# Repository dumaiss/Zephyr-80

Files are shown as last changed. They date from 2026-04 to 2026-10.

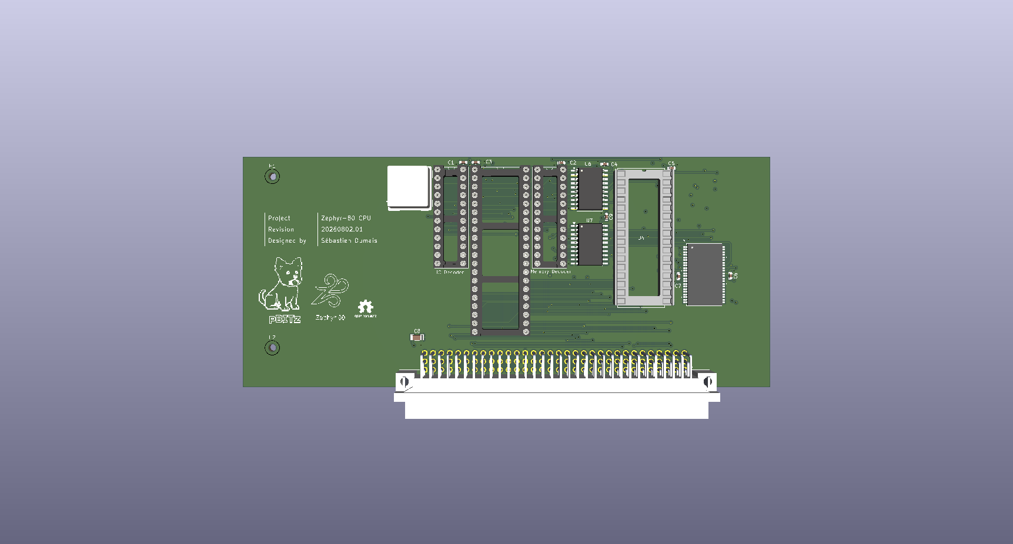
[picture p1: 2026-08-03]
Schem/Zephyr-80-CPU/Zephyr-80-CPU.png

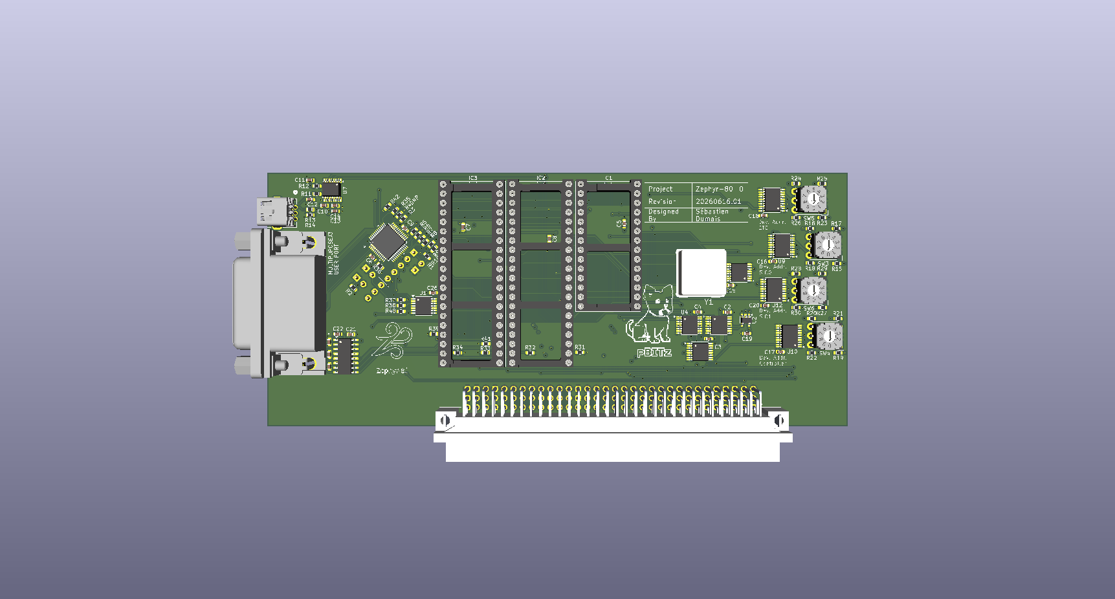
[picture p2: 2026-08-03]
Schem/Zephyr-80-IO/Zephyr-80-IO.png

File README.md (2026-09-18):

# Zephyr-80

**Retro Soul, Modern Flow**

Zephyr-80 is a modular homebrew Z80 computer built from real retro-style
components and modern support hardware. It runs CP/M 2.2, provides 512 KiB each
of banked SRAM and ROM, and uses expansion cards for video, sound, and peripheral
control.

It is the Z80 member of the broader pBITz / coffee-machine family of homebrew
computers.

The project combines a conventional Z80 bus with a protected common-memory
region, a driver-oriented BIOS, programmable serial and timer hardware, and an
MCU-based I/O Controller for storage and human-interface devices. The same
firmware is also used by the project's MAME implementation.

Zephyr-80 is an active hobby project and a hardware/software development
platform, not a finished consumer product. The machine runs CP/M on real
hardware with video, sound, storage and USB input working; what remains under
development is mostly tooling and the emulation targets.

## Current status

| Subsystem | Status |
| --- | --- |
| Z80 CPU board and memory banking | Working on physical hardware |
| ROM-to-RAM boot transition | Working |
| CP/M 2.2 and Zephyr CBIOS | Working |
| SIO serial console at 115200 baud | Working |
| Virtual Drip V9958 console | Working development backend |
| Virtual Drip 8 MiB CP/M disk | Working development backend |
| MAME machine and V9958 video | Boots the Zephyr firmware; development on hold |
| ColecoVision compatibility mode | Working on physical hardware |
| IOCALL fixed-frame transport | Working on physical hardware |
| Percolator Lunch Crema V9958 card | Working on physical hardware |
| SD-card storage through the I/O Controller | Working on physical hardware |
| USB HID keyboard and gamepad through the I/O Controller | Working on physical hardware |
| CP/M images as files on a FAT card | Working on physical hardware |
| Percolator Afternoon Blend four-chip SN76489 card | Working on physical hardware |

## Hardware architecture

### Processor and memory

- Z80-family CPU, with a current hardware target of 10 MHz
- 512 KiB SRAM arranged as eight 64 KiB physical banks
- 512 KiB ROM arranged as eight 64 KiB pages
- ATF22V10-based memory and I/O decoding
- Memory-control latch at I/O port `00h`
- 56 KiB banked program region plus an 8 KiB common region, with the operating
  system in its own SRAM bank

At reset, ROM is visible and writes are directed to SRAM underneath it. The
firmware copies every ROM page into the matching SRAM bank, disables ROM, and
continues from RAM. From then on ROM is storage only: the operating system —
ZSDOS, the BIOS and its drivers — runs from SRAM bank 7, which is mapped in only
while it executes. A program sees `0000h-DFFFh` of its own bank and the common
region at `E000h-FFFFh`, which stays SRAM bank 0.

See [Memory Management.md](Memory%20Management.md) for the decoder equations,
memory modes, banking-latch format, and I/O map.

### Serial and timer hardware

The system uses two Z80 SIO devices and a Z80 CTC. The BIOS currently owns:

- SIO0/B for the 115200-baud console and Virtual Drip transport
- SIO1/B for the synchronous I/O Controller command channel
- the Z80 IM2 vector page; programs get CTC timer interrupts by registering a
  callback with the BIOS

The I/O Controller supplies the external clock and synchronization signals for
its synchronous SIO link. The initial IOCALL implementation is deliberately
simple and uses a polled, fixed-size transaction.

### Expansion bus

The latest Zephyr-80 respin uses DIN connectors for the pBITz expansion bus.
The shared backplane, bus, and mezzanine-card designs are maintained separately
in the [pBITzPlatform repository](https://github.com/dumaiss/pBITzPlatform).

## Memory model

Physical memory is eight 64 KiB SRAM banks and a ROM divided into 64 KiB pages.
The banking latch carries three SRAM-bank bits, three ROM-page bits and two
memory-mode bits, and the two mode bits select one of four mappings:

| Mode | Mapping |
| --- | --- |
| `00` ROM access / RAM destination | Reads: selected ROM page at `0000h-FFFFh`. Writes: selected SRAM bank at `0000h-FFFFh` |
| `01` Flat SRAM | Selected SRAM bank at `0000h-FFFFh`, reads and writes |
| `10` Application | Selected SRAM bank at `0000h-DFFFh`; common SRAM bank 0 at `E000h-FFFFh` |
| `11` Operating system | Selected SRAM bank at `0000h-1FFFh`; SRAM bank 7 at `2000h-DFFFh`; common SRAM bank 0 at `E000h-FFFFh` |

Writes always reach SRAM. In mode 00 that makes a single `LDIR` copy ROM to SRAM,
which is how cold boot seeds a bank and how drive A: is read. Flat mode 01 gives a
true 64 KiB bank, including the `E000h-FFFFh` that modes 10 and 11 overlay with
bank 0; that memory is present in every bank, hidden rather than absent.

At cold boot only the ROM pages that are boot images seed SRAM: page 0 into bank 0
and page 7 into bank 7. The pages backing CP/M drive A: stay in ROM as persistent
immutable storage and are never copied.

In the current CP/M build, a program's transient area is `0100h-EC05h`, 59 KiB.
The common region holds a 1 KiB program reservation for interrupt callbacks, the
CCP, the BDOS entry, the BIOS jump tables, the interrupt path and the system
stacks. ZSDOS, the BIOS drivers and their private state live in bank 7. Exact
addresses are declared in
[`cbios_defs.inc`](Code/HOST/CPM2.2/src/cbios_defs.inc).

## CP/M firmware

The current system boots CP/M 2.2, with ZSDOS as the BDOS and ZCPR2 as the
command processor, on a Zephyr-specific CBIOS. The operating system runs from
SRAM bank 7 behind a BDOS entry in common memory, which copies a program's
buffers across when the operating system cannot see them.

Programs reach the Zephyr services through `CALL 5`, as BDOS functions:

- 200 and 201 to register and unregister a CTC interrupt callback
- 203 for system information, such as the I/O Controller transport level
- 210 and 211, `MOVE` and `XMOVE`, for bank-aware memory transfers
- 212, `SELMEM`, for selecting the execution bank
- 213, `SETBNK`, for selecting the disk DMA bank
- 214, `IOCALL`, for I/O Controller command/reply transactions
- 216 and 217, `IOCBULK` and `IOCBULKW`, for I/O Controller bulk transfers
- 215, `VIDEO_SEND`, for submitting video command streams

[`zbdos.inc`](Code/HOST/Utilities/src/zbdos.inc) wraps them for assembly
programs.

The current IOCALL transport sends one caller-owned 32-byte frame and receives
one 32-byte reply frame over SIO1/B. The BIOS owns the transport but does not
interpret individual I/O Controller commands.

For firmware architecture, build artifacts, and the current driver layout, see
[Code/HOST/CPM2.2/README.md](Code/HOST/CPM2.2/README.md).

## Console and storage

### Virtual Drip development backend

Virtual Drip is the current development proxy for console, video, keyboard
input, and CP/M storage. It lets the physical Z80 machine exercise the BIOS and
V9958-oriented software before all replacement hardware paths are complete.

The active console is an 80-column V9958 GRAPHIC 6 terminal. Terminal state is
kept in V9958 VRAM, with a CP850 font atlas, color-aware logical cells, and a
sprite-based cursor. See the
[Virtual Drip V9958 console notes](Code/HOST/CPM2.2/docs/vdrip9958-console.md).

CP/M Drive A is currently backed by an 8 MiB flat image on the proxy side. The
BIOS exposes normal 128-byte CP/M disk records and maps them to proxy storage
transactions. See the
[Virtual Drip disk format](Code/HOST/CPM2.2/docs/zephyr80_vdrip_disk.md).

Virtual Drip is a bring-up tool rather than the intended final storage and HID
architecture. Those functions are moving to the onboard I/O Controller.

### I/O Controller

The I/O Controller offloads modern peripheral protocols from the Z80. Its
eventual responsibilities include:

- SD-card storage
- USB keyboard and controller input
- system reset and power-management coordination
- asynchronous input/event delivery to the host

The current firmware implements the synchronous SIO command transport and
fixed 32-byte IOCALL frames. Basic PING and RESET commands exist for link
bring-up. Storage, HID, and unsolicited event delivery remain under development.

## Video

Video is provided by expansion hardware rather than being fixed on the CPU
board. The physical multimedia cards belong to the Percolator Series and are
maintained in the
[PercolatorLabs repository](https://github.com/dumaiss/PercolatorLabs):

- **Morning Joe**: TMS9918-family video for native 9918-era hardware experiments
- **Lunch Crema**: V9958 video with 128 KiB VRAM and RGB output; expected to
  provide the ColecoVision-compatible VDP path

Zephyr-specific development paths also include:

- Virtual Drip, a serial development proxy that models VDP operations on a
  modern host
- a V9958 implementation in the Zephyr MAME machine

The current CP/M graphical console targets V9958 GRAPHIC 6 semantics. Original
9918-family tests remain in the repository, but that hardware is no longer the
only or primary description of Zephyr-80 video.

## ColecoVision compatibility

Zephyr-80 is intended to run ColecoVision software as a dedicated
**machine-takeover mode**, not as an application that continues to call CP/M.
Compatibility is expected to use the **Lunch Crema V9958**; the Morning Joe
TMS9918 card is not required. The V9958's TMS9918-compatible display modes are
expected to provide the video behavior needed by ColecoVision software.

Zephyr-80 is not wired as a literal ColecoVision clone, so a Zephyr-specific
bootstrap must construct the environment that the game expects before handing
over the CPU. That initialization is expected to:

1. quiesce CP/M, its BIOS drivers, and their interrupt sources
2. load the ColecoVision BIOS and game image into the appropriate RAM locations
   and physical bank
3. establish the compatibility memory map while the bootstrap remains in a
   safe execution area during the final bank switch
4. initialize the V9958 in its TMS9918-compatible mode, clear or prepare VRAM,
   and select the Coleco-compatible VDP interrupt route
5. initialize an SN76489-compatible PSG path on the **Afternoon Blend** card
6. configure the controller-input path to expose the behavior expected by the
   game
7. establish the required vectors, stack, and entry state, then transfer
   control to the ColecoVision program

After the final transfer, the game owns the CPU, VDP, sound, and controller
interfaces. CP/M services are no longer assumed to be available.

### Launch paths

Two launch paths are planned. They share the same final hardware-initialization
and handoff logic:

- **CP/M launcher:** select a game from CP/M, load its BIOS and cartridge image
  into RAM, prepare the compatibility mapping and peripherals, and let the game
  take over the machine.
- **Bootable Zephyr cartridge:** start cartridge-resident loader firmware
  immediately after reset, copy or unpack the bundled game into RAM, configure
  memory banking and video, and transfer control without booting CP/M.

This is native execution on the Zephyr Z80 and compatible peripheral paths, not
CPU emulation. It is still a compatibility target rather than a blanket claim
that every title works. Games that depend closely on the original console's CPU
timing may require calibrated delays or title-specific adaptation because
Zephyr-80 runs its Z80 at 10 MHz.

## Sound

The Zephyr-80 sound card is the Percolator Series **Afternoon Blend**, which
uses four SN76489 programmable sound generators with analog mixing and
amplification. The card design is maintained in the
[PercolatorLabs repository](https://github.com/dumaiss/PercolatorLabs), while
Zephyr-side drivers and applications belong here. Software support and
higher-level music tooling are continuing areas of development.

## MAME emulation

The repository includes Zephyr-80 MAME development under
`Code/MODERN/Emulator/`. The goal is to run the same firmware used by the
physical machine rather than maintain a separate emulator-only BIOS.

Current emulator work includes the banked ROM/RAM architecture, Z80 peripheral
topology, and V9958 video. I/O Controller, storage, and host-HID integration are
being added incrementally.

The MAME source tree and CP/M source are included as Git submodules. Clone with
submodules enabled when working on those areas:

~~~sh
git clone --recurse-submodules https://github.com/dumaiss/Zephyr-80.git
~~~

## Repository layout

| Path | Contents |
| --- | --- |
| `Schem/` | KiCad schematics and board-specific validation notes |
| `Code/HDL/` | PLD and programmable-logic source |
| `Code/HOST/CPM2.2/` | CP/M 2.2, Zephyr CBIOS, drivers, image tools, and generated memory documentation |
| `Code/HOST/Monitor/` | Interactive Zephyr monitor application |
| `Code/HOST/HelloWorld/` | Hardware bring-up and subsystem test programs |
| `Code/MCU/` | Power-management and I/O Controller firmware |
| `Code/MODERN/Emulator/` | MAME machine development and emulator ROM tests |

## Related repositories

| Repository | Scope |
| --- | --- |
| [pBITzPlatform](https://github.com/dumaiss/pBITzPlatform) | DIN-connected pBITz backplane, bus, and mezzanine-card hardware |
| [PercolatorLabs](https://github.com/dumaiss/PercolatorLabs) | Percolator Series video and sound cards, including Morning Joe, Lunch Crema, and Afternoon Blend |

## Building the CP/M firmware

Initialize the submodules, then build from the CP/M directory:

~~~sh
git submodule update --init --recursive
cd Code/HOST/CPM2.2
make
~~~

The build requires Python 3, GNU Make, and the SDCC Z80 tools `sdasz80`,
`sdldz80`, and `makebin`.

Primary outputs include:

| Artifact | Purpose |
| --- | --- |
| `build/zephyr80.bin` | 512 KiB burnable ROM image |
| `build/zephyr80-zcpr2-zsdos.bin` | the same image, named for its CCP and BDOS |
| `build/firmware.bin` | ROM page 0: the reset vector and common memory |
| `build/bank7.bin` | the operating-system image, loaded into SRAM bank 7 |

The ROM requires memory decoder revision 11, built from
[`Code/HDL/WinCUPL`](Code/HDL/WinCUPL/README.md). The build also regenerates
`docs/memory-map.md` and `docs/symbol-map.md`, and fails if the layout breaks a
validated rule.

Additional build and backend-selection details are documented in the
[CP/M firmware README](Code/HOST/CPM2.2/README.md).

## Development notes

- Treat the PLD equations and `Code/HOST/CPM2.2/src/cbios_defs.inc` as
  authoritative when older narrative documents disagree.
- The firmware ABI is `CALL 5`, including the Zephyr functions, and the CP/M
  BIOS boot and console entries. Nothing else is published at a fixed address.
- Several older architecture notes remain in the repository for design history
  and may describe superseded clock, I/O, or memory arrangements.
- Hardware revisions and experimental subsystems may require matching firmware
  branches or configuration. Check the board-specific notes before programming
  devices or applying power.

## License

Zephyr-80 is licensed under the
[Solderpad Hardware License v2.1](Licence.md), with the option described there
to treat the work as Apache License 2.0.

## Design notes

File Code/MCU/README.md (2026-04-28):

# MCU Firmware

This directory contains firmware projects for microcontrollers used by the
Zephyr-80 hardware.

Each MCU target should live in its own subdirectory so device-specific source,
build settings, fuse settings, programmer configuration, and documentation stay
isolated.

## Projects

- `PMU/` - Power management unit firmware project.
- `IOController/` - PIC18F57Q84 IO Controller firmware project.

## Suggested Layout

```text
MCU/
  <mcu-target>/
    README.md
    Makefile
    include/
    src/
    docs/
    build/
```

Keep shared protocol notes or board-level interface documentation in this
directory only when they apply to more than one MCU target.

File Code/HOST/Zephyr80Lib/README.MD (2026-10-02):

# Zephyr80Lib

`Zephyr80Lib` is the reusable FTL Modula-2 library for Zephyr-80 programs.
It provides the public `Sound`, `Timer`, and `Player` modules. The current
implementation targets the four
SN76489-compatible PSGs on Afternoon Blend and the Zephyr BIOS-managed CTC0
interrupt service.

All CP/M-visible source and output filenames are 8.3-compatible.

## Public modules

- `Sound` controls 16 logical channels across the four PSGs.
- `Timer` exposes logical ticks from 1 through 180 Hz. CTC0 and the assembly
  callback bridge remain private implementation details.
- `Player` loads a ZTR file and advances complete singleton music playback one
  application-supplied tick at a time.

`CTCLow`, `ZTR`, and `PlyCore` are archive implementation modules, not public
application APIs. See `DOC/API.MD` for the complete public contract and an
embedding example.

## PC build

The library is built with FTL Modula-2 under RunCPM. The repository carries the
RunCPM executable and the ZCPR3 CCP image; the FTL distribution is read from
`../Software/disk1/5`. On the x86-64 Linux development host, only Python 3 and
`make` are required:

```text
make clean
make
```

Objects are written to `BUILD/FTL`, and `BUILD.LOG` holds the full compiler,
assembler and linker output. Tool paths can be overridden through Make
variables; run `make help`.

## Why not Turbo Modula-2

This library was originally built with Turbo Modula-2, and that toolchain has
been removed. TM2's runtime is too large for the machine: once it is linked in,
a hosted application has no room left to run. Since the point of this library is
hosted development on the Zephyr-80 itself, that is disqualifying.

Consequences worth knowing:

- FTL's compilers are line-oriented. LF-only source reads as one enormous line
  and `MD` reports `ERROR 81 end of file reached before program complete`.
  `SRC` and `TEST` are stored CRLF and pinned by `.gitattributes`.
- FTL has no port I/O in the language and no `SYSTEM.OUT`. `SRC/PORTIO.*`
  supplies `In` and `Out`; see `TOOLS/README.MD` for why it is built from
  source rather than imported.
- FTL's `Files` is block-oriented, with no `Open`, `ReadBytes`, `NoTrailer` or
  `EOF`. Use `Lookup`, `SeqReadBlock`, the `eof` field of `FILE`, and `Close`.
  Block transfers move whole 128-byte units even when fewer bytes are asked
  for, so read buffers must be sized in whole blocks.

## Native FTL CTCLow bridge

`SRC/CTCLOW.Z80` targets the FTL `ASM.COM` supplied in `../Software/disk1/5`.
On CP/M, build it with these commands after copying `CTCLOW.DEF` and
`CTCLOW.Z80` to the FTL work disk:

```text
MD CTCLOW.DEF
ASM CTCLOW.Z80 CTCLOW.REL
ML yourprog
```

Keep `OPSASM.DAT` on the logged drive. Both ASM filenames require extensions.
Compile the definition first; ASM replaces the definition's stub `.REL`.
Its bare `LABEL` directives export procedures in `CTCLOW.DEF` order.
The syntax follows the supplied FTL assembly examples and the
[FTL manual, chapter 7](https://www.cpcwiki.eu/imgs/9/92/Hisoft_FTL_Modula-2_Z80_User_Guide_%28Hisoft%29_Manual.pdf).

`FTLTEST.COM` is a hosted regression, not a hardware timer test; running it
needs a C++ compiler and `libqkz80` via `tests/ftl_bridge.cpp`.

Callback placement remains `E3C0h-E3F6h`, with state at `E3F8h-E3FEh`.
FTL consumers must reserve that region against code, data, heap and stack;
the bridge does not change the FTL runtime's memory allocator. It still
requires the Zephyr BIOS registration API.

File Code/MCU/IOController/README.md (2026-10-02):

# IO Controller Firmware

Firmware project for the Zephyr-80 IO Controller MCU.

The default target is `PIC18F57Q84`.

## Build Firmware

```sh
make
```

The build emits firmware output into `build/`. Override paths when needed:

```sh
make DEVICE=PIC18F47Q84
make XC8=/path/to/xc8-cc DFP=/path/to/device/support
```

Bulk data CRC calculation and verification are bypassed by default with
`IOC_BULK_CRC_BYPASS=1` in `include/config.h`, matching the current Z80 bypass.
This applies to both directions of the SIO1/A bulk lane: IOC sends a two-byte
zero CRC trailer and ignores the received CRC. Packet framing and metadata
checks remain active; command-lane CRC and SD-card SPI CRC are unchanged.
The Z80 must keep its bulk receive CRC bypass enabled with this setting.

To restore IOC bulk CRC generation and verification:

```sh
make DEFS=-DIOC_BULK_CRC_BYPASS=0
```

Use `make` (or `make DEFS=-DIOC_BULK_CRC_BYPASS=1`) to return to bypass mode.
Restoring end-to-end verification also requires disabling the Z80's separate
`IOC_BULK_CRC_BYPASS` setting.

## Current Behavior

At boot the firmware asserts the host reset pair for 100 ms:

- `RF2` / `RESET` is driven low, then released high.
- `RF3` / `RESET_HIGH` is driven high, then released low.

After boot, the main loop polls `/SIO1B_INT` on `RF0`. A falling edge starts
one External Sync command transaction:

```text
select:  PIC RA4 /SIOB_CS puts SIO1/B on the SIO bus
request: Z80 SIO1/B TXDB -> PIC RB2 SIO_MISO, clocked by PIC RB3 SIO_SCK
reply:   PIC RB1 SIO_MOSI -> Z80 SIO1/B RXDB, clocked by PIC RB3 SIO_SCK
sync:    PIC RA7 drives SIO1/B /SYNCB
```

The bulk of the transfer runs on SPI2. A disposable byte is clocked by hand only
while establishing that lane's persistent `/SYNC` boundary; the complete
`A5 5A` packet marker then follows through SPI. See
[docs/external_sync_protocol.md](docs/external_sync_protocol.md) for what stays
bit-banged and why.

Throughput is set by `EXTSYNC_TARGET_BYTE_US` in `include/external_sync.h`,
currently 16 us (500 kbit/s). That is paced against the Z80 BIOS receive loop,
not against the SPI clock — see the header for the T-state budget.

See [docs/pinout.md](docs/pinout.md) for the full pin map.

Both lanes use `A5 5A LEN TYPE SEQ STATUS DATA CRC` packets. The 32-byte
`IocFrame` is only the command-side compatibility mailbox. Active commands are:

- `CMD_PING`: return `RSP_PING` with the sequence, status, length, and payload
  echoed.
- `CMD_RESET`: assert `RESET` / `RESET_HIGH`, then reset the PIC.

The transport maps command mailboxes to variable-length CRC-protected packets.

## Two-Lane Transport

The two SIO1 channels are one transport with two lanes: SIO1/B carries commands
and SIO1/A carries large DATA. Both use the same packet framing and persistent
External Sync discipline.
Commands that move more than a mailbox-worth of data use an explicit
READY -> BULK -> DONE lifecycle:

```text
CMD_SD_READ_BULK(LBA) -> READY(id, dir, 512) -> one 512-DATA packet on SIO1/A
                      -> CMD_XFER_STATUS -> DONE(id, status)
```

The card is read into MCU SRAM before READY is sent, so SD latency sits outside
the bulk transaction. See
[docs/external_sync_protocol.md](docs/external_sync_protocol.md) for the wire
formats, the state machine and the bulk-lane timing.

## SD Card

`CMD_SD_READ` (03h) reads block 0 over SPI1 on the port C bus, select
`/IO_SD_CS` on RA2, and returns its first 16 bytes in the reply payload. The
card initialises lazily on the first read. Failures come back as status codes
10h-14h rather than a transport error, so the host can tell which stage gave up.
Block reads verify the card's CRC-16 and retry on failure. Several timing and
retry settings are deliberately conservative while the SD path is still
marginal; see the **BELT AND SUSPENDERS** block at the top of
[include/sd_card.h](include/sd_card.h) for what each one costs and the order in
which to relax them.

`ioc_sd_read.asm` in the HelloWorld project exercises it; `ioc_sdblk.asm`
exercises the full-sector bulk path and `ioc_bulk.asm` tests the bulk lane on
its own with a ramp.

## USB HID Bring-Up

TinyUSB 0.20.0 supplies the MAX3421E host, hub and HID class code.  The IOC's
adapter is isolated in `src/ioc_hid.c`; it shares SPI1 only through the central
one-hot selector, so selecting the MAX3421E always releases the SD card and
controller latch first.

The MAX3421E and FE1.1 hub now support up to two HID interfaces in the
foreground TinyUSB task.  One boot keyboard may be used alongside a Logitech
F310 in DirectInput mode (USB `046d:c216`), or two F310s may feed the two
Coleco controller bytes.  F310 interrupt-IN requests are paced at 10 ms in the
application because TinyUSB's MAX3421E scheduler does not yet enforce endpoint
`bInterval`.  Passive `CMD_HID_STATUS` page 6 reads TinyUSB's live non-hub
device table and exposes USB/F310 enumeration, report-arm, report-count and
decoded-latch state to `PADSTAT.COM` in a normal build.  Boot-keyboard press transitions are translated
inside the HID module to ASCII/control bytes and VT100 key sequences, then held
in a 128-byte queue.  The nonblocking `CMD_HID_INPUT` dequeues up to 24 bytes;
`HIDKEY.COM` exercises that path directly without changing BIOS `CONST` or
`CONIN`.  See the bring-up log for the command layout and current limitations.

**Nothing can be read from the MAX3421E until `PINCTL.FDUPSPI` is set.**  The
part powers up in half-duplex SPI, where it tri-states MISO and drives read data
back out of its own MOSI pin — which this board cannot receive, because MOSI
reaches it through a one-way CD74HC4050.  The first access must therefore be a
blind PINCTL *write*; writes work in both modes.  `RES` is strapped high, so
that setting survives every PIC reset and only a 3V3 power cycle undoes it.
See [docs/max3421-bring-up-debug.md](docs/max3421-bring-up-debug.md) for the
full root-cause trail, what has been ruled out, and the bisection guide.

## Controller Latch Bring-Up

The cascaded 74AHC595 pair on the port C bus (SPI1) is driven by
`controller_latch.c`. Both controller bytes start at the standard Coleco idle
value `7Fh`.  Each changed F310 report is decoded to the active-low Coleco data
bus and committed at SPI1's 32 MHz maximum.  Mount order assigns controller 1
and then controller 2; unplugging a pad restores that byte to `7Fh`.

**D7 is low.**  It was high until Montezuma's Revenge exposed it.  The BIOS
complements every controller read, so a game sees `~latch`; Monte merges the
two mode bytes and tests the result with `AND 0C0h` / `CP 0C0h` at `90FFh`.
With D7 high that compare can never match and the jump button is dead.  The
BIOS itself only reads D3:D0 and D6, and no other title in the test set looks
at D7 of a controller byte, so `CONTROLLER_LATCH_IDLE` is the single point to
revert should one turn up.

The F310 mapping is d-pad (or left stick while the Mode LED is on) to Coleco
directions, A/B to fire, X/Y to the existing keypad 1/2 selections, and
Back/Start to the Coleco `*`/`#` codes used by game-over/restart paths. The board
does not capture the Coleco keypad/joystick mode-select writes, so these keypad
substitutes temporarily override the direction nibble while held. The raw latch
codes are `0Dh` for key 1, `07h` for key 2, `09h` for `*`, and `06h` for `#`;
with the idle upper nibble these appear at the controller port as `7Dh`, `77h`,
`79h`, and `76h` respectively.

### USB keyboard keypad

The four gamepad substitutes cover only `1`, `2`, `*` and `#`. Titles that need
the rest of the keypad -- the music cartridge, and games whose title screen
waits on a digit the pad cannot produce -- are served from an attached USB
keyboard instead, which is otherwise idle once ColecoGo has taken the machine
over.

The number row and the numeric keypad both give `0`-`9`. `Shift+8` and
`Shift+3` give `*` and `#`, which is just typing the character; keypad `*` is an
alias for `*`. The mapping drives controller port 0 and does **not** consume the
keystroke, so digits still reach the CP/M console while CP/M is running.

A keypad code held from the keyboard overrides the direction nibble of every
gamepad report until it is released, matching the existing substitute
behaviour: a real controller cannot report a keypad key and a direction at the
same time. Releasing parks the nibble idle, and an attached pad restores real
directions on its next report.

The nibbles come from the BIOS decode table at `10F5h`, which is indexed by the
complement of the port read, so the latch value is `~index`:

| Key | Latch | Key | Latch | Key | Latch |
| --- | --- | --- | --- | --- | --- |
| 0 | `0Ah` | 4 | `02h` | 8 | `01h` |
| 1 | `0Dh` | 5 | `03h` | 9 | `0Bh` |
| 2 | `07h` | 6 | `0Eh` | `*` | `09h` |
| 3 | `0Ch` | 7 | `05h` | `#` | `06h` |

`make test` runs `tools/test_coleco_keypad.py`, which extracts the mapping
function from `src/ioc_hid.c`, compiles it for the host, and checks all twelve
keys plus the negative cases against that BIOS table rather than against a
transcribed copy of it.  It also replays the whole latch byte through the
BIOS complement, so a regression in D7 or the fire line fails the test rather
than reaching hardware.

`CONTROLLER_LATCH_COUNTER_TEST` still defaults to **0**, which compiles
`controller_latch_tick()` down to an empty call.

Build with `CONTROLLER_LATCH_COUNTER_TEST=1` to get the bring-up behaviour --
an incrementing pair `(n, n+1)` written to the two latches every 500 ms. This
section previously described that pattern as if it always ran, which it has not
since the flag was added. See [docs/pinout.md](docs/pinout.md) for the timer and
SPI1 settings.

See [docs/external_sync_protocol.md](docs/external_sync_protocol.md) for the
wire-level walkthrough, timing notes, and Z80 SIO references.

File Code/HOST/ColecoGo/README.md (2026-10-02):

# ColecoGo

`ColecoGo` is a CP/M user-space launcher for running ColecoVision software directly on Zephyr-80 hardware.

The intended command-line interface is:

```text
A>COLECOGO GAME.ROM
```

The launcher is a one-way machine takeover. It uses CP/M only to locate and load the ColecoVision BIOS and cartridge image, prepares a dedicated RAM bank and the Zephyr compatibility hardware, then transfers control to the ColecoVision BIOS at `0000h`. Returning to CP/M is not supported or expected.

## Scope

The initial implementation targets conventional ColecoVision cartridge images up to 32 KiB.

The ColecoVision BIOS is not embedded in the executable. `COLECOGO.COM` is expected to load it from a separate file, initially named:

```text
COLECO.ROM
```

The initial loader should validate that the BIOS image is exactly 8 KiB and that the cartridge image is no larger than 32 KiB.

Larger bank-switched cartridge formats are outside the scope of the first version.

## Relevant Zephyr-80 memory model

In normal RAM-only operation, Zephyr-80 exposes:

```text
0000h-DFFFh   selected SRAM bank
E000h-FFFFh   SRAM bank 0, fixed/common
```

This means a ColecoVision cartridge mapped at `8000h-FFFFh` crosses the Zephyr physical bank boundary at `E000h`.

That boundary is invisible to the Z80, so the loader can construct the final Coleco address space from two physical RAM regions:

```text
Logical address   Physical Zephyr RAM
---------------   -------------------
0000h-1FFFh       selected Coleco bank
2000h-5FFFh       selected Coleco bank, temporary staging area
6000h-7FFFh       selected Coleco bank, Coleco RAM
8000h-DFFFh       selected Coleco bank, cartridge lower 24 KiB
E000h-FFFFh       bank 0, cartridge upper 8 KiB
```

Bank 7 belongs to the running operating system and is never a legal application
bank. ColecoGo sacrifices bank 6 as its fixed one-way takeover bank.

## Loading scheme

### 1. Run normally under CP/M

`COLECOGO.COM` starts as an ordinary CP/M transient program at `0100h`.

While CP/M is still fully operational, it:

1. parses the cartridge filename from the command line
2. opens `COLECO.ROM`
3. validates the BIOS size
4. opens the requested cartridge image
5. validates the cartridge size
6. loads both files through normal CP/M BDOS services
7. uses Zephyr BDOS functions 210 and 211 to construct the target bank

All errors should be reported before the takeover begins.

### 2. Construct the target bank

The target bank is prepared as follows:

```text
0000h-1FFFh   ColecoVision BIOS
2000h-5FFFh   temporary staging for GAME.ROM offsets 4000h-7FFFh
6000h-7FFFh   cleared for Coleco RAM
8000h-BFFFh   GAME.ROM offsets 0000h-3FFFh
```

For cartridge images smaller than 32 KiB, the cartridge destination should be initialized to a deterministic fill value before overlaying the file contents. `FFh` is the proposed initial fill value.

The upper 16 KiB of a 32 KiB cartridge crosses the current RAM-only mapping
boundary: `C000h-DFFFh` is in the selected bank while `E000h-FFFFh` is physical
bank 0. It is staged at `2000h-5FFFh`, then copied across that boundary after
the final bank switch.

### 3. Install the final handoff code

The final takeover requires code that survives the bank switch.

The current CP/M memory model reserves `E000h-E3FFh` as application-owned common memory. A small Stage A trampoline can be copied there before takeover.

Stage A is responsible for:

1. disabling interrupts
2. shutting down CP/M-owned interrupt sources that must not fire during takeover
3. switching to the selected Coleco RAM bank
4. jumping to Stage B in the newly selected bank

Stage B must live below `E000h` in the target bank. Its exact location is intentionally left open until implementation, but it must not depend on CP/M, BDOS, BIOS stack state, or any code/data that will be overwritten.

### 4. Complete the cartridge mapping

Once Stage B is executing in the target bank, the loader can populate both the
bank-6 and common-bank portions of the upper cartridge and overwrite the common
CP/M region.

Conceptually:

```asm
ld      hl,2000h
ld      de,0C000h
ld      bc,4000h
ldir
```

This copies the staged upper 16 KiB of the cartridge into the live logical range `C000h-FFFFh`.

At this point the common CP/M facade, BIOS and stacks are intentionally
destroyed. The protected bank-7 OS image is not overwritten, but there is no
supported return path to it.

The final Z80-visible image is then:

```text
0000h-1FFFh   ColecoVision BIOS
2000h-5FFFh   don't-care / available
6000h-7FFFh   Coleco RAM
8000h-FFFFh   cartridge image
```

## Hardware compatibility handoff

Zephyr-80 was designed so Coleco software can access compatible hardware directly after CP/M gets out of the way.

The final handoff therefore does not emulate Coleco I/O and does not proxy runtime accesses through CP/M.

### V9958 video

Before jumping to the ColecoVision BIOS, ColecoGo only needs to establish the Zephyr/V9958-specific state that original Coleco software cannot establish itself:

1. select the Coleco-compatible VDP interrupt route, with the V9958 interrupt presented to the Z80 as NMI
2. program the V9958 palette to reproduce the fixed Coleco/TMS9918 palette
3. reset V9958-only registers inherited from the CP/M graphics console to a
   TMS-compatible baseline

The ColecoVision BIOS is then allowed to initialize the ordinary TMS9918-compatible VDP registers itself.

There is one electrical address-decoding difference that the loader must also
bridge. A ColecoVision aliases the TMS9928A throughout `A0h-BFh` and uses only
address bit A0 to choose data or command/status. LunchCrema passes A1:A0 to the
V9958, where those two bits select four distinct ports. Stock BIOS accesses to
`BEh/BFh` therefore select the V9958 palette/indirect ports instead of its
data/command ports.

The current loader recognizes the standard Coleco BIOS layout (CRC32
`3AA93EF3`) by checking every affected operand and patches its in-memory copy
from `BEh/BFh` to LunchCrema's `A0h/A1h`. The disk file is not modified. A BIOS
with a different layout is rejected before bank 6 is changed. Cartridge code
that performs its own direct VDP I/O is adapted by the cartridge scan
described below.

### Controller input

No runtime HID translation layer is required in ColecoGo.

The Zephyr I/O Controller maintains controller state in hardware latches at the addresses expected by ColecoVision software. Once takeover is complete, Coleco software reads those latches directly with its normal I/O instructions.

### Sound

ColecoVision writes its single SN76489 at `FFh`. Although Zephyr routes writes
in the `E0h-FFh` range to Afternoon Blend, that card uses A2:A0 to select an
individual sound device: `FFh` selects an unused slot and `E0h` selects PSG0.
ColecoGo therefore patches the standard BIOS's guarded `FFh` output operands
to `E0h` in memory. The BIOS's normal sound initialization and runtime engine
then drive PSG0 directly; ColecoGo is not involved after takeover. Cartridge
code that writes directly to `FFh` is adapted by the cartridge scan described
below.

### Cartridge I/O adaptation

Titles that reach the hardware through the BIOS are handled entirely by the
BIOS patch above. Titles that drive the VDP or the PSG themselves are not, so
the loader adapts the cartridge image as well, in memory, before takeover.

The BIOS can be patched from a fixed table because it is a known image. A
cartridge is not, so its operands have to be found. The loader cannot simply
scan for `D3h`/`DBh` byte pairs: Donkey Kong contains nine such pairs in its
data tables and no direct I/O at all, so a blind scan would corrupt a title
that currently works.

Instead the loader runs a recursive-descent trace from the cartridge header's
documented entry points -- the start address at offset `0Ah` and the eight
`RST`/NMI vector slots at `0Ch`-`23h` -- following direct jumps, calls and
relative branches. Only a byte the trace proves is the operand of a reachable
I/O instruction is rewritten:

| Instruction | Operand | Rewritten to | Why |
| --- | --- | --- | --- |
| `OUT (n),A` / `IN A,(n)` | `A0h`-`BFh` | `A0h` or `A1h`, keeping A0 | LunchCrema decodes A1:A0 |
| `OUT (n),A` | `E0h`-`FFh` | `E0h` | Afternoon Blend decodes A2:A0; `E0h` is PSG0 |
| `IN A,(n)` | `E0h`-`FFh` | unchanged | these are the controller latches, already correct |

An image with no `AA55h`/`55AAh` header is not traced at all, because its
entry vectors would be arbitrary data.

This is deliberately conservative, and it has two known limits. Code reached
only through a computed jump or a jump table is never traced, so its operands
are never rewritten. A port held in a register -- `OUT (C),r`, `IN r,(C)` or
the block I/O forms -- is not an operand and cannot be rewritten at all;
Zaxxon drives its hardware this way. The loader counts both cases and reports
them before takeover:

```text
Cartridge scan: 4 VDP and 1 sound operand(s) adapted, 0 indirect OUT (C)/IN (C) site(s) left unpatched.
```

A non-zero indirect count means the title will probably still misbehave, and
that a patch manifest is needed.

### Per-title patch manifests

For the sites the trace cannot reach, a manifest named after the cartridge
with CP/M type `PAT` supplies them explicitly, under the same guarded
expect/replace discipline the BIOS table uses. `GAME.ROM` is accompanied by
`GAME.PAT` on the same drive; a missing manifest is not an error.

A manifest is bound to one image by its record-rounded length and a CRC-16,
and every site is verified before any byte is written, so a manifest that does
not match changes nothing and the loader returns to CP/M with bank 6 intact.

Build one by hand-correcting a copy of the ROM and diffing it:

```sh
python3 tools/scan_cartridge.py scan GAME.ROM          # what the trace will do
python3 tools/scan_cartridge.py pat GAME.ROM GAME.FIX GAME.PAT
```

`pat` records only the differences the automatic scan does not already make,
so a manifest never duplicates the trace.

## Final takeover sequence

The intended final sequence is:

```text
COLECOGO GAME.ROM
        |
        +-- load COLECO.ROM -> target bank 0000h-1FFFh
        |
        +-- load GAME.ROM lower half -> target bank 8000h-BFFFh
        |
        +-- stage GAME.ROM upper half -> target bank 2000h-5FFFh
        |
        +-- install Stage A in common application-owned RAM
        |
        +-- all validation and error reporting complete
        |
        +-- DI
        +-- quiesce CP/M interrupt sources
        +-- select V9958 interrupt -> NMI
        +-- program Coleco/TMS9918 palette
        +-- switch to target Coleco bank
        +-- jump to Stage B
        +-- copy staged upper cartridge -> C000h-FFFFh
        +-- establish a safe temporary stack if needed
        +-- JP 0000h
                |
                v
        ColecoVision BIOS
                |
                v
             cartridge
```

The transfer to `0000h` is a `JP`, not a `CALL`. There is no caller to return to.

## Implementation notes

While CP/M is active, the implementation uses the stable Zephyr BDOS facade:
function 211 selects the source and destination banks and function 210 performs
the cross-bank move. It does not call the movable private BIOS jump table.
SYSINFO version 1 introduced the required facade; ColecoGo accepts that version
and later append-only SYSINFO revisions.

Direct low-level bank manipulation belongs only in the final no-return trampoline where CP/M bookkeeping is no longer relevant.

The exact Stage B address and final scratch layout should be chosen when the assembly implementation begins. The loader must ensure that Stage B does not overwrite itself while copying the upper cartridge half and that the final Coleco RAM area is left in a suitable state before `JP 0000h`.

## Project layout

```text
Code/HOST/ColecoGo/
|-- README.md
|-- Makefile
|-- src/
|   |-- README.md
|   |-- colecogo.asm
|   |-- cartscan.inc      cartridge I/O trace, shared with the harness
|   |-- cartpatch.inc     PAT manifest reader, shared with the harness
|   `-- scantest.asm      standalone scanner harness, test-only
`-- tools/
    |-- README.md
    |-- check_build.py
    |-- ihx_to_com.py
    |-- scan_cartridge.py     reference model and PAT builder
    |-- make_io_test_rom.py   synthetic test cartridge
    |-- test_cartscan.py      compares the Z80 scanner with the model
    `-- patch_cartridge.py
```

## Current first-pass implementation

The repository now contains an SDCC/ASxxxx Z80 implementation in
`src/colecogo.asm`. It implements the conventional-ROM path described above:

- accepts the cartridge name from CP/M's first default FCB
- opens and validates `COLECO.ROM` and the requested cartridge
- reads both files completely before changing the takeover bank
- guards and adapts the standard BIOS's VDP ports for LunchCrema
- fills unused cartridge space with `FFh`
- constructs bank 6 through Zephyr BDOS functions 211/210 (`XMOVE`/`MOVE`)
- installs the common Stage A and target-bank Stage B handoff routines
- disables CP/M CTC/SIO interrupt sources
- establishes a clean TMS-compatible V9958 baseline, LunchCrema WAIT/DRAM
  state, Coleco palette, and NMI route
- completes the upper cartridge mapping, clears Coleco RAM, and jumps to `0000h`

Build it with:

```text
make
```

The result is `build/COLECOGO.COM`. The build also checks that the ordinary
program remains below its fixed file buffers, Stage A fits in `E000h-E3FFh`,
and Stage B fits in the backed-up 128-byte staging record.

CP/M 2.2 records file sizes in 128-byte units. Runtime validation can therefore
prove that the BIOS occupies exactly 64 records and the cartridge no more than
256 records, but it cannot recover a host file's byte length within its final
record. ROM images should be copied to CP/M without text-mode translation.

This first pass intentionally does not support bank-switched cartridges, a
return to CP/M, title-specific timing adaptation, or runtime
emulation/proxying of Coleco hardware. Version 0.5 adds the cartridge I/O
scan and `PAT` manifests described above; it does not rewrite indirect
`OUT (C)` hardware access, which no static operand patch can reach. Hardware
testing of version 0.2 reached both the BIOS title and Donkey Kong's option
screen, exposing inherited CP/M V9958 state: the BIOS VRAM clear ran with G6
mode and CPU VRAM page 7 still selected. Version 0.3 reset that state. Version
0.4 moves the handoff to the current memory architecture and requires a hardware
retest. Successful takeover overwrites SRAM bank 6 and the common CP/M region.
The bank-7 OS image remains intact, though there is deliberately no return path.

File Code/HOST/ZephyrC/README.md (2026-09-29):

# ZephyrC

The C library for Zephyr-80 programs, cross-compiled on a PC. It gives C
programs the machine's serial ports, V9958, sound card, CTC timers, banked
memory, input devices and operating system services, under the same ownership
rules the BIOS and the assembly and Turbo Modula-2 programs already follow.

`DOC/API.md` is the contract: what each call does, what the hardware demands,
and what is still missing. This file is how to build and run it.

It is the C counterpart of `../Zephyr80Lib` (Turbo Modula-2). Where both cover
the same hardware they describe it the same way.

## Building

```sh
make            # library, example and tests
make lib        # build/zephyr.lib
make examples   # build/MANDEL.COM and build/FARCALL.COM
make tests      # host tests and all test .COM files, including FSTEST.COM
```

Needs z88dk (`zcc`, `z88dk-z80asm`), the SDCC assembler and linker
(`sdasz80`, `sdldz80`) for the common-memory stubs, and Python 3.

z88dk is a snap on this host and cannot read `/tmp`, so build inside the home
tree.

## Using it in a program

```c
#include <zephyr/vdp.h>
#include <zephyr/input.h>

int main(void)
{
    if (zep_vdp_acquire() != ZEP_OK)
        return 1;
    zep_vdp_mode(ZEP_VDP_G6, ZEP_VDP_LINES_212 | ZEP_VDP_INTERLACE);
    /* ... draw ... */
    while (zep_kbd_getc() < 0)
        ;
    zep_vdp_release();
    return 0;
}
```

```sh
zcc +cpm -compiler=sdcc -O2 -I$(ZEPHYRC)/include prog.c \
    -L$(ZEPHYRC)/build -lzephyr -o PROG.COM
```

The classic C library gives you `<stdio.h>` with CP/M file I/O, `malloc` and
`<cpm.h>`; ZephyrC adds the machine. Modules that take hardware give it back
at exit on their own, whichever way the program ends.

A program ends in a warm boot, which clears the screen, so ZephyrC waits for a
key first and prints `[any key]`. Call `zep_exit_pause(0)` if a program must not
block on the way out.

## What is in the box

| Header | Covers |
|---|---|
| `zephyr/bdos.h` | `zep_sysinfo`, the BDOS 210-217 register block, IOCALL and bulk transfers, the ZSDOS clock and file stamps |
| `zephyr/fs.h` | Native FAT files, byte transfers, hierarchy, directory iteration and free-space queries through BDOS 218 |
| `zephyr/serial.h` | SIO0/A (RS-232) and SIO0/B (the USB console port, borrowed from the BIOS) |
| `zephyr/vdp.h` | V9958: registers, palette, modes, VRAM, the command engine, sprites |
| `zephyr/timer.h` | CTC ticks at 1-180 Hz, raw CTC, common memory and interrupt callbacks |
| `zephyr/sound.h` | Four PSGs as 16 channels, plus the PCM DAC |
| `zephyr/bank.h` | Banks 1-6 as data, and calls into code placed in a bank |
| `zephyr/input.h` | USB keyboard through BDOS, gamepads from the controller latches |

## Example and tests

- `tests/fs_host.c` — runs `zep_fs.c` against a host-side function-218
  model. It covers name canaries, 0/1/127/128/129/511/512/513 and multi-chunk
  transfers, EOF/short reads, exact native status propagation (including
  `UNKNOWN_WRITE` without replay), hierarchy, free space and directory
  open/read/end/close/reopen.
- `tests/fstest.c` — builds `FSTEST.COM`, the real-card public-API
  acceptance test. It owns `/ZCFSTEST` in the current USER namespace, tests
  read/write/readback, seek/tell, truncate, mutation, nesting, iteration and
  space, and cleans up results whose completion is known. It stops immediately
  on `ZEP_FS_UNKNOWN_WRITE`.

- `examples/mandel/mandel.c` — `MANDEL.COM`, the direct-V9958 Mandelbrot from
  `../HelloWorld/src/mandelbrot_v9958_real.asm`, ported to C. Same screen, same
  fixed-point arithmetic and palette, so the two images can be compared. It also
  uses the timer, sound, input and `zep_sysinfo`.
- `examples/farcall/` — `FARCALL.COM`, a minimal far call. It copies a small
  position-independent assembly routine into bank 1, calls it through
  `zep_bank_call`, and checks the value returned in `HL`. It needs the Zephyr
  BIOS bank services and therefore does not run under RunCPM.
- `tests/ticktest.c` — `TICKTEST.COM` drives the tick callback the way the BIOS
  dispatcher does and checks the phase accumulator, saturation and counters. It
  needs no CTC and runs under an emulator.
- `tests/sertest.c` — `SERTEST.COM` exchanges a line over the console port with
  a peer on the PC.
- `tests/timtest.c` — `TIMTEST.COM` runs the tick service on one CTC channel and
  touches no video or sound, so a failure is the timer path alone. It separates
  "the CPU is ignoring interrupts" from "the channel is not counting" from "the
  channel counts but never vectors", by printing the interrupt-enable state and
  the CTC's own down-counter. `TIMTEST [channel] [rate]`.
  Channels are physical CTC/BIOS interrupt sources: 0, 1, 2, 3 use ports
  40h, 42h, 41h, 43h. The test adapts setup, readback and shutdown for the
  swapped select lines; the shared timer library and BIOS remain unchanged.
- `tests/vdptest.c` — `VDPTEST.COM` draws colour bands through the VDP calls and
  waits for a key, using raw HID input so the console cannot draw over it.
- `tests/irqtest.c` and `tests/irq_probe.asm` — `IRQTEST.COM` checks AF, BC, DE,
  HL, IX, IY, the alternate register set, and SP across real BIOS interrupts.
  It tests application and OS memory mappings using the correct CTC ports.

### Interrupt register/SP diagnostic

Start with channel 3 and compare the two callback bodies:

```text
IRQTEST 3 MIN
IRQTEST 3 TICK
```

`MIN` registers an eight-byte counter callback. `TICK` registers the production
ZephyrC tick callback. Both use the running BIOS's IM2 vectors, dispatcher and
interrupt stack; neither installs a private interrupt environment. Each run
defaults to 1000 pairs of application/OS mapping windows, about 14 seconds at
10 MHz. An optional final argument selects 1–5000 pairs.

The foreground probe runs from E100h-E207h with its test stack at E300h and a
guard at E2D0h-E2FDh. It checks known register values after each window, stops
on the first mismatch, and stops the timer before printing. No console, IOC,
video or sound work runs during the windows. Counts reported around each mode's
windows establish interrupt activity, not exact per-mode timing; a few ticks
can arrive in the surrounding foreground bookkeeping. Zero coverage produces
`INCONCLUSIVE`, not `PASS`.

If a run unexpectedly warm boots, run **`IRQTEST R` before another test**, using
the same binary. The record at E000h survives the current BIOS warm boot:

- Stage 1 means the current window did not complete its snapshot; register
  values from that window are unavailable.
- Stage 2 means the assembly probe captured its state but the C checker did
  not finish validating it.
- Stage 3 means the last snapshot passed; stage 4 records a mismatch.

A bad return address can prevent the probe from reaching its capture code.
Passing therefore narrows the investigation; it does not prove interrupt
handling is safe under foreground I/O or full OS workloads. `MANDEL` remains
useful as that stress workload.

### Native filesystem hardware acceptance

1. Build with `make tests` and copy `build/FSTEST.COM` to a disk the Zephyr
   can execute.
2. Boot a current OS/IOC pair, select the FAT-backed B: drive and the USER area
   to test, then run `FSTEST`.
3. Expect `FSTEST: all passed`. Every failure prints the raw `ZEP_FS_*`
   byte. If status `4D` is printed, do not rerun or clean up until the card is
   inspected: that chunk's commit is unknown.
4. Confirm `ZCFSTEST` is absent afterward. A remaining directory means the
   test reported a known failure and deliberately left evidence, or completion
   became unknown.

`FSTEST.COM` returns through the normal C startup/ZCPR path; it does not force
a warm boot.

## Where it has run

`TICKTEST` and `SERTEST` pass, and `MANDEL` draws a correct set, under RunCPM
with a patched I/O layer standing in for the SIO and the V9958. **Nothing has
run on the real machine yet.** What the emulator cannot show: VDP and SIO
timing, RTS/CTS flow control, real CTC interrupts, banked memory (RunCPM has no
BDOS 210-217), and the gamepad latches.

`DOC/API.md` section 11 lists the BIOS, firmware and hardware work the
unfinished parts wait on. `DOC/KNOWN-ISSUES.md` records the problems seen on
hardware — chiefly that the machine restarts when CTC interrupts run — with
what has been ruled out and what to try next.

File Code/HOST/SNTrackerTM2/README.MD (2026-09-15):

# SNTracker TM2

This directory contains the native Turbo Modula-2 port of SNTracker.  It is an
ordinary CP/M transient program and does not require BIOS changes.  The
assembly implementation in `../SNTracker` remains the behavioral reference.

Every source filename is CP/M 8.3-compatible in the repository.  Copying or
editing sources on the Zephyr therefore requires no filename mapping.

## Modules

```text
SRC/SNTRACK.MOD   command line, UI, clock wiring and rate-limited key polling
```

All playback, ZTR loading, sound and timer implementation comes from the
sibling `../Zephyr80Lib` project. This directory intentionally keeps no copies
of those modules.

## Building on the PC

The complete build runs the original CP/M tools under RunCPM, avoiding the
physical Zephyr's smaller TPA.  From this directory run:

```text
make
```

The Makefile first rebuilds `../Zephyr80Lib/BUILD/ZEPHYR80.LIB`. It then creates
an isolated temporary CP/M drive, stages the library and uppercase CRLF copies
of the standalone tracker source, and:

1. selects `SYSLIB ZEPHYR80` as the TM2 archive search path;
2. compiles `SNTRACK.MOD` against the public library definitions;
3. extracts the required implementation members from `ZEPHYR80.LIB`;
4. builds `TLINK.COM` and links outside the IDE;
5. checks the usage and missing-file command paths; and
6. publishes only `BUILD/SNTRACK.COM`.

The default uses the toolchain embedded in `../Zephyr80Lib/TOOLS`. All inputs
can be overridden, for example on a different host:

```text
make RUNCPM=/opt/runcpm/RunCPM
```

See `TOOLS/README.MD` and `make help` for the complete list.

## Building on the Zephyr

Place `SNTRACK.MOD`, `ZEPHYR80.LIB`, Turbo Modula-2 system files and
the desired ZTR songs on a CP/M work drive. In the TM2 Options menu enable
Native and Extensions. Native is an IDE option and cannot be enabled from
source.

Choose `Path to search` and append `ZEPHYR80` to the default path:

```text
SYSLIB ZEPHYR80
```

Compile the application modules in this order:

```text
SNTRACK.MOD
```

The integrated linker may run out of memory on the complete program. Use the
TM2 Librarian to copy these members from `ZEPHYR80.LIB` to the work disk:

```text
PLAYER.MCD  ZTR.MCD  PLYCORE.MCD
SOUND.MCD   TIMER.MCD  CTCLOW.MCD
```

Build a standalone linker from the TM2 Link menu with `LINK` as the main
module and `TLINK.COM` as output. Run it with `SNTRACK` as the main module,
`SNTRACK.COM` as output, and include all needed modules.

The PC Makefile is the reproducible full build when either operation exceeds
the Zephyr's TPA. The resulting COM file can then be copied to the SD card for
hardware acceptance.

## RunCPM during the port

RunCPM is useful for native compilation, linking and hardware-independent
tests. Its directory-backed drives are case-sensitive on Linux, so stage CP/M
filenames in uppercase. The TM2 compiler also requires CP/M CRLF text when used
in that environment.

RunCPM validates archive resolution, compilation, linking, usage handling and
the missing-file path. The library's own build validates ZTR loading and
complete-song traversal. Neither can validate live CTC interrupts or Afternoon
Blend writes; those checks require the physical Zephyr.

## Runtime ownership

`SNTRACK.MOD` owns the standalone clock policy. After `Player.Load`, it starts
`Timer` at `Player.TickRate` and passes every consumed timer event to exactly
one `Player.Tick` call. `Player` itself never owns CTC0.

The library's private `CTCLow` bridge follows the current BIOS-owned IM2
contract. It registers CTC0 through Zephyr BDOS function 200, keeps its callback
at `E3C0h-E3F6h` and state at `E3F8h-E3FEh`, and resets and
unregisters through function 201.

TM2 retains its stock `LD SP,(0006h)` startup, giving the tracker a stack at
`EC06h`. The callback's high placement avoids the tracker's data/heap tail and
leaves about 2 KiB for the descending player stack before the callback area.

The callback only publishes pending ticks in the program-owned common
reservation and returns with `RET`; the BIOS dispatcher supplies the common
interrupt stack, register preservation, `EI`, and `RETI`. Callers must still
treat CTC0 as an exclusive application resource.

The pending counter saturates at 255.  `QueueOverflows` counts ticks rejected
at that boundary.  It cannot detect hardware expirations lost while interrupts
were disabled.

`Player` owns all four Afternoon Blend PSGs during playback and mutes them on
normal completion or user stop. The PSGs are write-only, so prior state cannot
be restored.

Console polling occurs once per logical second and only in foreground code.
The ISR performs no BDOS, parsing, rendering, or PSG work.

## Hardware acceptance

Before replacing the assembly executable in normal use, verify on Zephyr:

1. Night Market and Runaway Circuit play at the expected pitch and tempo.
2. The status line advances once per order and queue overflows remain zero.
3. Natural completion and Q/Escape both stop CTC0 and mute every PSG.
4. Repeated runs return to CP/M with BIOS console interrupts still working.

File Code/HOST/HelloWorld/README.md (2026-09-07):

# Zephyr-80 Test Programs

Small Z80 assembly programs for exercising the various parts of the Zephyr-80
machine during hardware bring-up. Each file in `src/` is built independently so
individual tests can be burned to ROM or loaded through the monitor.

## Programs

- `helloworld.asm`: initializes SIO channel B and repeatedly prints
  `Hello, World!`.
- `echo.asm`: initializes SIO channel B and echoes received serial characters.
- `ctctest.asm`: samples CTC channel 0 into a small RAM buffer.
- `vdrip_checkerboard.asm`: monitor-loadable Virtual Drip serial demo that
  repeatedly streams a TMS9928A Graphics I checkerboard over SIO channel B.
- `vdrip_smiley.asm`: monitor-loadable Virtual Drip serial demo with a smiley
  sprite moving left-to-right over a Graphics I background.
- `testiorq.asm`: repeatedly writes `55h` to I/O port `80h`.
- `testlatchport.asm`: repeatedly reads I/O port `00h` with short delay loops.
- `sndtest.asm`: CP/M program that exercises the Percolator Afternoon Blend
  sound card at `E0h`: the four SN76489AN PSGs and the AD7801 PCM DAC.

## Walkthroughs

All programs starting at address `0000h` cannot be run from CP/M, they need
to be burned separately into an EEPROM. Those that start at `0100h` are meant
to be run from CP/M and those starting at `8000h` can be loaded from within
the monitor.

### `helloworld.asm`

This ROM-style test (ie: cannot be run in CP/M) starts at `0000h`, disables 
interrupts, sets the stack to `FFFFh`, and initializes Z80 SIO channel B on 
data port `22h` and control port `23h`.

The SIO initialization resets the channel, selects x16 asynchronous serial mode
with one stop bit and no parity, enables 8-bit receive with auto-enables, and
enables 8-bit transmit while asserting RTS and DTR. Interrupts are left disabled,
so all serial I/O is polled.

After initialization, the main loop loads `HL` with `hello_message`, calls
`sio_puts`, and jumps back to print it again. `sio_puts` walks the
null-terminated string one byte at a time. `sio_putc` polls RR0 until the SIO
reports transmit-buffer-empty, then writes the character to the SIO data port.

### `echo.asm`

This serial echo test also starts at `0000h`, disables interrupts, sets the stack
to `FFFFh`, and initializes SIO channel B on ports `22h` and `23h`.

The SIO setup resets the channel, selects x16 asynchronous 8N1 operation, writes
WR3 with `0C1h` for 8-bit receive plus receive-enable, writes WR5 with `0EAh`
for 8-bit transmit plus transmit-enable, RTS, and DTR, then disables SIO
interrupts.

After setup, the program waits for one received character before printing the
banner. This keeps the banner from being lost while the terminal is being
opened. The main loop then waits for a byte with `sio_getc`, sends that same byte
back with `sio_putc`, and sends an extra line-feed after carriage-return so a
terminal moves to the next line cleanly.

### `ctctest.asm`

This is a small monitor-loadable CTC sampling test.

The file starts with `org 8000h`, so the code is intended to be loaded and run
from RAM at `8000h`, not burned as reset-vector ROM code. `CTC0` names I/O port
`40h`, which is the CTC channel being sampled. `SAMPLE_BUF` names RAM address
`8100h`, where the captured bytes will be stored.

At `start`, the program loads `HL` with `8100h`; `HL` is used as the write
pointer into the sample buffer. It then loads `B` with `32`, making `B` the loop
counter.

Each pass through `sample_loop` executes `in a,(CTC0)` to read the current byte
from CTC port `40h`. The value in `A` is stored at the current buffer address
with `ld (hl),a`, then `HL` is incremented so the next sample goes to the next
RAM byte. `djnz sample_loop` decrements `B` and repeats until 32 samples have
been written to `8100h` through `811Fh`.

After the last sample, `ret` returns to the caller. When run from the monitor,
the captured CTC values can be inspected by dumping memory starting at `8100h`.

### `vdrip_checkerboard.asm`

This is a standalone monitor-loadable Virtual Drip demo assembled with
`sdasz80`/`sdldz80` syntax. It is loaded at `8000h` and run from the monitor
with:

```text
G 8000
```

After launch, it takes over SIO channel B, reinitializes it for 115200 8N1, waits
a few seconds, then repeatedly sends Virtual Drip binary packets:

- RESET
- PING
- TMS9928A Graphics I register setup
- checkerboard pattern, color, and name table writes
- FRAME_MARK
- a replay delay

The demo does not return to the monitor. Reset or power cycle the machine to
recover the monitor.

Host-side handoff:

1. Start the monitor terminal.
2. Load `build/vdrip_checkerboard.hex` with the monitor `L` command.
3. Run `G 8000`.
4. Close the monitor terminal quickly while the demo is in its startup delay.
5. Start Virtual Drip on the same serial device:

```sh
virtual-vdp --serial /dev/serial/by-id/<device> 115200 --vnc-port 5900
```

6. Connect a VNC viewer to `localhost:5900`.

The demo resends the full checkerboard state forever, so the proxy can attach
late and still eventually display the image.

### `vdrip_smiley.asm`

This is a standalone monitor-loadable Virtual Drip animation demo assembled with
`sdasz80`/`sdldz80` syntax. It uses the same serial handoff model as
`vdrip_checkerboard.asm`: load `build/vdrip_smiley.hex` with the monitor `L`
command, then start it with:

```text
G 8000
```

After launch, it reinitializes SIO channel B for 115200 8N1, waits a few
seconds for the terminal-to-proxy handoff, then sends a full TMS9928A Graphics I
state:

- RESET and PING
- Graphics I register setup
- checkerboard background pattern, color, and name table data
- two overlaid 8x8 sprite patterns for the smiley face and facial details
- initial sprite attribute table

The main animation loop updates only the sprite attribute table bytes for the
two smiley sprites, sends `FRAME_MARK`, delays briefly, advances X, and wraps
back to the left edge. On wrap it resends full state so Virtual Drip can attach
late and recover without requiring framebuffer-style streaming.

Host-side handoff:

1. Start the monitor terminal.
2. Load `build/vdrip_smiley.hex` with the monitor `L` command.
3. Run `G 8000`.
4. Close the monitor terminal quickly while the demo is in its startup delay.
5. Start Virtual Drip on the same serial device:

```sh
virtual-vdp --serial /dev/serial/by-id/<device> 115200 --vnc-port 5900
```

6. Connect a VNC viewer to `localhost:5900`.

The demo does not return to the monitor. Reset or power cycle the machine to
recover the monitor.

### `testiorq.asm`

This ROM-style I/O request test starts at `0000h`, disables interrupts, and
loads `A` with the fixed pattern `55h`.

The loop continuously writes `A` to I/O port `80h` with `OUT ($80),A`, then jumps
back to repeat forever. It is useful for checking I/O decode, IORQ activity, and
external hardware connected to that port.

### `testlatchport.asm`

This ROM-style input-port test starts at `0000h`, disables interrupts, and sets
the stack pointer to `FFFFh`.

The loop repeatedly reads I/O port `00h` into `A`. It then runs two delay loops
by loading `B` with `0` and executing `DJNZ`; on Z80 this counts through 256
iterations before falling through. After both delays, it jumps back and reads the
port again. This gives a slow, repeated input cycle for observing latch or port
behavior on the bus.

### `sndtest.asm`

This is a CP/M program (`org 0100h`) that exercises the Percolator Series
**Afternoon Blend** sound card. `IO_DECODER.pld` routes the `E0h-FFh` block to
`SOUND` on writes and to `CONTROLLERS` on reads, so the program only ever
writes those ports. The card decodes `A2:A0` locally:

| Port | Device | Stereo placement |
| --- | --- | --- |
| `E0h` | PSG0, U6 SN76489AN | centre |
| `E1h` | PSG1, U7 SN76489AN | centre |
| `E2h` | PSG2, U11 SN76489AN | left-biased (22k/47k) |
| `E3h` | PSG3, U12 SN76489AN | right-biased (47k/22k) |
| `E4h` | PCM, U3 AD7801 | centre |

Only `A2:A0` reach the card, so `E8h`, `F0h` and `F8h` alias back onto `E0h`.
The program stays within `E0h-E4h`.

Three hardware facts shape the code. All four PSGs share one 3.579545 MHz
oscillator, so a tone divisor is `N = 111861 / f(Hz)`. The card generates its
own wait states, holding pBITz `/WAIT` until the selected chip's open-collector
READY rises, so back-to-back `OUT`s are safe and no software delay separates
them. The host data bus is reversed in the card wiring (`DB7` to PSG `D0`), so
software writes conventional SN76489 byte values and must not pre-swap them.

The PSGs have no reset input on this card, so their power-on state is
undefined. The program mutes all four chips on entry, between tests, on exit
and on abort.

Run it from CP/M:

```text
SNDTEST      run tests 1-6
SNDTEST 1    chip identification, one voice per PSG in turn
SNDTEST 2    the four voices of PSG0, alone and together
SNDTEST 3    attenuation staircase
SNDTEST 4    noise generator modes
SNDTEST 5    tone divisor sweep
SNDTEST 6    /WAIT handshake stress plus a four-chip chord
SNDTEST P    AD7801 PCM DAC sawtooth (not part of the default run)
```

Any keypress aborts, mutes every chip and returns to CP/M.

What each test is looking for:

1. **Chips.** The same note on each PSG in turn. Confirms all four chip selects
   reach a device, and that the mixer places PSG2 and PSG3 off centre.
2. **Voices.** PSG0 channels 0, 1 and 2 alone, then together as a C major
   triad, then channel 3 as noise. A missing voice here points at the latch
   byte's channel field rather than at the chip select.
3. **Volume.** Attenuation 0 to 15 and back. The attenuator is 2 dB per step,
   so the ramp should sound even rather than collapsing at one end.
4. **Noise.** Periodic and white noise at each of the three fixed shift rates,
   then the tone-3 clocked mode with channel 2's divisor swept.
5. **Sweep.** Walks the 10-bit divisor range, so every write exercises both the
   latch byte's low nibble and the second byte's upper six bits. A sweep that
   jumps in octaves or sticks at one pitch means the second byte is not
   landing.
6. **Wait stress.** 16384 wait-stretched writes issued back to back across
   `E0h-E3h` with no software spacing, roughly 150 ms of stretched bus time.
   Reaching the line after the loop is the result: the card's FF1/FF2 state
   machine armed, cleared and rearmed every time without leaving `/WAIT`
   asserted. The chord underneath it must stay steady throughout.

The `P` test drives the AD7801 at `E4h`, which is deliberately outside the PSG
wait-state generator, so those writes run at full bus speed and the waveform
timing is entirely software. `LDAC` is grounded, so the output updates on the
rising edge of `/WR`. The test leaves `80h` loaded on exit so the DAC sits at
mid-rail instead of holding a DC offset into the mixer.

### VGM player

The streamed SN76489 player and its host-side VGM compiler now live in the
standalone sibling project [`../VGMPlayer`](../VGMPlayer/README.md).

## Build

```sh
make
```

The default build emits these outputs:

- `build/<name>.bin`: binary for EPROM burning, with the data-bit swap fix
  applied by `tools/swapbits.py`. The ASxxxx-only `vdrip_checkerboard.asm`
  demo is monitor-loadable only and does not produce this ROM-style output.
- `build/<name>.hex`: Intel HEX for loading without the bit swap fix. These HEX
  files are assembled to run at address `8000h`.

Build only one output family if needed:

```sh
make bins
make hex
```

Build the maintained IOC, storage, HID and sound diagnostics, copy them to the
CP/M staging directory, and replace their copies in the bootable disk image:

```sh
make install-diags
```

`PADSTAT.COM` is the passive production-safe F310 status utility.  It reads
normal IOC firmware's HID status page 6 and reports the live non-hub device
count and highest live VID/PID independently of the optional generic mount
callback, plus HID mount, controller-slot assignment, first report arm, report
count and latch value.

The installer updates `../CPM2.2/images/A/0` and
`../CPM2.2/images/zephyr80-vdrip2.cpm`, then extracts every installed file and
verifies it byte-for-byte. The image is replaced only after all checks pass.
The image, disk format, staging directory and CP/M user can be overridden with
the `CPM_IMAGE`, `CPM_FORMAT`, `CPM_STAGE_DIR` and `CPM_USER` make variables.

Override tools from the command line when needed:

```sh
make Z80ASM=/path/to/z80asm
make SDASZ80=/path/to/sdasz80 SDLDZ80=/path/to/sdldz80
make PYTHON=/path/to/python3
```

Remove generated outputs:

```sh
make clean
```

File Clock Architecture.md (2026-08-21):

# Zephyr-80 Clock Architecture

This document describes the clock domains in the currently committed Zephyr-80
CPU and I/O schematics. It is intentionally limited to the clocks that cross
subsystem boundaries or affect software-visible timing.

Zephyr-80 does **not** use one master oscillator for the entire machine. The CPU
system clock, asynchronous serial reference clocks, I/O Controller MCU clock,
and synchronous I/O Controller link clock are separate domains.

## Clock-domain summary

| Domain or net | Source | Frequency | Primary use |
| --- | --- | ---: | --- |
| `CLK_10M` | CPU-board Y1, ECS-2100AX-100 oscillator | 10.000 MHz | Z80 CPU and Z80 peripheral system clocks; exported on the pBITz bus |
| I/O baud reference | I/O-board Y1, 14.7456 MHz oscillator | 14.7456 MHz | Input to U8, the 74HC4040 divider |
| `CLK_7M3728` | U8 Q0, 14.7456 MHz / 2 | 7.3728 MHz | CTC trigger/reference inputs 2 and 3 |
| `CLK_3M6864` | U8 Q1, 14.7456 MHz / 4 | 3.6864 MHz | CTC trigger/reference input 1 |
| `CLK_1M8432` | U8 Q2, 14.7456 MHz / 8 | 1.8432 MHz | SIO0/B console RxC/TxC and CTC trigger/reference input 0 |
| User-serial bit clock | CTC channel 0 `TO0` | Programmable | SIO0/A user-port RxC/TxC |
| I/O Controller serial clock | I/O Controller MCU through the SIO clock buffers | Transaction-dependent | SIO1/A and SIO1/B synchronous serial shifting |
| I/O Controller MCU core | PIC18F57Q84 HFINTOSC | 64 MHz | Current committed MCU firmware |

The 14.7456 MHz oscillator and its divided outputs are local timing references
on the I/O board. They do not clock the Z80 CPU.

## Z80 system clock

The CPU board contains a fixed 10 MHz oscillator, Y1 (`ECS-2100AX-100`). Its
output is named `CLK_10M`.

`CLK_10M` clocks the Z80 and is exported through the pBITz interface. On the I/O
board it drives the system-clock inputs of the Z80 peripherals, including the
CTC and both SIO devices.

The system-clock input of a Z80 SIO is distinct from its serial `RxC` and `TxC`
inputs. Supplying a 10 MHz SIO system clock does not imply a 10 Mbit/s serial
rate. Each SIO channel shifts serial data according to its separate serial-clock
inputs and its WR4 clock-multiplier configuration.

### 10 MHz versus 20 MHz

The currently committed hardware is the fixed 10 MHz configuration. A note in
the CPU schematic mentions 10 or 20 MHz, but the fitted oscillator value and
distributed net are 10 MHz; there is no runtime clock switching.

Running the CPU at 20 MHz while retaining 10 MHz-class CTC and SIO devices is a
separate design option. It would require an explicit peripheral-clock and
wait-state strategy and is not part of the clock architecture documented here.

## I/O-board reference clocks

The I/O board uses a separate 14.7456 MHz oscillator and an SN74HC4040 binary
divider. The first three divider outputs provide exact binary divisions:

```text
14.7456 MHz / 2 = 7.3728 MHz
14.7456 MHz / 4 = 3.6864 MHz
14.7456 MHz / 8 = 1.8432 MHz
```

These frequencies feed the CTC trigger inputs as convenient timing references:

| CTC channel | Trigger/reference clock |
| ---: | ---: |
| 0 | 1.8432 MHz |
| 1 | 3.6864 MHz |
| 2 | 7.3728 MHz |
| 3 | 7.3728 MHz |

The CTC itself remains a 10 MHz Z80-bus peripheral through its `CLK` input.
Its trigger inputs are independent timing sources for the four counter/timer
channels.

## Asynchronous serial clocks

### SIO0/B console

SIO0/B receives `CLK_1M8432` directly on its receive and transmit clock inputs.
The BIOS configures the channel for asynchronous x16 operation:

```text
1,843,200 Hz / 16 = 115,200 baud
```

This is the BIOS console and current Virtual Drip transport.

### SIO0/A user serial port

SIO0/A receives the output of CTC channel 0 (`TO0`) on its receive and transmit
clock inputs. Software selects the CTC time constant and SIO clock multiplier,
allowing the user port to support programmable baud rates.

The user-port baud rate is therefore not fixed by the 14.7456 MHz oscillator
alone; it depends on both the programmed CTC channel and the SIO WR4 setting.

## Synchronous I/O Controller clock

SIO1 uses `CLK_10M` as its Z80 peripheral system clock, but its serial channels
do not use the fixed baud-divider outputs.

For the SIO1/A bulk channel and SIO1/B command channel, the I/O Controller MCU
is the serial-clock master. The MCU supplies `SIO_SCK`; 74AHCT125 buffers gate
that clock to the selected SIO channel. The clock exists only while the MCU is
participating in a transaction.

Consequences for host firmware:

- there is no fixed SIO1 baud rate;
- SIO1 is configured for synchronous x1 operation;
- the Z80 must request a transaction before expecting serial clocks;
- a polled transfer times out if the MCU never begins clocking;
- a block transfer using WAIT would stall indefinitely if the MCU stopped the
  clock before the block completed.

The current Phase 1 IOCALL path uses the SIO1/B command channel with fixed
32-byte frames. Protocol-specific edge sequencing and synchronization are
documented in
[Code/MCU/IOController/docs/external_sync_protocol.md](Code/MCU/IOController/docs/external_sync_protocol.md).

## I/O Controller MCU clock

The currently committed PIC18F57Q84 firmware uses the MCU's internal 64 MHz
high-frequency oscillator (`HFINTOSC`). It is not clocked from either the CPU
board's 10 MHz oscillator or the I/O board's 14.7456 MHz baud oscillator.

This independence allows the MCU to continue managing reset and peripheral
state regardless of the Z80 clock, while also generating the synchronous SIO1
clock under firmware control.

## Expansion-card clocks

Video and sound clocks are local to their Percolator Series expansion cards and
are outside the scope of this document. In particular, no SN76489 or VDP clock
is derived from the I/O board's 74HC4040 in the current architecture.

The Morning Joe, Lunch Crema, and Afternoon Blend clock networks belong in the
[PercolatorLabs repository](https://github.com/dumaiss/PercolatorLabs). The DIN
backplane and shared pBITz signal definitions belong in the
[pBITzPlatform repository](https://github.com/dumaiss/pBITzPlatform).

## Sources of truth

When this document disagrees with an older design note, use the current
schematics and firmware as the authority:

- CPU oscillator and `CLK_10M` distribution:
  `Schem/Zephyr-80-CPU/CPU_AddressDecoding.kicad_sch`
- I/O baud oscillator and divider:
  `Schem/Zephyr-80-IO/BaudClock.kicad_sch`
- CTC and SIO clock routing:
  `Schem/Zephyr-80-IO/IO Controller.kicad_sch`
- SIO1 transaction clocking:
  `Code/MCU/IOController/docs/external_sync_protocol.md`
- MCU oscillator configuration:
  `Code/MCU/IOController/include/config.h`

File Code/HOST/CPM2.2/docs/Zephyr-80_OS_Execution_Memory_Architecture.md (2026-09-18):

# Zephyr-80 Banked OS Execution Architecture

**Status:** Implementation plan for this port — active  
**Branch:** `banked-os`, based on `3e0854a`, the last commit before any ROM-service work. Earlier work is preserved on `rom-services` (`abff820`).  
**Scope:** The work required in this port: decoder, BIOS, ZSDOS and ZCPR2 integration, build, and this tree's own utilities. Application-facing documentation is a separate pass once Phase 2 is complete.  
**Compatibility:** None required. Every Zephyr program in the tree is retrofitted. Third-party tools on the A: ROM disk that cannot work through BDOS are dropped, and anything useful among them is rewritten (section 11).  
**Hardware constraint:** No PCB changes. Decoder equations, firmware, linker layout and software may change.  
**Supersedes:** The runtime ROM-service / ROM-overlay execution architecture.  
**Lifetime:** This becomes a historical record once Phase 2 is complete and validated on hardware.

---

## 1. Summary

Zephyr-80 moves its operating system into a dedicated SRAM bank and runs it from RAM. The OS no longer lives in high common memory, and BIOS and driver code no longer execute from ROM.

The final address space has three classes:

```text
0000-1FFF   caller window        always the running program's bank
2000-DFFF   switchable body      the program's bank, or the OS in bank 7
E000-FFFF   common window        always physical bank 0
```

The two RAM execution modes:

```text
MODE 10 — APPLICATION EXECUTION          latch = 10h | N

0000-DFFF   application bank N (0-6)
E000-FFFF   physical bank 0

MODE 11 — OS EXECUTION                   latch = 18h | N

0000-1FFF   application bank N           unchanged
2000-DFFF   physical bank 7
E000-FFFF   physical bank 0
```

Bank 7 belongs to the OS. The low 8 KiB stays on the running program's bank while the OS runs, so ZSDOS sees that program's real page zero, default FCBs, default DMA and command tail. The top 8 KiB is common in both modes.

ROM is storage: boot, recovery, canonical system images and immutable resources. It is not a runtime execution environment.

**The 8 KiB common window is the required end state.** Phase 1 reaches it in two steps to keep each step testable, but Phase 2 is not optional: recovering `C000h-DFFFh` as banked memory is one of the reasons for doing this at all.

The model is CP/M 2.2 and ZSDOS semantics on a CP/M 3-style banked kernel, using decoder support specific to this machine.

---

## 2. Corrections to the Converged Design

These are defects in the design as it was first written: each one fails if implemented as stated. They are expanded in the sections noted, and all of them are part of the Phase 1 work.

| # | Correction | Failure if omitted | Section |
|---|---|---|---|
| F1 | ZSDOS's two `RST 0` (`zsdos/src/zsdos.z80:487`, `:1026`) jump to a common helper that restores mode 10 before jumping to `0000h` | A program that has replaced the `JP` at `0000h` has its handler executed in mode 11, with `2000h-DFFFh` mapped to bank 7 | 12, 19 |
| F2 | ZSDOS gets a real stack of 128-256 bytes, grown in place so `IXSAVE` stays the two bytes directly below `ZSDOSS`; every ISR switches to a common ISR stack; every interrupt-enabled stack keeps two bytes of headroom | The stock stack is about 56 bytes (`zsdos.z80:316-326`) and an interrupt overruns it into `SPSAVE`. Moving it by changing `LD SP,ZSDOSS` (`:342`) alone corrupts IX on every BDOS return, because `DOSEXT0` restores IX from `IXSAVE` by address (`:1065`) | 12, 15, 18 |
| F3 | Every BIOS latch write becomes a common crossing helper that restores the mode bits it found | Nine existing routines restore a hardcoded mode 10; called from bank-7 code, they unmap the code calling them | 16 |
| F4 | IOC bulk transfers never change the mapping mid-transfer | The bulk lane is timing-fragile (first-byte loss, the Tx underrun latch, persistent sync); a chunk boundary inside a transfer can underrun the transmitter | 14 |
| F5 | ISR registrations are cleared by `WBOOT` and when a transient returns to ZCPR2, with their CTC channels reset; `WBOOT` also reloads `I` and reprograms the device vectors | A program that exits with a callback registered — including by `RET` to ZCPR2, which does not warm boot (`zcpr2/src/ZCPR2.ASM:2143-2146`) — leaves a vector into the reservation the next program overwrites | 18, 19 |
| F6 | The common BIOS table keeps the CP/M 2.2 shape with only boot and console entries live, and ZCPR2's `BIOS EQU` is generated to point at it | ZCPR2 calls `BIOS+6` (CONST) and `BIOS+9` (CONIN) directly (`zcpr2/src/ZCPR2.ASM:691`, `:920-924`); `Z2HDR.LIB:96` hardcodes `0DA00H` | 11 |
| F7 | BDOS functions 27 and 31 return common copies of the ALV and DPB; the disk structures themselves live in bank 7 | A pointer into bank 7 is invalid the moment the call returns to mode 10 | 22 |
| F8 | The BDOS facade is non-reentrant: bank-7 code calls ZSDOS and the BIOS directly, never through `CALL 5`, and ISRs never call BDOS | A nested entry overwrites the saved caller state and returns with the wrong mapping | 9 |
| F9 | The BIOS owns IM2: `I` is always the BIOS vector page, programmed even vectors and the floating `FFh` case reach common BIOS code, and program interrupt handlers are callbacks registered through the Zephyr BDOS range, with the entry validated inside `E000h-E3FFh` | `I` locates the vector table, not the handlers: a program-installed table in common can vector to a handler at `9000h`, which is bank 7 in mode 11. The facade cannot see that, so a policy based on `I` must either disable interrupts across every OS call or risk a crash | 9, 18 |
| F10 | The facade's DMA tracking follows function 13 as well as `SETDMA` | Function 13 resets the DMA to `0080h` inside ZSDOS (`zsdos.z80:1080`); staging would otherwise target a stale address | 13 |

Decisions recorded:

- Third-party tools that need the direct disk BIOS are dropped, starting with `DU2`; the rest stay only if they pass validation, and anything useful that fails is rewritten (section 11).
- The bank primitives `MOVE`, `XMOVE`, `SELMEM` and `SETBNK` join the device services in the Zephyr BDOS range (section 10).
- IM2 belongs to the BIOS. Programs register interrupt callbacks; they never load `I` or install vector tables (section 18).

Accuracy corrections carried into the text:

- Phase 1's OS body is 40 KiB (`2000h-BFFFh`), not 48 KiB. 48 KiB is Phase 2.
- The ZSDOS page-zero accesses verified in source are `0004h` (`zsdos.z80:619`), `0080h` (`:485`, `:1080`) and the two `RST 0`.
- Modes 00 and 01 need no change in either phase if the canonical bank-7 image is kept within `2000h-BFFFh` (section 7).
- ZSDOS locates the BIOS as `ZSDOS+0E00H` (`zsdos.z80:99`). That stays correct if the bank-7 BIOS jump table is placed immediately after ZSDOS, so ZSDOS needs no patch for it (section 12).

---

## 3. Why This Architecture

The 16 KiB common window exists because the BIOS, BDOS, drivers and their state had to stay visible while application banks were switched. Once the OS has a private bank, that requirement goes away:

1. The OS leaves the application's address space.
2. Common memory shrinks from 16 KiB to 8 KiB.
3. Every application bank regains `C000h-DFFFh` as distinct storage.
4. Most BIOS and driver state becomes private to bank 7.

```text
today      0000-BFFF   banked   48 KiB      C000-FFFF   common   16 KiB
final      0000-DFFF   banked   56 KiB      E000-FFFF   common    8 KiB
```

---

## 4. Physical SRAM Ownership

```text
Bank 0      base bank: CP/M's normal application bank, and the backing for common memory
Banks 1-6   application banks
Bank 7      OS bank
```

Bank 7 is never application memory. The bank primitives enforce it:

```text
SELMEM 0-6     accepted
SELMEM 7       rejected
SETBNK 7       rejected
XMOVE 7        system use only
```

All of bank 7 is reserved, although only `2000h-DFFFh` of it is visible in mode 11. Its low 8 KiB and top 8 KiB are unreachable in normal operation and remain reserved system storage.

---

## 5. Final Memory Map

### 5.1 Mode `10` — application execution

```text
0000-DFFF   application bank N      N = 0..6
E000-FFFF   physical bank 0
```

### 5.2 Mode `11` — OS execution

```text
0000-1FFF   application bank N      same N
2000-DFFF   physical bank 7
E000-FFFF   physical bank 0
```

The latch's bank bits keep the application's bank number while the OS runs. Entering and leaving the OS is a single change to `D3`:

```text
application bank 3        latch = 13h
enter OS                  latch = 1Bh
return                    latch = 13h, bank 3 reappears
```

The GAL substitutes bank 7 only for the switchable body, so the latch itself records which application bank is suspended. Nothing else has to remember it.

---

## 6. The Three Address Classes

### 6.1 Caller window — `0000h-1FFFh`

Mapped from the running program's bank in both modes. It carries CP/M's low-memory conventions:

```text
0000   warm-boot vector
0003   I/O byte
0004   drive/user byte
0005   BDOS vector
005C   default FCB 1
006C   default FCB 2
0080   default DMA and command tail
```

Keeping it on the program's bank means ZSDOS reads the real page zero while it runs, with no copies to keep synchronised. It also gives the default FCB and DMA — the common case — a path that needs no marshalling.

### 6.2 Switchable body — `2000h-DFFFh`

The application's bank in mode 10; bank 7 in mode 11. This is the OS's private body:

```text
Phase 1    2000-BFFF   40 KiB
Phase 2    2000-DFFF   48 KiB
```

Bank 7 holds ZSDOS, the BIOS implementation, drivers, OS and BIOS private stacks, private driver state, disk and search state, deferred-work queues, private buffers and system tables.

### 6.3 Common window — `E000h-FFFFh`

Physical bank 0 in both modes, for what must survive a mapping change. It is not all permanent system memory:

```text
E000-E3FF   program-owned reservation            1 KiB
E400-....   common TPA, and the CCP
....-FFFF   permanent system common
```

With the resident boundary near `F100h`:

```text
E000-E3FF   program-owned reservation
E400-F0FF   common TPA and CCP
F100-FFFF   permanent system common
```

**The `E000h-E3FFh` reservation** is for this tree's own programs that need code or data mapped in both modes: registered interrupt callbacks and their state, and bank-switch trampolines. A registered callback's entry must lie here (section 18). Programs do not install vector tables. The OS never uses the reservation.

It belongs to the running program and does not persist across a program exit: a transient's TPA includes it. Something that must outlive a program exit cannot live there without lowering `0006h` below `E000h`, which gives up the common TPA. Persistent residents are out of scope for this port.

---

## 7. Memory Modes

```text
D4 D3  MEM_MODE1:MEM_MODE0
 0  0    00   ROM access / RAM destination
 0  1    01   flat selected SRAM
 1  0    10   application execution
 1  1    11   OS execution
```

The mode field is two plain selector bits, `MEM_MODE1:MEM_MODE0`. Neither bit means "disable ROM" or "enable copying" on its own; each combination is a complete mapping. See [Memory Management](../../../Memory%20Management.md) for the authoritative description.

Mode 00 reads the selected ROM page and writes the selected SRAM bank across the whole address space, with no split and no forced region. That makes cold boot a mapping operation — page 0 into bank 0, page 7 into bank 7, a full 64 KiB each — and it is also the mode a drive-A record read runs in.

Because a full page is installed, there is no longer a rule that the bank-7 image must end below `C000h`. `C000h-DFFFh` still holds the private stacks and scratch that need clearing rather than loading, but initialized content may sit above them; the pristine warm-boot CCP does.

Mode 01 is a flat 64 KiB view of the selected bank, with no ROM and no common region. It is general-purpose — personality loaders, diagnostics, whole-bank initialization — and is the only mode that reaches `E000h-FFFFh` in banks 1-7.

---

## 8. Decoder Changes

The memory GAL receives `A13`, `A14`, `A15`, `MEM_MODE0` (`D3`), `MEM_MODE1` (`D4`) and `BANK_Q0..2`, and it drives `RAM_A16..18` directly. The regions are within its decode granularity:

```text
COMMON_8K   =  A15 &  A14 &  A13                            ; E000-FFFF
OS_BODY     = (A13 & !A14) # (A14 & !A15) # (A15 & !A13)    ; 2000-DFFF
```

Only `MEM_MODE1` can force a bank, which is what gives modes 10 and 11 a common region and leaves modes 00 and 01 with none. Chip selects reduce to one term each: `ROM_CS` on a read in mode 00, `SRAM_CS` on any write or on a read outside mode 00.

Bank selection in mode 11, conceptually:

```text
address in 0000-1FFF   ->  BANK_Q0..2
address in common      ->  bank 0
otherwise              ->  bank 7
```

and in mode 10:

```text
address in common      ->  bank 0
otherwise              ->  BANK_Q0..2
```

"Common" is `COMMON_8K` and applies only to modes 10 and 11; modes 00 and 01 force nothing at all, so `FORCE_BANK0` reduces to `MEM_MODE1 & COMMON_8K`.

These are conceptual equations. `src/MEM_DECODER.pld` revision 12 is the implementation; it compiles and fits the ATF22V10 with the worst output at 7 of 10 available product terms.

---

## 9. The BDOS Facade

`CALL 5` enters a resident facade in common memory. It:

- saves the caller's SP and switches to the common transition stack
- dispatches Zephyr extension numbers itself, before ZSDOS sees them (section 10)
- stages caller objects that are not visible in mode 11 (section 13)
- enters mode 11 and calls ZSDOS, or a Zephyr service, in bank 7
- returns to mode 10, copies staged results back, restores SP, and returns

```text
APPLICATION                   mode 10, bank N
    | CALL 5
    v
COMMON FACADE                 E000-FFFF
    | save SP, common transition stack
    | stage arguments as required
    | enter mode 11
    v
BANK 7
    +---> ZSDOS
    +---> Zephyr service dispatcher
    v
BIOS / DRIVERS                bank 7
    v
COMMON EXIT
    | mode 10
    | unstage results
    | restore SP
    v
APPLICATION
```

**Not reentrant (F8).** The facade keeps the caller's state in single slots. Bank-7 code calls ZSDOS and the BIOS directly and never through `CALL 5`. Interrupt handlers never call BDOS.

**Interrupts (F9).** The facade has no interrupt policy. The BIOS owns IM2 (section 18): `I` is always the BIOS vector page, programmed even vectors and the floating `FFh` case reach common code, so supported interrupts are safe in mode 11 whatever the program is doing, and the facade leaves the caller's interrupt state alone. A debug build asserts on entry that `I` is still the BIOS page. A program that changes `I` is outside the supported interface.

Code that must disable interrupts for its own reasons — the IOC transport, bulk transfers — captures and restores the caller's state with the erratum-safe `LD A,I` retry, as the IOC transport now does in `cbios_iocall.asm` on `rom-services`, rather than forcing `EI` on exit.

---

## 10. Zephyr Services Become BDOS Extensions

Everything this tree's programs call at fixed extended-BIOS addresses moves behind `CALL 5`, together with the bank primitives and interrupt registration:

```text
devices            IOCALL   IOCBULK   IOCBULKW   VIDEO_SEND
bank primitives    MOVE     XMOVE     SELMEM     SETBNK
interrupts         REGISTER_ISR   UNREGISTER_ISR   program exit (section 18)
```

The bank primitives were CP/M 3 BIOS functions, but nothing here needs that ABI. Putting them in the same range leaves `CALL 5` as the single entry for everything except section 11's boot and console entries, and keeps the bank-7 checks of section 4 in one place.

**Function range.** ZSDOS handles functions 0-47 and 98-103 and returns immediately for anything else (`zsdos.z80:354-365`). The facade claims a Zephyr range — for example 200-239 — and dispatches it directly to bank 7, so ZSDOS is not modified. The range stays clear of ZSDOS's numbers and of CP/M 3's.

**Register convention.** BDOS convention passes the function in `C` and a parameter in `DE`. `IOCALL` needs two pointers, `IOCBULK` a pointer and a length, and `XMOVE` two banks, so the Zephyr range defines its own registers. Define them before retrofitting callers.

**Retrofit list.** These call the extended entries at fixed addresses today:

```text
../Utilities/src    hidkey  hidstat  ioc_bulk  ioc_diagchk  ioc_ping  ioc_reset
                    ioc_sdbench  ioc_sdblk  ioc_sdfmt  ioc_sd_read  ioc_sdrec
                    ioc_sdsoak  ioc_sdwrite  padstat
                    sdfs.inc  (used by sddir, sdget, sdput, sddel)
../HelloWorld/src   mandelbrot  mandelbrot_v9958  video_smiley  video_smiley_v9958
```

Any program using the bank primitives, such as banked song data in the tracker, joins the list when it lands.

Programs that install their own IM2 table move to registration when they are retrofitted: `../HelloWorld/src/ctctest_interrupts.asm:126`, `../VGMPlayer/src/vgmplay.asm:572`, `../SNTracker/src/tracker.asm:293` and `../SNTrackerTM2/SRC/CTCLOW.Z80:103`. The private-table procedure in `docs/ctc-and-real-time-programming.md` ("IM2 integration under CP/M") is replaced, and is rewritten in the application documentation pass.

`tools/check_ext_entries.py` on `rom-services` guards the fixed-address literals. Carry it forward only until the calls move to BDOS, then retire it.

---

## 11. Direct BIOS Entry

**Decision: the direct BIOS entry provides boot and console only.** Third-party tools that need the direct disk BIOS are dropped, and anything useful among them is rewritten against BDOS or the Zephyr extensions.

The common BIOS table keeps the standard CP/M 2.2 jump-table shape, so offsets such as `BIOS+6` stay valid, but only some entries are live:

```text
live     BOOT   WBOOT   CONST   CONIN   CONOUT
inert    LIST   PUNCH   READER  HOME    SELDSK   SETTRK   SETSEC   SETDMA
         READ   WRITE   LISTST  SECTRAN
```

Inert entries fail cleanly: `SELDSK` returns `HL = 0`, `READ` and `WRITE` return an error, `LISTST` reports not ready and `READER` returns `^Z`. A tool that tries them reports an error rather than crashing. BDOS list and punch output still work, because ZSDOS reaches the bank-7 BIOS directly.

**Why it is needed at all (F6).** ZCPR2 calls `BIOS+6` (CONST) and `BIOS+9` (CONIN) directly (`zcpr2/src/ZCPR2.ASM:691`, `:920-924`). Its `BIOS EQU` in `Z2HDR.LIB:96` is a literal `0DA00H` and must be generated to point at this table.

**Third-party tools on A:** (`tools/build_rom_disk.py`):

```text
DU2     sector editor; needs the direct disk BIOS           dropped
STAT    reads DPB and ALV through BDOS 27 and 31            kept, via section 22's copies
PIP  DUMP  CRC  MCOPY  NSWP    expected BDOS only           kept if they pass validation
ZSID    debugger; hooks page-zero vectors,
        may use BIOS console entries                        kept if it passes validation
```

Whatever fails validation is dropped or rewritten.

```text
APPLICATION
    +--- CALL 5 ----------------> BDOS facade -------> mode 11 --> ZSDOS / services --> BIOS
    |
    +--- BIOS boot, console ----> common BIOS entry --> mode 11 --> bank-7 BIOS console
```

ZSDOS, already in mode 11, calls the bank-7 BIOS directly; the common table serves only code running in mode 10.

---

## 12. ZSDOS Integration

### 12.1 Low memory

Verified accesses in `zsdos/src/zsdos.z80`:

```text
619    LD A,(RAMLOW+0004H)     drive/user byte
485    RAMLOW+80H              default DMA
1080   LD HL,RAMLOW+0080H      function 13 resets the DMA
487    RST 0                   warm boot
1026   RST 0                   warm boot
```

The caller window makes the first three refer to the running program's real memory, with no page-zero shadowing or synchronisation.

### 12.2 Warm boot is not safe through page zero (F1)

The two `RST 0` are the exception. In mode 11 they reach the program's `0000h` vector, which is correct only while that vector is still the system's `JP WBOOT`. If a program has replaced it, its handler runs **in mode 11**. That handler lives in `2000h-DFFFh`, which is bank 7 at that moment.

Replace both with a jump to a common helper that switches to the common stack, restores mode 10 and then jumps to `0000h`. A replaced vector then runs in application mode, as it would have on unmodified CP/M, and an untouched one reaches `WBOOT`.

The BIOS contains no `RST` instructions. With these two replaced, no code in bank 7 uses `RST`, and that stays an invariant.

### 12.3 BIOS linkage

ZSDOS computes its BIOS as `BIOS EQU ZSDOS+0E00H` (`zsdos.z80:99`). Place the bank-7 BIOS jump table immediately after ZSDOS and this is correct as written. The common BIOS entry of section 11 is a separate table.

### 12.4 Internal stack (F2)

ZSDOS switches to its own stack on entry (`zsdos.z80:341-343`):

```text
LD    (SPSAVE),SP
LD    SP,ZSDOSS
PUSH  IX
```

The stack is the region between `SPSAVE` (`:316`) and `ZSDOSS` (`:326`): about 56 bytes, most of it the copyright string. `IXSAVE` (`:325`) is its last two bytes, which is exactly where that first `PUSH IX` lands.

That placement is load-bearing. `DOSEXT0` restores the caller's IX by address rather than by popping it (`:1064-1065`):

```text
LD    SP,(SPSAVE)
LD    IX,(IXSAVE)       ; "Restore IX (stack is don't care)"
```

So the stack cannot be moved by changing `LD SP,ZSDOSS` alone. The first push would land somewhere else, and every BDOS call would return with IX holding the ASCII bytes `'er'`.

Grow the region in place instead: insert 128-256 bytes of storage between `SPSAVE` and the copyright text, keeping `IXSAVE` as the two bytes directly below `ZSDOSS`. That also stops the copyright string being overwritten.

Two knock-ons, both benign here:

- `BGRAMTOP EQU ZSDOSS` (`:328`) moves up, growing BackGrounder ii's high-RAM save size `BGHIL` (`:3245`). This matters only if BGii is used.
- `RAMINI` (`:467`) clears from `BGLORAM` up to `SPSAVE`, below the stack, and is unaffected.

With a 40-48 KiB private body there is no reason to keep the stock size. Measure the enlarged stack with the `STKCHK` fill, and shrink it later only if it matters.

### 12.5 `CCPBUF`

`CCPBUF`'s command-processor range test must be derived from `CBASE`. `rom-services` has this as `CCPLO`/`CCPHI` generated by `tools/gen_zsdos_bios.py`; carry it forward.

---

## 13. Pointer Visibility and Marshalling

In mode 11, a caller range is:

```text
directly visible    wholly inside 0000-1FFF, or wholly inside the common window
hidden              touching the switchable body
```

Decide on the whole range, not the starting address. Hidden objects go through the common workspace, an explicit crossing helper, or chunked transfer.

The facade uses a per-function table:

```text
FCB_IN   FCB_OUT   DMA_IN   DMA_OUT   SPECIAL   RETURNS_POINTER
```

```text
OPEN            FCB_IN + FCB_OUT
CLOSE           FCB_IN + FCB_OUT
READ SEQ        FCB_IN + FCB_OUT + DMA_OUT
WRITE SEQ       FCB_IN + FCB_OUT + DMA_IN
SETDMA          SPECIAL
PRINT STRING    SPECIAL
READ CONSOLE    SPECIAL          buffer up to 257 bytes
```

**DMA tracking (F10).** The facade holds the program's real DMA address. `SETDMA` sets it, and so does function 13, which resets it to `0080h` inside ZSDOS (`zsdos.z80:1080`).

**Forced staging.** The conditional path — staging only when a range is hidden — rarely runs, because most programs use the page-zero FCB and DMA. Build an option that stages every eligible call, and run the stress programs with it before enabling conditional staging.

---

## 14. Bulk Transfers (F4)

IOC bulk transfers **do not** cross the mapping mid-transfer. The bulk lane loses its first byte, is bound to the SIO Tx underrun latch, and runs in persistent sync, and a mapping change between chunks can underrun the transmitter.

`IOC_BULK_MAX_LEN` is 512 (`src/cbios_defs.inc:318`). Either:

- size the common transfer workspace to 512 bytes, so a bulk payload is one crossing; or
- keep the `OUTI`/`INI` byte loops in common and run them in mode 10, where the caller's buffer is simply its own memory.

Chunked crossings remain the general mechanism for future services without timing constraints, implemented once rather than per driver.

---

## 15. Stacks

**Never change the mode while SP points into memory that will disappear.**

Entry: save the caller's SP, switch to the common transition stack, enter mode 11, and then switch to a private bank-7 stack if wanted. Exit: return to common code, switch back to the common stack, restore mode 10, restore the caller's SP, return. `WBOOT`, fatal errors and every crossing helper follow the same rule.

**The interrupt return address lands first.** A maskable interrupt or NMI pushes the interrupted PC onto the current stack before the handler's first instruction runs. No handler can avoid those two bytes; it can only move everything that follows. So:

- every ISR switches to the common ISR stack as its first action, so its own pushes and calls never land on the interrupted stack (F2)
- every stack that runs with interrupts enabled keeps two bytes of headroom beyond its measured depth: the transition stack, ZSDOS's stack, the BIOS private stacks, and whatever stack a program runs on in mode 10
- ZSDOS gets a real stack (section 12.4), because its stock 56 bytes leaves no meaningful headroom

The ISR-stack switch uses a single saved-SP slot. The SIO handler and the CTC dispatcher run with interrupts disabled until their closing `EI` / `RETI`, and registered callbacks never enable them, so the slot is never reentered. An NMI source, if the board uses one, needs its own arrangement.

Measure every one of these stacks with the `STKCHK` fill from `rom-services`.

---

## 16. Mode Changes and the Existing Latch Writers

**The instruction that changes the mapping, and everything that must run immediately after it, executes from common memory.** After `OUT (00h)`, the next fetch comes from whatever the new mapping presents at that address.

**F3.** These existing routines restore the latch with a hardcoded mode 10:

```text
src/cbios_bank_select.asm:22       bank helpers
src/cbios_storage_rom.asm:176      drive A read
src/cbios_storage_sd.asm:217       SD record staging
src/cbios_bank.asm:45,139,150,171  SELMEM, SETBNK, MOVE, XMOVE
src/cbios_storage_ramdisk.asm:284  not linked
src/cbios_storage_vdrip.asm:364    not linked
```

Moved into bank 7 unchanged, each switches the lower address space away from the code executing it. They become crossing helpers in common that restore the mode bits they found, and `CURRENT_BANK` keeps the meaning in section 24.

The drive A read also does `DI` ... `EI` unconditionally, enabling interrupts for a caller that had them disabled. Fix it in the same pass.

---

## 17. BIOS and Driver Placement

The BIOS implementation, drivers and their private state live in bank 7, and OS-internal execution is ordinary calls in one address space:

```text
ZSDOS -> BIOS -> driver
```

Only state that must be visible across the mapping or from interrupt context stays common.

---

## 18. Interrupts: The BIOS Owns IM2

IM2 belongs to the BIOS. Programs request interrupt service; they do not install vector tables. CP/M 2.2 had no answer for interrupt-driven programs and CP/M 3 left interrupts inside the BIOS, but this machine's programs need timer interrupts that keep running during OS calls.

### 18.1 The BIOS interrupt path

All of it is common, because interrupts arrive in both modes:

- the IM2 vector page
- the SIO handler, the CTC dispatcher, and every stub the vector page points at
- the ISR registration slots
- RX sinks called from interrupt context, and every routine a sink calls
- ring and queue indexes and metadata
- handler-local state
- the common ISR stack (F2)

Payload buffers need not be common if the handler records minimal state and defers the work.

### 18.2 The vector page (F9)

`I` is loaded at cold boot, reloaded by `WBOOT`, and never otherwise changes. It always selects the BIOS vector page.

IM2 forms the table address as `I × 100h + vector`, so the page starts at a page boundary in permanent common memory. Programmed device vectors are even and lead somewhere safe:

```text
00h-06h      CTC channels 0-3     CTC dispatch stubs
10h-1Eh      SIO0                 BIOS SIO handler (10h is live; the rest
                                  cover status-affects-vector)
all others                        unexpected-interrupt stub: EI, RETI
```

The full page costs 256 bytes of common memory. A floating or unclaimed interrupt may supply `FFh`; the Z80 then reads the pointer across the page boundary, using `FDFFh` as its low byte and `FE00h` as its high byte. `FE00h` is therefore an immutable guard byte, and the pair selects the dedicated safe stub at `F7F7h`. The generated layout validates both the programmed even vectors and this cross-page `FFh` case.

The BIOS programs the CTC vector base and SIO0 `WR2` at cold boot and in `WBOOT`. Programs never write the CTC vector word.

### 18.3 Registration

A program that wants an interrupt registers a callback through the Zephyr BDOS range (section 10):

```text
REGISTER_ISR      source, callback address
UNREGISTER_ISR    source
```

Registration rejects the call unless:

- the source is registerable. In Phase 1 that is CTC channels 0-3. SIO0/B and SIO1 belong to the BIOS. SIO0/A delivers the same vector as SIO0/B while status-affects-vector is off, so it becomes registerable only if the SIO handler learns to dispatch by channel.
- the source is not already registered
- the callback entry lies within `E000h-E3FFh`

It writes the slot with interrupts disabled. The program then sets the channel's mode and time constant with its interrupt enabled, through the CTC ports as it does today, and stops the channel before unregistering.

### 18.4 Dispatch

```text
interrupt, in mode 10 or 11
    -> BIOS vector page -> CTC channel n stub
    -> common dispatcher
         switch to the common ISR stack, save AF BC DE HL
         slot n empty:    reset channel n
         otherwise:       CALL the callback
         restore registers and SP
         EI
         RETI
```

A channel enabled without a registration is shut off on its first interrupt instead of crashing, which also makes a program's unregister order forgiving.

**`EI` before `RETI` is required.** Accepting a maskable interrupt clears both IFF1 and IFF2, so a handler that ends in a plain `RETI` returns with interrupts disabled. `EI`'s one-instruction delay keeps the `RETI` from nesting. The current `sio_core_isr` in `src/sio_core.asm` ends in a plain `RETI`, and interrupts come back only when foreground code runs `EI`; fix it when the handler moves.

### 18.5 Callback contract

```text
location      entry, code, callees and state all within E000h-E3FFh
mapping       runs in mode 10 or mode 11; touches no memory below E000h
stack         the common ISR stack, with a fixed budget (for example 32 bytes)
registers     AF BC DE HL are free; IX, IY and the alternate set are preserved
interrupts    disabled throughout; never EI
return        RET, not RETI
never         BDOS, the BIOS, latch writes, waiting on a port
```

The caller window is also visible in both modes, but `SELMEM` changes what it holds, so callbacks are limited to the reservation. Registration validates only the entry address. The rest is the program's responsibility, and is checked in validation (section 27).

Keep callbacks to the count-and-return pattern. The CTC sits above SIO0 in the daisy chain (`IEI -> CTC -> SIO0 -> SIO1`), so a long callback delays console receive.

### 18.6 Lifetime (F5)

Registrations belong to the running program, and are cleared:

- by `WBOOT`
- when a transient returns to ZCPR2 without warm booting. `CALL TPA` falls through to `DEFDMA`, `DLOGIN` and `CONT` (`zcpr2/src/ZCPR2.ASM:2143-2146`), so ZCPR2 calls the program-exit extension there. `GO` and `JUMP` reach the same `CALL`.

Clearing disables interrupts, resets every registered CTC channel, empties the slots, and restores the interrupt state. Without it, a callback left registered vectors into a reservation the next program overwrites.

### 18.7 What the facade no longer needs

Every vector entry reaches common code, so interrupts stay as the caller had them across OS calls (section 9). There is no BDOS-safe declaration and no disable-by-default. A program that loads `I` or changes interrupt mode is outside the supported interface. A debug build asserts `I` on facade entry.

---

## 19. Warm Boot and Recovery

Warm boot arrives either from a program jumping to `0000h` in mode 10, or from ZSDOS through the common helper of section 12.2 (F1), which has already restored mode 10.

`WBOOT` trusts nothing about the dying context — not the mode, SP, bank, DMA, or partly completed driver work. It:

1. runs from common code on a known common stack
2. forces mode 10
3. selects bank 0
4. **reloads `I` with the BIOS vector page, resets the CTC, and reprograms the CTC and SIO vectors (F5)**
5. **reinitialises facade and crossing state and clears ISR registrations (F5)**
6. repairs page zero
7. reloads the CCP
8. reinstalls bank 7 only if policy requires it
9. enters the command processor

A transient that returns to ZCPR2 does not pass through `WBOOT`; section 18.6's program-exit call covers that path.

Bank 7 can always be rebuilt from ROM. Whether every warm boot reinstalls it is a policy decision, because doing so discards ZSDOS state that may be meant to persist.

---

## 20. ROM Policy

ROM holds reset and bootstrap code, the canonical bank-0 and bank-7 images, recovery firmware, diagnostics, and immutable fonts, tables and resources. Runtime execution happens from SRAM. The ROM-service gate and page-4 execution are retired.

What carries forward from the ROM work is the discipline, not the mechanism: separating code from state, generated addresses, `RES_`-style classification, interrupt-path audits, reentrancy rules, and restoring the latch mode that was found.

---

## 21. State Placement

Classify every BIOS, driver and ZSDOS support object as one of:

```text
COMMON REQUIRED
SYSTEM BANK 7
APPLICATION / TPA
CAN BE STAGED
ROM / IMMUTABLE
```

Must it be visible:

```text
1  in application mode?
2  in OS mode?
3  when an interrupt arrives?
4  while a program holds a pointer to it?
5  while a crossing helper runs?
```

Only 2: bank 7. Immutable: ROM. Crosses an interface only transiently: stage it. Common memory is only for objects that genuinely need cross-mode or asynchronous visibility.

---

## 22. Returned Pointers (F7)

A pointer returned to a program must stay valid in mode 10, so it cannot point into bank 7.

With the direct disk BIOS inert (section 11), no program can obtain a DPH, and the DPH, DPBs, allocation vectors, checksum vectors and directory buffer all live privately in bank 7.

That leaves BDOS functions 27 and 31, which return the address of the current drive's ALV and DPB. The facade copies them into common memory on the call and returns the copy's address:

```text
function 31    DPB copy     15 bytes
function 27    ALV copy     up to 256 bytes on the current SD geometry
```

Keep the two copies in separate areas, so a program that calls 27 and then 31 does not find its ALV overwritten. Each copy is a snapshot taken at the call, which is what `STAT` needs to report free space.

---

## 23. Common Memory: Contents and Budget

Permanent common contents:

```text
BDOS facade and exit                     direct BIOS entry: boot, console
mode and bank crossing helpers           WBOOT and recovery entry
transition stack and ISR stack           transfer workspace
cross-context state                      BIOS interrupt path
DPB and ALV copies for functions 27 and 31
```

Rough budget, **to be replaced by measurement of the built image**:

```text
DPB and ALV copies                                        ~275
BIOS interrupt path, queues, CTC dispatcher, ISR slots    ~400
IM2 vector page                                            256
BDOS facade, BIOS entry, crossing helpers, WBOOT          ~400
transition stack and ISR stack                            ~200
transfer workspace, bulk-sized                             512
cross-context state                                       ~100
                                                        ------
                                                        ~2,150
```

Against `F100h-FFFFh` (3,840 bytes) that leaves roughly 1,700 bytes. Dropping the direct disk BIOS is what moved the disk structures, about 1,000-1,250 bytes, into bank 7. Earlier estimates in this project were wrong in both directions, so the final `FBASE` comes from the linked binary, and the margin may allow a higher one.

The hardware common window is 8,192 bytes, and the program reservation takes 1,024 of it.

---

## 24. `CURRENT_BANK`

`CURRENT_BANK` means the running or suspended **application** bank. It does not mean the physical bank executing below `E000h`:

```text
mode 11:   CURRENT_BANK = N        physical body = bank 7
```

Entering the OS does not change which application bank is current.

---

## 25. Migration Plan

Don't combine moving the OS with shrinking common memory.
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

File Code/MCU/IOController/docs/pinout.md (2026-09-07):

# IO Controller Pinout

Target MCU: `PIC18F57Q84` (U15, `-I/PT`, 48-pin TQFP)

Net names are the schematic net names.  Polarity follows the schematic
overbars: barred nets are active-low, everything else is active-high.  Only
`RESET_HIGH`, `PWR_OFF` and `SHUTDOWN_RQ` are active-high; the six
`*_CS` selects and `/USB_INT` are active-low like the rest.

Macro names keep a `HOST_` prefix on the reset and NMI outputs because `<xc.h>`
already claims `RESET()` and `NMI`.

`ANSELA`, `ANSELB`, `ANSELD`, `ANSELE` and `ANSELF` are all cleared to `0x00` in
`platform_init()`, so every pin below is digital.

## Port A — peripheral selects and External Sync

| Pin | Port | Signal | Direction | Active | Macro | Notes |
|---|---|---|---|---|---|---|
| 21 | RA0 | `/USB_INT` | Input | Low | `USB_INT_PORT` | MAX3421E interrupt. Configured as an input; dispatch is intentionally deferred until the enumeration phase. |
| 22 | RA1 | `/CTRL_LAT_CS` | Output | Low | `CTRL_LAT_CS_LAT` | Enables the buffer feeding the cascaded controller 74AHC595s' tied SRCLK/RCLK inputs on the **port C** bus. |
| 23 | RA2 | `/IO_SD_CS` | Output | Low | `IO_SD_CS_LAT` | SD card select. Held idle by the current firmware. |
| 24 | RA3 | `/IO_USB_CS` | Output | Low | `IO_USB_CS_LAT` | MAX3421E select. Used during bounded controller bring-up; otherwise released until enumeration is enabled. |
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

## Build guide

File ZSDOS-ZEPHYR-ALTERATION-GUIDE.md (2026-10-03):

# Zephyr / ZSDOS Alteration Guide

> **Audience:** Developers who want to modify the Zephyr-80 operating system,
> add storage personalities, extend BDOS/native services, alter BIOS behavior,
> or change the IOC protocol without accidentally breaking CP/M/ZSDOS
> compatibility.
>
> **Source of truth:** The current repository, generated memory map, and
> hardware behavior are authoritative for implementation details. This guide
> records the architectural contracts and procedures that should survive code
> movement and refactoring.
>
> For the history behind these rules, including the bugs and experiments that
> exposed them, see
> [FAT-BRINGUP-LESSONS-LEARNED.md](FAT-BRINGUP-LESSONS-LEARNED.md).

---

# Part 0 — The Exploded View

This part names the parts. It describes how the system is built; it does not say
what you may do to it. Every rule in this document lives in Part I, and every
procedure in Part II. If a sentence here sounds like an instruction, it is
describing a mechanism, not imposing a constraint.

Read it once before the rest. The procedures in Part II assume you know what the
facade is, what bank 7 is for, and why there are two ways to reach the same
file; without that they read as arbitrary ceremony.

---

## 0.1 The machine

A Z80 with a 64 KiB address space, more memory than fits in it, and a
microcontroller that owns the hardware the Z80 cannot reach.

Eight 64 KiB SRAM banks sit behind a banking latch. Bank 0 is the ordinary
application bank and backs common memory; banks 1-6 are application banks; bank
7 is the operating system and is never application memory — the bank primitives
reject any attempt to select it.

The latch carries a bank number and a two-bit memory mode:

| Mode | Name | `0000h-1FFFh` | `2000h-DFFFh` | `E000h-FFFFh` |
|---|---|---|---|---|
| `00` | ROM | ROM page | ROM page | ROM page |
| `01` | flat | bank N | bank N | bank N |
| `10` | application | bank N | bank N | bank 0 |
| `11` | OS | bank N | **bank 7** | bank 0 |

Modes 10 and 11 differ by one bit, and only in the middle. That single
difference is the whole banked design, and it produces **three address classes**
that the rest of this document refers to constantly:

**The caller window, `0000h-1FFFh`.** The running program's bank in *both*
modes. It holds CP/M's page zero — the warm-boot vector at `0000h`, the BDOS
vector at `0005h`, the default FCBs, the default DMA at `0080h`. Because it does
not move, ZSDOS reads the program's real page zero while the OS is running, with
no copies to keep synchronised, and the common case of a default FCB and DMA
needs no marshalling at all.

**The switchable body, `2000h-DFFFh`.** The application's bank in mode 10; bank 7
in mode 11. This is the OS's private implementation space. A program's memory
here *disappears* while the OS runs, which is why anything the OS must read from
or write to the caller has to be staged.

**Common memory, `E000h-FFFFh`.** Bank 0 in both modes, the same bytes always
visible. This is where crossing code, interrupt handlers, staging buffers and
the published entry points live — and it is only 8 KiB, every byte of which is
subtracted from every program's address space.

The latch keeps the application's bank number while the OS runs, so entering and
leaving the OS is a single bit change and nothing has to remember which bank was
suspended.

Alongside the Z80 sits the **IO Controller**, a PIC microcontroller reached over
a synchronous serial link with a command lane and a bulk lane. It owns the SD
card, the USB keyboard, and — importantly — the FAT filesystem. No FAT
implementation runs on the Z80.

### The exploded diagram

Where the software actually sits. Addresses are from the current default build;
`docs/memory-map.md` is regenerated every build and is the authority.

```text
          MODE 10 — what a program sees          MODE 11 — what the OS sees

 FFFFh  +=====================================================================+
        |  COMMON MEMORY — bank 0, identical in both modes, 8 KiB total       |
        |                                                                     |
        |  Four zones, each ONE contiguous run, growing up from EC00h:        |
        |    EC00h  Z1 ABI      facade (CALL 5, FBASE, 200-219), BIOS tables |
        |    F1B0h  Z2 crossing SIO return, 218 gate, banking, gates         |
        |    F4F0h  Z3 interrupt CTC, SIO core, dispatch, policy, registration|
        |    F850h  Z4 driver   the console driver's ISR half, either-or      |
        |    FA00h  staging buffers ·  FD00h IM2 vector page                  |
        |    FE01h  BIOS state      ·  FE80h ISR / gate / facade stacks       |
        +=====================================================================+
 EC00h  |  E400h-EBFFh  CCP slot — the default shell's loader (ZephyrShell    |
        |               shim, or ZCPR2), inside the TPA: a transient may      |
        |               overwrite it; the supervisor reinstalls it from       |
        |               the bank-7 asset at every shell launch                |
 E400h  +---------------------------------------------------------------------+
        |  E000h-E3FFh  the running program's interrupt callbacks             |
 E000h  +-------------------------------+-------------------------------------+
        |                               |  BANK 7 — the OS body               |
        |                               |                                     |
        |                               |    C000h  BIOS stacks, SD scratch,  |
        |                               |           pristine CCP, FAT state,  |
        |   TRANSIENT PROGRAM AREA      |           supervisor state          |
        |   0100h-EC05h, 58.8 KiB       |    BE00h  transient supervisor      |
        |   continues up through E000h  |    B800h  SIO, console tee,         |
        |   in the program's own bank   |           VDrip transport (bank 7)  |
        |   (N = 0..6)                  |    A000h  FAT BDOS personality,     |
        |                               |           FS2 client, read cache    |
        |                               |    9000h  console driver slot       |
        |                               |    8000h  font, boot banner         |
        |                               |    6000h  DPH/DPB, dir buffer,      |
        |                               |           reclaimable cache pool    |
        |                               |    5A00h  /SYSTEM/A provider        |
        |                               |    3000h  BIOS facades, drivers,    |
        |                               |           IOC command + bulk lanes  |
        |                               |    2000h  ZSDOS                     |
 2000h  +===============================+=====================================+
        |  CALLER WINDOW — the program's bank in BOTH modes                   |
        |    0100h-1FFFh  the bottom of the TPA                               |
        |    0000h JP WBOOT · 0005h JP FBASE · 005Ch FCBs · 0080h default DMA |
 0000h  +=====================================================================+

                                  |  synchronous serial: command + bulk lanes
                                  v
        +---------------------------------------------------------------------+
        |  IO CONTROLLER (PIC18F57Q84)                                        |
        |    FatFs filesystem manager · FS2 service · SD card · USB keyboard  |
        +---------------------------------------------------------------------+
```

Three things in that picture explain most of the design:

- The OS body and the program's memory occupy **the same addresses**. They cannot
  both be visible.
- Common memory is **small and shared**, so what goes there is rationed.
- The filesystem is **on the other side of a serial link**, so file operations
  are transactions with latency, not memory accesses.

And one thing the picture can mislead about: common memory is 8 KiB, but the OS
does not own all of it. `E000h-EBFFh` — the interrupt-callback reservation and
the CCP slot — belongs to the running program. Page zero's `0006h` holds
`EC06h`, so the transient program area really does run to `EC05h`, and whatever
sits in the CCP slot is a user program inside it, not a layer above it. The OS's
share of common memory starts at the BDOS facade.

---

## 0.2 The software pieces

| Piece | Where it runs | What it is |
|---|---|---|
| **ZephyrShell** (`ZSH.COM`) | TPA, `0100h` | the default shell (`CCP=zshell`, the default build). An ordinary C transient with a native, path-oriented command line; it reaches files through BDOS 218 and launches programs through BDOS 219. Not an OS component and not resident |
| **CCP slot** | `E400h-EBFFh`, inside the TPA | holds the default shell's loader: the ZephyrShell shim, which loads `A:ZSH.COM`, or ZCPR2 itself (`CCP=zcpr2`). A user program at a fixed high address, which a transient may overwrite; the supervisor reinstalls it from a pristine copy in bank 7 at every shell launch |
| **transient supervisor** | bank 7, `BE00h` | the resident owner of the single foreground program. Decides what runs after cold boot and after warm-boot teardown — today always the default shell. Not a scheduler |
| **BDOS 219 loader** | common, `EFB1h` | the shell-private destructive loader: reads an already-open native file to `0100h` over the shell, tells the supervisor a child now owns the TPA, and jumps |
| **ZSDOS** | bank 7, `2000h` | the BDOS. A ZSDOS build, not stock CP/M. Authoritative for current drive, USER, and write protection |
| **BDOS facade** | common, `EC00h` | the only application-to-OS crossing. Publishes `FBASE`, stages caller objects, enters mode 11, restores the caller's mapping on the way out |
| **bank-7 dispatcher** | bank 7 | decides, per call, whether Zephyr semantics apply or the call goes to ZSDOS unchanged |
| **BIOS** | split | CP/M jump table and crossing gates in common memory; console, storage and transport bodies in bank 7 |
| **drivers** | bank 7 slots | console and storage backends behind facades, selected at build time |
| **CP/M FAT personality** | bank 7, `9000h` | translates FCBs, 128-byte records, extents, USER areas and SEARCH into byte-oriented file operations |
| **native API** | bank 7 | `ZOPEN`/`ZREAD`/`ZWRITE`/`ZCHDIR`/`ZMKDIR`, reached through BDOS function 218. Paths and bytes, no FCBs. C programs use it through ZephyrC's `<zephyr/fs.h>` |
| **native namespace router** | bank 7 | `native_vfs_entry`: routes each function-218 call to the writable FS2 root or to the synthetic read-only `/SYSTEM/A` view of drive A: |
| **FS2 client** | bank 7 | the byte-oriented engine both personalities converge on: resolver, handles, 512-byte read cache |
| **IOC transport** | bank 7 + common | `IOCALL` (32-byte mailbox), `IOCBULK`/`IOCBULKW` (block transfer) over the command and bulk lanes |
| **FatFs** | IO Controller | the actual filesystem, on the MCU, over the SD card |
| **resource layer** | above the native API | caching, prefetch, streaming and symbolic asset lookup. Not a filesystem |

How they connect:

```mermaid
flowchart TB
    APPS["CP/M applications and transients<br/>(bank 0 TPA)"]
    ZSH["ZephyrShell — ZSH.COM<br/>default shell, ordinary transient"]

    FAC["BDOS facade — CALL 5<br/>stages FCB and DMA, crosses into bank 7"]

    APPS -- "FCB calls" --> FAC
    APPS -- "function 218" --> FAC
    ZSH -- "function 218" --> FAC
    ZSH -- "function 219: exec" --> LOAD["BDOS 219 loader<br/>common"]
    LOAD -- "child replaces shell" --> APPS

    subgraph BANK7["Bank 7 — OS implementation"]
        direction TB
        ZS["ZSDOS core<br/>current drive · USER · write protect"]
        NATIVE["Native byte API<br/>ZOPEN ZREAD ZWRITE ZCHDIR ZMKDIR"]
        VFS["Namespace router<br/>/ → FS2 · /SYSTEM/A → A: (read-only)"]
        SUP["Transient supervisor<br/>next foreground program"]
        ROMD["ROM rescue disk<br/>A:"]
        SYN["Synthetic BIOS DPH<br/>B:"]
        CONV["Conventional BIOS DPH<br/>C: · D:"]
        PERS["CP/M FAT personality<br/>128-byte records · extents · USER to @N"]
        FS2["FS2 byte-oriented engine<br/>resolver · handles · 512-byte read cache"]
        SDB["SD record backend<br/>512-byte deblock line"]
    end

    FAC --> ZS
    FAC --> NATIVE
    NATIVE --> VFS
    VFS --> ROMD
    LOAD -- "512-byte reads" --> VFS
    LOAD -. "records FG_CHILD" .-> SUP
    ZS --> ROMD
    ZS --> SYN
    ZS --> CONV
    SYN --> PERS
    PERS --> FS2
    VFS --> FS2
    CONV --> SDB

    subgraph MCU["IO Controller — PIC18F57Q84"]
        direction TB
        FATFS["FatFs filesystem manager"]
        SD["SD card — raw blocks"]
        FATFS --> SD
    end

    FS2 == "SIO1 command + bulk lanes" ==> FATFS
    SDB == "SIO1 command + bulk lanes" ==> SD
```

Reading it:

- **ZSDOS stays on the CP/M path and owns CP/M state.** The FAT drive reaches it
  as an ordinary BIOS drive through a synthetic DPH, which is what lets drive
  selection, USER and write protection keep working normally.
- **The two personalities converge at FS2, not above it.** The CP/M personality
  translates FCBs, records, USER areas and SEARCH semantics. The native API does
  not.
- **The facade is the only application/bank-7 crossing.** Caller pointers and
  buffers are staged there, which is why its aliasing and status-preservation
  behavior is part of the ABI.
- **The controller owns FAT.** No FAT implementation runs on the Z80.
- **Nothing owns the TPA permanently.** The shell, and any program it launches,
  are ordinary transients that replace one another at `0100h`. Every exit goes
  through warm boot, and the supervisor then picks the next program. §0.4 has the
  sequence, and §21 has the rules for changing it.

Authority for each piece of CP/M state — who is allowed to be the one true copy
of the current drive, USER, write protection and the rest — is a rule rather
than a description, and the table lives in Part I, §2.

---

## 0.3 The source tree

The tree is organized by **memory class**, not by subsystem. That is the first
thing to understand about it, because it is unusual and it is load-bearing: a
file's directory tells you which memory it ends up in, and therefore which rules
apply to it.

```
Code/HOST/CPM2.2/
├── src/
│   ├── layout/      the address authority — no code at all
│   │   ├── memory.inc      every base, every ceiling, the ASCII maps
│   │   ├── modes.inc       latch values and bank constants
│   │   └── platform.inc    ports and board wiring
│   ├── common/      code that lives in common memory (E000h–FFFFh)
│   ├── core/        bank 7 — defines contracts
│   ├── drivers/     bank 7 — implements contracts
│   │   ├── console/
│   │   ├── storage/
│   │   └── transport/
│   ├── assets/      bank 7 — data read at boot (the font)
│   └── zephyr.asm   the wrapper that includes the common and core units
├── tools/           build, layout validation, documentation generators
├── tests/           libqkz80 harnesses (C++)
├── docs/            generated maps plus design notes
└── config/          banks.ini (ROM payloads), diskdef (cpmtools)
```

**The directory is a promise, and the build checks it.** `DIRECTORY_CLASS` in
`tools/generate_memory_docs.py` maps each top-level directory to a memory class,
and every region declares which file it came from. If a module under `core/`
assembles to an address in common memory, or a module under `common/` lands in
bank 7, the build stops and names the file. That check exists because the
boundary used to be a matter of memory and convention, and modules drifted across
it.

### What is in each directory

**`common/`** — the small set of things that genuinely must be addressable under
more than one bank latch. The test for belonging here is in §3: an object belongs
in common only if its address must resolve to the same bytes under more than one
latch state. Three situations qualify — an interrupt (the latch is unknown), a
mode switch (the latch is changing), and an object written under one mapping and
read under another.

| File | What it is |
|---|---|
| `boot.asm` | cold boot, warm-boot teardown, page zero, the runnable-bank setup |
| `supervisor.asm` | the supervisor's common half: the policy-free final switch into the selected program, and the 219 loader's crossing into bank 7 |
| `exec_loader.asm` | BDOS 219, the destructive `.COM` loader |
| `rom_copy.asm` | the reset-vector bootstrap that copies ROM into SRAM |
| `bios_table.asm` | the CP/M BIOS jump table and the Zephyr extension table |
| `facade.asm` | `CALL 5` — the BDOS ABI surface, functions 200–219 |
| `gates.asm` | the crossing gates into bank 7, and the warm-boot trap |
| `crossing.asm` | mode-preserving bank select; the ROM-access primitive |
| `banking.asm`, `bank_select.asm` | `SELMEM`, `SETBNK`, `XMOVE`, `MOVE` |
| `irq.asm` | the IM2 dispatcher, policy, CTC mapping, callback registration |
| `sio.asm` | the SIO core: init, receive sinks, the RX interrupt body |
| `sercon.asm`, `vdrip.asm` | the ISR-reachable halves of two console drivers |
| `native_gate.asm`, `native_stage.asm` | function 218 and its staging |

Note the last row of drivers in `common/`: those files hold **only** the part of
a driver an interrupt can reach. The rest of each driver is in `drivers/`. That
split is deliberate and is the subject of §15.

**`core/`** — bank 7, and the layer that *defines* an interface for something
else to implement. `console.asm` is the console facade every backend plugs into;
`storage.asm` is the disk facade and drive dispatcher; `video_send.asm` is the
raw video request path; `iocall.asm` and `sio.asm` are the IO Controller and SIO
services reached from bank 7; `bios7_table.asm` is the table ZSDOS calls;
`banner.asm` prints the boot banner; `supervisor.asm` is the transient
supervisor's policy and its state.

**`drivers/`** — bank 7, and the layer that *implements* one of those contracts
for a particular device. A driver is a backend. `console/v9958.asm` and
`console/vdrip.asm` are alternative console backends selected by `CONSOLE=`;
`storage/rom.asm`, `storage/sd.asm`, `storage/fat.asm` and `storage/vdrip.asm`
are drive backends; `storage/native_vfs.inc` is the function-218 namespace router
and `storage/cpm_mount.asm` the read-only `/SYSTEM/A` provider behind it;
`transport/ioc_command.asm` and `transport/vdrip.asm` are link transports.

**`layout/`** — no code, only addresses. `memory.inc` is the single authority for
where everything lives: every region's base, every region's ceiling, the state
and stack addresses, and two ASCII maps kept in step with the generated
documentation. When an address in this guide and an address in `memory.inc`
disagree, `memory.inc` is right; when `memory.inc` and `docs/memory-map.md`
disagree, the generated map is right, because it is measured from the build.

**Sibling projects.** The default image also contains two things built outside
this tree, in `Code/HOST/`:

| Project | What it contributes |
|---|---|
| `ZephyrShell/` | `ZSH.COM`, placed on drive A:, and `build/ccp-zshell.bin`, the 2 KiB shim installed in the CCP slot. Its `ARCHITECTURE.md` is the shell's own design reference |
| `ZephyrC/` | the C runtime library and `<zephyr/fs.h>`, the typed wrapper over BDOS function 218 that ZephyrShell and other C programs use |

With `CCP=zcpr2` neither is linked, and ZCPR2 from `zcpr2/` fills the CCP slot.

### How a build assembles it

`zephyr.asm` is the wrapper: it includes the `layout/` headers, then the
`common/` and `core/` units, and assembles as one translation unit. Each driver
assembles **separately**, into its own `.rel`, and the Makefile chooses which
objects to link. So a configuration choice is a link input, not a rewritten
`.include` — which is why `CONSOLE=vdrip` and `CONSOLE=v9958` are the same source
tree with different objects.

Each driver's areas are namespaced per file. That is not cosmetic: same-named
`.area` blocks concatenate across translation units in `sdasz80`, which once
silently placed a driver 164 bytes past where its `.org` said. `tools/check_org_placement.py`
now compares every `.org <symbol>` against that symbol's resolved address on
every build.

---

## 0.4 How the machine boots

Boot is four stages, and the interesting part of each is what is *not* safe to do
yet.

### Stage 1 — reset, in ROM, no RAM and no stack

The Z80 resets to `0000h` with the latch in mode 00: ROM page 0 is mapped, there
is no usable RAM, and therefore no stack and no `CALL`. `rom_copy.asm` runs from
the reset vector and does exactly one job — get the system into RAM:

1. copy all 64 KiB of ROM page 0 into SRAM bank 0;
2. switch the latch to ROM page 7 and copy all 64 KiB into SRAM bank 7;
3. switch to mode 10 (application) and fall through into `boot`.

Step 2 contains the only real trick in the boot path. The code switches the ROM
page *while executing*, so the instruction after the `out` must exist, with
identical bytes, at the same address in both ROM pages. The source says so at the
point it matters:

```asm
	ld a,#(BOOT_OS_ROM_PAGE << ROM_PAGE_SHIFT) | MEM_MODE_ROM | OS_BANK
	out (BANK_PORT),a
	; The next instruction has identical bytes at this address in page 7.
	ld hl,#0x0000
```

The whole bootstrap has a byte budget in page zero, asserted at assembly time,
because it has to fit below the CP/M vectors it will later install.

### Stage 2 — cold boot: `boot`

Now RAM exists. The order here is a sequence of preconditions, and almost every
line has one:

| Step | Why it is where it is |
|---|---|
| latch to mode 11, **then** set `SP` | the BIOS stack is in bank 7, so bank 7 must be mapped before `SP` points into it |
| `irq_boot_prepare` | sets `I` = `FDh` and IM 2 before anything can interrupt |
| `sound_silence_psgs` | the PSGs power up making noise |
| `sio_core_init` | brings up the console link — needed by the next step to report failure |
| **`bank7_check`** | nothing in bank 7 may be called until it is known to hold *this build's* image. It reports over SIO0/B, which is common, and halts |
| `sio1_ioc_init` | SIO1/A is a **cold-only** device; see below |
| `ioc_link_bringup` | fixes the IOCALL character boundary now rather than lazily. Failure is deliberately unchecked — SIO1 shares nothing with the console or A: |
| `console_backend_cold_init` | the build-selected display and input backend |
| `sercon_init` | after the backend, because it copies the backend's driver table; before the banner, so an already-armed terminal sees the boot messages |
| `boot_print_banner` | the first thing a human sees |
| `prepare_runnable_bank` | installs page zero: `JP WBOOT` at `0000h`, `JP FBASE` at `0005h`, DMA at `0080h` |
| `facade_reset`, `boot_fat_context_reset`, zero `IOBYTE`/`TDRIVE`/`DMA_BANK` | OS state to a known point |
| `sio_core_enable_interrupts`, `irq_enable` | interrupts come on **last**, only once console state, banking state and page zero are coherent |
| `supervisor_cold_start` | initialization is finished, so the first *foreground decision* is now the supervisor's: it writes its state block and selects the default shell (Stage 4) |
| `supervisor_enter_foreground`: `SP` → `FAC_STACK_TOP`, latch to mode 10, `JP (HL)` | the BIOS stack is in bank 7; an interrupt between the latch switch and the program setting its own stack would otherwise push into bank 0's `C000h–DFFFh`. Arrives at `CCP_CLEARBUF_ENTRY` with `C` = 0, drive A: |

### Stage 3 — warm boot: `WBOOT`

Warm boot is the CP/M transient termination path. It is entered from the BIOS
jump table and from page zero's `JP` at `0000h`. A program reaches it by `RET` to
its return word, by BDOS 0, which ZSDOS routes through `wbtrap`, or by `JP 0000h`.
That means **it can be entered from any bank, with any latch state, with a stack
pointing anywhere.** That single fact shapes the first six instructions:

```asm
wboot_masked:
	ld a,#OS_EXEC_LATCH
	out (BANK_PORT),a          ; latch first
	xor a
	ld (CURRENT_BANK),a
	ld (DMA_BANK), a
	ld sp,#CBIOS_STACK_TOP     ; only now is a stack safe
```

No stack use and no helper `CALL` happens before the latch is set. `wboot` itself
is a two-instruction trampoline into `wboot_resident` precisely so that this
protected body can be validated as its own region.

After that it tears down whatever the program left behind and rebuilds the
CP/M environment:

- `irq_boot_prepare` and `sound_silence_psgs` return application-owned devices
  and callbacks to CP/M ownership;
- **`console_wait_key`** holds the screen so the operator can read whatever the
  program left before the console is cleared. Interrupts are on for this wait, so
  a serial console can answer it, and the wait gives up on its own — a program
  that broke console input cannot strand the machine;
- `sio_core_init` rebuilds **the console only**;
- page zero, facade and FAT context are rebuilt as in cold boot. The FAT
  context reset closes transient native handles and the directory iterator,
  preserves the writable current directory, and resets the `/SYSTEM/A` provider
  to its root;
- `console_init` reinitializes the display. The font is in bank 7 where no
  program can overwrite it, so no restore from ROM is needed;
- `sercon_install` rebinds the serial console tee — `console_init` just reset
  `CONSOLE_DRIVER` and `sio_core_init` cleared the RX sink, so without this the
  tee dies on the first warm boot. `install`, not `init`, because it must
  preserve the armed flags;
- interrupts on;
- **only now** `supervisor_after_teardown`, then `supervisor_enter_foreground`
  (Stage 4). `C` = `TDRIVE`, so the selected drive survives a warm boot.

Warm boot holds no next-program policy. It does not restore the CCP slot and
does not know that a shell comes next; both are the supervisor's.

### Stage 4 — the supervisor chooses; the shell runs

The supervisor (`core/supervisor.asm`, bank 7) is the one resident component
that owns the foreground program. It is a **single-foreground-transient
supervisor, not a scheduler**: one program owns the TPA at a time, with no
process IDs, no task switching and no resident parent.

```text
BOOT initializes.  WBOOT tears down.  SUPERVISOR decides.
LOADER launches.   APPLICATION runs.
```

Its state is four bytes in bank 7: a layout version, the **foreground role**
(`FG_NONE`, `FG_SHELL`, `FG_CHILD`), the **execution policy** (`EXEC_REPLACE`,
the only one), and flags. Launching the default shell means four steps. The
supervisor reinstalls the CCP slot from the pristine bank-7 copy and records
`FG_SHELL`. It returns the entry point, `CCP_CLEARBUF_ENTRY`, and `TDRIVE` to
common code, which switches to mode 10 and jumps.

In the default build the CCP slot holds the ZephyrShell shim. It loads
`A:ZSH.COM` to `0100h` with ordinary FCB I/O, selects `B:` as the compatibility
drive, and jumps to the shell. From there:

```text
ZSH.COM (FG_SHELL)
   |  external command: open the file through function 218,
   |  build page zero (FCBs, command tail), call BDOS 219
   v
BDOS 219 loader -- reads 512-byte chunks over the shell, records FG_CHILD,
   |               closes the handle, pushes WBOOT, JP 0100h
   v
child .COM (FG_CHILD)
   |  RET / BDOS 0 / JP 0000h
   v
WBOOT teardown -> supervisor -> default shell again
```

The shell exiting (Ctrl-C at its prompt calls BDOS 0) takes the same path and
is respawned. If the shim cannot load `ZSH.COM` — missing, a read error, or too
large — it prints a `supervisor:` diagnostic and **halts**. It never warm-boots,
because that would only ask the supervisor to load the same broken shell again.

With `CCP=zcpr2` the slot holds ZCPR2, which is its own shell and loads programs
itself. The supervisor treats it the same way, as the default shell's loader in
the CCP slot.

### Cold versus warm, at a glance

| | Cold | Warm |
|---|---|---|
| ROM → SRAM copy | yes, both banks | never |
| `bank7_check` | yes | no — already validated |
| SIO1/A (`sio1_ioc_init`) | yes | **no** |
| `ioc_link_bringup` | yes | no |
| Next program chosen by | `supervisor_cold_start` | `supervisor_after_teardown` |
| CCP slot | reinstalled from the pristine copy in bank 7 by the supervisor | same |
| Console | `console_backend_cold_init` | `console_init` |
| Serial tee | `sercon_init` | `sercon_install` (preserves armed flags) |
| Screen hold | no | `console_wait_key` |
| Selected drive | A: | `TDRIVE` preserved |

The SIO1/A row is the one to remember. **Warm boot must not repeat
`sio1_ioc_init`:** its channel reset would destroy the persistent External-Sync
character boundary on the Bulk lane while the host and MCU sync flags remain set,
and the link would then be silently misframed. The console link is rebuilt on
every warm boot; the IO Controller link is established exactly once per power-on.

---

## 0.5 The two personalities

This is the single most important concept in the document.

The same files on the same card are reachable two ways, and the two ways mean
different things:

```text
                         FatFs / media
                              |
                     +--------+--------+
                     |                 |
              CP/M compatibility   native Zephyr
                     |                 |
                 FCB / USER         paths / bytes
                 128-byte records   larger transfers
                 synthetic extents  directories
```

**The CP/M personality exists for unmodified software.** PIP, STAT, CRC, an
assembler written in 1981 — none of them know anything about FAT, and none of
them should have to. So the FAT drive is presented as an ordinary CP/M drive:
FCBs, 128-byte records, extents, USER numbers, SEARCH FIRST/NEXT. Everything
CP/M software expects is synthesized on top of a filesystem that has none of it
natively.

**The native personality exists so that new software need not inherit CP/M's
limits.** A 128-byte record and a 36-byte FCB are not a good interface to a file
in 2026. The native API takes paths, transfers arbitrary byte counts, and knows
about directories.

A native call still arrives through `CALL 5`. That does **not** make it a CP/M
filesystem operation — BDOS function 218 is a syscall gateway to native
semantics, not a CP/M function.

They converge at FS2, deliberately low. Everything CP/M-shaped — extent
arithmetic, `e5h` directory slots, the USER-to-`@N` projection, SEARCH
continuation state — lives in the CP/M personality above FS2 and nowhere else.
Collapsing the two views into one would mean either giving native software
CP/M's limits or giving CP/M software semantics it cannot survive.

The CP/M personality reaches ZSDOS as a **synthetic BIOS drive**. It supplies a
DPH, a DPB and an allocation vector that describe a plausible empty disk, so
ZSDOS can select and log the drive by its ordinary machinery. Real file access
happens above that layer. The synthetic disk is also a safety net: an operation
that accidentally falls through to ordinary ZSDOS disk processing sees an empty
disk rather than whatever conventional drive was selected before.

---

## 0.6 The boundaries

Knowing which crossings are contractual is what keeps you from breaking one by
accident.

| Boundary | Kind | Notes |
|---|---|---|
| `CALL 5` / `FBASE` | **ABI** | the published program interface, including the Zephyr function range |
| BDOS function 218 descriptor | **ABI** | versioned; the native syscall gateway |
| `<zephyr/fs.h>` (ZephyrC) | **API** | the C programs' view of function 218; source-compatible, not an address contract |
| BDOS function 219 | **private ABI** | shell-only destructive loader; takes a function-218 READ descriptor holding an open handle. ZephyrShell is its only caller, but the calling convention is shared across two separately built projects |
| CCP slot entry (`E400h`/`E403h`) | **ABI** | the CP/M CCP entries; whatever the default shell's loader is, it must keep both jumps |
| page zero conventions | **ABI** | `0000h`, `0005h`, default FCBs, `0080h` DMA |
| CP/M BIOS jump table | **ABI** | order and entry semantics are fixed; new calls append |
| BDOS functions 27 / 31 returns | **ABI** | caller-visible copies, which is why they are copies |
| IOC command and bulk protocol | **ABI across processors** | Z80 and MCU are flashed separately; both sides must agree, and capability level is part of the contract |
| facade → bank-7 dispatcher | internal | staging and crossing mechanism, may change together |
| dispatcher → ZSDOS | internal | but ZSDOS's own state authority is not internal |
| CP/M personality → FS2 | internal | the convergence point |
| native API → FS2 | internal | |
| FS2 → IOC transport | internal | |
| console facade → driver table | internal | seven-entry table; stable by convention, not published to programs |
| storage facade → backend | internal | neutral `stg_a_*` entry points |
| BOOT/WBOOT → supervisor | internal | the supervisor returns `HL` = entry and `C` = drive. Teardown must finish first (§6) |
| BDOS 219 → supervisor | internal | `zexec_commit_close` records the child before the jump |
| supervisor state block | internal | bank 7, versioned; no program can see it |
| native router → providers | internal | handle `80h` is the `/SYSTEM/A` provider's; everything else is FS2's |
| SIO0/B, SIO1 lanes | **hardware** | flow control, clocking and interrupt behavior are electrical facts |
| banking latch | **hardware** | the decoder revision is part of the contract |

The asymmetry worth internalizing: **anything a program or another processor can
observe is contractual, and almost nothing else is.** The layering inside bank 7
is yours to rearrange; the moment a value, pointer or packet crosses into an
application or onto the wire, it is not.

---

## 0.7 The drive and namespace model

Four drive letters, three kinds of backend:

| Drive | Backend | Notes |
|---|---|---|
| `A:` | ROM rescue disk | read-only volume in flash; the recovery path, built from a manifest |
| `B:` | FAT personality | synthetic DPH over FS2 and FatFs on the controller |
| `C:`, `D:` | conventional CP/M volumes | real record-oriented CP/M filesystems on SD units |

The native namespace, seen through function 218 and therefore by ZephyrShell,
is laid out differently from the drive letters:

| Path | Provider | Notes |
|---|---|---|
| `/` and below | FS2 root on the card | writable; the current directory survives warm boot |
| `/SYSTEM/A` | synthetic, read-only view of drive A: | one file handle and one iterator; its current directory resets to `/` on every warm boot |

Both namespaces reach drive A:'s contents: as `A:` through ZSDOS and as
`/SYSTEM/A` through the native router. The `/SYSTEM/A` provider parses A:'s CP/M
directory itself and never calls the BDOS recursively.

`C:` and `D:` matter beyond their own contents: they are the **oracle**. When a
FAT behavior is in question, the same operation on a conventional drive shows
what CP/M actually does.

The FAT namespace projects CP/M's USER numbers onto directories:

```text
USER 0: /CPM/D/<relative-CWD>/<name>
USER N: /CPM/D/@N/<relative-CWD>/<name>
```

Three separate things are easy to conflate here:

- **The drive letter** (`B:`) is the CP/M-visible drive number. It is
  configuration, not ABI, but it appears in more places than one constant —
  layout definitions, dispatch arithmetic, utilities with compiled-in
  assumptions, tests, and help text. Changing it is a coupled release.
- **The on-card root** (`/CPM/D`) is a filesystem convention. The `D` is
  historical and no longer matches the drive letter. That is legal, because the
  root component is not the ABI drive number — but a future remap should state
  deliberately whether the directory is renamed too.
- **The USER projection** (`@N`) is a directory layer inside the root, owned by
  the FAT personality. A relative current directory belongs to the USER that
  selected it, and drive *availability* is a property of the root — not of
  whatever subdirectory happens to be current.

---

## 0.8 Where changes usually land

The reader's index. Find the shape of your change, then read the procedure.

| I want to… | The relevant piece | Procedure |
|---|---|---|
| find my way around the source | the tree, organized by memory class | §0.3 |
| understand what happens at power-on or warm boot | the four boot stages | §0.4 |
| change the shell, how programs are launched, or what runs after a program exits | ZephyrShell, BDOS 219, the transient supervisor | §21 |
| build an image, or change a build option | the Makefile and its validators | §9 |
| change or intercept a BDOS function | facade + bank-7 dispatcher | §11 |
| add a new native (non-CP/M) operation | native API + function 218 gate | §12 |
| add a native namespace provider like `/SYSTEM/A` | function-218 router | §12, §21 |
| add or change an IOC command | FS2 / IOC protocol, both processors | §13 |
| add a new kind of drive | storage personality + synthetic DPH | §14 |
| write a driver for new hardware | driver slots, facades, driver tables | §15 |
| make something writable that was not | personality + FS2 + mutation invalidation | §16 |
| add a cache, handle or lease | resource pool + invalidation matrix | §17, Appendix C |
| change USER, CWD or the drive map | personality namespace + every coupled consumer | §18 |
| write or fix a `.COM` utility | CP/M transient conventions under either launcher | §19 |
| make something faster | measure first, then transaction count | §20 |
| write a test for any of the above | the qkz80 harness | §22 |
| find out what CP/M really does | characterization tools, conventional-drive oracle | §23, §28 |
| know what to run before committing | the regression checklist | §32 |

If your change does not fit a row, that is worth noticing before you start: it
usually means either the change spans layers that were deliberately separated,
or it belongs somewhere other than where you first looked.

---

## 0.9 What to read next

- **Part I** is the constitution: what must remain true regardless of how the
  code is arranged. Read it once in full. It is short, and every rule in it was
  paid for.
- **Part II** is the procedures, organized as "I want to change X." Read the one
  section you need, plus §9 if you have not built the system before.
- **Part III** is verification: how to prove both that your change works and
  that you did not quietly redefine CP/M. Read §22 before writing a test and
  §32 before committing.
- **Appendix A** gives the current file names, symbols and addresses for
  everything described above. This part is stable across refactors; Appendix A
  is not, and the generated `docs/memory-map.md` supersedes both for any
  address.
- **`FAT-BRINGUP-LESSONS-LEARNED.md`** is the history: the bugs and experiments
  that produced these rules. Nothing in this document depends on it, but it
  explains why several of the rules are stricter than they look.

---

# Part I — The Architectural Constitution

These are invariants. A contribution may extend them deliberately, but should
not violate them accidentally.

## 1. Extend ZSDOS around its interfaces

Zephyr should extend ZSDOS **around its interfaces**, not gradually turn into a
private fork of ZSDOS.

The preferred layering is:

```text
application
    |
    v
CALL 5 / common facade
    |
    v
bank-7 dispatcher
    |
    +-- Zephyr-specific semantics
    |
    +-- ZSDOS_ENTRY
            |
            v
           BIOS
```

If a change can be implemented at the facade/dispatcher or BIOS boundary,
prefer that to modifying ZSDOS internals.

The FAT-backed drive is the reference example: Zephyr added a fundamentally
different filesystem while leaving ZSDOS authoritative for normal CP/M state.

If an actual ZSDOS source modification becomes necessary, document before
making it:

- what cannot be achieved at the facade, dispatcher, or BIOS boundary;
- why it cannot be achieved there;
- the minimum ZSDOS change required;
- the compatibility consequences.

---

## 2. State has one authority

Do not create a second authoritative copy of CP/M state.

| State | Authority | Zephyr may do |
|---|---|---|
| Current drive | ZSDOS | mirror/cache it |
| USER | ZSDOS function 32 | mirror it |
| Software write protect | ZSDOS | mirror it for intercepted mutations |
| DMA semantics | CP/M/ZSDOS facade contract | stage/copy as required |
| DPH/DPB/ALV | BIOS/ZSDOS-visible model | synthesize where a backend requires |
| FAT relative current directory | Zephyr FAT backend | own it and tag it with its USER |
| IOC/FS2 handles | Zephyr implementation | cache opportunistically |
| Media/context generation | FS2/IOC | mirror and invalidate local state |
| Application bank identity | Zephyr memory model | preserve across crossings/interrupts |

A mirror must be disposable and reconstructible.

If losing a value would break correctness, it should not exist only as a
mirror.

### Current ZSDOS write-protect wrinkle

The present ZSDOS build is configured with the hard read-only behavior enabled
in its flags. Once a drive is software write-protected, the normal reset-disk
paths may deliberately leave that protection asserted until the relevant ZSDOS
flag is changed or the system is cold-booted.

Therefore:

- query ZSDOS directly before blaming a stale FAT-side mirror;
- diagnostics that set software write protection must restore the prior ZSDOS
  state deliberately;
- FAT/native code must never reinterpret software write protection as a FAT
  file attribute.

---

## 3. Bank 7 is implementation space; common memory is ABI space

> **Bank 7 is the normal implementation space for the OS. Common bank-0 memory
> exists for crossing and ABI requirements.**

New OS logic, tables, and persistent implementation state belong in bank 7 by
default.

Common memory is justified only for objects that genuinely must remain visible
while application mapping is active, such as:

- CALL 5 / BDOS facade entry;
- bank-transition helpers;
- interrupt-entry infrastructure;
- caller-visible returned objects;
- staging buffers;
- cross-mode stack/state.

Free common memory is not by itself a reason to place implementation code
there.

The generated memory map and allocator ownership are authoritative. Historical
free ranges are not.

Reclaimable 512-byte arenas remain allocator-owned and must not silently become
permanent module storage.

### The residency test, and the four zones

The list above is examples. The test is one sentence:

> **An object belongs in common memory if and only if its address must resolve
> to the same bytes under more than one latch state.**

Three situations qualify, and nothing else does: the latch is *unknown* (an
interrupt can arrive under any mapping), the latch is *changing* (the code
performing a mode switch must survive it), or the object is written under one
mapping and read under another. "It is convenient" and "there is room" are not on
the list.

Every common region declares which of these applies, as a **zone**:

| Zone | Meaning |
|---|---|
| `abi` | a published address — programs or the other processor see it |
| `crossing` | changes the memory mode, or stages caller objects across it |
| `interrupt` | reached from an ISR, so the latch is unknown |
| `driver-isr` | a driver's ISR-reachable tail, and **only** that |

Bank 7 has its own four: `core` defines a contract, `driver` implements one,
`state` is private data, `asset` is data read at boot. `core` is deliberately
absent from the common set — defining a contract is no reason to be addressable
under two mappings — and `crossing` and `interrupt` are absent from bank 7 for the
mirror reason.

Three rules are enforced on every build, and each exists because it was once
violated silently:

1. **Each common zone occupies exactly one contiguous run.** Placing a routine in
   whatever hole happened to exist is how the interrupt zone came to have islands
   at `FC98h`, `FCE0h` and `FF60h` sitting inside the data region. The build now
   fails and names the zone.
2. **Every region has its own declared ceiling.** Regions used to end wherever
   the next one began, so their slack was the neighbour's leftovers and moved
   when the neighbour moved — growing the V9958 console by eight bytes once
   shifted an unrelated transport shim. An overrun now reports the region and the
   exact byte count.
3. **A file's directory must match the memory it occupies** (§0.3).

Bank 7 is additionally laid out in **512-byte granules**: every base 512-aligned,
every size a multiple of 512. A module grows into its own reserved slack or the
build stops; it never pushes its neighbours along.

`driver-isr` is the strictest zone: it must be exactly one run, because a
driver's ISR-reachable half goes in the common driver slot or it does not go in
common at all. Everything else about a driver belongs in bank 7.

### The facade is an ABI boundary, not a trampoline

Before adding a crossing, answer:

```text
What must remain visible in the caller mapping?
What can remain entirely in bank 7?
Does the caller expect a pointer back?
Can that returned pointer legally refer to bank-7 storage?
Can source and destination aliases occur on real hardware?
```

Normally, application-visible pointers may not refer directly to private
bank-7 objects.

Reuse the existing staging/crossing machinery. Do not invent a new crossing
framework for each subsystem.

### Aliasing is part of the machine model

The test harness must model real address aliasing, not merely function
interfaces.

A concrete current example is:

```text
FAC_DMA_BUF = FAC_BULK_BUF
```

When bank 7 is selected, an application DMA buffer in the TPA disappears and
the facade stages it into common memory. Code that subsequently treats the DMA
staging area and the bulk buffer as independent buffers is wrong on hardware
even if a unit test with two scratch addresses passes.

Any change that introduces a second use of an existing common buffer must be
reviewed for aliasing.

`SELDSK` must validate the drive root, not a USER-relative current directory.
For the current FAT B: personality, availability means that `/CPM/D` can be resolved
and a synthetic DPH can be returned. Replaying `/CPM/D/@N/<cwd>` during
`SELDSK` can make the whole drive disappear merely because a USER-specific
subdirectory was removed or because the probe omitted the USER component.
Path resolution belongs to the intercepted file/native operation after login.

---

## 4. Preserve personalities instead of collapsing them

Zephyr deliberately presents more than one view of the same storage. §0.5
describes the two personalities and where they converge; this section is the
constraint that keeps them apart.

Do not migrate CP/M-shaped semantics below the convergence point, and do not
give the native API CP/M's limits in order to share code with the compatibility
path. Extent arithmetic, directory-slot encoding, the USER-to-`@N` projection
and SEARCH continuation state belong in the CP/M personality and nowhere else.

A native call may still enter through CALL 5. That does **not** make it a CP/M
filesystem operation. Function 218 is a syscall gateway to native Zephyr
semantics.

Resource services belong above the native filesystem API:

```text
RESOURCE_OPEN / READ / SEEK
        |
        v
ZOPEN / ZREAD / ZSEEK
        |
        v
FS2
        |
        v
FatFs
```

The resource layer may add caching, prefetching, decompression, streaming,
symbolic asset lookup, and eviction. It should not become another filesystem.

---

## 5. Synthetic BIOS personalities participate in ZSDOS state

A backend does not need to be a real CP/M block filesystem to participate in
the CP/M disk model.

The FAT-backed personality uses synthetic BIOS behavior so ZSDOS can select and
log the drive normally:

```text
SELDSK  -> validate drive root and return synthetic DPH
READ    -> harmless synthetic empty-disk view
WRITE   -> failure when a real BIOS write is inappropriate
DPB     -> synthetic geometry
ALV     -> synthetic capacity view
```

Real FAT file access happens above this BIOS layer.

This gives two important properties:

1. ZSDOS remains authoritative for current-drive/login bookkeeping.
2. If a FAT-dependent operation accidentally falls through to ordinary ZSDOS
   disk processing, it sees an empty synthetic disk rather than the previously
   selected conventional drive.

### SELDSK tests drive availability, not the current directory

For a FAT personality, SELDSK should validate the configured drive root (for
example `/CPM/D`) and return the synthetic DPH.

It must **not** make drive availability depend on the currently selected USER
subdirectory or relative CWD. A renamed or missing subdirectory is a path
problem, not evidence that the logical drive disappeared.

---

## 6. CP/M-visible state remains reconstructible

### FCBs are authoritative

Applications may copy FCBs.

Therefore an FCB must remain sufficient to reconstruct a CP/M file operation.

Do not hide an IOC/FS2 token inside an FCB or make correctness depend on a
specific controller handle surviving.

IOC handles may be cached by identity, for example:

```text
drive
USER
current-directory generation
packed 8.3 filename
```

but the handle is opportunistic.

If it disappears, becomes stale, or is retired by a namespace mutation, reopen
from authoritative FCB/path state.

Writable operations must acquire appropriate writable state separately. Never
silently reuse a stale or read-only cached token for mutation.

### Explicit-drive operations may temporarily reselect drives

A ZSDOS operation on an explicit C: FCB while B: is current may internally
behave like:

```text
remember B
select C
perform operation
restore B
return
```

An error reported during BDOS READ on C: therefore does not prove the C: read
itself failed. The later restoration of B: may have failed.

When debugging this class of problem, trace actual SELDSK transitions.

### USER and hierarchy are separate layers

The accepted FAT compatibility projection is:

```text
USER 0: /CPM/D/<relative-CWD>/<name>
USER N: /CPM/D/@N/<relative-CWD>/<name>
```

The USER namespace precedes the saved relative CWD.

The current build supports USER 0 through 15. Do not assume 0 through 31 merely
because another CP/M-family system does.

A relative CWD selected under one USER must not silently become the relative CWD
of another USER.

Native path access is not required to apply the CP/M USER projection.

### Teardown precedes policy

> **Every transient exits through WBOOT, and WBOOT finishes tearing it down
> before anything decides what runs next.**

The order is fixed:

```text
transient --RET / BDOS 0 / JP 0000h--> WBOOT --full teardown--> supervisor --> next program
```

It is never `transient → supervisor → cleanup`, and never
`transient → supervisor → next program`. A program may have registered interrupt
callbacks, reprogrammed the CTC, drawn on the V9958, held native handles, or
rewritten page zero. The next program, whichever it is, must start from the
OS-owned state that WBOOT rebuilds, not from what the last one left.

The two halves stay separate:

- **WBOOT owns teardown and holds no policy.** It does not know the next program
  is usually the shell, and it does not restore the CCP slot.
- **The supervisor owns policy and holds no device knowledge.** It never resets
  the CTC, SIO, console or a storage provider. If a new kind of program state
  needs cleaning up, that is a WBOOT step, added before the supervisor call.

The same rule binds future policies. A parent restored after its child exits
comes back *after* the child's interrupt and device state is gone, never instead
of tearing it down.

---

## 7. SEARCH is an observable ABI

Do not reduce SEARCH FIRST/NEXT to "find matching filenames."

Legacy software may observe:

- A = 0..3 selecting a 32-byte DMA slot;
- the selected entry at `DMA + A * 32`;
- USER;
- packed 8.3 name;
- EX/S1/S2/RC;
- attribute high bits where applicable;
- caller-FCB mutation/preservation behavior;
- continuation across SEARCH NEXT;
- end-of-search return behavior.

The FAT personality is allowed to choose a simpler valid representation. The
hardware-accepted implementation currently uses:

```text
DMA[0..127] = E5h
DMA[0..31]  = one synthetic directory entry
A           = 00h
```

and on exhaustion:

```text
A           = FFh
DMA         = unspecified
```

It emits one synthetic entry per FAT file. For a large file the entry carries
the terminal EX/S2/RC representation; function 35 remains the authority for the
complete rounded-up record count. Allocation bytes are synthetic/zero because
there is no physical CP/M allocation layout to expose.

This is intentional restraint: reproduce observable compatibility, not a
fictional CP/M allocator.

### `FCB[0] = '?'` is a real SEARCH mode

For SEARCH, `FCB[0] = 3Fh ('?')` is not an invalid drive number.

On this ZSDOS build it means a raw current-drive search across supported USER
areas.

The FAT dispatcher must preserve that mode across SEARCH NEXT, skip missing
`@N` directories, and return the source USER in each synthetic entry.

This behavior is required by real software such as CRC.

### FAT metadata is not CP/M metadata

Do not project FAT HIDDEN/SYSTEM/ARCHIVE bits into synthetic CP/M directory
attributes.

The semantic models are different and real CP/M software noticed the mismatch.

ZSDOS software write protection remains a separate authority.

---

## 8. Interrupt, transport, and mutation safety are OS contracts

### BIOS/core owns interrupt architecture

Programs register callbacks through Zephyr mechanisms rather than taking
ownership of the I register or rewriting the IM2 vector table.

Drivers may own device-specific handling policy. They do not automatically own
the global interrupt architecture.

### The receive critical section begins at the first RX-ready

The IOC is clock master. Once the first reply byte arrives, the rest of the
reply continues whether the Z80 is ready or not.

The required shape is:

```text
wait for first RX-ready     interrupts enabled
first RX-ready observed
DI
marker recognition
reply body
bulk phase
EI
```

Masking only after marker recognition is too late: a timer interrupt can allow
the SIO FIFO to overflow before the supposedly protected region begins.

A transport failure can surface as a high-level filesystem or ZSDOS error. The
layer reporting the failure is not necessarily the layer that caused it.

### Reads and writes have different recovery rules

Reads are generally safe to reopen/reconstruct and retry once.

Writes may be:

```text
definitely not committed
definitely committed
completion unknown
```

Unknown completion must not be converted into "retry."

For bulk writes:

```text
WRITE reply / READY
    -> IOC has armed receive

IOCBULKW completes
    -> bytes crossed the link

XFER_STATUS / DONE with matching transfer ID
    -> final commit status is known
```

READY and a successful bulk transfer are not proof of commit.

If DONE is lost, malformed, or refers to another transfer, return an
unknown-write outcome and invalidate the writable context.

Writable stale handles do not use the read-side reopen-and-retry policy.

---

# Part II — Subsystem Implementation Protocols

This part is organized by contributor task: "I want to change X; what is the
safe procedure?"

## 9. How to build the OS

Everything in this guide assumes you can produce an image and read what the
build says about it. The build is also the first verification step: most layout
and ABI mistakes are caught by the build itself, not by running the machine.

### Where the build lives

```text
Code/HOST/CPM2.2/          the operating system: BIOS, supervisor, ZCPR2, ZSDOS, tools
  src/
    zephyr.asm             the assembly root: include order and nothing else
    layout/                the address authority: memory.inc, platform.inc, modes.inc
    common/                code that must be mapped under more than one latch state
    core/                  bank 7; defines the contracts
    drivers/               bank 7; implements them -- console/ storage/ transport/
    assets/                font and other read-only data
  zcpr2/ zsdos/            command processor and BDOS sources
  tools/                   image builder, validators, doc generator, harness runners
  tests/                   libqkz80 harnesses
  config/                  payload map and the cpmtools disk definition
  build/                   every generated artifact
  docs/                    generated and hand-written documentation
```

A file's directory states which memory class it belongs to, and the build checks
that claim against the addresses the file actually emits. `common/` must land in
`E000h-FFFFh`; `core/`, `drivers/` and `assets/` must land in bank 7.

All commands below run from `Code/HOST/CPM2.2`.

### Prerequisites

| Needed for | Tool |
|---|---|
| the image | GNU Make, Python 3, SDCC's `sdasz80`, `sdldz80`, `makebin` |
| ZCPR2 and ZSDOS | a host C compiler; the CP/M emulator is vendored in `tools/runcpm` and compiled on first use |
| drive A: contents | the sibling `Utilities` and `Monitor` projects, built automatically |
| ZephyrShell (`CCP=zshell`, the default) | z88dk's `zcc` for `ZSH.COM` and ZephyrC; `sdasz80`/`sdldz80` for the shim. Built automatically from `../ZephyrShell` |
| `make test` | a C++17 compiler and libqkz80 headers/library |

Nothing is resolved from a checkout elsewhere on your disk. The period
assemblers that build ZCPR2 and ZSDOS run under the vendored RunCPM, which is
patched to select `CCP_ZCPR3`; an unmodified upstream RunCPM has never worked
for this build, so do not point `RUNCPM=` at one.

### The ordinary build

```sh
make
```

That produces the default machine: ZephyrShell as the default shell, physical
V9958 console in 85x26 text, ROM drive A:, SD drive B: with the FAT personality
enabled. It ends by printing the configuration it just built, and the name of the
image to flash:

```text
  ROM built:  CCP=zshell  BDOS=zsdos  CONSOLE=v9958  STORAGE_A=rom
    V9958 text: 85x26
    FAT drive: enabled
    build/zephyr80.bin
    build/zephyr80-zshell-zsdos-v9958-rom-85x26.bin   <- flash this one to be sure
```

The stamped copy exists because `build/zephyr80.bin` is the same filename for
every configuration. Verifying one configuration and then flashing "the ROM"
has already shipped the wrong image once. Flash the stamped name.

The stamp covers `CONSOLE` and `STORAGE_A` because at first it did not — it named
only the CCP, the BDOS and the FAT gate, so a `CONSOLE=vdrip` build wrote the same
filename as the default. That is the same failure the stamping was introduced to
prevent, in a dimension it did not cover, and it shipped: a Virtual Drip ROM was
burned and came up on the V9958 console.

### Build-time configuration

| Variable | Values | Meaning |
|---|---|---|
| `CCP` | `zshell` (default), `zcpr2` | what fills the CCP slot as the default shell's loader: the ZephyrShell shim, which loads `A:ZSH.COM`, or ZCPR2 |
| `BDOS` | `zsdos` | fixed. The stock CP/M BDOS cannot run behind the banked OS, and the Makefile refuses anything else |
| `CONSOLE` | `v9958` (default), `vdrip` | which console backend is linked into the console slot |
| `V9958_TEXT_MODE` | `85x26` (default), `128x35` | V9958 text geometry and font; ignored with `CONSOLE=vdrip` |
| `STORAGE_A` | `rom` (default), `vdrip` | which drive A: backend is linked |
| `FAT_DRIVE` | `1` (default), `0` | `0` parks the synthetic FAT drive without moving anything; a recovery build |

`STORAGE_A=vdrip` requires `CONSOLE=vdrip`, because both ride the shared VDrip
transport. `CONSOLE=vdrip` builds and boots; the two consoles draw the same
screen, so the stamped filename is how you tell them apart.

The stamped filename carries every variable: CCP, BDOS, console, A: backend,
`-nofat` for a `FAT_DRIVE=0` build, and the text mode for a V9958 build. Read the
printed summary anyway.

### What the build actually does

```text
Makefile -> build/config.inc     the feature flags, as an assembler header every
                                 translation unit includes

src/zephyr.asm -> firmware.rel   one assembly: layout, common, core, and the
                                 common half of each split driver
src/drivers/**  -> drv_*.rel     each driver is its own translation unit; the
                                 build selects which objects to link, so a
                                 CONSOLE or STORAGE_A choice is a link input
  -> sdldz80 -> firmware.ihx     absolute .org layout, no relocation
                -u               rewrites each .lst as a .rst with resolved
                                 addresses; those are the symbol authority
       check_overlap.py          FAILS on any byte emitted twice
       check_diag_record.py      FAILS if the IOC failure record drifts from
                                 the copy the CP/M tools assemble against
       check_org_placement.py    FAILS if an .org did not land on its constant
  -> makebin -> firmware_flat.bin
  -> split_banked_image.py       cuts the flat space into ROM page 0 (common
                                 memory, reset vector) and the bank 7 payload,
                                 installing the selected CCP image at CBASE and
                                 its pristine copy at CCP_RESTORE_BASE, and
                                 ZSDOS at its org
  -> build_zephyr_image.py       assembles the 512 KiB burnable ROM from page 0,
                                 bank 7 and the ROM-disk chunks; writes
                                 build/layout.manifest and layout-report.md
  -> generate_memory_docs.py     validates every declared region against its
                                 limit and writes docs/memory-map.md and
                                 docs/symbol-map.md
```

Two dependencies are worth knowing because they look like nothing:

- ZSDOS is assembled against `build/firmware.map`. It jumps to `WBTRAP`, the
  common warm-boot trap, by absolute address, and that address moves whenever
  the BIOS is rebuilt. The address is generated, never written down; a stale
  one would assemble cleanly and jump into the middle of something at run time.
- ZCPR2 is assembled against `CBASE` and `CBIOS_BASE` read directly out of the
  firmware sources, so the command processor cannot drift from the layout.
- The ZephyrShell shim is assembled against its own copy of `CBASE` and the CCP
  slot limit, in `ZephyrShell/stubs/ccp.asm`. It calls nothing in the BIOS by
  address, only BDOS through `0005h`, so it does not depend on the symbol map.
  It must still keep both CCP entry jumps, which `split_banked_image.py` checks.
  Unlike ZCPR2's, its `CBASE`, and the `--base 0xe400` in
  `ZephyrShell/Makefile`, are hand copies. Moving `CBASE` means changing them
  too. Nothing fails the build if you forget.

### The ROM disk

`make` rebuilds the sibling `Utilities` and `Monitor` projects every time, and
`ZephyrShell` too when `CCP=zshell`, and takes their binaries for drive A:. That is deliberate: their outputs used to be
picked up as found, so a clean build here could still ship tools compiled
against a different BIOS, and after one branch switch every IOC tool on A:
failed with a transport error.

Shipping a new transient on A: means adding a `MANIFEST` row in
`tools/build_rom_disk.py`, not copying a file anywhere. `ZSH.COM` is the one
conditional entry: the build adds it only for `CCP=zshell`, through
`--zshell-dir`. Staging happens under
`build/`; nothing in the tracked tree is rewritten.

`images/*.cpm` are user-owned volumes. The build never writes them, and neither
should you.

### Reading the result

Primary artifacts:

| Artifact | Meaning |
|---|---|
| `build/zephyr80-<ccp>-<bdos>-<console>-<storage_a>[-nofat][-<text mode>].bin` | the 512 KiB image to flash |
| `build/firmware.bin` | ROM page 0: reset vector and common memory |
| `build/bank7.bin` | bank 7 payload: ZSDOS, the BIOS and drivers |
| `build/firmware.rst`, `build/drv_*.rst` | linker-resolved listings; the symbol authority for the doc generator and the harnesses |
| `build/layout-report.md` | region placement as the image builder saw it |
| `docs/memory-map.md` | generated map, per-region free space, validation report |
| `docs/symbol-map.md` | generated jump tables, IM2 page and symbols |

`docs/memory-map.md` and `docs/symbol-map.md` are generated on every build and
are the address authority afterwards. Prose size comments in sources drift;
these do not. Never hand-edit them.

After a layout-affecting change, read the generated map and confirm:

- every region still ends at or below its limit, and the free-space column is
  what you expected;
- the CP/M BIOS jump table is intact and in order;
- the region you grew did not silently consume the slack another region was
  relying on.

### Building somewhere other than `build/`

`make BUILD_DIR=/somewhere/else` works, and every artifact goes there. Two things
used to not follow, and the failure was silent rather than noisy, so it is worth
knowing what was wrong in case something like it returns.

The ROM image embeds payloads — bank 7 and the ROM-disk pages — listed in
`config/banks.ini`. Those paths were once written literally as `build/bank7.bin`,
which the packer resolves against the working directory. So a build into another
directory linked its *own* bank 7 and then packed the one left in `build/` by some
earlier build of a different configuration. `tools/build_rom_disk.py` had the same
defect in reverse: its chunk output defaulted to `build/`, so an out-of-tree build
overwrote the project's ROM-disk chunks.

The resulting image was internally inconsistent — common memory from one link,
bank 7 from another, two halves of an OS disagreeing about every address — and
nothing said so. It was verified by symbols, burned, and came up running the
other configuration's console. The programmer's verification had proved the right
driver was *linked*; nothing had proved it was in the *image*.

Both are fixed. Payload paths are written `${build_dir}/...` and expanded from an
explicit `--build-dir`; a `${build_dir}` with no `--build-dir` is a hard error
rather than a silent fallback; and a `kind = boot` payload must live in the same
directory as the firmware it boots with, since it comes from the same link. That
last check is structural rather than a measurement, so it cannot go stale.

The general lesson, which applies well beyond the build system: **verify the
artifact, not the process that produced it.**

### What the build refuses to do

The build stops rather than producing a subtly wrong image when:

- two sections emit bytes at the same address (`check_overlap.py` names the
  nearest symbol on each side);
- a declared region runs past its limit;
- the IOC failure record definition and the CP/M tools' mirror of it disagree;
- an unsupported `CONSOLE`, `V9958_TEXT_MODE`, `STORAGE_A`, `FAT_DRIVE`, or
  `CCP`/`BDOS` combination is requested;
- a sibling binary the ROM disk manifest names has not been built.

Do not work around these by moving something else out of the way until you have
read the section on driver slots below.

### Cleaning

```sh
make clean
```

removes `build/` here and cleans the sibling projects too.

### Pairing

The ROM must be paired with memory decoder revision 11 from
`Code/HDL/WinCUPL`. An image built here and flashed onto a machine with an
older decoder will not boot, and the failure looks like a BIOS fault.

---

## 10. General alteration workflow

Before changing OS behavior:

1. **Identify the authority.**  
   Decide which component owns the state or semantic contract.

2. **Choose the lowest safe extension boundary.**  
   Prefer BIOS, facade, dispatcher, or native-service boundaries over ZSDOS
   internals.

3. **Classify memory placement.**  
   Default to bank 7. Justify any new common-memory object.

4. **Characterize observable legacy behavior.**  
   Especially for BDOS, FCB, SEARCH, drive selection, USER, and error behavior.

5. **Keep implementation state reconstructible.**  
   Cached handles and caches must not become hidden ABI.

6. **Make correctness independent of optimization.**

7. **Add focused tests before broad application tests.**

8. **Run conventional-drive regressions as well as the new personality.**

9. **Measure before altering transport or facade architecture.**

10. **Update this guide when the change establishes a new durable rule.**

---

## 11. How to add or intercept a BDOS call

Use the existing common facade and bank-7 dispatcher.

### Step 1 — decide whether interception is necessary

Intercept when the operation's semantics differ for a Zephyr personality.

Do not intercept ZSDOS bookkeeping merely because doing so is convenient.

Examples:

- FAT OPEN/READ/SEARCH: alternate semantics, intercept.
- current-drive selection: ZSDOS already owns it, preserve ZSDOS authority.
- USER: preserve function 32 authority and mirror only as needed.

### Step 2 — define staging requirements

Determine which arguments/pointers live in the application mapping and which
must be staged before entering bank 7.

Do not return bank-7 pointers to applications.

### Step 3 — preserve ZSDOS state transitions

If the operation needs normal ZSDOS pre/post behavior, call through or
post-process rather than emulating the state transition independently.

### Step 4 — preserve the semantic return value

Common crossing code is mechanical. If it uses A/flags/registers to decide
whether to copy data, save and restore the semantic result first.

A real bug in the native gate successfully completed CHDIR, then replaced the
returned status with the operation number while deciding whether a payload
copy was needed.

Test both:

- the returned register/status;
- any status copied into the request/response descriptor.

### Step 5 — verify complete crossing behavior

Do not test only the bank-7 worker. At least one test must exercise the
application -> common facade -> bank 7 -> common facade -> application path.

---

### FAT dispatch classification

For FCB calls, classify the function and FCB drive together:

```text
FCB[0] = 0       current drive
FCB[0] = 1..16   explicit A: through P:
FCB[0] = 3Fh     special raw SEARCH form, function 17 only
```

Ordinary FCB calls are intercepted only when their effective drive is the FAT
personality. Explicit conventional-drive calls must continue into ZSDOS even
while the FAT drive is current. SEARCH NEXT is routed from the saved SEARCH
context because it has no new drive byte to classify.

The current-drive and USER mirrors are maintained after successful ZSDOS calls;
do not query ZSDOS function 32 on every FAT operation merely to refresh a value
that already crossed the dispatcher.

When adding a FAT-side intercepted BDOS function, there are four coupled edits:

```text
1. common/facade.asm flags table
       F_FCB / F_SFCB / F_DMA_IN / F_DMA_OUT as required

2. fat_bdos_dispatch
       route the call
       carry set = handled, A is the BDOS result
       carry clear = continue into ZSDOS

3. fat_bdos_post
       maintain mirrors/invalidation when the call changes drive, USER,
       software write-protect state, or transient context

4. regression harness
       current FAT drive
       explicit FAT drive while another drive is current
       explicit conventional drive while FAT is current
```

The facade flags are easy to overlook: a write function without `F_DMA_IN`
does not receive the caller's record.

A function intentionally unsupported by the personality should fail explicitly
and document why rather than accidentally falling through or returning success.
Function 30 (set attributes) is the current example: FAT attribute projection
was deliberately removed.

## 12. How to add a native Zephyr operation

Function 218 is the current native-filesystem precedent.

### Required properties

- versioned request descriptor;
- byte-oriented semantics;
- caller pointers staged safely across banking;
- no IOC token exposed to applications;
- operation-specific state in bank 7;
- exact result preserved across the common gate.

### Pointer/count validation

Validate lengths before any `LDIR`.

On Z80:

```text
BC = 0
LDIR
```

copies 65536 bytes, not zero bytes.

Reject or skip zero-length transfers before `LDIR`, and reject lengths above
the supported staging size before changing memory mode.

Apply the same rule to lengths computed internally. A computed zero count is
just as dangerous as a caller-supplied zero.

### Flags are not durable state

Any `CP`, `OR`, `AND`, arithmetic operation, etc. changes condition flags.

Do not:

```text
call worker
cp SOME_SPECIAL_STATUS
...
jp nz,return_worker_result
```

and assume NZ still describes the worker's result.

Store/retest the semantic status explicitly.

### Spend the descriptor before growing the gate

The function-218 descriptor is fixed at 32 bytes and the common native gate is
already tightly budgeted. Prefer designs that reuse operation-specific fields
the operation does not otherwise need, or return large logical results one
element at a time.

Examples of useful patterns:

- a rename can reuse fields that have no meaning for rename to carry the second
  packed name;
- a multi-component result such as the current directory can take an index and
  return one component plus the total count per call.

Native resource acquisition needs a native release operation.  Function 218
originally exposed OPENDIR/READDIR while FS2's existing CLOSEDIR primitive had
no application crossing, which made a well-formed C iterator impossible.
CLOSEDIR is therefore append-only version-1 operation 20.  It reuses HANDLE,
does not change any existing operation number or descriptor offset, and must
retire the single native directory context even after READDIR returned END.

Use the existing crossing helper rather than adding another common stub.

When an operation is answerable entirely from bank-7 state, state that fact in
its contract and test that it generates **zero controller traffic**. This keeps
future refactors from quietly turning a memory lookup into an IOC round trip.

### Namespace providers

Function 218 is a namespace, not one filesystem. `native_vfs_entry`
(`drivers/storage/native_vfs.inc`) routes each call:

- **namespace operations** (open, stat, chdir, opendir and the rest) go by the
  path the call names, relative to the current directory;
- **handle operations** (read, write, seek, close, readdir and the rest) go by
  handle value. Handle `80h` belongs to the `/SYSTEM/A` provider; every other
  handle belongs to FS2.

`/SYSTEM/A` (`drivers/storage/cpm_mount.asm`) is the precedent for adding a
provider:

- **Own a distinct handle range.** A handle must say which provider issued it,
  without a lookup the other provider could disturb.
- **Never call the BDOS.** The provider runs inside a function-218 call, so a
  recursive `CALL 5` would re-enter the facade. `/SYSTEM/A` reads A:'s CP/M
  directory and extents itself, through the drive-A: backend.
- **Declare the warm-boot reset policy.** WBOOT's FAT context reset ends by
  tail-calling `cpm_mount_reset`. A new provider chains its reset onto that path
  and states what survives. The writable FS2 current directory is preserved;
  `/SYSTEM/A`'s handle, iterator and current directory are discarded.
- **Read-only means refusing mutation with `FS2_STATUS_READ_ONLY`**, not
  falling through to the root provider.
- **Executables need nothing special.** The BDOS 219 loader consumes an
  already-open handle through the router, so a program on any provider launches
  through the same loader (§21).

### Native operations need native tests

Adding a native operation means adding a direct bank-7 harness case in the same
change.

FCB-path tests do not substitute for native API coverage even when both
personalities reach the same file.

---

## 13. How to extend FS2 or the IOC protocol

Protocol growth is additive.

### Checklist

When adding a command:

1. define the command/frame fields;
2. add dispatcher handling;
3. add external-sync/admission handling;
4. add capability advertisement;
5. move the IOC firmware level where required;
6. update host-side expected levels/capabilities;
7. add an end-to-end diagnostic;
8. test against firmware that lacks the capability.

Do not rely only on a firmware version when a capability bit can answer the
actual question.

A controller that silently does not admit a command can look like a hung
transport. Capability probing makes "unsupported" distinguishable from
"transport dead."

### Reuse the proven bulk lane

For new 512-byte-class transfers, prefer the existing bulk mechanism unless a
measured requirement proves it insufficient.

Writable FS2 reused the established receive-buffer + commit callback + DONE
lifecycle rather than inventing another transport.

### Firmware level and capability are both part of a protocol addition

For the current IOC tree, a command addition is not complete after editing only
the frame definition and dispatcher. Review all of:

```text
ioc_frame.h
dispatch.c
external_sync.c / command admission
IOC firmware level
host-side ioc_levels.inc mirror
FS2 capability bits
```

A controller that does not admit a command may drop the frame rather than
returning "unsupported", which looks like a transport hang. Capability
negotiation should therefore precede use of optional commands.

### Generation semantics

Generation covers media/context invalidation that can occur while the Z80 keeps
running.

An MCU reset resets the whole machine. Do not invent a recoverable MCU-session
nonce for host-side state that cannot survive such a reset in reality.

---

## 14. How to add or change a storage personality

A storage personality must separate three concerns:

```text
drive availability/login
filesystem/path resolution
actual data operations
```

### Step 1 — participate in SELDSK

Provide the synthetic DPH/DPB/ALV behavior required for ZSDOS to maintain
normal current-drive state.

### Step 2 — keep SELDSK narrow

SELDSK validates the logical drive/root, not a USER-specific CWD or a particular
file path.

### Step 3 — define the compatibility projection

Specify:

- drive root;
- USER mapping;
- relative-CWD mapping;
- FCB naming/filtering rules;
- SEARCH representation;
- synthetic free-space/geometry behavior.

### Step 4 — intercept only personality-specific file semantics

Preserve ZSDOS ownership of drive/USER/write-protect bookkeeping.

### Step 5 — keep destructive tools backend-oriented

A provisioning/destructive utility that addresses a physical backend directly
should name the backend, not a drive letter that can be reassigned in one
constant.

"Erase the SD backend" is stable. "Erase drive B:" may become dangerously
false after a drive-map change.

---

## 15. How to add a driver for new hardware

This section is written for the case of a builder who has made a new card — a
video card is the running example — and wants a BIOS driver for it.

### The slot idea, and what it is really worth

Driver code lives in fixed slots rather than being packed end to end. The slots
trade a little internal slack for a stable map: a driver can grow without
forcing every later driver to slide upward into a card castle, and the addresses
in a listing mean the same thing across builds.

The slack is the point. When your driver grows, the slack is what pays for it,
and when the slack runs out the build tells you which symbol you collided with.

### Where the slots actually are

The declarations are in the "Fixed Driver Slots" block of `src/layout/memory.inc`.
Read that block, not this list, before placing anything — but read this first,
because the declarations alone will mislead you:

Bank 7 is laid out in **512-byte granules**: every module's base is 512-aligned
and every module's size is a multiple of 512. Each has reserved slack of its
own, so it can grow without pushing its neighbours along -- which is what this
layout used to do, and what the per-module ceilings now prevent.

There is one console driver slot, and it is in bank 7:

| Slot | Base | Size | Occupant |
|---|---|---|---|
| Console driver | `CBIOS_DRIVER_SLOT0_BASE` = `9000h`, bank 7 | 4096 | the linked console driver; V9958 uses 3191, Virtual Drip 3309 |
| Common driver slot | `CBIOS_COMMON_DRIVER_SLOT_BASE` = `F850h`, common | 432 | the linked console driver's **ISR-reachable half only** |

The old slots 1-5 are gone. They were declared at `E400h`, `E800h`, `EC00h`,
`F000h` and `F680h` in common, and every one of those addresses had come to hold
something else -- the CCP, the BDOS facade, the BIOS tables, the interrupt
dispatcher. Nothing referenced them, so the constants were deleted rather than
corrected. If you meet that table in an older copy of this guide or an older
comment in `src/layout/memory.inc`, this is what it was describing.

So the statement for a new card is simple: **your driver goes in bank 7, at
`9000h`, and it may use 4096 bytes.** If its receive path must run from an
interrupt, that part -- and only that part -- goes in the common driver slot,
which is 432 bytes and has 14 free in a Virtual Drip build. Everything else
about a driver belongs in bank 7.

`docs/memory-map.md` prints the live numbers after every build, free bytes per
module included; use those, not these.

### Bank 7 by default; common memory only if you must

Common memory is 8 KiB, and every byte you move there comes out of every
program's address space. Only three kinds of thing belong there:

- interrupt handlers and everything they touch;
- code that changes the memory mode, and the stacks it runs on;
- buffers that carry a program's data across the mapping.

A video driver is none of these. Its parser, renderer, font handling, cursor
state and port sequences all belong in bank 7. If you believe you need a byte in
common memory, say which of the three cases it is.

### Adding a console backend, step by step

The console facade in `src/core/console.asm` keeps the CP/M entry points stable
and dispatches through a driver table. Adding a backend means supplying that
table and being selectable at build time.

**1. Write `src/drivers/console/<name>.asm`.**

It is its own translation unit, so it carries its own headers, and its areas are
namespaced to it. That last point is not decorative: asxxxx concatenates
same-named areas across objects, so a second unit's `CODE` starts after the
first unit's and the `.org` that follows becomes relative instead of absolute.
`check_org_placement.py` catches it, but the convention avoids it:

```asm
	.module <name>_console

	.area CODE (ABS)
	.org CBIOS_DRIVER_SLOT0_BASE

<NAME>_CONSOLE_CODE_START:
	; ... table, entry points, state ...
<NAME>_CONSOLE_CODE_END:
```

**2. Publish the driver table.** Seven 16-bit little-endian entries, in this
order, at the head of the driver:

```text
+00 const   -> A = FFh if input is available, A = 00h otherwise
+02 conin   -> blocking input, character returned in A
+04 conout  -> blocking output of the character in C
+06 list    -> list/printer output of C, or a no-op
+08 punch   -> punch output of C, or a no-op
+0A reader  -> reader input, A = character or CP/M EOF
+0C listst  -> A = FFh if the list device is ready, A = 00h otherwise
```

The order is the contract. An unimplemented device is a `ret`, not a missing
entry.

**3. Provide the neutral backend aliases.** The rest of the BIOS calls the
selected backend by neutral name, so alias your own labels to them:

| Alias | Called by | Purpose |
|---|---|---|
| `console_backend_driver` | `console_init` | your driver table |
| `console_backend_cold_init` | cold boot | first-time hardware bring-up |
| `console_backend_init` | `console_init`, warm boot | re-init preserving owned state |
| `console_backend_send_frame` | `VIDEO_SEND` | one raw video request, payload ≤ 16 bytes |
| `console_backend_data_write_block` | `VIDEO_SEND` | the block-data video request |
| `console_backend_reset_display` | `VIDEO_SEND` with A = 00h or FFh | reinitialize the display |

Cold init and warm init usually differ only in whether they establish or
preserve driver-owned hardware shadow state. Warm boot reinitializes the console
after a transient has taken over the display, so warm init must be able to
rebuild the screen from driver state alone.

**4. Wire it into the build.** Four places, all of which the build will catch if
you miss them:

- `Makefile`: add the name to `VALID_CONSOLES`. Nothing rewrites your source --
  `DRIVER_REL_CONSOLE` resolves to `build/drv_console_$(CONSOLE).rel`, so the
  file must be `src/drivers/console/<name>.asm` and the build links your object
  instead of someone else's.
- `tools/generate_memory_docs.py`: add a `CONSOLE_REGIONS` entry naming your
  `_CODE_START` and `_CODE_END` symbols, the limit they must stay below, the
  `zone` (`driver`) and the `source` file. Without this your driver is
  unvalidated and undocumented, and the source check cannot vouch for it.
- `tools/build_zephyr_image.py`: add the name to the `--console` choices; it is
  recorded in the layout manifest and the report.
- `src/layout/memory.inc`: add a code base *and its own limit* if your driver
  needs a region of its own. Give it a ceiling rather than letting it end where
  the next region begins -- reserved slack is the whole point, and a region
  bounded by its neighbour loses it the moment the neighbour moves.

**5. Build, then read the map.**

```sh
make CONSOLE=<name>
```

Then open `docs/memory-map.md` and confirm your region appears, starts where you
declared, ends below its limit, and left the free space you expected.

### Rules your driver has to keep

These come from the console path contract, and violating them produces faults
that are expensive to find on hardware:

- **Input and output are separate concerns.** `CONST` reports availability,
  `CONIN` returns one byte, `CONOUT` emits one byte. A keyboard or packet
  handler must never draw characters, move the cursor or scroll the display. An
  echo test may do `CONIN -> CONOUT`; that is a harness behavior, not a shortcut
  inside the driver.
- **Do not expect `BC` to survive.** The facade preserves `DE` and `HL` around
  the indirect call but not `BC` — the packed facade region has no free bytes to
  save it. Callers must not hold a live value in `BC` across a console BIOS
  call, and your backend may clobber it.
- **You run on the console stack.** Dispatch switches to a private console stack
  in the BIOS stack reserve and restores the caller's stack on return. Do not
  assume the caller's stack depth, and do not switch stacks yourself.
- **Never call `CALL 5` from bank 7**, and never call BDOS from an interrupt
  handler. The facade is not reentrant.
- **Keep interrupt work small.** No large redraws from an ISR, no expensive
  parsing there, no waiting for transmit completion with interrupts disabled. A
  receive sink should enqueue the byte, update flow control, and return.
- **`E000h-E3FFh` belongs to the running program.** The operating system, your
  driver included, must not use it.
- **Document each public entry point** with its inputs, outputs, clobbered
  registers, whether it may block, and whether it is ISR-safe. The existing
  drivers do this and the headers are part of the design documentation.

### Known debt: the video contract speaks Virtual Drip

If you are writing a video driver, read this before you design its interface.

`VIDEO_SEND` — BDOS function 215 — is how a transient borrows the display from
the console driver. It dispatches to `console_backend_send_frame`,
`console_backend_data_write_block` and `console_backend_reset_display`, so it is
the seam every display backend sits on. Its vocabulary, however, is a serial
transport's:

- `A` is a **Virtual Drip packet type**, and callers hardcode the protocol's
  codes (`01h` VDP_CTRL_WRITE, `0Bh` VDP_DATA_BLOCK, `13h` PALETTE_WRITE);
- every type except `0Bh` is capped at `VIDEO_SINGLE_PAYLOAD_MAX = 0x10`, which
  the source itself calls "the historical 16-byte limit" — a frame size, not a
  property of any video chip.

**Partly fixed.** The contract now speaks device operations, declared in
`src/core/video_ops.inc`:

```text
VIDEO_OP_CTRL_WRITE   VIDEO_OP_DATA_WRITE    VIDEO_OP_DATA_BLOCK
VIDEO_OP_PALETTE_WRITE VIDEO_OP_INDIRECT_WRITE
VIDEO_OP_RESET        VIDEO_OP_PRESENT
```

Implement those. The byte values behind them are still the Virtual Drip packet
numbers, and they are frozen, because BDOS function 215 takes that byte and
programs are compiled against it. But the values are now an ABI detail of one
header rather than a vocabulary every driver has to learn: nothing in a backend
names a packet any more, and the V9958 driver no longer carries its own copy of
the numbering.

What remains is the payload ceiling. `VIDEO_SINGLE_PAYLOAD_MAX = 0x10` is a
Virtual Drip single-frame size, enforced in `VIDEO_SEND` above the contract, and
it applies even to a chip on your own board that could take more. Making it
something a backend declares is a behaviour change and has not been done.

Function 215 itself is frozen — compiled programs use it. Only the internal
backend contract changes.

### If you are building the device-independent layer

Zephyr has the GIOS half of a GSX-style graphics architecture and none of the
GDOS half:

```text
GDOS   device-independent: primitives, coordinate transforms, clipping,
       workstation capability model                            -- does not exist
GIOS   device-dependent transport to the selected backend      -- VIDEO_SEND
```

That is why `mandelbrot_v9958.asm` writes VDP registers and computes VRAM
addresses itself: the backend is swappable, but the application is not portable
across backends, because nothing device-independent sits above the transport.

If that layer gets built, it is **core** — it defines a contract, has one
implementation, and lives in bank 7 — while each device remains a **driver** in
a slot. The existing entity rules cover it without extension. Budget for it
deliberately: a primitives-and-transforms layer is plausibly comparable in size
to the FAT personality, which is a real claim on bank 7's driver headroom.

Two cautions:

- **Do not claim BDOS function 115 early.** 115 is GSX's documented entry, and
  it carries an expectation: `DE` points at a parameter block of
  `contrl`/`intin`/`ptsin`/`intout`/`ptsout` arrays. Answering 115 with a
  different convention gives a real GSX program silent garbage instead of a
  clean rejection, which is a worse outcome than not claiming it. Nothing in
  this tree uses 115 today, so it stays available; being GSX-*shaped* at a
  Zephyr function number costs nothing and hazards nothing.
- **Earn it with a characterization test.** The claim to honour is "an
  unmodified GSX application produces correct output," not "the opcodes look
  similar." Characterize before emulating, as elsewhere in this guide. Moving
  the entry to 115 afterwards is one comparison in the facade; un-claiming it
  after programs depend on it is not.

### Storage and other backends

The same shape applies elsewhere. `src/core/storage.asm` owns the storage
facade and the drive dispatcher routes A: to its build-selected backend; exactly
one A: backend links per build, and they all `.org` at
`CBIOS_STORAGE_A_CODE_BASE` and export the neutral `stg_a_*` entry points. A new
storage backend is a new `src/drivers/storage/<name>.asm`, a new `STORAGE_A`
value, and a new region entry — the same four wiring points.

For anything that is not console or storage, prefer a private driver table
behind an existing facade over a new publicly visible entry point.

### If it does not fit

Report the conflict; do not make room by eviction.

State the exact ranges and sizes: what you need, what is there, and by how many
bytes you are over. The `CONSOLE=vdrip` case in the Makefile is the model for
this — 654 bytes of transport against a hole that no longer exists, written down
as arithmetic with the addresses named, and left failing deliberately pending a
decision. That is a better outcome than a build that fits because something else
was quietly removed.

Specifically, do not resolve a shortage by disabling a working subsystem,
reordering the BIOS jump table, reusing an existing jump-table entry for new
semantics, or moving a CP/M-visible entry point. If new BIOS calls are genuinely
needed, append them after the existing entries.

---

## 16. How to implement writable behavior

Writable support should be brought up in semantic layers.

### Stage A — native writable filesystem

First validate:

```text
FS2 create/open-for-update/write/truncate/sync/close
    -> native function 218 API
    -> hardware validation
```

This isolates dangerous transport/commit behavior from CP/M FCB mutation rules.

### Stage B — CP/M writable personality

Only after native mutation is proven should the FCB personality add:

- MAKE;
- sequential write;
- random write;
- random write with zero fill;
- DELETE;
- RENAME;
- close/flush semantics;
- lazy USER-directory creation where applicable.

### Write protection

Check both:

- physical/filesystem read-only state;
- ZSDOS software write-protect state.

A previously opened writable context must not bypass newly asserted protection.

### Mutation invalidation

Namespace mutations and policy changes must retire incompatible cached state.

At minimum review invalidation for:

- CREATE / create-always;
- DELETE;
- RENAME;
- CHDIR/CWD generation change;
- USER change;
- media generation change;
- software write-protect assertion/reset;
- explicit FS2 context reset.

### Unknown completion

Never blindly replay a mutation whose commit outcome is unknown.

The application may need to reopen/re-stat and decide what recovery is safe.

---

## 17. How to manage caches, leases, and scarce handles

Correctness must not depend on caches.

If a cache lease cannot be obtained, use a slower path.

### Reclaimable memory

A reclaimable 512-byte line belongs to the allocator until leased. Do not turn
it into permanent FAT/backend state.

State read before initialization must be initialized explicitly. In assembler,
`.ds` reserves bytes; it does not guarantee they contain zero.

A resource pool whose uninitialized owner table happens to look "fully owned"
can silently disable an optimization forever while the correct fallback path
hides the defect.

A refused lease and a failed operation are different events:

```text
no lease available      -> use the slower proven path
lease held, work failed -> propagate the error
```

Do not fall back through a second implementation after a real operation failed;
that silently retries faults and can be dangerous for mutation.

For resources whose refusal is treated as permanent for the boot/session, ask
once and remember the result rather than paying allocation overhead on every
operation.

### Cached FS2 read handle

A cached FCB-side read handle is a lease against a pool used by other clients.

Rules:

- at most the intended number of opportunistic slots may remain held;
- native opens/mutations may force the opportunistic read handle to be closed;
- namespace mutation may retire controller-side handles underneath the cache;
- `NO_HANDLE`/`STALE` on a read may reopen once and retry once;
- a second failure is a real error;
- clear the local cache tag before/best-effort close so a failed close cannot
  leave false ownership;
- writable operations never reuse the cached read token.

If the controller exposes only a tiny handle pool, treat opportunistic
performance handles as lower priority than explicit native/application
handles.

### Cache invalidation is an explicit catalogue

For the FAT read cache, review invalidation whenever adding one of these classes
of operation:

```text
FCB writes, MAKE, DELETE, RENAME, random-write zero fill
native write, truncate, delete, rename, mkdir, rmdir
writable native OPEN / create-always
CHDIR, USER change, drive change, disk reset, context reset
media generation change
```

Invalidate generously. The compatibility cache exists for speed, not as an
authority.

Keep two operations conceptually separate:

- **drop cached memory/tag** — no external resource needs releasing;
- **release cached controller handle** — consumes a scarce IOC slot and should
  be closed/retired when another caller may need it.

The cache refill path may need to drop the line without releasing the open
handle; mutation paths generally need both.

A useful regression is write-then-read of the same file through the
compatibility path. Removing any required invalidation hook should make that
test return stale data and fail.

### Performance precedent

The FAT read path improved most by reducing setup round trips, not by inventing
larger transfers.

For a measured 64 KiB sequential read, the compatibility path fell from
hundreds of setup/transfer transactions to roughly one mailbox plus one bulk
operation per 512-byte line after deblocking and cached-handle reuse.

The practical lesson is:

> Count transactions before widening transfers or redesigning the transport.

---

## 18. How to manage USER, CWD, and drive mappings

For the current FAT personality:

```text
USER 0: /CPM/D/<relative-CWD>/<name>
USER N: /CPM/D/@N/<relative-CWD>/<name>
```

### Rules

- USER is owned by ZSDOS.
- FAT maintains only the mirror/state required to avoid re-querying on every
  file operation.
- USER change invalidates SEARCH state and any identity whose namespace changed.
- A relative CWD is associated with the USER that selected it.
- SELDSK verifies the drive root, not the USER/CWD path.
- native filesystem operations decide explicitly whether they apply the CP/M
  USER projection.

### Recovery and parent traversal

An empty native CHDIR component is the recovery operation that selects the
target USER root. Perform that reset before replaying a saved relative CWD so a
directory removed externally cannot prevent recovery to the namespace root.

Parent-directory syntax (`..`) needs an explicit containment policy. A
one-level test that happens to return to the USER root does not prove arbitrary
depth normalization or prove that traversal cannot escape the projected USER
root.

### Changing the drive-letter map

Drive letters are configuration and appear in more places than one constant.
Review, at minimum:

```text
1. layout/memory.inc
       SD_STORAGE_DRIVE / SD_STORAGE_DRIVE2 / SD_STORAGE_DRIVE_LIMIT
       FAT_BIOS_DRIVE

2. storage/FAT dispatch arithmetic
       derive unit numbers from the constants; do not hardcode DEC/offsets

3. FAT resolver root convention
       decide whether the on-card root name moves with the CP/M letter

4. utilities
       one-based FCB drive numbers
       write-protect vector bits
       function-37 vector bits

5. tests
       drive numbers, vector bits, resolver expectations

6. user-visible help/error text
```

The current configuration maps the FAT personality to B: while its historical
on-card root remains `/CPM/D`. That is legal because the root component is a
filesystem convention, not the ABI drive number, but a future remap should
state deliberately whether the on-card directory is renamed too.

Utilities with compiled-in drive assumptions are a coupled release with the
ROM/BIOS that changes the map.

### Fixed-width component formatting

For packed fields, test the first value that changes width and the maximum
accepted value.

For USER directories that means at least:

```text
@9
@10
@15
```

and the byte immediately after the packed component.

A single off-by-one in an 11-byte component can corrupt unrelated persistent
state and make later path replay fail far from the formatter.

---
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

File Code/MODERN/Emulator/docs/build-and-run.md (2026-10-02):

# Zephyr-80 MAME — Build & Run

The Zephyr-80 machine is an out-of-tree MAME **subtarget** called `pbitz`. All
custom sources live under `src/mame/pbitz/`; the machine is **not** registered in
`mame.lst` (the `zephyr` token there is the unrelated `zms8085.cpp`). It is listed
in `src/mame/pbitz/pbitz.lst` and built via its own subtarget script
`scripts/target/mame/pbitz.lua`.

All commands below run from the MAME tree root:

    cd Zephyr-80/Code/MODERN/Emulator/mame

## Build

Debug binary (recommended during bring-up — enables the `-debug` debugger and Lua
taps):

    make SUBTARGET=pbitz DEBUG=1 -j$(nproc)      # -> ./mamepbitzd

Optimised binary:

    make SUBTARGET=pbitz -j$(nproc)              # -> ./mamepbitz

### When to add `REGENIE=1`

The GENIE-generated makefiles under `build/` are only regenerated when you ask for
it. Add `REGENIE=1` **whenever a project file changes**, i.e. after editing
`scripts/target/mame/pbitz.lua` (for example, adding a new device source such as
`z80ctc.cpp`). Editing only `.cpp`/`.h` under `src/mame/pbitz/` does **not** need it.

    make SUBTARGET=pbitz DEBUG=1 REGENIE=1 -j$(nproc)

### Devices are listed explicitly

`pbitz.lua` does not pull the full MAME device set. Each device the driver uses is
named directly in its `files{}` block (`z80sio.cpp`, `z80ctc.cpp`, the `rs232`
bus, `pty`, `loopback`, …) plus `CPUS["Z80"]` and `MACHINES["Z80DAISY"]`. **If you
reference a new device, add its `.cpp`/`.h` to `files{}` and rebuild with
`REGENIE=1`**, or you will get an undefined `DEVICE_TYPE` link error.

### Gotcha: stale absolute paths after a directory rename

The generated files under `build/` bake **absolute** paths (e.g. the forced-include
`src/osd/sdl/sdlprefix.h`). If the tree is moved or renamed, the OSD/SDL layer fails
to compile with:

    fatal error: /…/<old-path>/…/sdlprefix.h: No such file or directory

Fix by regenerating the project files at the current location:

    make SUBTARGET=pbitz DEBUG=1 REGENIE=1 -j$(nproc)

or, to avoid a large rebuild, patch the stale paths in place (this tree was renamed
from `Z80HomeBrew` to `Zephyr-80`):

    grep -rlI Z80HomeBrew build | xargs sed -i 's#Z80HomeBrew#Zephyr-80#g'

### Common failure: "I rebuilt but nothing changed"

The debug binary is `mamepbitzd`; the release binary is `mamepbitz`. Confirm you
launched the one you just built (check its timestamp with `ls -l mamepbitzd`). A
stale binary is the most common source of "my fix didn't take effect".

## ROM

`ROM_START(zephyr80)` loads `roms/zephyr80/zephyr80.bin` — the current 128 KiB
CP/M firmware — into a 512 KiB ROM region. The hash in the driver pins the current
dump; if you rebuild the firmware, MAME prints a non-fatal `WRONG CHECKSUMS`
warning until the `CRC(...) SHA1(...)` line in `zephyr80.cpp` is updated. The
machine still runs with the warning.

## Run

The CP/M console and the Virtual Drip (VDrip) video/storage link share **SIO0/B**
at a fixed **115200 8N1**. Expose it as a host pseudo-terminal for the VDrip proxy:

    ./mamepbitzd zephyr80 -sio0b_rs232 pty -video none -sound none

At startup MAME prints the allocated device:

    :sio0b_rs232:pty: pseudo terminal slave /dev/pts/N

Point the VDrip proxy at that `/dev/pts/N` (open it in **raw** mode — the link is
binary, not line-oriented). Keep the default throttle (do not add `-nothrottle`) so
the serial link runs in real time. `-video none -sound none` runs headless.

`-listslots zephyr80` shows the serial ports:

- `sio0a_rs232` — user serial channel (SIO0/A), baud from the CTC.
- `sio0b_rs232` — console + VDrip link (SIO0/B), fixed 115200.

### Debugging aids

- `-debug` opens the interactive debugger (debug build only).
- `-autoboot_script foo.lua -autoboot_delay 0` runs a Lua script at start — handy
  for I/O taps, e.g. `space:install_write_tap()` on the bank latch (`$00`) or the
  SIO ports (`$20-$23`) to trace boot/console behaviour.

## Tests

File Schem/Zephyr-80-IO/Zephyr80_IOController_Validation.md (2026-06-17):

# Zephyr-80 IO Controller — Schematic Validation (net-trace)

Fresh validation of the current KiCad schematics, traced pin-by-pin from the S-expressions. Same status legend/format as the platform's other card reviews.

> **Correction note (supersedes my first pass):** an earlier draft of this review claimed SIO1 was absent. That was a **tooling miss** on my side — the IC3 placement carries a `(lib_name "Z80SIO_1")` line ahead of its `(lib_id)`, which my instance parser didn't accept, so IC3 was dropped from the netlist. Fixed. **IC3 (SIO1) is present and the SDLC link is fully wired.** Everything below reflects the corrected trace (pin-endpoint coincidence 295/316 = 93%).

---

## Board under review

| Field | Value |
|---|---|
| Board | Zephyr-80 IO Controller (`Zephyr-80-IO`) |
| Sheets | root · IO Controller · Baud Clock · Device Select Decode · Console Port · GPIOs and User Serial · pBITz Bus Interface |
| Serial ICs | **IC2 = Z80 SIO0 (async)** · **IC3 = Z80 SIO1 (sync/SDLC)** · IC1 = Z80 CTC · U15 = PIC18F57Q84 · U1 = 74AHCT125 (SPI mux) · U7 = FT230XS · U14 = MAX202 · U8 = 74HC4040 · Y1 = 14.7456 MHz |
| Method | Calibrated S-expression net trace; 295/316 pin-endpoint hits, misses confirmed as unused pins |
| Review date | 2026-06-16 |
| Net result | **✅ schematic PASS** — SIO1/PIC SDLC link, SIO0 console, and SIO0 user-serial all wired correctly. Remaining items are firmware-side (§4,5,7,8); no hard schematic blockers. |

**Legend:** ✅ pass · ❌ fail · ⚠️ verify / open · ➖ n/a · 🔧 polish
**Confidence:** schematic connectivity **high** (direct trace); runtime **medium** (no firmware/PPS/SIO register init supplied).

---

## 0. Findings (the lens)

| ID | Finding | Status |
|---|---|---|
| A | **SIO1 SDLC link is correctly wired** end-to-end (PIC SPI ↔ IC3 via U1 mux). No gross connectivity fault. | ✅ |
| B | **All three of your corrections are present and verified** (§1). | ✅ |
| C | **SIO0 console (FT230) and user-serial (MAX202/RS-232) both wired correctly** — TX/RX & RTS/CTS crossover on the root sheet, connector-perspective net naming. Console proven; RS-232 untested but correct. | ✅ |
| D | **Remaining risk is firmware + one HW budget item**: PPS mapping, `/SYNC` as input, CS mutual-exclusion, buffered-clock idle/sequencing, SDLC bit-order parity, and the MAX202 driver/receiver count. | ⚠️ |

---

## 1. Your three corrections — verified

| # | Correction | Status | Evidence |
|---|---|---|---|
| 1.1 | Clock-sheet typos fixed | ✅ | Baud Clock outputs now `CLK_7M3728 / CLK_3M6864 / CLK_1M8432` (14.7456 ÷ 2/4/8), matching IO Controller inputs. |
| 1.2 | SIO0 DCD pulled low | ✅ | `IC2.19 (DCDA)→R32→GND`, `IC2.22 (DCDB)→R31→GND`. |
| 1.3 | SIO1 DCD & CTS → MCU, pulled low | ✅ | `CTSA→RB0 +R39↓`, `DCDA→RB4 +R34↓`, `DCDB→RE0 +R33↓`, `CTSB→RB5 +R41↓` — each to a PIC GPIO **and** a pull-down to GND. Exactly as described. |

## 2. SIO1 (IC3) — sync/SDLC link to the PIC  ✅

The "firmware-SDLC over SPI, two virtual targets" architecture is wired correctly. IC3 is on the Z80 bus (register access) with its serial side driven by the PIC through the U1 (74AHCT125) mux.

| Signal | Path (traced) | Status |
|---|---|---|
| PIC→SIO1 data | `SIO_MOSI` (RB1) → **IC3 RXDA (12) + RXDB (28)** (multidrop) | ✅ |
| SIO1→PIC data | `IC3 TXDA (15) → SIOA_TX → U1(2A/2Y, OE=~SIOA_CS)`; `IC3 TXDB (26) → SIOB_TX → U1(3A/3Y, OE=~SIOB_CS)` → shared `SIO_MISO` (RB2), R36 100k pull-up | ✅ |
| Bit clock | `SIO_SCK` (RB3) → `U1(1A/4A)` → `SIOA_SCK` (→ IC3 RXCA/TXCA) and `SIOB_SCK` (→ IC3 RXTXCB), gated by CS, R37/R38 100k pull-ups | ✅ |
| Channel select | `~SIOA_CS` (RA5) → U1 4OE+2OE; `~SIOB_CS` (RA4) → U1 1OE+3OE | ✅ |
| /SYNC sense | `IC3 SYNCA (11) → ~SYNCA → RA6`; `IC3 SYNCB (29) → ~SYNCB → RA7` (point-to-point, no contention) | ✅ |
| Per-channel attention | `IC3 RTSA (17) → ~SIO1A_INT → RF1`; `IC3 RTSB (24) → ~SIO1B_INT → RF0` (+pull-ups). SIO **RTS used as a ready/attention line to the PIC** — distinct from the Z80-side `INT`. | ✅ note |
| Modem inputs | `CTSA/DCDA/CTSB/DCDB` → PIC GPIO + pull-downs (correction 1.3) | ✅ |
| Bus | `CE←~CE_SIO1`, `C/D←A0`, `B/A←A1`, `RD←~RD`, `IORQ←~IORQ`, `M1←~M1`, `CLK←CLK_10M`, `RESET←~RESET`, `INT→~INT`, `W/RDYA·B→~WAIT` | ✅ |

Channel A and channel B map to your two SDLC ports ("bulk" / "commands") — the mux/CS scheme keeps them independently selectable. The earlier external review was correct on this connectivity (MOSI→RXDA+RXDB, TXDA/TXDB→125 buffers→MISO, RTS→PIC); credit to it.

## 3. SIO0 (IC2) — async console + user serial

| # | Check | Status | Notes |
|---|---|---|---|
| 3.1 | Ch B = Console / FT230 | ✅ | `RXDB/TXDB/RTSB/CTSB ↔ CONS_UART_*`; clock `RXTXCB ← CLK_1M8432` (÷16 = 115200). DCDB low. Proven-good reference. |
| 3.2 | Ch A = User serial / MAX202 | ⚠️ | `RXDA/TXDA/RTSA/CTSA ↔ USR_UART_*`; clock `RXCA/TXCA ← CTC TO0`. DCDA low. Symmetric with the working channel; untested — see §11 for the transceiver budget. |
| 3.3 | Bus / interrupt | ✅ | Shares decode + IM2 chain with IC1/IC3 (see §9). |

## 4. PIC ports / PPS / SPI separation

| # | Check | Status | Notes |
|---|---|---|---|
| 4.1 | Two SPI domains separate | ✅ | SIO-side RB1/RB2/RB3; IO/mezzanine RC5/RC4/RC3. No shared pins, no ICSP (RB6/RB7) conflict. |
| 4.2 | "Wrong port" history | ⚠️ firmware | Pins are PPS-valid and conflict-free in the schematic. Confirm `SPIxSCK/SDI PPS` + output `RxyPPS` target exactly RB1/2/3 and RC3/4/5, and `ANSELx` cleared on all SDLC-link pins. |

## 5. /SYNC direction

| # | Check | Status | Notes |
|---|---|---|---|
| 5.1 | No contention | ✅ | `~SYNCA/~SYNCB` point-to-point IC3→RA6/RA7. |
| 5.2 | Direction | ⚠️ firmware | SIO drives /SYNC as an **output** in SDLC/internal-sync, so **RA6/RA7 must be TRIS inputs**. Driving them from the PIC recreates the original contention. |

## 6. Auto-enable / modem control  ✅

| # | Check | Status | Notes |
|---|---|---|---|
| 6.1 | SIO1 CTS/DCD defined | ✅ | All four pulled low + MCU-driven (1.3). Auto-Enables won't silently gate the link; if firmware also wants flow control it can drive these. |
| 6.2 | SIO0 | ✅ | DCD low; CTS = real FT230/MAX202 handshake. |

## 7. Buffered SIO1 clock — idle-state / sequencing

| # | Check | Status | Notes |
|---|---|---|---|
| 7.1 | Gated-clock park level | ⚠️ firmware | `SIOA_SCK/SIOB_SCK` are 74AHCT125 outputs with 100k pull-ups → an unselected channel parks **high**. Idle `SIO_SCK` **high** and assert CS *before* shifting, so enabling the buffer injects no high→low edge ahead of bit 0. The SIO sync receiver has no start-bit recovery, so a stray enable edge can shift a bit boundary. |

## 8. Mux discipline (firmware)

| # | Check | Status | Notes |
|---|---|---|---|
| 8.1 | CS mutual exclusion | ⚠️ firmware | `~SIOA_CS` and `~SIOB_CS` are independent PIC pins. Never assert both: that would enable both TX buffers onto `SIO_MISO` (contention) and both clocks. Enforce one-hot in firmware. |
| 8.2 | Return-data float | ✅ | When neither CS active, `SIO_MISO` is held by R36; SIO TXD idles mark/high anyway. |

## 9. Interrupts / daisy chain

| # | Check | Status | Notes |
|---|---|---|---|
| 9.1 | Shared INT | ✅ | `~INT` = IC1+IC2+IC3 INT (open-drain wired-OR to Z80). |
| 9.2 | IM2 chain order | ✅ | `[bus IEI] → CTC(IC1) → SIO0(IC2) → SIO1(IC3) → [bus IEO]`. /M1 present. Note SIO1 is **lowest priority** — fine functionally; reconsider only if VDrip latency ever competes with console IRQs. |

## 10. Clock / baud / decode

| # | Check | Status | Notes |
|---|---|---|---|
| 10.1 | Osc + divider | ✅ | 14.7456 MHz → 74HC4040 → 7.3728/3.6864/1.8432 MHz, names correct. |
| 10.2 | Decode | ✅ | 4× 74HC688 + coded switches → `~CE_CTC/~CE_SIO0/~CE_SIO1/~CE_CTRL`; all four now land on their targets (IC1/IC2/IC3/'138). |

## 11. Backplane / transceivers

| # | Check | Status | Notes |
|---|---|---|---|
| 11.1 | Backplane SPI | ✅ | J1 carries the IO-side SPI (`IO_MOSI/IOI_MISO/SPI_CLK/SPI_CS0/1/SPI_CD/~SPI_INT`). SIO1's SDLC link is intentionally **local** (PIC bridges it), not on the bus. |
| 11.2 | FT230X console | ✅ | Single-supply USB-UART; proven path. |
| 11.3 | MAX202 channel budget | ✅ | MAX202 = **2 drivers + 2 receivers** (4 channels, 8 signal pins). TX + RTS use the two drivers; RX + CTS use the two receivers — all four lines fit. |
| 11.4 | MAX202 / console TTL-side direction | ✅ | The TX↔RX and RTS↔CTS crossover is done on the **root sheet** (sheet-pin wiring), with the transceiver-side nets named from the **RS-232/connector perspective**. Resolved through the root: SIO `TXDA → DIN2(10)`, SIO `RXDA ← ROUT2(9)`, SIO `RTSA → DIN1(11)`, SIO `CTSA ← ROUT1(12)` — every SIO output to a driver input, every SIO input from a receiver output. **Correct.** The console (FT230) path uses the same pattern (`CONS_UART_TX↔CONSOLE_RX`, etc.). *(An earlier draft flagged a swap; that was a cross-sheet trace artifact on my side — sheet pins connect via root wiring, not by name — not a board fault.)* |

---

## Reconciliation with the external report

With IC3 correctly in the netlist, the external report's SIO1 connectivity claims **match the trace**: `SIO_MOSI → IC3 RXDA + RXDB`; `TXDA/TXDB → 74AHCT125 → SIO_MISO`; `SIOA_SCK/SIOB_SCK` gated with 100k pull-ups; `~SIO1A/B_INT` on RTSA/RTSB; point-to-point `/SYNC` on RA6/RA7. Its firmware-risk list (PPS, `/SYNC` TRIS, Auto-Enables, clock-idle discipline, bit order) is valid and is folded into §4–§8. The one place it's now out of date: it flagged SIO1 CTS/DCD as **unstrapped** — your correction 1.3 fixes exactly that, so that trap is closed.

Net: the report's architectural read was right. My first-pass "SIO1 absent" was a parser defect, not a board defect.

---

### Sources

- **Z80 SIO** — no internal BRG (external TxC/RxC); WR4 x1 for sync/SDLC; **/SYNC is an output in SDLC/internal-sync, input only in external-sync**; Auto-Enables (WR3 D5) gate Tx on /CTS, Rx on /DCD; RTS is a WR5-controlled GP output; IEI/IEO IM2 chain via /M1·/IORQ. *Zilog Z80 SIO Technical Manual (UM0081). Confidence: high.*
- **SDLC bit order** — LSB-first on the wire vs MSB-first default SPI; firmware-SDLC parity (flag 0x7E, CRC-CCITT, NRZ/NRZI) must match the SIO config. *ISO 13239 / Zilog SIO manual + Microchip MSSP shift order. Confidence: high.*
- **PIC18F57Q84** — dual PPS-routable SPI; ANSEL/TRIS/ODCON/INLVL per-pin; no native HDLC. *Microchip DS40002213. Confidence: high.*
- **74AHCT125** — independent 3-state buffers; OE low ⇒ A→Y, OE high ⇒ Hi-Z. *TI SN74AHCT125 datasheet. Confidence: high.*
- **FT230X / MAX202 / ECS-2100AX (14.7456 MHz) / 74HC4040** — vendor datasheets. *Confidence: high.* MAX202 = 2 drivers + 2 receivers + charge-pump caps.

> Stable reference docs — not web-searched this pass. Ask for live datasheet revision dates if needed.

### Reproducibility

Calibrated KiCad S-expression net tracer: union-find over wire endpoints + on-segment taps + same-name local/hierarchical label merge; instance parser now tolerates `(lib_name …)` before `(lib_id …)`; transform auto-calibrated; 295/316 pin-endpoint hits. Re-run per sheet as `python3 trace.py IO_Controller.kicad_sch <REFS…>`. Script available on request.

---

## Revision log

| Rev | Date | Reviewer | Result | Key notes |
|---|---|---|---|---|
| net-trace 1 | 2026-06-16 | Claude | (withdrawn) | Erroneously reported SIO1 absent — parser dropped IC3 (`lib_name` before `lib_id`). |
| net-trace 2 | 2026-06-16 | Claude | ✅ conditional PASS | IC3/SIO1 fully traced. SDLC link correct; all 3 corrections verified. Open items are firmware (PPS, /SYNC TRIS, CS one-hot, clock idle/sequencing, bit order) + MAX202 channel budget. |
| net-trace 3 | 2026-06-16 | Claude | ❌ on RS-232 | MAX202 budget was a non-issue (2 drv + 2 rcv handles all 4 lines). But TTL-side appears **direction-swapped** (§11.4) — likely root cause of the untested RS-232 channel. SIO1/SIO0-console unaffected. |
| net-trace 4 | 2026-06-16 | Claude | ✅ schematic PASS | **Retracted the §11.4 swap.** The UART TX↔RX / RTS↔CTS crossover is intentional and done on the **root sheet** (verified for both `USR_UART_*` and `CONS_UART_*`); transceiver-side nets are named from the RS-232 perspective. RS-232 wiring is correct. No hard schematic blockers; remaining items firmware-side. *Lesson: sheet pins connect through parent wiring, not by name — per-sheet traces must resolve cross-sheet nets via the root, which the earlier passes did not.* |

> **Firmware bring-up shortlist:** (1) PPS → RB1/2/3 + RC3/4/5, ANSEL cleared; (2) RA6/RA7 inputs; (3) one-hot CS; (4) SIO_SCK idles high, CS before shift; (5) SDLC bit order/flag/CRC parity; (6) Auto-Enables off until proven.

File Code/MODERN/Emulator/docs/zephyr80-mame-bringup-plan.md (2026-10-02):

# Zephyr-80 — MAME Bring-Up Plan

*Working spec, distilled from design discussion. Intended as input to a code-tree
gap analysis. Nothing here is external fact unless cited in §10.*

---

## 0. How to use this document

Hand this to Claude Code alongside the MAME source tree. Ask it to:

1. **Inventory** what exists against each numbered item below.
2. **Classify** each as **Present / Partial / Missing**, citing the file(s) and
   class/method names it found.
3. **Flag deviations** from the design invariants in §6 (these are the load-bearing
   rules; a violation is worth calling out even if code "works").
4. **Report open dependencies**: which blocking inputs (§8) and verification items
   (§9) are still unresolved in the code.
5. Output a short **"where we are"** summary + a suggested next-step ordering.

The device architecture (§5) is the part most likely to be under-built or built
differently — spend analysis effort there.

---

## 1. Approach & rationale

- **Tool: MAME.** Chosen for (a) device reuse across the Coffee Series lineup —
  every planned CPU has a core — and (b) mature, accurate stock devices (especially
  the V9958) so that CP/M video code stabilized against the emulator is trustworthy
  for the real silicon. Fidelity of the emulated peripheral is the point, not a
  side benefit.
- **Behavior-only, not cycle-accurate.** Stock devices give accuracy for free;
  "behavioral" applies only to custom glue (the IO controller / bridge). We are not
  chasing cycle exactness.
- **Everything is a MAME `device_t`.** "Driver" in MAME = the top-level machine
  definition (the whole Zephyr-80). Our custom parts are *devices*, not drivers.

---

## 2. Target environment (MAME 0.289, docs dated 2026-07-01 — verify current)

- Systems live in per-manufacturer/system folders under `src/mame/<group>/`
  (the old flat `drivers/ machine/ video/ audio/` split is gone).
- Drivers registered in `src/mame/mame.lst` via `@source:` directives.
- Build a subset with e.g.
  `make SUBTARGET=zephyr SOURCES=src/mame/<group>/zephyr80.cpp REGENIE=1`.
- **Check:** confirm the folder chosen for these files and that it's wired into
  `mame.lst`.

---

## 3. Milestones (staging)

| ID | Scope | Unblocks |
|----|---|---|
| **M1** | Z80 + 512 KiB banking + CTC + one SIO channel exposed to host serial | CP/M over serial console; **video + storage via existing host VDrip tooling** — a fully usable dev platform with *no* video/sound chip emulated |
| **M2** | V9958 (stock `v9958_device`) | Migrate video from VDrip-over-serial to native emulated card; stabilize the real V9958 CP/M driver |
| **M3** | 4× SN76489 (verify `SN76489A` variant) + AD7801 DAC | PETSCII Robots audio, GameOS sound |
| **M4** | Native IO controller device (two-layer, §5) replacing the host-side VDrip endpoint: storage + HID + command/bulk channels | Self-contained machine; no external host tooling required |

**Key M1 insight:** because the BIOS ships video (and dev-time storage) as VDrip
packets over the serial link to a host-side TMS9918 emulator + VNC, exposing one SIO
channel to the host lets the **unmodified BIOS VDrip driver** run. M1 alone is a
usable machine. M4 later replaces that host endpoint with an in-MAME device.

The M1 host-serial console path and the M4 native IO-controller device attach to the
*same kind of SIO port* but are different things — don't conflate them.

---

## 4. M1 detail

### 4.1 CPU + memory
- `Z80(config, m_maincpu, XTAL)`; `set_addrmap(AS_PROGRAM, &mem_map)` and
  `(AS_IO, &io_map)`.
- **512 KiB banking.** Target is the existing banked model (512 KiB / 8 banks /
  16 KiB common area, `LAUNCH` cross-bank primitive). Implement with a
  `memory_view` for the boot-ROM → all-RAM overlay plus `memory_bank` entries for
  the paged windows; the bank-register write handler decodes from the CPU-board PLD.
- `memory_view` vs `address_map_bank_device` is decided by the reset-overlay logic.
- **Blocked on** the CPU-board address-decode PLD + bank-register PLD (§8). CUPL
  product terms map almost 1:1 onto address-map ranges + the bank write handler.

### 4.2 Serial console to host
- Attach an `rs232_port_device` to the console SIO channel in the machine config.
- At runtime: `-<port> null_modem -bitb socket.127.0.0.1:1234` (TCP, for the VDrip
  host tool), or `-<port> pty` (pseudo-terminal on *nix), or `-bitb file.txt`
  (capture). `null_modem` does behavioral stream↔baud with RTS flow control by
  default; baud set in Machine Configuration.
- *Confidence: high on the mechanism; medium that VDrip runs unmodified — loosen
  the driver if it assumes tight handshake/flow-control timing.*

### 4.3 CTC + SIO + interrupts
- `Z80CTC` + two `Z80SIO`.
- **IM2 daisy chain:** a `z80_daisy_config` array listing CTC + SIOs in hardware
  priority order; `m_maincpu->set_daisy_config(...)`.
- CTC channel outputs → SIO baud inputs (`zc_callback` → `rxca_w`/`txca_w`). The
  CTC-owned sim/music tick is another `zc_callback` routed to an interrupt.
- **Blocked on** IO-controller decode PLD (SIO/CTC port addresses) + the interrupt
  topology / daisy priority order (§8).

---

## 5. IO controller device architecture (two layers)

This is the native endpoint (M4) but its interface should be designed now. It is
**not** an RX660 emulation — see §7. It is a command-protocol endpoint; the RX660 is
an implementation note.

### 5.1 Layer 1 — Core device (stable, shared)
- Owns the **command interpreter** (a byte-fed packet parser) and its downstream
  devices, instantiated as children via `device_add_mconfig()`: storage
  (`harddisk_image_device` or a `generic_slot` block device) and HID.
- **Two channels, each a method-pair — not one tagged stream.** Only the command
  channel carries an interrupt (unsolicited traffic):

  **Command channel**
  - down: `command_w(u8)`, `command_can_accept()`
  - up: `out_command_irq` (a `devcb_write_line`) + `command_r()` pull

  **Bulk channel**
  - down: `bulk_w(u8)`, `bulk_can_accept()`
  - up: `out_bulk_ready` (a plain line, **no IRQ**) + `bulk_r()` pull

- The core sees two ports only. It never learns "which channel/which chip" —
  demux stays in the glue.
- **Personalities** (derived from a shared base holding ingest/FIFO/status/handshake):
  - IO-controller personality → storage/HID effects
  - VDP personality → framebuffer/register effects
  - Lean toward **two derived devices** over one mode-flagged device (effect
    backends are completely different).

### 5.2 Layer 2 — Glue device (variable, one per transport)
- Where framing / deframing / sync-hunt / handshake with the stock glue chip happens.
- **Owns its core as a subdevice** (a composite, e.g. `coffee_io_sio` news up the
  core + the SIO adapter) and binds the core's `out_command_irq` in its own
  `device_add_mconfig()`.
- **Downstream (glue → core): direct method calls**, not devcb (fixed parent→child
  ownership makes devcb unnecessary ceremony).
- **SIO variant (Zephyr-80):** implements `device_serial_interface`; wires to a
  `z80sio` channel exactly like a `null_modem` endpoint (SIO `out_txd` → glue rx;
  glue tx → SIO `rxd`); deframes; calls the core.
- **VIA variant (future machines):** port/handshake handlers wired to `via6522`
  callbacks; latches a byte on the active CA2/CB1 edge; same downstream calls.

### 5.3 The seam contract (core ⇄ glue)
- **Direction asymmetry is deliberate:** downstream = direct calls; upstream =
  abstract devcb (`out_command_irq`, `out_bulk_ready`). The core must never know the
  glue's concrete type; the dependency points glue → core only.
- **Return path is pull-on-signal, not push.** The core signals "I have data"
  (command IRQ line / bulk ready line); the glue **pulls** with `command_r()` /
  `bulk_r()` at its own transport pace. The core never pushes — it stays ignorant of
  baud rate / handshake timing.
- **Interrupt realization is the glue's job.** `out_command_irq` binds to the
  **glue, never to the CPU** — the core never touches the daisy chain. Flow: core
  asserts `out_command_irq` → glue pulls response bytes → glue injects them into the
  SIO's receive path → the SIO raises its own RX interrupt through the daisy chain
  already wired in §4.3. On a VIA machine the same core IRQ instead drives a
  CA1/CB1 edge / the VIA's interrupt.

### 5.4 Framing split (critical)
- **Transport framing** (SIO sync bytes / hunt mode; VIA handshake edges) → **glue**.
- **Command framing** (opcodes / args / length / checksum) → **core**. Stable.
- Bytes crossing the seam are payload, in order, transport framing already stripped.
- **Decision: in-band command framing** (length-prefix or in-payload delimiter),
  **not** the SIO's out-of-band sync/hunt as a delimiter. The VIA machines have no
  sync/hunt equivalent, so out-of-band framing would force every glue to synthesize
  one. In-band keeps the core parser truly transport-agnostic and every glue dumb.

---

## 6. Design invariants (flag any deviation)

1. Core is transport-agnostic; it never references a glue/chip concrete type.
2. Dependency direction is glue → core only.
3. Downstream = direct calls; upstream = devcb lines. No pushing bytes from core.
4. `out_command_irq` binds to glue, not CPU. Core never touches the daisy chain.
5. Command framing lives in the core; transport framing lives in the glue.
6. Framing is in-band (transport-neutral), not SIO-sync-derived.
7. Command and bulk are separate method-pairs; only command has an IRQ.
8. RX660 internals (instruction set, on-chip peripherals, firmware algorithms) are
   **out of scope** for the device — only the boundary contract is modeled.

---

## 7. RX660 stance (scope boundary)

- MAME has **no Renesas RX core** (its Renesas coverage is H8/H8S and SuperH).
  Do not emulate the RX660 as a CPU.
- The IO controller is a **command-protocol endpoint** ("a thing on the far end of
  the SIO that processes commands"). Model only: ingress packet format, egress
  effects (storage r/w, HID injection, serial passthrough; framebuffer effects on
  the VDP side), and host-synchronized state (FIFO full/empty, busy/ready, ping-pong
  ownership on the VDP side, ack handshake).
- Test RX660 **firmware** separately (Renesas e² studio RXv3 ISS, or real silicon via
  E2/E2 Lite). RX660 is an RXv3 part; QEMU's RX target is RX62N/RXv1 with RX62N
  peripherals, so it does not model this MCU.
- Later payoff: the behavioral core can act as a **conformance oracle** — run the
  same command stream through it and the real firmware, diff the framebuffer/IO
  effects.

---

## 8. Blocking inputs still needed (from Sebastien)

- **CPU-board address-decode PLD** + **bank-register PLD** → `mem_map`/`io_map` +
  banking decode.
- **IO-controller decode PLD** → SIO/CTC port addresses.
- **Interrupt topology / daisy priority order** (and where the V9958 VBlank IRQ lands
  — needed at M2).
- **Command/bulk packet format spec** (the protocol at the connector) → the core's
  packet parser and opcode table.

Claude Code: report which of these are already encoded (as constants, address maps,
or comments) in the tree vs. still absent.

---

## 9. Open verification items (confirm against MAME source, not memory)

- **`z80sio` external-sync framing:** how much sync framing the device exposes vs.
  what the glue must reassemble. *(medium confidence)*
- **`z80sio` receive-injection API:** the exact call the glue uses to present an
  unsolicited byte as received RX data upstream. *(medium confidence)*
- **`SN76489A` vs `SN76489`** variant class name (M3) — noise/clock divider differs.
- Later machines: confirm `arm920t` core presence (Pacamara-920) and `hd63484`
  device (Nitro-30 VDP) class names.

---

## 10. Immediate next code artifact (skeleton)

Draft, as the M1/M4 stand-in:

- **Core device**: the four method-pairs from §5.1 (`command_w`/`command_can_accept`
  + `out_command_irq` + `command_r`; `bulk_w`/`bulk_can_accept` + `out_bulk_ready` +
  `bulk_r`), a byte-fed packet-parser stub, and storage/HID child stubs.
- **Abstract transport-adapter seam.**
- **`coffee_io_sio` glue**: owns the core, implements `device_serial_interface`,
  wires to a `z80sio` channel, binds `out_command_irq`, injects RX for the upstream
  path.
- **`via6522` glue stub**: so the seam is exercised by two transports from day one.
- **v0 behavior**: ACK everything + model "FIFO not full" + the sync/ack handshake so
  the driver runs without deadlocking — unblocks GameOS / CP/M dev before opcodes are
  filled in.

---

## Sources

- MAME 0.289 build/subtarget + source layout (docs dated 2026-07-01):
  <https://docs.mamedev.org/initialsetup/compilingmame.html>
- Host serial (null_modem / bitbanger socket + pty, RTS flow-control default):
  <https://blog.thestateofme.com/2022/05/25/attaching-a-terminal-emulator-to-a-mame-serial-port/>;
  <https://wahki.mameau.com/index.php?title=Guides:MAME_-_driver_-_apple2p>
- No RX core in MAME (CPU tree = H8/SH/6809/etc.), viewed 2026-07-08:
  <https://github.com/mamedev/mame/tree/master/src/devices/cpu>
- QEMU RX target = RX62N/RXv1: <https://www.qemu.org/docs/master/system/target-rx.html>
- RXv3 = RX66x generation, E2 debug support:
  <https://www.renesas.com/en/software-tool/e2-emulator-rte0t00020kce00000r>

*Confidence: high on §2 layout, §7 (no RX core), host-serial mechanism; medium on
VDrip-unmodified and the two `z80sio` items in §9; banking geometry is from the
hardware design and pinned exactly only once the PLDs (§8) are in hand.*

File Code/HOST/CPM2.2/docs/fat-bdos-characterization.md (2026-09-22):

# FAT BDOS Characterization Record

This record is the compatibility gate before the FAT-backed BDOS personality
is implemented. `BDOSCHAR.COM` observes ZSDOS through `CALL 5`; it does not
infer directory behavior from third-party application source.

## Utility

Source: `../../Utilities/src/bdoschar.asm`

Build artifact: `../../Utilities/build/bdoschar.com`

Usage:

```text
BDOSCHAR [d:]pattern [d:]output.txt
BDOSCHAR [d:]SETUP
```

Search mode does not change matched files. It replaces the exact output file
named by the second argument, uses a clean 36-byte private search FCB and a
private 128-byte DMA buffer, restores the default DMA at `0080h`, and limits a
search to 64 successful results. Before every SEARCH call it fills DMA with
`A5h`. `SETUP` is separate and deliberately replaces only the reserved fixture
names listed below.

Put wildcard-search reports on another drive so the growing report cannot
become a search result:

```text
BDOSCHAR B:*.* C:BCHAR00.TXT
```

The report is written as sequential 128-byte CP/M records and its final record
is padded with `1Ah`.

## Generated fixtures

The fixture manifest is generated by
`../../Utilities/tools/generate_bdoschar_fixtures.py`. The checked-in generated
table is `../../Utilities/src/bdoschar_fixtures.inc`; `make` verifies that it
has not drifted from the generator.

Copy the current `BDOSCHAR.COM` to a writable conventional drive, then create
the controlled files on the drive under test:

```text
BDOSCHAR B:SETUP
```

`SETUP` creates all files through the running BDOS:

- one exact-name file;
- five `BDWILD??.DAT` matches, without assuming directory adjacency;
- `BDEMPTY.DAT` by MAKE followed directly by CLOSE;
- `BRnnnnnn.DAT` files containing 1, 2, 3, 4, 127, 128, 129, 255, 256 and 257
  sequential 128-byte records;
- four attribute fixtures, with R/O, SYS, ARC and all three set through BDOS
  function 30;
- `BUCOMMON.DAT` in USER 0, 1 and 15, switching through BDOS function 32 and
  restoring the caller's USER afterward.

This ZSDOS system supports USER 0 through 15. The generator rejects fixture
USER numbers outside that range.

The Python generator owns names, USER numbers, record counts and attribute
flags. It emits metadata only; it does not edit a CP/M image or bypass ZSDOS.
Regenerate after changing the manifest with:

```text
make generate-bdoschar-fixtures
```

It also generates `../../Utilities/src/bdoschar.sub`. With `BDOSCHAR.COM` and
`BDOSCHAR.SUB` on B:, reports on C:, and `SUBMIT` available, run the complete
matrix from USER 0 with:

```text
SUBMIT BDOSCHAR
```

The generated submit file performs both default-drive and explicit-drive
searches, exhausts every wildcard search, repeats `BUCOMMON.DAT` under USER 0,
1 and 15, and ends in USER 0. USER-specific reports are written to the same
USER on C:. Every invocation includes the changed-caller-FCB phase.
Generator options `--program-drive`, `--fixture-drive`, and `--output-drive`
can produce a different mapping.

RunCPM was used to verify fixture creation, sequential record sizes, searches,
and report-file output. Its host-directory BDOS does not expose function-30
attributes. The target-ZSDOS capture below validates those attribute bits and
the generated SUBMIT sequence.

Each result is emitted as hexadecimal records:

```text
CALL=SF INDEX=00 A=00
FCB=<36 bytes>
DMA=<128 bytes>
SLOT=00 DATA=<32 bytes>
```

`SLOT` appears only when returned `A` is `00h` through `03h`. The second phase
fills the caller's original search FCB with `CCh` after SEARCH FIRST and then
calls SEARCH NEXT. This directly tests whether continuation depends on the
caller preserving that FCB.

## Controlled fixture matrix

Capture the complete output for each applicable row on a conventional
ZSDOS-backed drive:

| Case | Fixture / invocation | Evidence sought |
|---|---|---|
| Exact name | `BDOSCHAR B:BDEXACT.DAT C:BCHAR01.TXT` | return slot and exact entry fields |
| Wildcard | `BDOSCHAR B:BDWILD??.DAT C:BCHAR02.TXT` | packed eleven-byte `?` matching |
| Multiple matches | the five generated `BDWILD??.DAT` files | slot `0..3`, sector reuse, SEARCH NEXT order without assuming physical adjacency |
| End of search | any finite pattern | failing return and untouched/changed DMA bytes |
| Empty file | `BDOSCHAR B:BDEMPTY.DAT C:BCHAR03.TXT` | EX/S1/S2/RC and allocation bytes after MAKE/CLOSE with no write |
| Extent sizes | `BDOSCHAR B:BR??????.DAT C:BCHAR04.TXT` | EX/S2/RC progression by sequential record count |
| Attributes | `BDOSCHAR B:BAATTR?.DAT C:BCHAR05.TXT` | high attribute bits set through function 30 |
| USER | repeat `BDOSCHAR B:BUCOMMON.DAT C:BCHARUxx.TXT` in generated USER 0, 1 and 15 | directory-entry user byte and isolation |
| Default drive | from B:, `BDOSCHAR BDEXACT.DAT C:BCHAR06.TXT` | FCB drive zero behavior |
| Explicit drive | `BDOSCHAR B:BDEXACT.DAT C:BCHAR07.TXT` | explicit drive behavior |
| Changed caller FCB | automatic second phase | SEARCH NEXT dependence on the original FCB |

Wildcard-drive coverage is intentionally omitted; it has no current
compatibility requirement.

Directory entry byte offsets used when interpreting `DATA` are:

| Offset | Meaning |
|---:|---|
| 0 | USER |
| 1-8 | filename and attribute high bits |
| 9-11 | extension and attribute high bits |
| 12 | EX |
| 13 | S1 |
| 14 | S2 |
| 15 | RC |
| 16-31 | allocation block bytes |

## Captured result

The target-ZSDOS reports are stored verbatim under
[`characterization/zsdos-bdos-search`](characterization/zsdos-bdos-search/).
The capture identifies drive B as `01h` and covers USER 0, 1 and 15. The exact
ZSDOS build identity was not recorded with the reports.

The reports establish this SEARCH FIRST / SEARCH NEXT behavior:

- Success returns `A=00h` through `03h`. The value selects one of four 32-byte
  directory entries in the 128-byte DMA sector.
- ZSDOS writes the whole physical directory sector to DMA. Entries other than
  the returned slot may be unrelated, deleted, or owned by another USER.
- End of search returns `A=FFh`. DMA is not preserved: despite being filled
  with `A5h` before the call, it contains the final directory sector scanned.
- SEARCH FIRST changes caller FCB byte 13 (S1) to `80h | USER`; it leaves the
  caller's drive and packed name intact. SEARCH NEXT leaves that value in
  place.
- SEARCH NEXT state is internal to ZSDOS. Overwriting all 36 bytes of the
  caller FCB with `CCh` after SEARCH FIRST does not alter the next returned
  match. `BCWILD.TXT` demonstrates this with a second successful result.
- Default-drive and explicit-drive FCBs return the same directory entry. The
  default FCB retains drive byte zero; the explicit FCB retains drive byte two.
- USER filtering selects only the current USER's matching entry even when DMA
  also contains entries belonging to other users.

The attribute reports encode R/O, SYS and ARC in the high bits of extension
bytes 9, 10 and 11 respectively. The combined fixture has all three high bits
set. The empty file reports `EX=00h`, `S1=00h`, `S2=00h`, and `RC=00h`.

The record-count fixtures produce these directory extent fields; S1 and S2
are zero in every selected entry:

| File records | Returned `(EX, RC)` entries |
|---:|---|
| 1, 2, 3, 4 | `(00h, 01h)`, `(00h, 02h)`, `(00h, 03h)`, `(00h, 04h)` |
| 127 | `(00h, 7Fh)` |
| 128 | `(00h, 80h)` |
| 129 | `(01h, 01h)` |
| 255 | `(01h, 7Fh)` |
| 256 | `(01h, 80h)` |
| 257 | `(01h, 80h)`, then `(02h, 01h)` |

The 257-record file therefore returns two matching directory entries. The
allocation bytes contain conventional-disk block numbers and have no FAT
meaning.

The FAT-backed facade will use this synthetic SEARCH contract:

```text
on match:
    DMA[0..127] = E5h
    DMA[0..31]  = synthetic directory entry
    A           = 00h

on exhaustion:
    A           = FFh
    DMA         = unspecified
```

The selected entry contains only the required USER, seven-bit-clean packed 8.3
name, EX, S1, S2 and RC fields. FAT attributes are not mapped into CP/M name
high bits. Bytes 16 through 31, the allocation fields, are zero. The other
three DMA slots have no meaningful entries. The FAT personality returns one
entry per file whose `EX`, `S2`, and `RC` describe its terminal logical extent;
function 35 supplies the complete record count. This retains the size metadata
used by catalogue tools without inventing multiple physical CP/M extents, which
caused directory programs to display a large FAT file repeatedly.

For SEARCH FIRST with FCB drive byte `3Fh` (`'?'`), the FAT personality follows
the CP/M raw-directory convention. It searches the current drive across USER 0
through 15, continues across USER namespaces through SEARCH NEXT, and returns
the source USER in each synthetic entry. Missing `@N` directories are empty.

The raw end-of-search sectors contain a `BUCOMMON.DAT` entry with user byte
`1Fh`. This was created by the earlier fixture generator passing 31 to BDOS
function 32. USER 31 is not supported by this ZSDOS system, so that entry is
an invalid test artifact and is excluded from the compatibility contract.

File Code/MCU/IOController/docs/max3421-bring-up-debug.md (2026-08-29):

# MAX3421E Bring-Up: Debug Log

Date opened: 2026-08-28
Status: **RESOLVED THROUGH HID REPORTS.** The MAX3421E link is clean, the FE1.1
hub and keyboard enumerate, and boot-keyboard reports continuously reach the
IOC application callback.  See the level-61 result for the final report-path
fault and its exact submission/completion accounting.

A running record of what was tried against "the MAX3421E will not come up", what
each attempt ruled in or out, and what is still open. Append to it; do not prune
the ruled-out section, because its whole value is stopping the same ground being
covered twice.

## Level 62: HID reports become terminal input

The first post-bring-up input layer is now implemented, but still awaits a run
on the machine.  It deliberately stops before BIOS integration:

```text
TinyUSB boot-keyboard report
  -> new-key transition detector
  -> US-keyboard / control / VT100 translation
  -> 128-byte IOC HID input queue
  -> CMD_HID_INPUT (0Eh)
  -> HIDKEY.COM test program
  -> existing CP/M console output
```

The translator lives entirely in `src/ioc_hid.c`; storage, the SD cache, the
bulk lane and BIOS `CONST`/`CONIN` are unchanged.  Printable US keys, Shift,
Caps Lock, Ctrl combinations, keypad characters, cursor/navigation keys and
F1-F12 are covered.  Cursor keys use `ESC [ A/B/C/D`, F1-F4 use `ESC O P-S`,
and the remaining function/navigation keys use the usual numbered CSI forms.
Each multi-byte sequence is admitted atomically, so a full queue cannot leave a
partial escape sequence for the host.  The saturating dropped-sequence count is
reported by the command.

`CMD_HID_INPUT` is nonblocking.  Its one-byte request payload is the maximum
number of bytes wanted (zero is status-only); its reply payload is:

```text
byte 0      bytes still queued after this dequeue
byte 1      dropped-sequence count, saturated at FFh
bytes 2..   zero to 24 terminal-input bytes
```

`HIDKEY.COM` polls this command directly and echoes returned bytes through
`CONOUT`; it never calls `CONST` or `CONIN`.  Ctrl-C exits.  This is the intended
bring-up boundary before the queue is wired into the BIOS console input path.

Only key-down transitions are emitted in this first cut.  An unchanged held
key does not repeat at the USB polling rate; deliberate host-side typematic is
still to be designed after the translation and queue have been exercised.

A clean level-62 firmware link reports:

```text
Data space used       7,416 of 12,800 bytes (57.9%)
Data stack reserved     512 bytes
Conservative total    7,928 of 12,800 bytes (61.9%)
Physical headroom     4,872 bytes             (38.1%)
```

The 256-byte US translation table linked in `MEDIUMCONST` (program space), not
SRAM.  The queue itself is 128 bytes.  Both firmware and `HIDKEY.COM` build
cleanly apart from the pre-existing XC8/TinyUSB warnings; hardware validation
is the next test.

## Current SRAM checkpoint (level 61, before key translation)

The firmware that enumerates the hub and keyboard and receives HID reports is
**not** the 99.2%-SRAM build described later in this chronological log.  The
current Makefile still selects:

```text
-mstack=hybrid:512:0:0
```

A forced level-61 rebuild from all sources reports:

```text
Data space used       7,280 of 12,800 bytes (56.9%)
Data stack reserved     512 bytes
Conservative total    7,792 of 12,800 bytes (60.9%)
Physical headroom     5,008 bytes             (39.1%)
```

XC8 reports the separately configured 512-byte data-stack reservation as
`512 of 512 (100.0%)`.  That means the requested reservation was placed; it is
not a measured runtime high-water mark.  The later `12,693 of 12,800 (99.2%)`
figure belongs to a rejected experimental `-mstack=software` build and must not
be used as the current firmware's memory figure.

The largest current allocation is the eight-slot SD cache: 4,160 bytes.  Other
notable fixed buffers are the bulk receive window (539), the bulk staging block
(512), TinyUSB's two-device host table (279), and the SD-record staging buffer
(128).  The intended HID-to-terminal-input layer should need only a small byte
queue and a few bytes of key/modifier state; its translation tables must remain
`const` so they occupy program space rather than SRAM.  Budget the first version
at no more than 256 additional SRAM bytes and re-check this table after it is
linked.

This does not close the separate PIC18 hardware return-stack warning, nor does
it make the hybrid allocator's previously found overlay defects impossible.
Those are correctness risks, but they are not evidence that data SRAM is nearly
exhausted.
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

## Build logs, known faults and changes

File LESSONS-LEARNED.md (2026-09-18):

# Zephyr-80: Lessons Learned

Consolidated from the bring-up records in `Code/MCU/IOController/docs/` and
`Code/HOST/CPM2.2/docs/` — roughly 11,500 lines of planning, root-cause reports
and debug logs, reduced to what is worth carrying forward.

**This document is not an authority on anything.** It records what went wrong,
what went right, and which mistakes were expensive. For current behaviour use
the subsystem documents listed at the end; for current numbers use
`Code/HOST/CPM2.2/docs/memory-map.md`, whose headroom table is generated from
the build rather than written by hand.

---

## 1. The patterns that repeated

These recurred across subsystems that share no code — the SIO transport, the
MAX3421E, the SD card, the BIOS realignment, the FAT32 work. They are the part
of this document most likely to save time on the next thing.

### Silence is not evidence of absence

A seated SD card that has not entered SPI mode is exactly as silent as an empty
socket. The driver was therefore written so that **only the presence pin can
report a card as absent**; bus silence reports `SD_ERR_NO_RESPONSE` and a trace
buffer separates the cases.

The same shape appeared on the MAX3421E: an undriven MISO reads as all-ones,
which is indistinguishable from a part that is present and answering `FFh`. And
on the command lane, where a frame the receiver rejects produces *no reply at
all*, so a validation failure reaches the host looking like a dead controller.

Whenever a failure mode can produce "nothing", something must be able to tell
"nothing" apart from "nothing yet".

### The thing that "appeared to work" was usually being masked

Three separate faults were latent for months because an earlier, cruder
implementation happened to hide them:

| Fault | What was masking it |
|---|---|
| Two extra SIO clock edges per transaction | The old transport re-established External Sync every reply, resetting the character boundary before the error could accumulate |
| Stale `FFh` in the SIO receive pipeline | The old Bulk reader disabled and reinitialised the receiver each transfer, discarding pipeline state |
| A `const`/RAM pointer that XC8 mishandles | The function was never linked until a new command referenced it |

In every case the *change* was blamed first, and in every case the change had
only removed the masking. **When a long-standing subsystem breaks the moment
something adjacent is improved, suspect exposure before regression.**

### Correlation recorded as measurement

`include/sd_card.h` carries a correction worth reading in full. An earlier
comment claimed, "confirmed on a scope", that SPI_CLK was gated by the device
selects. What the scope actually showed was clock and select coinciding — which
they did, because the firmware only ever clocked while a select was asserted.

That inference was written down as a measured hardware fact, and on its
strength the spec-required CS-high power-up burst was deleted as useless. It is
not useless: it is the step that puts an SD card into SPI mode, and losing it is
the likeliest cause of the intermittent all-`FFh` CMD0 traces that followed.

**Never write inferred topology into a comment as though it were measured.** The
cost is not the wrong belief; it is the correct code deleted on the strength of
it.

### Diagnostics can fabricate evidence

Nine bytes of the BIOS failure record — the command marker history and its index
— had **no writer at all**. The scan loop that once filled them had been
rewritten and the storage left behind. `PING.COM` printed those zeros
unconditionally, under a label saying they were the bytes the reply scan saw.

On the one report anybody consults when the link is dead, that is not a stale
field. It is fabricated evidence reading "the line was silent" regardless of
what happened on the wire.

The replacement is a *last-failure* record with an explicit "nothing recorded"
state, rather than a set of always-printed slots. **A diagnostic that cannot
distinguish "no data" from "zero" is worse than no diagnostic.**

### Things named like diagnostics that were load-bearing

The instrumentation-removal pass found four, each of which would have failed
silently on hardware rather than at build time:

| Was named | Actually is | Now named |
|---|---|---|
| `sio0b_record_rx_diag` | Also clears the SIO0/B receive-error latch — the only thing that does | `sio0b_clear_rx_error` |
| `usbh_xc8_*` (seven of them) | Live state preserved across nested calls XC8's overlay clobbers, sharing a prefix with 68 real traces | `xc8_saved_*` |
| `uprof_now()` / `uprof_init()` | The microsecond time source behind the Bulk lane's bounded wait | `timebase_us_now()` / `timebase_us_init()` |
| `HidHostUsbState` | Backs the passive status page in every build | unchanged — the name does not claim otherwise |

**The fix is to rename, so the mistake is no longer available to make.** A note
in a document is not a fix: the reader who deletes the symbol is the reader who
never opened the document. All three misleading names are now gone, and each
rename was verified to produce a **byte-identical** binary — which is both the
proof it was a pure rename and the cheapest possible regression test.

The discriminator that found the XC8 seven is worth reusing: *correctness
storage is read back inside the module; telemetry is only written there and read
from outside.*

### A helper that reads its caller's variables is coupled to that caller

The BIOS's `ccp_clear_redraw` looked like a display routine — clear the screen,
draw the prompt. It also read `ACTIVE` and `USERNO` and wrote `CURPOS` and
`STARTING`, all four of them **private variables of the stock BDOS**, at fixed
addresses inside the region a BDOS replacement overwrites.

Calling it from ZSDOS therefore printed a prompt built from message-string bytes
(`K=` instead of `A`) and, far worse, **overwrote a `RET` instruction with
`03h` on every keystroke** — ZSDOS fell through a return into a string as code.
The visible symptom was cosmetic; the real one was silent.

Nothing in the routine's name, signature or comment said "only valid while the
stock BDOS is resident". The fix was to need none of it: the console driver
already clears on `0Ch`, and the drive and user are in page zero at `0004h`
where every CP/M maintains them.

**Before reusing a routine across a component swap, check what it touches, not
what it is called.** The same shape appeared twice more in one afternoon —
`RDBUFCCP` compared against one CCP's buffer address, and `NBYTES` stored
history inside the CCP that a replacement CCP does not have.

### One flag must gate one variable

The single most expensive process error in the project's history. During the
FAT32 bring-up, one build flag gated the volume handlers **and** the filesystem
handlers together. Eleven firmware builds and a reset-looping machine later, the
conclusion "FatFs cannot be linked into this firmware" was recorded as fact in
three places.

It was wrong. Every build that linked FatFs also linked an unrelated defect. Of
eleven builds, the real cause predicted the outcome 11/11; FatFs predicted 2/11.
Once the real defect was fixed, FatFs linked and ran.

A bisect flag that moves two things does not bisect.

### Measure; then re-measure after the tree moves

`phase0-storage-restoration.md` recorded the shared VDrip transport at 633 bytes
and the storage backend at 338. The measured figures are **649** and **356**.
Those two stale numbers were trusted during the slot 5 realignment, and the
22-byte difference is why `CONSOLE=vdrip STORAGE_A=vdrip` no longer fits in
driver slot 5 and is deliberately left failing.

The FAT32 design document repeated the pattern from the other direction: its
baseline was 65,095 bytes of flash against a tree that had since shrunk to
60,042. Its conclusions survived; its numbers did not.

---

## 2. Hardware facts that cost time

Board-level truths that are not visible from the source, listed because each one
was paid for once already.

### The SIO clock is gated, and idles high

PIC `RB3/SIO_SCK` drives both SIO clocks through a **74AHCT125**, enabled by
`/SIOA_CS` and `/SIOB_CS`, with 100 kΩ pull-ups (R37/R38) on the gated outputs.
An unselected SIO clock therefore rests **high**.

With the firmware parking the clock low, releasing a channel select produced one
low-to-high transition that the SIO counted as a receive clock. A command
transaction releases the gate twice, so the Z80 received 562 edges where the PIC
generated 560 — a two-bit drift per transaction, returning to the same byte
boundary every fourth transaction. PING succeeded exactly once in four.

Two consequences worth remembering:

- **RB3 and the SIO clock input are different nets.** PIC-side edge counters
  measure the source pin and cannot see a transition created downstream by the
  buffer and its pull-up. They read 560 while the SIO received 562.
- The fix is that the shared clock now idles **high everywhere** — SPI2 uses
  `CKP=1, CKE=0`, `LATB3` is set high before either select, and PPS handovers
  happen at the same level.

### The MAX3421E powers up in half-duplex, and this board cannot do half-duplex

In half-duplex the part tri-states MISO and drives read data back out of its own
**MOSI** pin — after the eighth falling edge, expecting the master to have
released that line. On this board `SPI_MOSI`, `SPI_CLK` and `/USB_CS` pass
through **U3, a CD74HC4050 at 3V3**, which is unidirectional PIC→MAX3421E. The
master's driver cannot be turned off.

So every read returned garbage from an undriven MISO, and on the second byte of
each read two CMOS output stages fought each other.

Worse, the firmware read the REVISION register *before* calling `tuh_init()` —
and the only code that sets `FDUPSPI` is inside `hcd_init()`. **The revision
check gated the call that establishes the revision check's own precondition.**
A lock with no key.

The bootstrap is a blind *write* (`8A 10`, PINCTL, DIR=1), because a write
behaves identically in both modes: the master drives MOSI for the whole cycle
and the part never turns its driver on. Only reads differ, which is why the
order cannot be inverted.

### The MAX3421E cannot be reset, and does not share the PIC's reset

`RES` (U2.12) is strapped to +3V3 — there is no reset control. `RES` and
`CHIPRES` both spare PINCTL and USBCTL; only a power-on reset clears them. The
part sits on the mezzanine 3V3 rail while the PIC is a separate 5 V board.

**Resetting or reflashing the PIC does not reset the MAX3421E.** Once the
FDUPSPI write lands once, it stays in full duplex across every subsequent PIC
reset — which is why the blind write is repeated per probe burst, and why
exercising the real cold-start path means dropping the 3V3 rail.

Also on that part: `GPX` (U2.17) is a no-connect, so the one-probe "is it alive"
answer is unavailable — worth bodging on the next spin. All eight `GPOUT` pins
are no-connects, which is what makes the walking-pattern loopback test free.
`/USB_INT` reaches PIC RA0 unbuffered at 3.3 V into a 5 V part; if RA0's buffer
is Schmitt (VIH = 4.0 V) a high never registers and the pin reads permanently
asserted. That presents as "enumeration silently never starts", not as a bus
fault; `INLVLA0` selects TTL levels.

### Test electrical paths at every rate

The GPOUT loopback runs at 125 kHz, 1 MHz and 4 MHz **on purpose**. The failure
being hunted is propagation delay through U3, which is fixed — so a marginal
part passes slow and fails fast, and a single-rate test calls the board healthy.

Walking-one alone cannot separate stuck-low from undriven, so the patterns are
`00 01 02 04 08 05 0A 0F`: `00`/`0F` pin both stuck-at polarities and `05`/`0A`
cross every adjacent pair in both directions.

### Scope captures of bursty buses lie

Within a burst SCK genuinely is 125 kHz / 1 MHz / 4 MHz. But the whole probe is
about 10 ms and fires once per tool run against an otherwise silent bus, so a
free-running scope measures the burst *envelope*. Trigger on the falling edge of
the chip select.

### SD cards are not interchangeable

After connector rework and confirmed signal levels, two generic INDMEM 16 GiB
SDHC cards fail ACMD41 startup where a SanDisk 4 GiB works reliably in the same
socket with the same firmware. Brand, controller batch, capacity and adapter use
are confounded in that sample — treat both failing cards as **one** result, not
two independent data points.

The conservative settings in `sd_card.h` (125 kHz init, 12 power-up bytes or 96
clocks with CS high, 10 ms settle, CRC verification on) exist because of this
and should be relaxed **one at a time**, keeping the CRC check, so a regression
names its own cause.

The first successful compatibility change came from comparing the driver with
John Winans' Z80 Retro implementation. Both drivers deassert CS between `CMD55`
and `ACMD41`, so that transaction boundary was not the fault and must not be
removed. The important difference was at the end of each transaction: John's
driver emits one `FFh` byte while the SD card is still selected, then raises CS
and emits another two `FFh` bytes.

`sd_deselect()` now preserves that exact order: **8 trailing clocks with SD CS
low, followed by 16 idle clocks with every SPI1 device deselected.** With that
single change, a previously failing card initialized through multiple cold
boots and completed VGM playback of a 120 KiB song, exercising sustained
multi-block reads. This is strong preliminary evidence, not yet a completed
soak test. If this failure is revisited, preserve the selected trailing byte
before changing initialization commands, retry counts, or the `CMD55`/
`ACMD41` boundary.

### V9958 R#8 `VR` must be 1 on 64K×4 DRAM

The reset value of `00h` selects 16K-DRAM addressing. On the production
LunchCrema hardware that aliased `00000h` and `08000h`, so later bitmap rows
overwrote earlier ones. Diagnostic signature: `exp=12 act=56 @0123` after
writing `56h` at `08123h`.

### CTC channels are not proven until proven individually

CTC0 at port `40h` in timer mode, `/256`, automatic trigger, constant 217
produces stable IM2 interrupts and is the verified application time source.
CTC1 and CTC2 did not yield usable playback interrupts during VGM bring-up —
recorded as an **unresolved observation, not a defect**. Before using them,
verify vector, daisy-chain acknowledgement, control word and board routing with
a counter-only ISR.

The same bring-up showed a compact ISR coexists fine with the SIO console and
foreground SD streaming, while moving stream decoding, PSG writes and BDOS reads
*into* the ISR caused instability. Keep ISRs small; do the work in foreground.

---

## 3. Toolchain: XC8 on the PIC18

The compiler is a first-class source of defects in this firmware, not a
neutral tool. `Code/MCU/IOController/docs/XC8-PATCHES.md` is the authority.

### The call graph is unanalysable, and that has consequences

TinyUSB's function-pointer driver tables make the call graph look recursive.
XC8 reports `warning (1393) possible hardware stack overflow detected;
estimated stack depth: unknown (due to recursion)` and then allocates
overlaid local storage from liveness information that is not sound.

Six silent corruptions in the USB path are traced to this. `STVREN = ON` is set
deliberately so that a hardware call-stack overflow resets the device instead of
corrupting a return address — turning an unprovable property into a visible
failure. Since the controller drives the host reset pair, that failure presents
as **the whole machine rebooting continuously with nothing on the console**.

### Never return a pointer that may address either RAM or program memory

`const` lives in program memory on PIC18, so:

```c
static const uint8_t blank_name[11] = { ' ', ... };
const uint8_t *vol_name(uint8_t unit)
{ return (unit < VOL_UNITS) ? units[unit].name : blank_name; }
```

returns a pointer whose target address space is not known until run time. This
function — **never called** — reset-looped the machine from the moment it was
linked. Replacing the accessor set with one function that fills a
caller-supplied byte array fixed it.

Constructs that merely ask something unusual of the compiler are unsafe here
even when unreachable.

### Bisecting a fault in code that never runs

The technique that eventually worked, and is worth reusing:

1. Put the suspect code behind a `-D` flag in `dispatch.c` so the **linker
   strips it**, and confirm the stripped build boots.
2. Add back **one construct per build**.
3. Compare `Program space` and `Data space` between builds. **If a smaller
   build fails, stop thinking about size** — that single control killed several
   plausible theories at once.
4. Keep a known-good hex to reflash between experiments.

Also worth building: a *control* that changes size without changing code. Adding
36 KB of inert `const` to a working firmware proved image size was irrelevant.

### Period toolchains fail in ways that name nothing

Bringing ZCPR2 and ZSDOS into the ROM meant running 1980s CP/M assemblers under
an emulator, and every failure was silent or misdirected:

- **A CRLF slip reports as `INPUT LINE TOO LONG`.** Three lines edited into a
  config file with `\n` instead of `\r\n` made ZMAC see the whole file as one
  line. The error named neither the file nor the line number. Both build
  scripts now check line endings before assembling.
- **DRI's `LINK.COM` prints `ABORTED` and nothing else** on `ZMAC` output —
  bare, with no options, no diagnostic. Microsoft's `L80` reads the identical
  `.REL` fine. The DRI linker is kept vendored purely to record that it does not
  work here.
- **The emulator does not exit when its input ends**, so a build that "hangs"
  may have finished correctly minutes earlier. Twice I let a timeout expire
  before checking, and both times the output files were already sitting there.
  **Judge these builds by their artefacts, not by process exit.** The scripts
  now watch for the assembler's completion line and stop on it — 1.8 seconds
  instead of two minutes.

The general rule: when driving a tool that predates useful error reporting,
build the check into the harness, because the tool will not tell you.

### Zephyr-80 is a textbook 56K CP/M, and that keeps paying

`CBASE=C400h`, `FBASE=CC06h`, `CBIOS_BASE=DA00h` are exactly what the standard
formulas produce:

```
CPRLOC = 3400H + (MSIZE-20-BIOSEX)*1024     ; MSIZE=56, BIOSEX=0  -> C400h
BIOS   = CPRLOC + 800H + 0E00H              ;                     -> DA00h
```

Both ZCPR2's `Z2HDR.LIB` and ZSDOS's `zsdos.lib` compute their addresses that
way, so each needed **one or two equates changed and nothing else**. Period
software drops onto this machine without adjustment, and that is worth
preserving the next time the memory map is tempted to move.

### `make` can succeed and build nothing — twice, by two mechanisms

This has now happened in the same makefile two different ways, and both times
the tell was a stale `build/` that looked like success.

**1. The default goal.** `check-xc8-patches` was the first real target, and GNU
make takes the first real target as the default goal. A bare `make` ran the
patch check, printed OK, exited 0 and built nothing. Fixed with
`.DEFAULT_GOAL := all`.

**2. An empty variable at the start of a recipe line.** The compile recipe
begins with `$(XC8)`. When an over-broad edit deleted the `XC8_DIR` / `XC8` /
`DFP` definitions, that line began with `-mcpu=...` — and **GNU make strips a
leading `-` from a recipe line as its ignore-errors modifier.** Make ran
`mcpu=PIC18F57Q84` as a command, the shell reported "not found", make reported
`(ignored)`, and the build exited 0 with no hex produced. The breakage survived
a commit because of it.

Fixed with an explicit guard, and the guard was verified to fire:

```make
ifeq ($(strip $(XC8)),)
$(error XC8 is empty -- the compiler variable was lost.  See XC8_DIR above.)
endif
```

The general rule: **a build system that can exit 0 without producing its output
will eventually do so at the worst moment.** Prefer a loud `$(error)` over
trusting that a variable is set.

---

## 4. Transport and protocol

### Adding a command takes three edits

`ioc_frame.h`, `dispatch.c`, **and** `is_command_class()` in `external_sync.c`.

That last one is a receiver-side validation whitelist. An unlisted class is
dropped *silently*, because `service_command_request()` sends no reply when the
receive fails — so the host reports `IOC_XPORT_TIMEOUT_REPLY_MARKER`, which
reads as a dead controller, rather than `RSP_UNKNOWN_COMMAND`, which would name
the problem in one line.

### Persistent sync means receiver state persists too

The SIO's last shifted character is not necessarily visible in the CPU-readable
FIFO when its eighth clock arrives; further clocks advance the internal
pipeline. The MCU therefore clocks one `FFh` after the CRC so the host can read
a complete packet — which leaves that trailer as the newest internal character,
free to become the *first* FIFO byte of the next transfer.

The trailer cannot simply be removed (it can hide the CRC low byte), and the
receiver cannot be reset to clear it (receiver disable is one of the events that
destroys External Sync character assembly). The answer was to make the Bulk lane
scan for the `A5 5A` marker like the command lane already did, instead of
assuming FIFO byte zero is payload byte zero.

**Both lanes now validate identically.** The last structural difference between
the receive paths was exactly where the bug lived.

### Distinguish the failure stages in the status byte

`IOC_XPORT_TIMEOUT_REPLY_MARKER` (`11h`) versus `IOC_XPORT_TIMEOUT_REPLY_BODY`
(`12h`) carry "the reply never came" versus "the reply began, then stalled".
That distinction made a whole diagnostic field redundant and deletable. Bulk
rejection reasons `01h`–`07h` name the stage that rejected a frame.

Precision in a status byte removes the need for a diagnostic buffer later.

### A status query must not change state

`CMD_VOL_INFO` originally called `vol_ensure_mounted()`. That can run
`sd_card_init()` — about a second of ACMD41 polling at 125 kHz, well past the
host's IOCALL timeout — and, when the card session has been lost, it calls
`vol_init()`, which discards every mount. **Asking what was mounted could
unmount it.**

### Long operations must drop `COMMAND_READY`

The host gates every IOCALL on that line. The SD cache flush already lowered it
around a long write; the auto-mount did not, so a request arriving mid-mount
waited past the host's timeout. The Z80 holds `/SIO1B_INT` until acknowledged,
so a request is *delayed* rather than lost — lowering the line only tells the
host the truth about when to bother asking.

---

## 5. Process

### Gates exist because the alternative is a bricked machine

The FAT32 design document specified a phased sequence, each phase ending
somewhere shippable, with an explicit gate: *"selftest mounts a real card;
`IOC_SDREC`, `IOC_SDBLK` and the HID path still pass unchanged."* All three
phases were implemented and flashed together, skipping every gate. The machine
reset-looped and stayed unusable across a dozen build-and-flash cycles.

The document's own risk section had named the mechanism in advance —
*"Adding 7,000 lines of new code to that allocator is not free"* — and its
proposed mitigation was precisely the gate that was skipped.

### Build-time guards beat review

Two defects nobody was looking for were found during the realignment: nine bytes
of diagnostic with no writer, and a record layout mirror that had silently
drifted from the BIOS. Both now have guards — `check_diag_record.py` and
`check_xc8_patches.sh` — and **each was verified to fail when the fault is
reintroduced.** A guard that has never been seen to fail is not a guard.

### Cross-project ordering is a real dependency

`W6 before W7`: if a controller handler is removed while its `.COM` is still on
the rescue disk, the tool fails in a way that looks like a transport fault.
Retire the caller before the callee.

### Destructive tools do not belong on a rescue disk

`SDWRITE`, `SDREC`, `SDSOAK` and `SDBENCH` act on whatever card is inserted,
with no drive letter to get wrong. They have no business on the disk you reach
for when the machine is already in trouble. The ROM manifest has `normal` and
`diagnostic` profiles for exactly this; nothing is deleted, and every tool still
builds.

### Stamp historical documents at the top

Several planning documents were still being read as current long after the tree
moved. They now carry a `HISTORICAL` banner naming what has changed and pointing
at the authority. `io_controller_bios_readiness.md`,
`phase0-storage-restoration.md` and `optimization_report.md` are the examples
worth copying.

**A superseded document that does not say so is a trap, not an archive.**

### Recovery infrastructure earns its place

After three separate builds reset-looped the machine into programmer-only
recovery, `boot_guard.c` was added: a `__persistent` counter that survives
reset, and after three consecutive boots that fail to stay up for two seconds,
the firmware comes up **degraded** — skipping the risky path so the machine
boots and can be interrogated. A power cycle clears it; so does staying up.

Turning "bricked" into "boots and tells you why" is worth ~40 lines.

---

## 6. What went right

Worth recording, because a lessons-learned document that only lists failures
misrepresents the project.

- **The two-lane transport design held.** `protocol-gap-analysis.md` compares
  the original proposal against what shipped line by line; the deviations are
  all deliberate compatibility choices, and the framing model needed no rework.
- **The record-addressed storage model was the right layer.** The BIOS asks for
  a 128-byte record and gets one; deblocking, LRU and write policy live on the
  PIC where SRAM is plentiful and firmware is easy to change. The Z80 side never
  learned the card has blocks.
- **Vendoring TinyUSB as a submodule with a single patch commit.** The complete
  patch set is one `git diff` away and a refresh is a rebase, not a
  re-derivation. Compare with a copied tree, where the same 63 hunks would be
  unrecoverable.
- **Explicit invariants in header comments.** The write-through rule, the
  "nothing may write a mounted image through the filesystem" rule, and the SD
  belt-and-braces table each survived contact with a later change *because they
  said why, not just what.*
- **Splitting boot-critical code from convenience code.** Image resolution runs
  on 500 verifiable lines (`fatmap.c`) while FatFs serves user space, so a fault
  in the large library costs a transient rather than the machine's ability to
  boot.
- **The failure record at a fixed address.** A `.COM` can read it with
  `ld a,(nnnn)` and report it with no working transport — which is the only
  moment it matters.

---

## 7. Still open

| Item | State |
|---|---|
| INDMEM SD cards fail ACMD41 startup | Selected trailing byte fixes cold boots and a 120 KiB VGM read; extended soak testing pending |
| `CONSOLE=vdrip` (any storage) | Does not build. The 654-byte VDrip transport has no hole left in common memory; driver slot 5 was reallocated to the IRQ dispatcher and the sercon tee. The older "22 bytes over slot 5" reading was measured before that relocation. See `Code/HOST/CPM2.2/docs/vdrip-backend-restoration.md` |
| CTC1 / CTC2 interrupts | Unresolved observation from VGM bring-up; not proven defective |
| `/USB_INT` input threshold at RA0 | Never measured; enumeration works on hardware, so it is adequate in practice rather than confirmed by measurement |
| `CMD_VOL_MOUNT` timeout | Can outrun the BIOS IOCALL timeout on a slow card |
| Hardware call-stack depth | Unbounded by the toolchain; `STVREN` makes overflow visible, not impossible |

---

## 8. Source documents

**IO Controller** — `Code/MCU/IOController/docs/`

| Document | What it is |
|---|---|
| `max3421-bring-up-debug.md` | The full USB bring-up log, including a "Ruled Out — Do Not Re-Investigate" table and a bisection guide |
| `XC8-PATCHES.md` | Which TinyUSB edits are compiler workarounds and which are instrumentation |
| `ping-two-bit-drift-root-cause.md` | The gated-clock idle-level fault |
| `bulk-persistent-sync-pipeline-root-cause.md` | The stale SIO FIFO trailer |
| `sd-card-acmd41-startup-failure.md` | Card-family startup failure, evidence and remediation phases |
| `two-lane-transport.md` | **Authoritative** transport contract |
| `external_sync_protocol.md` | SIO rules, sync establishment, packet and CRC |
| `protocol-gap-analysis.md` | Proposed versus shipped, with reasons |
| `pinout.md` | Port map and board-level constraints |
| `debug-test-code-review.md` | What belongs in normal versus diagnostic firmware |

**CP/M BIOS** — `Code/HOST/CPM2.2/docs/`

| Document | What it is |
|---|---|
| `memory-map.md`, `symbol-map.md` | **Generated from the build** — the authority on layout and free space |
| `bios-realignment-plan.md` | The instrumentation cleanup, its outcome, and the four load-bearing "diagnostics" |
| `ioc-diagnostic-record.md` | The fixed-address failure record and why its field order is load-bearing |
| `ioc-fat32-images-and-shared-fs.md` | The FAT32 design, the eleven-build bisect, and the correction |
| `ctc-and-real-time-programming.md` | CTC, IM2 under CP/M, the 60 Hz budget |
| `lunchcrema-v9958-console-bringup.md` | Non-negotiable V9958 register settings |
| `serial-console-fallback.md` | The recovery console on SIO0/B |
| `zephyr80_bios_walkthrough.md` | BIOS structure |
| `debug-test-code-review.md` | Resident BIOS and utility inventory |
| `io_controller_bios_readiness.md`, `phase0-storage-restoration.md`, `optimization_report.md` | **HISTORICAL** — kept for reasoning, superseded on numbers |

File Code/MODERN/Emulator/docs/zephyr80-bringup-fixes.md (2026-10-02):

# Zephyr-80 MAME — Bring-Up Fix Log

Chronicles the changes that took the `zephyr80` machine from "loads a placeholder
ROM" to "runs the real 128 KiB CP/M firmware and drives the SIO0/B console + VDrip
link". All changes are in `src/mame/pbitz/` (`zephyr80.cpp`, `zephyr80_map.h`) plus
one build-script change in `scripts/target/mame/pbitz.lua`.

The authoritative hardware references used throughout:

- `HDL/WinCUPL/src/MEM_DECODER.pld` (Rev 09) — CPU-board memory decode.
- `HDL/WinCUPL/src/IO_DECODER.pld` (Rev 03) — I/O port decode.
- `HOST/CPM2.2/src/platform_zephyr80.inc` — firmware's port/latch/bit definitions.
- `HOST/CPM2.2/src/boot_shadow_copy.asm`, `sio_core.asm`, `cbios_boot.asm`,
  `vdrip_transport.asm` — the firmware itself.

---

## Part A — Make the firmware run (memory decode)

### Symptom
The 128 KiB firmware's reset vector is `JP $DA48`, but the emulator halted
immediately: it mapped ROM only at `$0000-$5FFF`, so `$DA48` fetched from
unmapped RAM. Nothing ran.

### Root cause
The emulator's memory decode was an early approximation that did not match
`MEM_DECODER.pld` Rev 09. Three things were missing:

1. **High ROM window.** Rev 09 makes ROM readable in **both** the BIOS window
   (`$0000-$5FFF`) **and** the high common window `SAFE_RAM` (`$C000-$FFFF`) in
   normal mode: `BOOT_ROM = BIOS_RANGE # SAFE_RAM`. `$DA48` lives in `SAFE_RAM`.
2. **ROM paging.** The banking latch's high three bits select a ROM page
   (`ROM A16-A18`); the emulator ignored them.
3. **Force-bank-0 region.** Rev 09 forces the high 16 KiB to SRAM bank 0 when
   shadow or ROM-disabled: `FORCE_BANK0 = SAFE_RAM & (ROM_DIS # RAM_SHADOW)`.
   The old code forced the *low* `$0000-$1FFF` instead.

The latch bit layout (I/O port `$00`, a 74HC273) comes from the firmware's
`platform_zephyr80.inc`:

    D0-D2 = SRAM bank 0-7      (RAM A16-A18)
    D3    = shadow / copy mode
    D4    = ROM disable
    D5-D7 = ROM page 0-7       (ROM A16-A18)

### Fix
- `mem_r` implements Rev 09's `ROM_CS` exactly; `mem_w` writes SRAM
  unconditionally (Rev 09's `SRAM_CS` has an unconditional `WR` term).
- Added `rom_r()` with ROM paging: `rom_addr = (rom_page << 16) | (A0..A15)`.
- `selected_ram_bank()` implements the `SAFE_RAM & (ROM_DIS | RAM_SHADOW)` force.
- Latch layout and `SAFE_RAM`/ROM-page constants added to `zephyr80_map.h`;
  `ROM_LOAD` now loads the full 128 KiB into a 512 KiB region.
- Removed the non-Rev-09 `PROG`/`CART` decode paths.

### Verified
An I/O write-tap on the bank latch (`$00`) shows the firmware executing the exact
`boot_shadow_copy.asm` sequence:

    08  29 4A 6B 8C AD CE EF  10

i.e. copy-mode + pages 1-7 into banks 1-7 (`(N<<5)|SHADOW|N`), then ROM-disable and
continue from SRAM bank 0 into the CBIOS.

---

## Part B — Make the console work (SIO register order, interrupts, baud)

### Symptom
After Part A the firmware boots into the CBIOS, but the SIO0/B VDrip console was
dead — the proxy's `PROXY_READY` sequence did nothing.

### Root causes & fixes

1. **SIO register order was wrong (the big one).**
   The firmware addresses each SIO as `ba_cd` (channel on A1, data/control on A0):
   `SIOA_DATA=$20, SIOA_CTRL=$21, SIOB_DATA=$22, SIOB_CTRL=$23`. The emulator used
   MAME's `cd_ba` accessor, which swaps `$21`/`$22` — so every WR2/data write hit
   the wrong channel and the whole console init was scrambled.
   **Fix:** `sio0_r/w` and `sio1_r/w` now use `ba_cd_r/w`; the register-offset
   constants in `zephyr80_map.h` were corrected (A data / A ctrl / B data / B ctrl).

2. **No IM2 interrupt daisy chain.**
   The console RX is interrupt-driven: `I = 0xDD`, SIO0/B `WR2 = 0x10`, so RX must
   vector to `0xDD10` (`sio_core_isr`). The old code used a wired-OR IRQ with no
   vectoring, so the interrupt could never reach the ISR.
   **Fix:** added `Z80CTC` at `$40-$43` and a real IM2 daisy chain
   (`z80_daisy_config { ctc, sio0, sio1 }`, `set_daisy_config`), with each device's
   interrupt callback wired to `INPUT_LINE_IRQ0`. The daisy supplies the vector on
   interrupt-acknowledge.

3. **Console baud was 9600, hardware is 115200.**
   The firmware programs SIO0/B WR4 for a ×16 clock at 115200.
   **Fix:** SIO0/B clock set to `115200 × 16`; the `sio0b_rs232` pty/loopback
   options default to 115200 (`DEVICE_INPUT_DEFAULTS`) so both ends match. Per the
   hardware, the console baud is fixed (not CTC-derived); only the **user** channel
   (SIO0/A) takes its clock from the CTC (`ctc.zc_callback<0>()` → SIO0/A rx/tx).

### Verified
An I/O trace of the boot shows the firmware now programming the SIO correctly via
the right ports: WR2 vector `0x10`, WR1 `0x18` (Rx int, all chars, no parity
vector), WR9 MIE `0x08`, RTS asserted — then entering the `PROXY_READY` wait.
End-to-end interactive console (CP/M reading storage over VDrip) confirmed against
the real host-side VDrip proxy.

### PROXY_READY frame (for reference)
VDrip framing is `A5 5A LEN_LO LEN_HI TYPE PAYLOAD…` (LEN = 16-bit LE count of
TYPE+PAYLOAD). The readiness packet the proxy sends is `PACKET_PROXY_READY = 0x0A`
with zero payload:

    A5 5A 01 00 0A

The proxy must open the pty in **raw** mode — the link is binary.

---

## Open items / assumptions to confirm against hardware

- **Daisy priority order** `{ ctc, sio0, sio1 }` is the conventional Z80 arrangement
  but the true IEI/IEO order is a hardware detail. It is functionally moot today
  (the firmware disables the CTC and polls SIO1; only SIO0/B interrupts).
- **CTC clock crystal** and the exact CTC-channel → user-baud / tick assignment are
  placeholders; the firmware only disables the CTC at boot.
- **`/DCD` tied low on SIO0/B.** On real hardware `/DCD` is hardwired asserted so
  the WR3 Auto-Enables receiver is always enabled. In MAME the pty asserts DCD, but
  note the interaction between the SIO channel reset and the latched DCD state if a
  future RX-gating issue appears.

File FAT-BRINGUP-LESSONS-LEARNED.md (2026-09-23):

# FAT-Backed BDOS Bring-Up — Lessons Learned

> **Status:** Initial version capturing the lessons visible from one bring-up/debugging session.  
> This document is intentionally expected to grow as other development sessions add their own observations.

## 1. Purpose

This document records the lessons learned while adding a FAT-backed logical
drive personality to Zephyr-80 while preserving compatibility with ZSDOS and
ordinary CP/M applications.

The important result of the work was not merely that FAT files became visible
to CP/M. The bring-up exposed a number of implicit contracts in CP/M, ZSDOS,
the Zephyr banking model, and the IOC transport that are easy to violate when
customizing the operating system.

The goal of this document is to preserve those lessons for future OS work.

---

## 2. The most important architectural rule

### Bank 7 is implementation space; common memory is ABI space

One of the most useful architectural rules to emerge was:

> Bank 7 is where OS implementation belongs.  
> Common bank-0 memory exists only where code or data must cross between the
> application and OS mapping.

New functionality should default to bank 7.

Common memory should contain only things that genuinely need to remain visible
during a crossing, such as:

- CALL 5 / BDOS facade
- minimal bank transition code
- interrupt entry machinery
- caller-visible returned objects
- staging buffers
- cross-mode stack/state

Free common memory is not a reason to put implementation code there.

This rule prevents the common area from slowly becoming a second operating
system image and keeps future banking changes manageable.

---

## 3. Do not replace ZSDOS state unless necessary

The first instinct when adding an alternate filesystem may be to maintain
parallel state for:

- current drive
- current USER
- write-protect state
- current disk structures

That turned out to be the wrong abstraction.

ZSDOS already owns these concepts and applications expect its behavior.

The FAT personality therefore participates in the existing model rather than
creating a parallel one.

Examples:

- Function 14 still changes the current drive through ZSDOS.
- Function 32 remains authoritative for USER.
- ZSDOS remains authoritative for software write protection.
- FAT-specific state is a mirror or implementation cache, never the authority.

A cache is allowed to become stale. An independent OS state machine is not.

---

## 4. Synthetic BIOS support is extremely valuable

The FAT-backed drive does not use CP/M disk allocation internally, but allowing
ZSDOS to select it through the normal BIOS interface simplified the entire
design.

A small synthetic disk personality provides:

- SELDSK
- synthetic DPH
- synthetic DPB
- synthetic ALV
- harmless empty READ behavior
- WRITE failure in the read-only phase

This lets ZSDOS perform normal login and current-drive bookkeeping.

It also creates a useful safety property:

> If a FAT-specific operation accidentally falls through to ordinary ZSDOS
> disk processing, ZSDOS sees an empty synthetic disk rather than operating on
> the previously selected conventional drive.

That failure mode is much safer.

---

## 5. CP/M compatibility is defined by observable behavior, not documentation

A major lesson was that the documented BDOS function interface is not the
complete compatibility contract.

Programs depend on details such as:

- returned A values
- which 32-byte slot of the DMA directory buffer contains a match
- exact FCB mutations
- EX/S1/S2/RC encoding
- search continuation state
- drive restoration
- wildcard USER behavior
- EOF behavior

The correct approach was to characterize a real ZSDOS system with
`BDOSCHAR.COM` and reproduce what applications can observe.

This was much more productive than attempting to infer behavior from CP/M
documentation alone.

---

## 6. SEARCH FIRST / SEARCH NEXT contain more semantics than expected

Directory search became one of the richest compatibility surfaces.

A SEARCH result is not simply "here is a filename".

Traditional programs expect:

- A = 0..3 indicating the matching slot
- the corresponding directory entry at `DMA + A * 32`
- a full 128-byte synthetic directory sector
- correct extent fields
- persistent SEARCH NEXT state

This mattered because applications such as CRC interpret the returned DMA
buffer exactly as if it came from a real CP/M directory.

A search implementation that returns the right filename but the wrong slot,
extent fields, or user information is still incompatible.

---

## 7. FCB drive byte '?' is a real compatibility feature

CRC 2.0 uncovered one of the most obscure assumptions in the entire bring-up.

For SEARCH operations:

```text
FCB byte 0 = 3Fh ('?')
```

does not mean "drive 63".

ZSDOS interprets it as a special wildcard-drive/user search form on the current
drive.

CRC uses this to enumerate files across USER areas.

The original FAT dispatcher did not reproduce this behavior, causing CRC to
silently see an empty directory.

This is an important general lesson:

> Never assume that an apparently invalid FCB field is unused.
> Characterize how ZSDOS treats it before rejecting it.

CRC was valuable not because CRC itself mattered, but because it exposed an
otherwise invisible compatibility convention.

---

## 8. Explicit-drive FCB operations may temporarily change the selected drive

ZSDOS explicit-drive processing is not simply:

```text
read B:
```

The operation may behave more like:

```text
remember current drive D
select B
perform operation
restore D
```

This matters for debugging.

An error reported during BDOS function 20 against B: does not necessarily mean
that the B: data read failed.

The failing lower-level operation may be the later restoration of D:.

This distinction became important while debugging the transport race.

When diagnosing ZSDOS filesystem problems, trace actual SELDSK transitions
rather than inferring them from the BDOS call that eventually reports the
error.

---

## 9. ZCPR utilities may hide the behavior being tested

Another subtle lesson came from using TYPE as a compatibility test.

ZCPR2 TYPE does not necessarily preserve an explicit drive in its working FCB.

It may:

- temporarily log into the requested drive
- make that drive current
- set the working FCB drive to zero

Therefore:

```text
D> TYPE B:FILE
```

does not necessarily exercise the same path as a transient application holding
an FCB whose drive byte explicitly refers to B while D remains current.

This explains why TYPE could pass while VGMPLAYER exposed an explicit-drive
problem.

The broader lesson is:

> Know what the test program actually asks BDOS to do.

Shell utilities are not always transparent wrappers around the command line.

---

## 10. FCBs must remain authoritative

IOC handles must never become hidden state inside an FCB.

Applications are allowed to:

- copy FCBs
- reopen files
- modify sequential/random positions
- preserve FCBs independently

Therefore the FCB must remain sufficient to reconstruct the operation.

IOC file handles can be cached for performance, but they are disposable.

A cached handle may be keyed by:

- drive
- USER
- CWD generation
- 8.3 identity

If the handle disappears, the backend must be able to reopen the file and
continue from FCB state.

This principle prevented the FAT personality from becoming dependent on
implementation-private state that CP/M programs cannot preserve.

---

## 11. Small handle pools expose lifecycle bugs very effectively

The initial FS2 implementation deliberately used only a very small number of
open file contexts.

This exposed a bug where repeated 128-byte reads leaked file handles.

Symptoms included:

- reads stopping after only a few records
- increasing the slot count increasing the failure point proportionally
- directory operations still functioning because DIR used a different context

Changing the number of available slots became a diagnostic tool.

The general lesson:

> Small fixed resource pools are useful during bring-up because lifecycle bugs
> become deterministic instead of being hidden by excess capacity.

Do not fix exhaustion bugs by merely increasing pool size.

---

## 12. Read/write completion semantics differ fundamentally

Reads can often be retried safely.

Writes cannot.

If a transport failure occurs after a write payload has been delivered but
before the final completion reply is received, the host may not know whether
the write committed.

That state must be represented explicitly:

- definitely not committed
- definitely committed
- completion unknown

Never blindly replay a write whose commit status is unknown.

This becomes especially important when extending FS2 from the read-only
Milestone 4 implementation to writable Milestones 5 and 6.

---

## 13. Interrupt masking must begin when the reply begins, not after parsing it

One of the most obscure bring-up bugs was in the IOC receive critical section.

The transport already masked interrupts during:

- command-body reception
- bulk transfer

but interrupts remained enabled while scanning for the first reply marker.

The MCU is the clock master.

Once the first byte appears, the rest of the reply continues arriving whether
the Z80 is ready or not.

The SIO FIFO is small.

A CTC interrupt immediately after the first receive-ready indication could
therefore:

1. delay the receive loop
2. allow the SIO FIFO to overflow
3. corrupt the reply before the code reached its existing DI section

The important rule is:

> Waiting for a reply may remain interruptible.
> Once the first RX-ready indication appears, every incoming byte belongs to a
> timing-critical transaction and must be protected.

So the correct boundary is:

```text
wait for RX-ready      interrupts enabled
RX-ready appears
DI
recognize marker
receive reply
perform bulk phase
EI
```

This fixed failures that initially appeared to be filesystem or drive-selection
bugs.

---

## 14. Transport errors can masquerade as filesystem errors

The interrupt race produced errors such as:

```text
ZSDOS error on B: No Drive
```

At first sight this suggested a drive-state or SELDSK problem.

In reality a later IOC transaction involved in restoring the selected drive
could lose its reply.

The filesystem layer then observed only a failed selection.

This is a general debugging lesson:

> A high-level filesystem error is not proof that the filesystem logic is the
> source of the failure.

When several unrelated operations fail nondeterministically, inspect common
transport paths before rewriting filesystem logic.

---

## 15. FAT attributes and CP/M attributes are not equivalent

Mapping FAT:

- HIDDEN
- SYSTEM
- ARCHIVE

directly onto CP/M attribute bits seemed convenient but produced compatibility
problems.

In particular, FAT's ARCHIVE bit became visible as a high bit in a CP/M file
type character and confused existing software.

The semantic models are different.

The final decision was:

- do not project FAT HIDDEN/SYSTEM/ARCHIVE into synthetic CP/M directory
  attributes
- keep FAT metadata internal to the FAT filesystem
- treat ZSDOS software write protection separately

If CP/M-specific attributes are ever needed later, they should be represented
as CP/M metadata rather than pretending FAT metadata has identical meaning.

---

## 16. Large files require real CP/M extent semantics

A FAT file is naturally one byte stream.

A CP/M application sees:

- 128-byte records
- extents
- EX/S1/S2/RC
- multiple directory entries for large files

Synthetic SEARCH therefore has to model the observable CP/M extent structure,
even though there are no real CP/M allocation blocks underneath.

This was especially visible with large files such as VGM data.

It is not enough to emit one synthetic directory entry per FAT file.

The compatibility layer must emit the extent sequence a real CP/M filesystem
would expose.

---

## 17. USER areas can be projected cleanly onto directories

The mapping:

```text
USER 0 -> current FAT directory
USER N -> current FAT directory/@N
```

proved simple and useful.

For example:

```text
/CPM/D/GAMES/FOO.COM       USER 0
/CPM/D/GAMES/@1/FOO.COM    USER 1
```

This preserves normal PC-visible files for USER 0 while allowing CP/M USER
semantics without inventing FAT metadata.

Native filesystem operations should not implicitly apply this mapping.

It belongs specifically to the FCB compatibility personality.

---

## 18. Hierarchy belongs beneath the CP/M view, not inside FCB syntax

The per-drive FAT current directory provides hierarchy while preserving the
flat namespace expected by CP/M applications.

For example:

```text
ZCD GAMES
```

changes D:'s FAT current directory.

Legacy:

```text
DIR
TYPE
OPEN
```

continue to see an ordinary flat CP/M directory.

This proved cleaner than attempting to add path syntax to FCB operations.

---

## 19. Separate native filesystem semantics from CP/M compatibility

The architecture became much easier to reason about once the two layers were
kept distinct:

```text
FatFs
   |
   v
FS2 byte-oriented filesystem service
   |
   +---- native Zephyr API
   |
   +---- CP/M FCB compatibility personality
```

The native API should not inherit:

- 128-byte records
- CP/M extents
- USER mapping
- synthetic DPB/ALV behavior

Those exist only in the compatibility layer.

Likewise, the CP/M personality should not expose IOC tokens or FatFs details.

---

## 20. Performance problems should be solved at the right abstraction level

The conventional CP/M volume eventually became dramatically faster after
deblocking/cache improvements.

A workload such as SC2 loading dropped from several seconds to effectively
instantaneous, and VGMPLAYER transitions became nearly seamless.

This demonstrated that the hardware and transport are capable of good
performance.

The FAT compatibility path is currently slower largely because it still pays
more work per 128-byte BDOS record.

The first optimization after writable correctness should therefore be a simple
512-byte deblocking cache:

```text
one 512-byte FS2 read
    -> four 128-byte BDOS records
```

Do not start by redesigning the transport.

Measure the simple deblocking improvement first.

---

## 21. Correctness before optimization was the right decision

The bring-up deliberately postponed FAT deblocking while compatibility bugs
were still being resolved.

That made debugging substantially easier.

Otherwise a failure could have originated in:

- FCB semantics
- SEARCH state
- IOC handles
- cache identity
- stale cache contents
- transport
- FatFs

Keeping the read path simple until compatibility stabilized reduced the number
of moving pieces.

The same discipline should be applied to writable support.

---

## 22. Milestones should isolate semantic layers

The staged implementation worked well:

```text
M0  characterize BDOS
M1  synthetic FAT BIOS personality
M2  minimal read-only FS2
M3  native read-only filesystem API
M4  complete read-only CP/M/FAT personality
M5  expose writable FAT functionality safely through FS2/native API
M6  map writable functionality into CP/M FCB semantics
M7  optimize resources/transport
```

The important boundary is:

> M5 provides a real native R/W FAT filesystem.  
> M6 makes ordinary CP/M programs able to write through it.

Keeping those separate means CP/M write compatibility can be debugged without
also debugging FatFs write transport.

---

## 23. Characterization utilities are worth keeping permanently

`BDOSCHAR.COM`, transport stress tools, filesystem tests, and application-level
regressions should remain in the tree.

They are not temporary bring-up tools.

Future changes to:

- ZSDOS
- memory banking
- the facade
- the IOC protocol
- caching
- filesystem backends

can silently violate the same assumptions.

The tools provide executable documentation of those contracts.

---

## 24. Applications are excellent compatibility probes

Several applications revealed different classes of problems:

- DIR exposed synthetic extent/search behavior
- TYPE exercised ordinary sequential reads
- CRC exposed raw directory-search semantics and the `FCB[0]='?'` convention
- VGMPLAYER exercised large sequential reads, explicit-drive FCBs, interrupts,
  and repeated buffering
- ZCD exercised per-drive hierarchy state

No single application was sufficient.

Compatibility testing should deliberately include software with different
access patterns.

---

## 25. Final takeaway

The hardest part of adding FAT-backed drives was not FAT.

FatFs itself was already capable and reliable.

The difficult part was preserving the implicit contracts between:

- CP/M applications
- ZSDOS
- the BIOS
- Zephyr's common/banked memory model
- FCB semantics
- directory search behavior
- the IOC transport

The most useful rule for future OS extensions is:

> Add new implementation beneath the existing compatibility contract whenever
> possible. Characterize the contract before replacing it.

When a strange old program fails, treat it as evidence that the emulation
boundary is incomplete rather than assuming the program is doing something
wrong.

---

## Future additions

Once writable Milestones 5 and 6 are complete, this document should be
augmented with at least:

- the final write-completion / unknown-commit contract
- how CP/M MAKE/CLOSE semantics map onto FAT
- sequential and random write edge cases
- random-write-with-zero-fill behavior
- software write-protect interactions
- media-full and media-removal behavior during mutation
- lessons from the 512-byte FAT deblocking/cache optimization

Milestones 5 and 6 and the deblocking work were completed and validated on
hardware on 2026-09-22. Most of the list above is now covered by sections 26
onward; sections 41-52 add what the writable and performance work taught.
Still not covered by direct experience, because it needs deliberate physical
setup rather than a test case:

- media removal and reinsertion *during* a mutation
- a genuinely full volume, as opposed to an injected no-space status

---

## 26. Writable checkpoint: isolate commit semantics before FCB semantics

The first writable tranche was intentionally stopped at the native API:

```text
FS2 create/open-for-update, write, truncate, sync/close
    -> function 218 native byte API
    -> hardware validation
    -> only then writable CP/M FCB calls
```

This boundary bought a great deal. It exercised the dangerous parts --
Z80-to-IOC bulk transfer, FatFs mutation, completion reporting, stale handles,
write protection and media errors -- without simultaneously debugging CP/M
extent and FCB mutation rules. A checkpoint is useful when it produces an
independently testable vertical slice, not merely when it reduces the diff.

`ZFW.COM` made that slice concrete. It tested fresh and repeatable
create-always, open-for-update, writes at several sizes, readback, sync,
truncate, size reporting, oversized-write rejection, handle exhaustion and
ZSDOS software write protection. The separate `ZFWPROB.COM` narrowed failures
to individual mutating primitives without requiring every earlier step to
succeed.

---

## 27. READY is permission to transfer, not evidence of a write

The writable bulk lifecycle has three distinct events:

```text
WRITE command reply / READY
    -> the IOC has armed a receive buffer

IOCBULKW completes
    -> bytes crossed the link

XFER_STATUS / DONE with the matching transfer ID
    -> FatFs commit callback completed with a known status
```

Neither READY nor a successful `IOCBULKW` proves that FatFs stored the bytes.
The host must always collect DONE, verify that its transfer ID matches the ID
issued by READY, and then inspect the commit status.

If READY was accepted but DONE is lost, malformed, or names another transfer,
the only honest result is `UNKNOWN_WRITE`. The native layer must invalidate
that handle and must not replay the write. Explicit offsets make known retries
idempotent; they do not make an unknown commit safe to replay.

The same uncertainty applies to non-bulk mutations. If the reply to
create-always, truncate, sync or writable close is lost, the operation may
already have changed the filesystem. Transport failure after a mutation is not
automatically equivalent to "nothing happened."

---

## 28. Writable stale handles must not use the read retry policy

A stale read-only handle can be reopened from its saved path identity and the
read attempted once more at the explicit offset. That is safe because reads do
not mutate the file.

The same policy is unsafe for a writable handle. A media-generation change or
unknown completion can leave the file in a state the host cannot reconstruct.
Writable contexts therefore fail stale, are invalidated, and require the
application to reopen and decide how to recover.

Media generation remains useful for card removal and remount while the Z80 is
still running. It should advance when media/FatFs failures invalidate open
contexts. It is not an MCU-session protocol: an MCU reset resets the whole
machine, so inventing a recoverable MCU nonce would model a state that cannot
actually occur.

---

## 29. Software and physical write protection are separate authorities

FatFs reports physical or filesystem-level read-only conditions. ZSDOS owns
the CP/M software write-protect vector. Both must be honored.

The bank-7 FAT layer keeps only a mirror of the ZSDOS vector. The mirror is
refreshed after the ZSDOS calls that reset, set or query write protection, and
native mutation checks the configured FAT-drive bit before issuing an FS2
mutation. Protecting or resetting disks also closes/invalidate outstanding
writable contexts so an old handle cannot bypass a newly asserted policy.

Do not encode ZSDOS software protection as a FAT attribute and do not infer it
from FAT metadata. They are deliberately independent mechanisms.

---

## 30. Crossing code must validate lengths before `LDIR`

Native WRITE exposed the one part of the implementation that genuinely had to
grow in common memory. An application buffer in the banked window disappears
when bank 7 is selected, so outbound bytes must be copied into the existing
common 512-byte staging buffer before the crossing. The filesystem protocol,
policy and persistent state still belong in bank 7.

The common helper must validate the caller's length before copying. In
particular, this Z80 behavior is dangerous:

```text
BC = 0
LDIR
```

It does not copy zero bytes. BC wraps and the instruction copies 65536 bytes,
walking across the address space and corrupting the resident OS. Zero-length
and greater-than-512-byte requests must be rejected or skipped before `LDIR`.
The same guard is required when delivering a zero-byte READ result.

This is a broader rule for bank-crossing facades: validate pointer/count pairs
while the caller mapping is visible, keep the common code purely mechanical,
and perform all semantic validation again in the bank-7 implementation.

---

## 31. Reuse the proven bulk lane and advertise capability explicitly

The existing `/SHARED` writer had already established the correct shape:
receive into the shared 512-byte buffer, commit through a callback, and expose
the final result through DONE. Reusing that lane was safer than creating a
second write transport.

Writable FS2 support was added additively to the version-1 command range. The
capability reply, rather than a guessed firmware version, tells a client
whether WRITE and TRUNCATE exist. A hardware diagnostic should query that bit
before sending a command that older firmware will not admit; otherwise a
missing feature looks like a hung transport.

This combination -- additive commands, explicit capability bits and a small
end-to-end diagnostic -- made the first writable checkpoint independently
flashable and testable while ordinary FAT-backed BDOS mutation remained out of
scope.

---

## 32. Final SEARCH characterization was simpler than physical CP/M emulation

Sections 6 and 16 record useful intermediate reasoning, but hardware
characterization and application testing refined the final contract. The
accepted FAT SEARCH result does not need four meaningful directory slots or a
sequence of synthetic physical extents.

For each match, the final implementation uses:

```text
DMA[0..127] = E5h
DMA[0..31]  = one synthetic directory entry
A           = 00h
```

On exhaustion:

```text
A           = FFh
DMA         = unspecified
```

The entry needs correct observable metadata only:

- USER
- seven-bit-clean 8.3 name
- zeroed CP/M attribute bits, because FAT HIDDEN/SYSTEM/ARCHIVE are deliberately
  not projected
- EX, S1, S2 and RC
- zero allocation bytes

Emitting several entries for a large FAT file made ordinary `DIR` display the
same filename repeatedly. The accepted representation emits one entry per FAT
file and puts the terminal logical extent in EX/S2/RC. Function 35 remains the
authority for the complete rounded-up record count.

This is a useful restraint:

> Reproduce the observable directory contract, not a fictional physical CP/M
> allocation layout that has no meaning on FAT.

The hardware-accepted result showed `SONG.ZVG` once, while CRC still recovered
and processed the whole large file.

---

## 33. Raw all-USER SEARCH is a mode, not a malformed drive

The final CRC fix required more than recognizing `FCB[0] = '?'` as the current
drive. That value selects a raw directory-search mode whose continuation spans
all supported USER namespaces.

The dispatcher must therefore capture, on function 17:

- effective drive = current drive
- USER filter = wildcard
- first USER = 0
- final USER = 15 on this ZSDOS build

Function 18 must retain that mode, finish the current directory, skip missing
`@N` directories, advance through USER 15, and put the source USER in each
synthetic entry.

If function 17 falls through to ZSDOS, ZSDOS searches the deliberately empty
synthetic disk and CRC quietly builds an empty list. That exact failure prints
only the CRC banner, which made the disassembly of CRC's catalogue-building
path especially valuable.

ZSDOS remains authoritative for USER. The facade mirrors successful function
32 changes and the FAT layer consumes that mirror; it does not call back into
ZSDOS merely to ask for USER on every file operation. This keeps authority
clear without adding avoidable coupling.

The supported range must come from the running OS rather than a generic CP/M
assumption. This system has USER 0 through 15, not USER 31.

---

## 34. USER must precede the relative FAT current directory

The accepted resolver order is:

```text
/CPM/D/@N/<relative-CWD>/<name>
```

with USER 0 omitting `@0`:

```text
/CPM/D/<relative-CWD>/<name>
```

Putting the current directory before `@N` makes a directory visible in D8:
impossible to select consistently from D8:. The USER namespace is the root of
that logical CP/M view; hierarchy lives beneath it.

The saved relative directory is tagged with the USER that selected it. A
directory selected for USER 8 must not silently become the current directory
for USER 14. When a utility targets `D8:` from another drive/USER, it
temporarily selects USER 8 for the native operation and restores the caller's
USER afterward.

FS2 itself remains a neutral component resolver. The bank-7 native/FCB layer
decides when to prepend the CP/M drive and USER projection.

---

## 35. Fixed-size path components need boundary tests at 9/10 and 15

USER components are packed into an exact 11-byte 8.3 field. The first version
formatted both one- and two-digit USER values with the same number of trailing
spaces. `@10` through `@15` therefore wrote twelve bytes and overwrote the next
persistent-state byte, which happened to be the current-directory count.

That single-byte overwrite produced failures far away from the formatter:
directory selection appeared unreliable and later path replay used a nonsense
component count.

The lesson applies beyond USER names:

> For packed protocol and filesystem fields, test the first value that changes
> width, the maximum accepted value, and the byte immediately after the field.

The all-USER CRC regression was useful here because it automatically exercised
USER 10 through 15 and could detect corruption of adjacent current-directory
state.

---

## 36. SELDSK tests drive availability, not the current subdirectory

After a successful `ZCD` in USER 8, selecting D: could still fail with:

```text
ZSDOS error on D: No Drive
Call: 14
```

The synthetic `SELDSK` probe was replaying the saved relative directory without
the USER component. It tested `/CPM/D/TESTDIR` even though the selected path was
`/CPM/D/@8/TESTDIR`, then returned a null DPH.

The corrected responsibility is narrower:

```text
SELDSK D: validates /CPM/D and returns the synthetic DPH
file/native operations resolve USER and CWD beneath that root
```

A missing, renamed or USER-specific subdirectory must not make the entire
logical drive disappear. Keeping availability, login geometry and path
resolution separate also makes ZSDOS error reports much easier to interpret.

---

## 37. A crossing gate must preserve the semantic return value

Function 218 completed CHDIR successfully in bank 7, wrote status zero into
the descriptor, and then appeared to fail in the application.

The common gate used A to distinguish READ from non-READ while deciding whether
to copy staged payload data. That mechanical dispatch overwrote the status
returned by bank 7 with the operation number. CHDIR therefore returned `09h`,
and ZCD printed `Cannot select directory` even though the directory had already
changed.

The gate now preserves AF across its copy dispatch and returns the original
bank-7 status. This also reinforced two rules:

- test both the returned register value and the copied descriptor status
- test the complete application-to-bank-7 path, not only the bank-7 worker

The fix had to fit the existing common crossing region. `PUSH AF`/`POP AF`
used its last two bytes without moving any boundary; the generated memory map
now reports the 62-byte native gate exactly full.

---

## 38. ZCPR transient return and DU parsing are part of utility correctness

ZCPR2 invokes a transient with `CALL 0100h`. ZCD replaced SP with a private
stack and originally ended with `RET` without restoring the entry SP. It popped
bytes from the code following its private stack, printed a stray `ZCD?`, and
eventually returned with an apparently arbitrary drive/USER.

Jumping to page zero avoided the bad return but forced an unnecessary warm
boot. The correct ZCPR behavior is:

```text
save entry SP
use private stack
restore entry SP
RET
```

ZCPR then performs its normal post-program cleanup and restores the command
processor context without a warm boot.

Argument parsing had two further traps:

- A bare command is identified reliably by the command-tail length at 0080h,
  not by assuming a particular sentinel in the default FCB.
- ZCPR puts the parsed drive and 8.3 name in the default FCB, but the USER from
  a `DU:` prefix remains in ZCPR-private temporary state.

ZCD therefore parses USER 0 through 15 from the untouched command tail,
temporarily applies it through BDOS function 32, performs function 218, and
restores the original USER. This makes command-location and operation-target
independent:

```text
B0:ZCD D8:TESTDIR
B0:ZCD D8:
```

The utility can eventually reside on ROM drive A: and still target any
supported FAT USER namespace without changing the shell's permanent drive or
USER.

---

## 39. A reported failure may follow a successful state change

The ZCD episode combined two independent defects:

1. CHDIR succeeded, but the gate returned the operation number as an error.
2. The now-changed CWD made the next flawed SELDSK probe return no DPH.

The visible sequence looked like one failed command followed by a damaged
drive. In fact, the command had mutated state successfully and only its status
report was wrong; the later login failure came from consuming that new state
incorrectly.

When a state-changing command reports failure, diagnostics should separately
check:

- whether the operation executed
- whether state changed
- whether completion status crossed the boundary intact
- whether the next consumer interprets the new state correctly

This distinction will be even more important for writable operations, where a
false failure can tempt an unsafe retry.

---

## 40. Acceptance needs asymmetric cross-drive and application-level cases

The read-only milestones were accepted on hardware on 2026-09-22 with a matrix
that deliberately exercised both directions of drive crossing:

- `DIR`, `TYPE` and CRC on a small FAT file
- CRC and uninterrupted VGMPlayer playback on a large FAT file
- VGMPlayer reading `D8:SONG.ZVG` while B: was current
- VGMPlayer reading `B8:SONG.ZVG` while D: was current
- `ZCD`, `DIR` and CRC inside a FAT subdirectory, followed by return to the
  expected parent/root view
- USER 1 `/CPM/D/@1` isolation followed by restoration of USER 0
- `DIR`, `TYPE` and CRC again on conventional B:

The two explicit-drive cases are not redundant. One validates FAT dispatch
while another backend is current; the other validates conventional ZSDOS I/O
and restoration while the synthetic FAT drive is current.

The one-level `ZCD ..` acceptance case proved restoration of the expected view
from the tested subdirectory. It should not be overinterpreted as exhaustive
proof of arbitrary-depth parent normalization or root-containment behavior.

The detailed accepted command suite is recorded in
`Code/HOST/CPM2.2/docs/fat-read-only-milestones2-4.md`.

---

## 41. `LDIR` with a computed count of zero moves 65536 bytes

The writable milestone recorded the path identity of each native handle so a
stale token could be reopened. The relative directory depth was multiplied by
the component size and used directly:

```text
BC = depth * 11
LDIR
```

At the drive root the depth is zero, and the Z80 decrements `BC` *before* it
tests it. A zero count is therefore not "copy nothing" but "copy 65536 bytes",
which walked the component array over the entire address space and took bank 7
— with the operating system resident in it — with it. The machine froze hard
on the first native `OPEN` issued from the drive root, which is the ordinary
case.

Section 30 covers validating a *caller's* length before a block move. This is
the other half: a length the OS computes for itself can also be zero, and the
zero case is the one that does not look like an error at the call site.

Two details make this worth remembering beyond the specific bug:

- The routine that *read* the same structure back already guarded correctly
  (`ld a,b / or a / jr z,...`). Only the routine that *wrote* it did not. When
  one side of a paired reader/writer has a guard and the other does not, that
  asymmetry is the defect, not a style difference.
- Every other block move in the file used a constant count. Auditing for
  "which `LDIR` has a computed count" found exactly one candidate in about a
  minute, and is a cheap sweep to repeat after any change that introduces one.

---

## 42. A comparison before a conditional return destroys the flags it tests

Native reads returned status 0 and zero bytes, for every file, on every drive,
in both read and write modes. The cause was three instructions:

```text
    call fat_fs2_read
    cp   #FS2_STATUS_STALE      ; sets the flags from the CP
    jr   nz,fat_native_read_result
    ...
fat_native_read_result:
    jp   nz,fat_native_return   ; tests the CP, not the result
```

On success `A` is 0, so the stale comparison sets NZ, and the success path
returned immediately — skipping the block that stored the transferred count
and advanced the file position. Errors happened to work, because they are also
NZ. The genuine stale case worked, because it is Z. Only the normal path was
broken.

The general rule is that a status register is not a variable: any comparison
between producing a result and branching on it discards the result. The
practical detection is cheaper than the rule, though — **the sibling routines
all re-tested with `or a` and this one did not.** `sync`, `truncate` and
`open` each did the same stale-or-transport check and each restored the flags
before branching. When four routines share a shape and one differs, look at
the one that differs before looking anywhere else.

---

## 43. Two personalities over the same files need two sets of tests

The read-only milestones were accepted with `DIR`, `TYPE`, CRC and VGMPlayer.
All four reach files through the CP/M FCB path. Nothing in that suite — and
nothing in the bank-7 test harness, which exercised `fat_native_entry` only
with `ZCHDIR` — ever called native `OPEN`, `READ`, `WRITE` or `SEEK`.

Three defects lived in that gap: the zero-count `LDIR` of section 41, the
clobbered flags of section 42, and a buffer aliasing bug covered below. All
three were present and undetected through an entire accepted milestone.

The architectural claim of this design is that CP/M FCB access and the native
byte API are two views of the same files. That claim cuts both ways: it means
**neither view's test coverage substitutes for the other's**, even though they
share a transport, a resolver and a handle pool underneath. The native API had
no consumer other than a directory-changing utility, so it had no coverage, so
it had bugs.

The concrete rule adopted afterwards: adding a native operation means adding a
case to the bank-7 harness in the same change. That harness drives bank-7
routines directly in an emulator and would have caught all three in seconds.

---

## 44. A test harness must model the address aliasing the real path has

Function 40 (write random with zero fill) writes zero records across the gap
it skips, then writes the caller's record. It passed every harness test and
failed on hardware, writing the caller's record as zeros.

The reason is one line in the memory map:

```text
FAC_DMA_BUF = FAC_BULK_BUF
```

When an application's DMA sits in the TPA it is hidden under bank 7, so the
facade stages the record into `FAC_DMA_BUF` — which *is* the common bulk
buffer that the gap fill then writes zeros through. The record was destroyed
before it was ever sent, and the subsequent copy to the bulk buffer became a
copy of that buffer onto itself.

The harness never saw it because it called the bank-7 routines directly with a
scratch DMA at a distinct address. That is a faithful model of the *interface*
and an unfaithful model of the *machine*: on real hardware the aliased case is
not an edge case, it is the normal path.

The fix in the code was to stage the caller's record into bank 7 before the
gap fill. The fix in the harness was to add a second case with the DMA
pointing at `FAC_BULK_BUF`, which is now the case that fails if the staging is
removed. Plain `WRITE` was never affected, because its copy to the bulk buffer
is a copy onto itself and changes nothing — which is exactly why only one of
the three write functions misbehaved.

---

## 45. Mutation-test the assertions, not just the code

The first version of the zero-fill test asserted that the skipped gap read
back as zeros. It passed. It also passed with the entire zero-fill
implementation deleted.

The mock extended a file with `resize(n, 0)`. FatFs extends a file by
allocating clusters that hold whatever was previously on the card. The model
was therefore zero-filling the gap itself, and the assertion could not
distinguish an implementation that zeroed it from one that did not.

Changing the fill value to `0xCC` made the test fail with the implementation
removed and pass with it present. The same technique — delete the behaviour,
confirm the test notices — was then applied to every new assertion in the
session and caught a second worthless test immediately.

For a guarantee expressed as "this region reads back as X", the model must
produce **not-X** by default. A model that defaults to the expected value
cannot test the guarantee, however carefully the assertion is written.

---

## 46. Run the compatibility suite on a conventional drive too

The FCB-level acceptance utility uses only standard BDOS calls, so it runs on
any drive. Running it on a conventional CP/M volume found three defects — all
three in the *test*, none in either drive:

- **A random write that was never closed.** CP/M records a file's new length
  in the directory at `CLOSE`, not at write. The FAT personality opens, writes
  and closes per record, so it commits immediately and masked the omission.
  The conventional drive reported the stale length and was right to.
- **An over-specified contract.** Function 40 zero-fills a *previously
  unallocated block*, not an arbitrary gap. A gap inside a block that was
  already allocated legitimately holds old data. The test demanded more than
  CP/M promises, and the FAT implementation happened to provide it.
- **A write-protect case that cannot pass.** On a conventional drive a
  protected write reaches ZSDOS, which raises its own `Bdos Err ... R/O`,
  takes the console and ends the program. It never returns a code to test.

The general value is that a cross-drive suite turns "does this work" into
"does this differ", and a difference is a far sharper signal than a failure.
When the FAT drive failed a check the conventional drive passed, the fault was
localised to the FAT path immediately; when both failed identically, the
expectation itself was wrong.

The third finding is also a real compatibility difference worth deciding
deliberately: the FAT personality intercepts above ZSDOS and returns a failure
code where a conventional drive raises a BDOS error. Friendlier, but not what
CP/M documents, and a program relying on the error will behave differently on
the two drive types.

---

## 47. ZSDOS software write protection can be configured to survive every reset

Section 29 establishes that software and physical write protection are
separate authorities. There is a further wrinkle: in this build the software
one cannot be cleared by the functions that are supposed to clear it.

`zsdos.lib` ships `FLGBITS EQU 01101101B`, and bit 2 is "Read-Only Enable".
`CMND37` in `zsdos.z80` — which serves **both** function 13 and function 37 —
tests that bit and skips the write-protect clear entirely when it is set:

```text
CMND37: CALL UNLOG
        LD   A,(FLAGS)
        BIT  2,A        ; Test hard R/O enabled
        JR   NZ,UNWPT1  ; If enabled -- skip the DSKWP clear
        LD   HL,DSKWP
        CALL ANDDEM
UNWPT1:
```

So once a drive is write-protected, neither reset function clears it, and
neither does a warm boot. Only a cold boot. This is ZSDOS working as
configured, not a fault, and not something the FAT backend's mirror is doing
wrong — the mirror reads function 29 faithfully and reports exactly what ZSDOS
reports.

Two consequences:

- A diagnostic that sets write protection will poison the machine until a
  power cycle unless it clears it deliberately. The documented route is BDOS
  100 (Get Flags), clear bit 2, BDOS 101 (Set Flags), function 37, then
  restore the original flags byte. `ENTRY` folds functions 98-103 into the
  command table via `SUB 98-MAXCMD`, which is why 100 and 101 are the flags
  calls.
- While debugging, a sticky protection bit looks exactly like a stale mirror
  in the FAT backend. Asking ZSDOS directly through function 29 is what
  separates the two, and is worth doing before suspecting the mirror.

---

## 48. `.ds` reserves space but does not zero it

The reclaimable pool allocator was given a thirteen-byte owner table declared
with `.ds 13`. In the assembled image those bytes were `FFh`, not zero, so
every line read as already owned, every lease was refused, and the read cache
was permanently disabled.

There was no symptom other than being slower than expected — the fallback
read-through path is correct, which is precisely why a refused lease produces
no visible failure. The cache had a complete implementation, complete tests
and no effect.

State that a routine *reads before writing* must be initialised explicitly
(`.db 0,0,...`), not merely reserved. Reserved space carries whatever fill the
image build produces. The dangerous version of this bug is the one here: a
design that deliberately tolerates the resource being unavailable will
tolerate it being unavailable permanently and by accident.

---

## 49. A protocol addition must move the firmware level

The writable FS2 commands `3Dh`-`40h` were added to the frame header, the
dispatcher and the admission list, but `IOC_FW_LEVEL` was left at 73.

`ioc_levels.inc` exists specifically so a stale tool reports a mismatch
instead of misbehaving, and its own header records that five programs once
expected a level the firmware had moved past. Not bumping it made a controller
that predates the writable commands indistinguishable from one that has them —
and a controller that does not admit a command drops the frame rather than
refusing it, which presents to the host as a hang.

During the first hardware failure of the writable path, "is the controller
running the firmware I think it is" could not be answered from the machine.
It cost a round of investigation down a path that turned out to be unrelated.

The rule: a command range added to `ioc_frame.h`, `dispatch.c` and
`external_sync.c` is a fourth edit, not three — the level moves with it, in
both `ioc_frame.h` and `ioc_levels.inc`.

A related gap in the same area is worth recording: the host issues writable
commands without ever reading the FS2 capability word, so it cannot tell a
controller that lacks them from one that is not answering. The capability
query exists (`CMD_FS2_CAPS`) and the flags are already defined; nothing
consults them.

---

## 50. Round trips, not block size, were the cost

Section 20 says performance problems should be solved at the right abstraction
level and section 21 says correctness comes first. With correctness complete,
the measurement was unambiguous. Counting controller transactions for a 64 KiB
sequential read through the FCB path:

```text
before deblocking       per 512-byte line: 6 mailbox + 1 bulk
                        ROOT, PUSH, PUSH, OPEN, READ, CLOSE, transfer
after a 512-byte line   3 opens for 9 records instead of 9
after a cached handle   132 transactions for 64 KiB, from 768
                        per line: 1.03 mailbox + 1 bulk
```

Only one of the original seven transactions moved data. The other six
re-resolved the path and reopened the file for every 512 bytes, because the
compatibility layer opened and closed per record by design — a decision that
is right for correctness and very expensive for throughput.

Two conclusions that were not obvious before measuring:

- **A larger deblocking line was the wrong lever.** The controller's transfer
  ceiling is 512 bytes, so a 2 KiB line still costs four transfers; it only
  amortises the five setup transactions. Caching the open handle removes them
  entirely and reaches the same cost per byte as the tools that bypass the
  FCB interface altogether.
- **The remaining gap is CP/M's, not FAT's.** With the handle cached, the FAT
  drive and the conventional drive read the same 125 KB file in the same time.
  CP/M's 128-byte record means four BDOS crossings per 512 bytes, each staging
  an FCB in, the DMA out and the FCB back. That is a ceiling both drive types
  share, and it is why a byte-oriented native reader is faster on the same
  file than any FCB-based one can be.

A smaller finding from the same measurement: the record delivery path filled
the caller's buffer with `1Ah` and then overwrote all of it, two 128-byte
`LDIR`s where one would do. Copying first and padding only the short tail cut
the per-record host work by 28%.

---

## 51. Caching a handle is a lease against a pool someone else uses

The handle cache holds one of the controller's two file slots between reads.
That is sound — the design states that IOC handles are opportunistic and the
FCB is authoritative — but it changes an invariant that tests and other code
paths had quietly relied on.

Three interactions had to be handled explicitly:

- **The controller retires every file slot on a namespace mutation**, because
  FatFs will not police an unlink or rename of a file something still holds
  open. A cached token can therefore die underneath its owner. A read that
  fails with no-handle or stale reopens once and retries; a second failure is
  a real error, not a stale handle.
- **Holding a slot can starve another caller.** Every mutation point and every
  native open now hands the slot back first, rather than letting the other
  side fail for a reason it cannot diagnose.
- **A failed close still clears the tag first.** Believing you own a handle
  the controller has already discarded is worse than owning none.

The test invariant changed from "zero slots held after every record" to "at
most one, and a flush returns it", with an explicit case asserting the flush.
The first version of the change failed that old assertion, which is the
correct outcome: an invariant that a deliberate design change invalidates
should be restated, not relaxed.

---

## 52. Two CP/M parsing details that utilities must know

Both were found while building ordinary file tools over the FAT personality,
and both are invisible until a specific case is tried.

**The CCP hands a transient eleven spaces for `..`.** The CP/M name parser
stops the name field at the first `.`, so `CD ..` and a bare `CD` are
identical in FCB1. A directory-changing utility that reads only the FCB cannot
tell them apart, and since an empty name selects the root, `CD ..` silently
jumps home instead of stepping up. From one level deep the two are the same
place, so the behaviour looks correct and only diverges at depth two —
exactly the caution section 40 recorded about not overinterpreting a one-level
`ZCD ..` acceptance case. The untouched command tail is the only place the two
can still be distinguished; `..` cannot be smuggled through the name field.

**A copy utility must refuse to copy a file onto itself.** `MAKE` truncates
the destination, so `CP FILE FILE` empties the file and then reads back what
it just emptied, destroying it and reporting success. The check needs both
forms: identical drive and name, and the implied case where the destination
names only a drive that happens to be the source's. The related ordering rule
for a move is that the delete goes last, after a successful close, so any
failure earlier leaves the original where it was.

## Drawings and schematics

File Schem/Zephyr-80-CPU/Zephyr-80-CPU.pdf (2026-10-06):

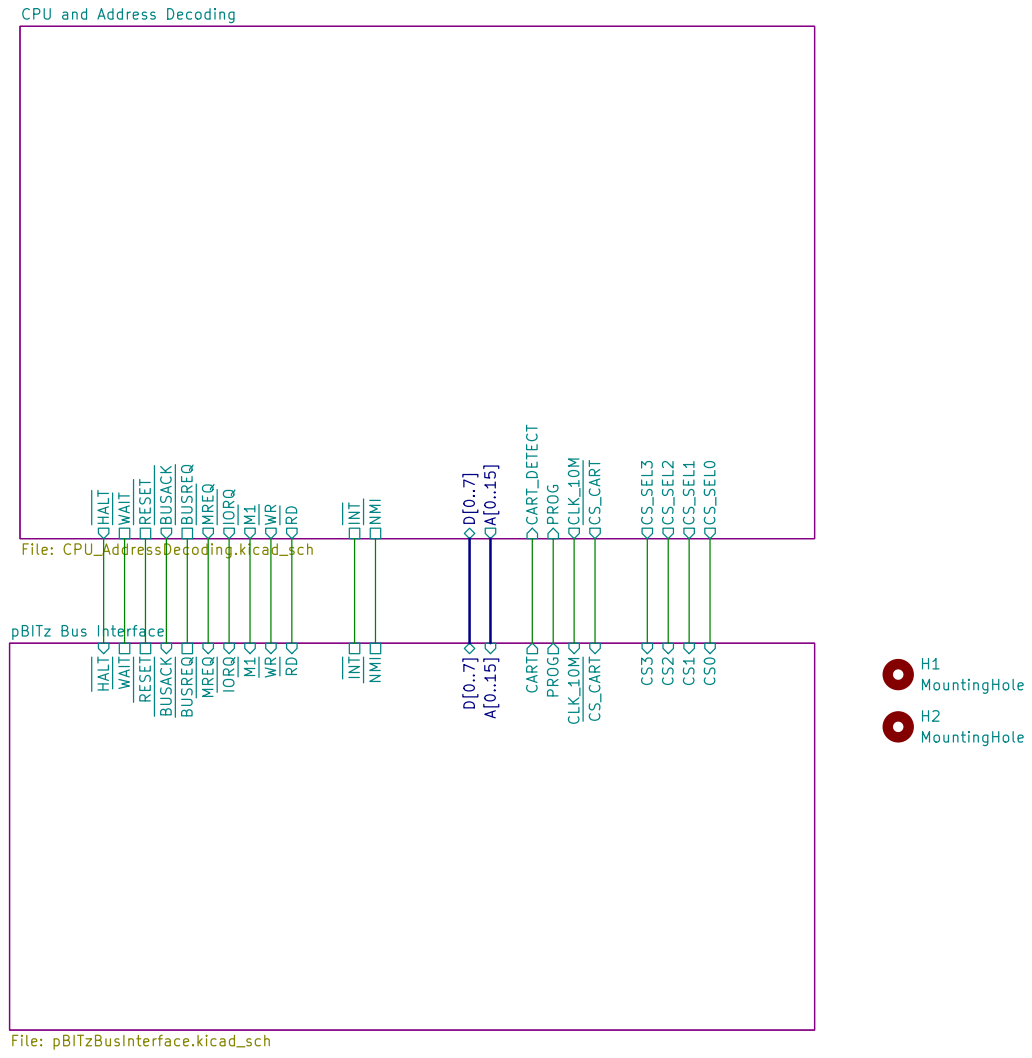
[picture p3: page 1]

Size: A4 | Rev:
KiCad E.D.A. 10.0.6 | Id: 1/3

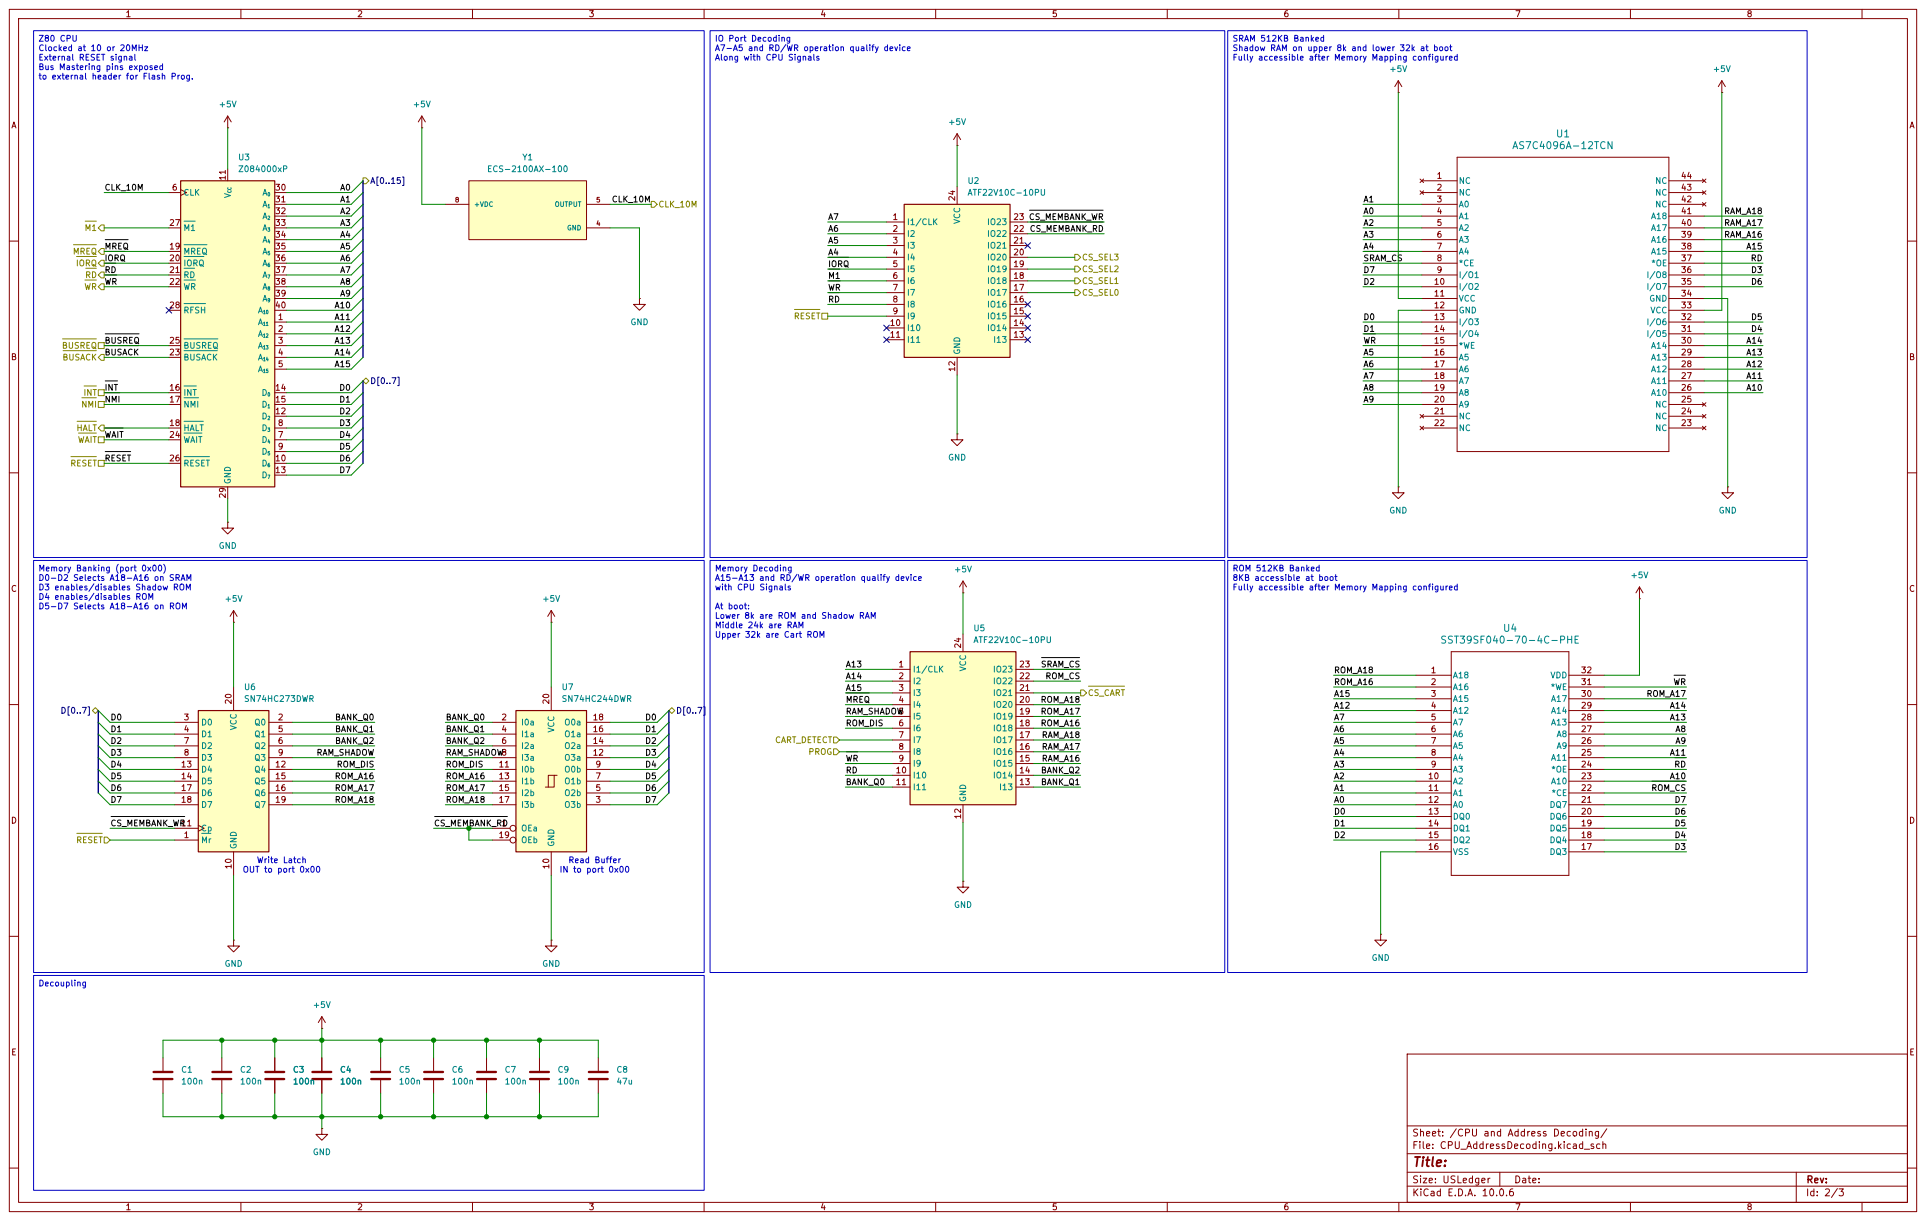
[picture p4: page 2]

Along with CPU Signals Z80 CPU
Clocked at 10 or 20MHz External RESET signal Bus Mastering pins exposed
A5 CS_MEMBANK_WR

IO Port Decoding
A7-A5 and RD/WR operation qualify device

SRAM 512KB Banked Shadow RAM on upper 8k and lower 32k at boot Fully accessible after Memory Mapping configured

to external header for Flash Prog.

VCC 11 D2 12 D7 13 D0 14 D1 15 INT 16 NMI 17 HALT 18 MREQ 19

ATF22V10C-10PU
Sheet: /CPU and Address Decoding/ GND 12 VCC 24

VCC 11 GND 12 | 33 GND | GND

INT BUSACK NMI BUSREQ

Memory Banking (port 0x00) D0-D2 Selects A18-A16 on SRAM

Memory Decoding
A15-A13 and RD/WR operation qualify device with CPU Signals At boot: Lower 8k are ROM and Shadow RAM

D3 enables/disables Shadow ROM
D4 enables/disables ROM
D5-D7 Selects A18-A16 on ROM

Middle 24k are RAM
Upper 32k are Cart ROM

Decoupling

Size: USLedger | Rev:

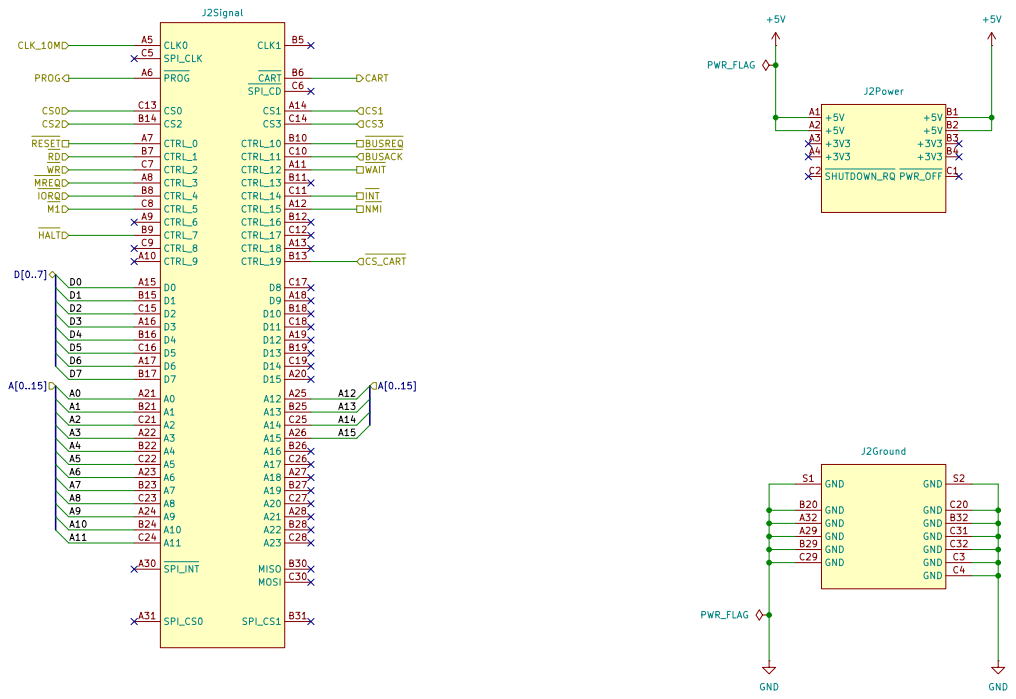
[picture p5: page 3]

Sheet: /pBITz Bus Interface/
File: pBITzBusInterface.kicad_sch
Title:

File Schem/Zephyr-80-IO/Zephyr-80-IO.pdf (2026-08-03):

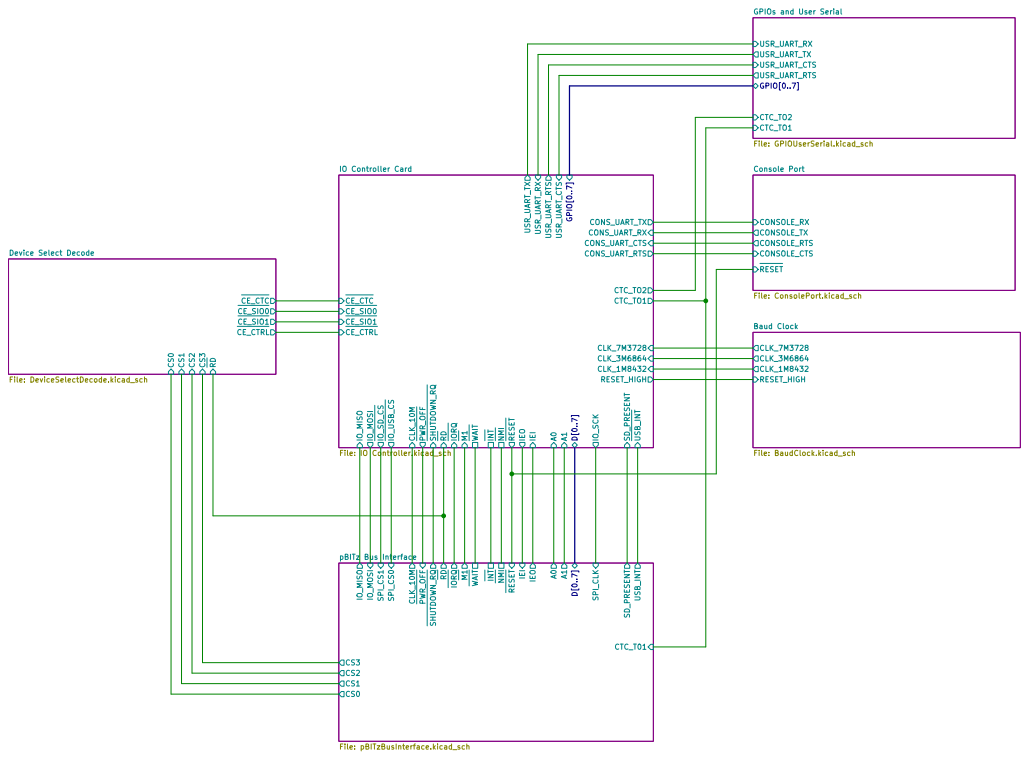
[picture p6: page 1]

CONSOLE_CTS CONSOLE_TX CONSOLE_RX RESET CONSOLE_RTS Console Port File: ConsolePort.kicad_sch USR_UART_CTS CTC_TO2 USR_UART_TX USR_UART_RX CTC_TO1 GPIO[0..7] USR_UART_RTS GPIOs and User Serial File: GPIOUserSerial.kicad_sch RESET_HIGH

Sheet: /
File: Zephyr-80-IO.kicad_sch
Title: Zephyr-80 IO Controller

Size: D | Rev: 0.1
KiCad E.D.A. 10.0.5 | Id: 1/7

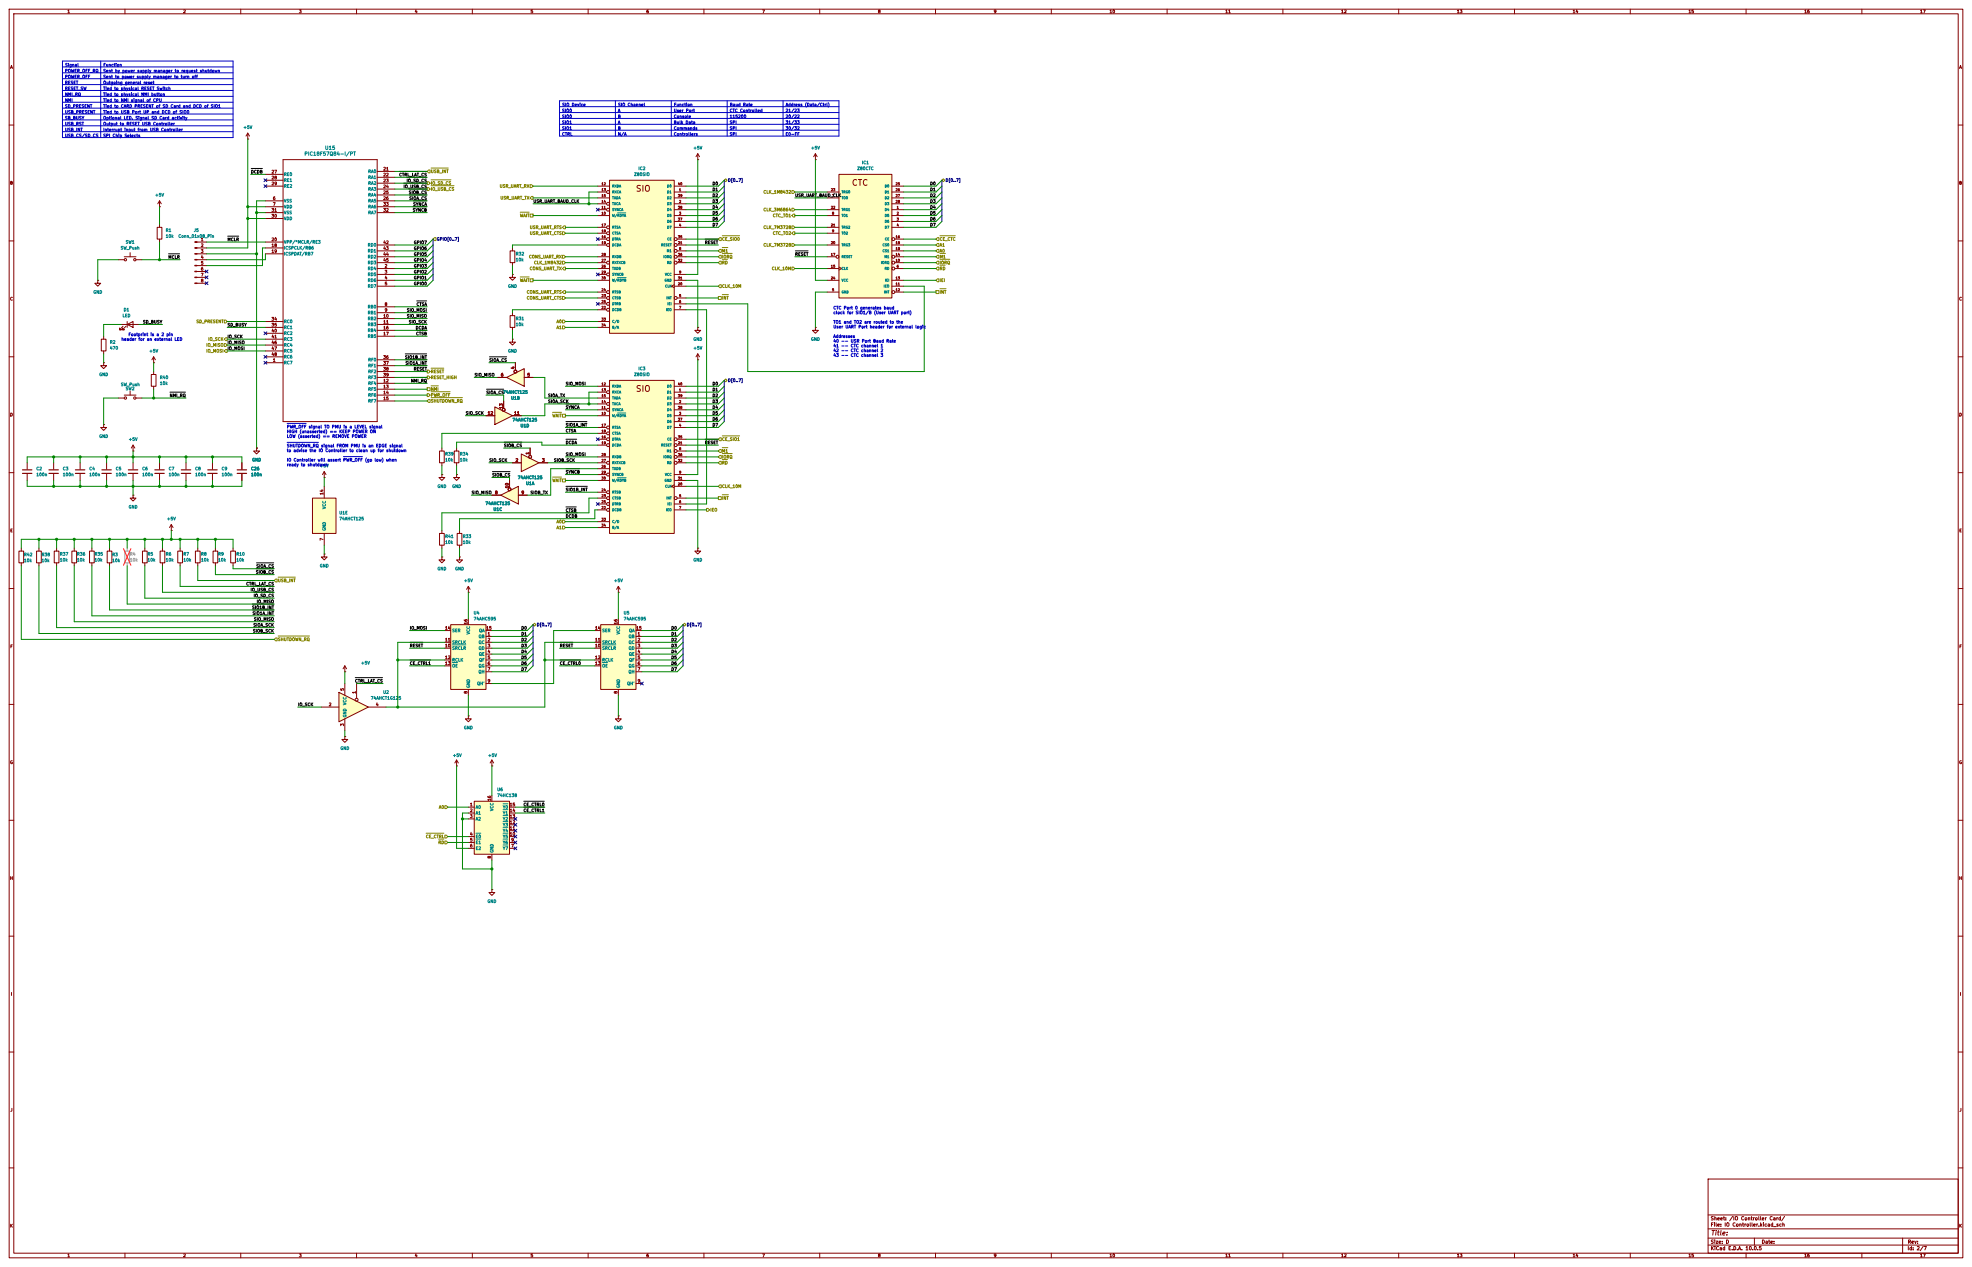
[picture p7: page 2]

SD_PRESENT | Tied to CARD PRESENT of SD Card and DCD of SIO1 USB_PRESENT Tied to USB Port UP and DCD of SIO0

SIO Device | A SIO Channel | User Port Function | CTC Controlled Baud Rate | 21/23 Address (Data/Ctrl) SIO0

SIO0 | B | Console | 115200 | 20/22
SIO1 | A | Bulk Data | SPI | 31/33

CTC Port 0 generates baud clock for SIO1/B (User UART port) TO1 and TO2 are routed to the User UART Port header for external logic

Footprint is a 2 pin header for an external LED

Addresses 40 -- USR Port Baud Rate 41 -- CTC channel 1

LOW (asserted) == REMOVE POWER

SHUTDOWN_RQ signal FROM PMU is an EDGE signal to advise the IO Controller to clean up for shutdown

IO Controller will assert PWR_OFF (go low) when
ready to shutdown

SRCLR 10 SRCLK 11 RCLK 12 OE 13

Sheet: /IO Controller Card/
File: IO Controller.kicad_sch
Title:

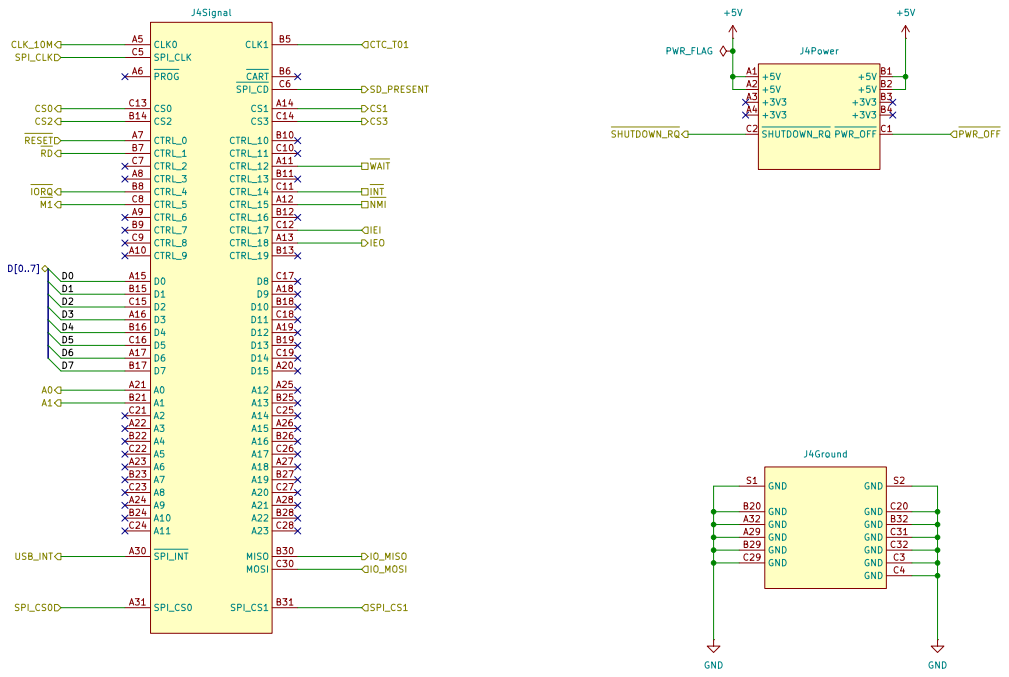
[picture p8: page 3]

Sheet: /pBITz Bus Interface/
File: pBITzBusInterface.kicad_sch

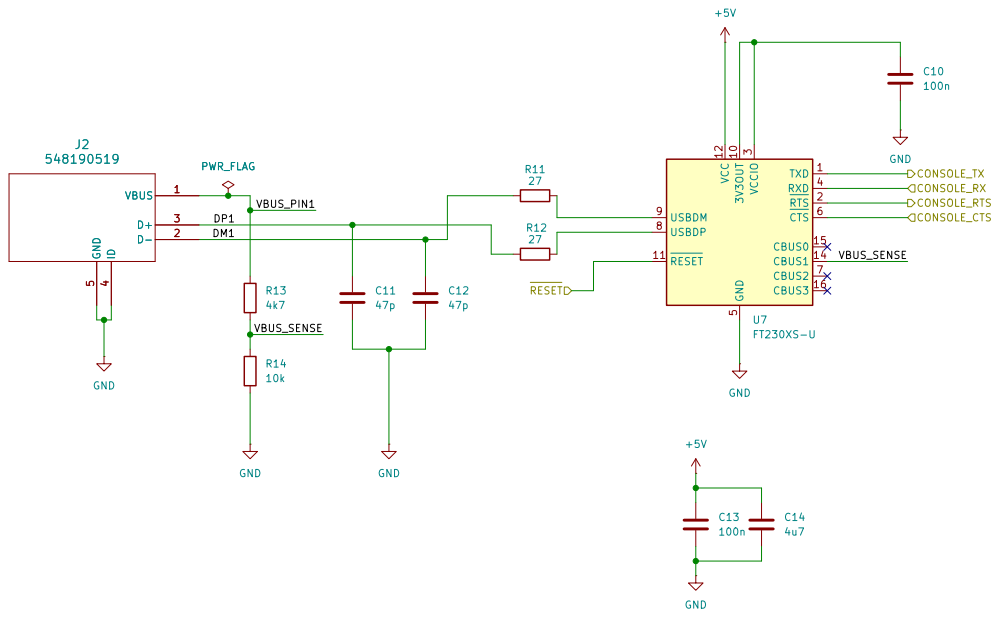
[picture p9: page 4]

5 CTS 6 CBUS2 7 USBDP 8 USBDM 9 3V3OUT 10 RESET 11 VCC 12 CBUS1 14 CBUS0 15 CBUS3 16 U7

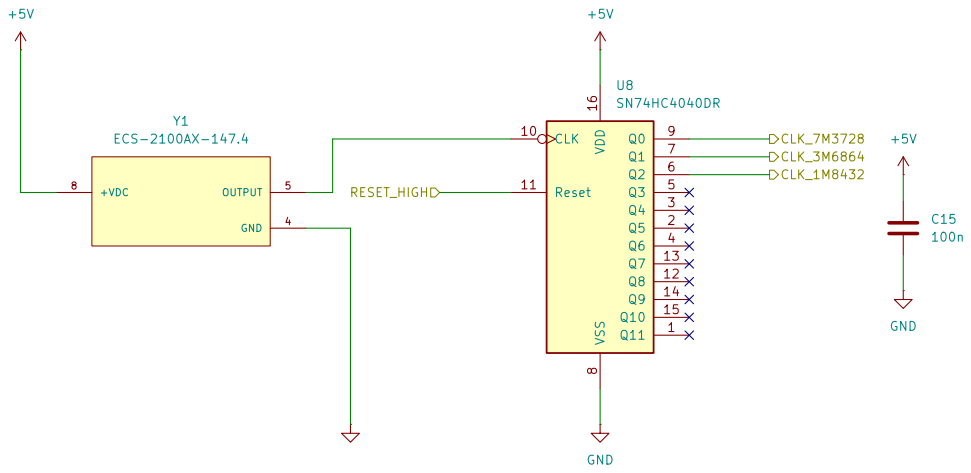
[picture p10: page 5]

Sheet: /Baud Clock/
File: BaudClock.kicad_sch
Title: Baud Rate Generator

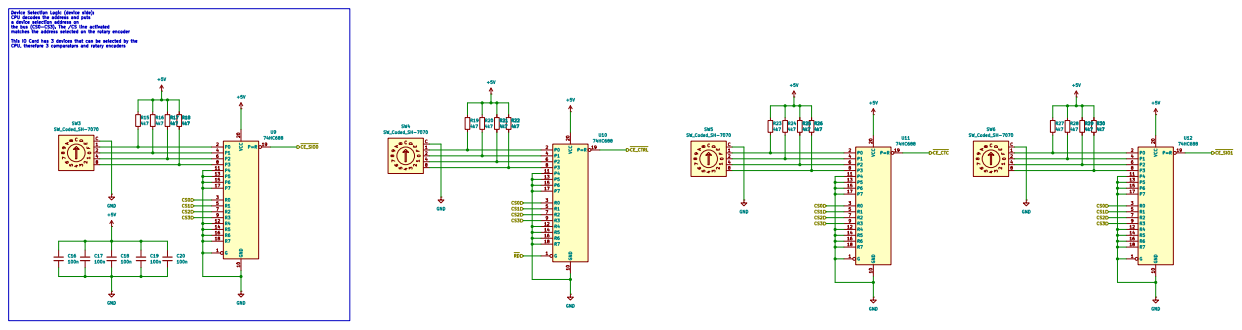
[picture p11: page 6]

Sheet: /Device Select Decode/
File: DeviceSelectDecode.kicad_sch

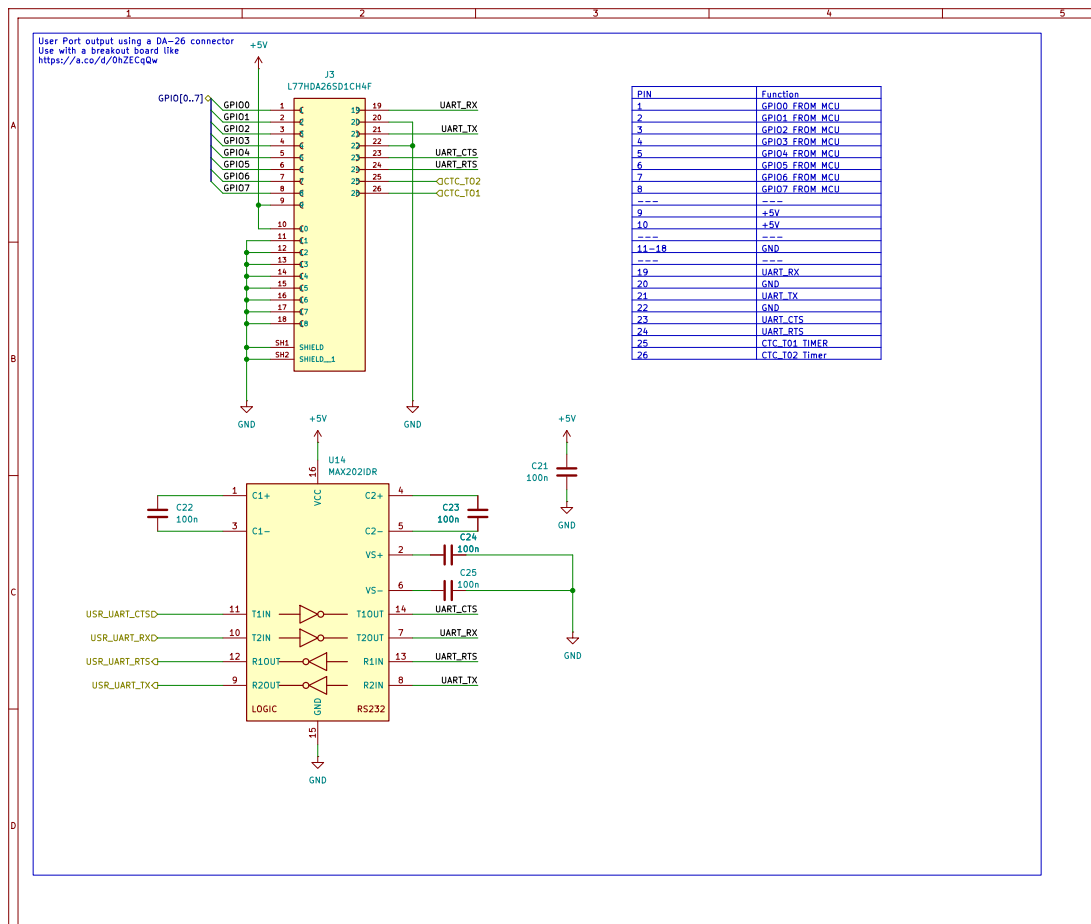
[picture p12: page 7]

Sheet: /GPIOs and User Serial/
File: GPIOUserSerial.kicad_sch

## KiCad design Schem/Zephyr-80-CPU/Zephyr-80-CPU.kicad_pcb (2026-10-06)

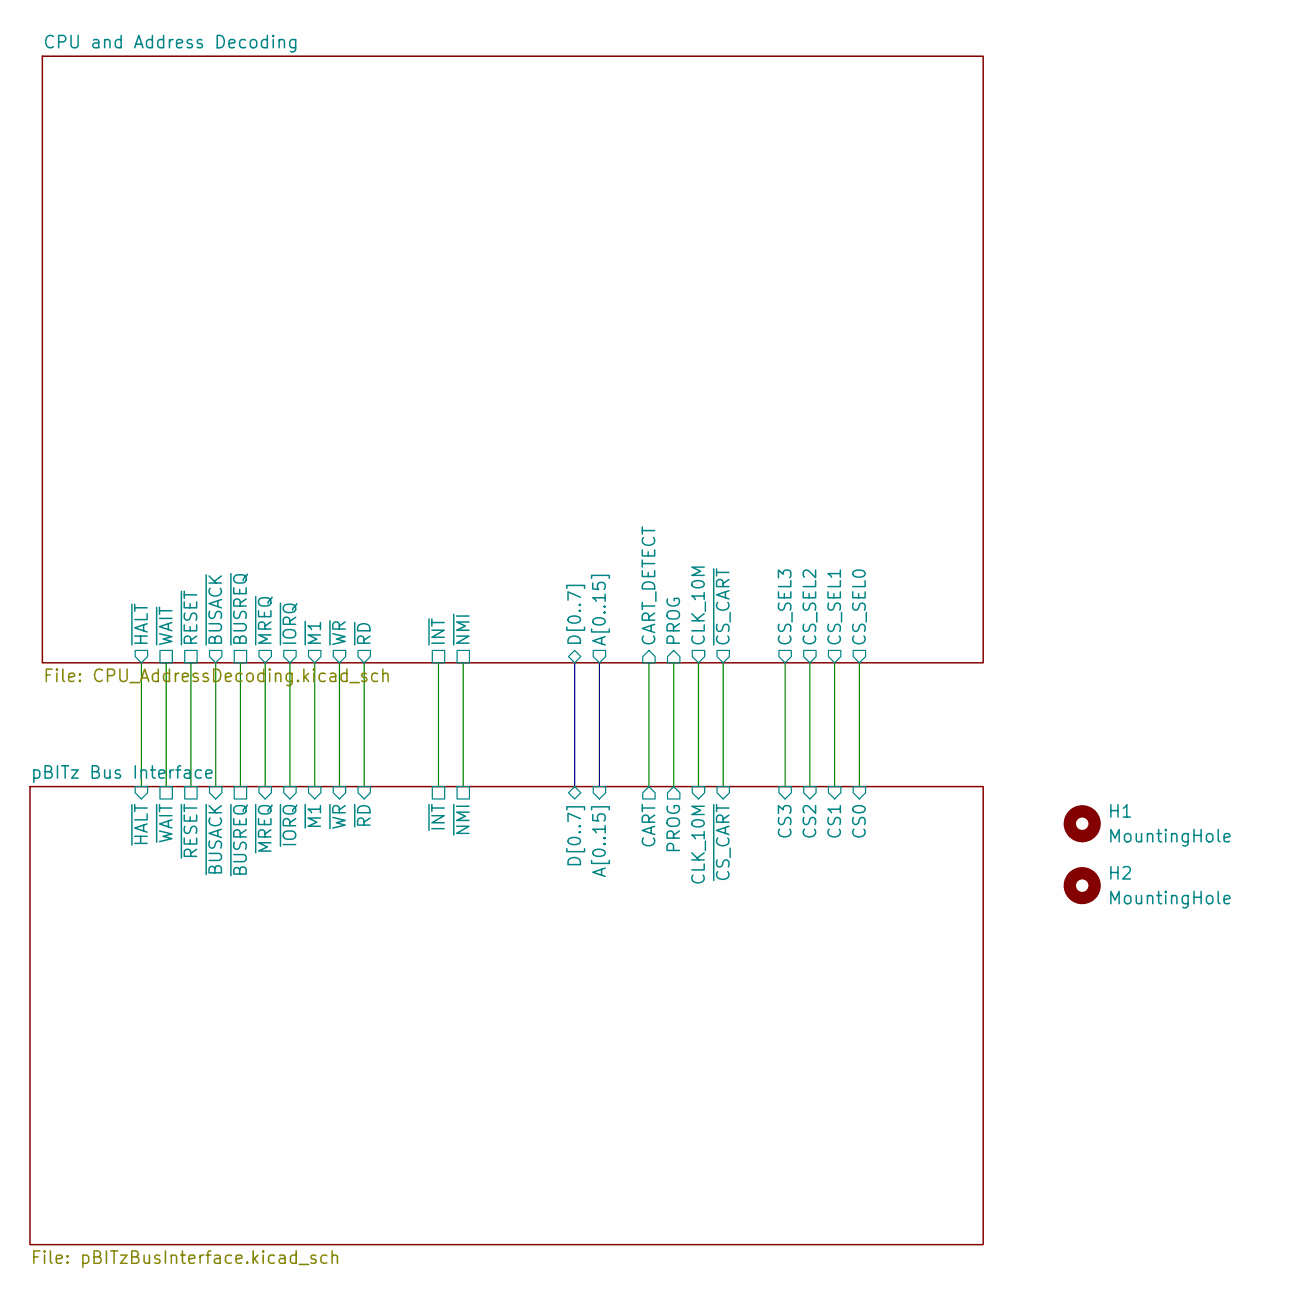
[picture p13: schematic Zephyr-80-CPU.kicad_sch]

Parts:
H1, H2: MountingHole; MountingHole_2.2mm_M2

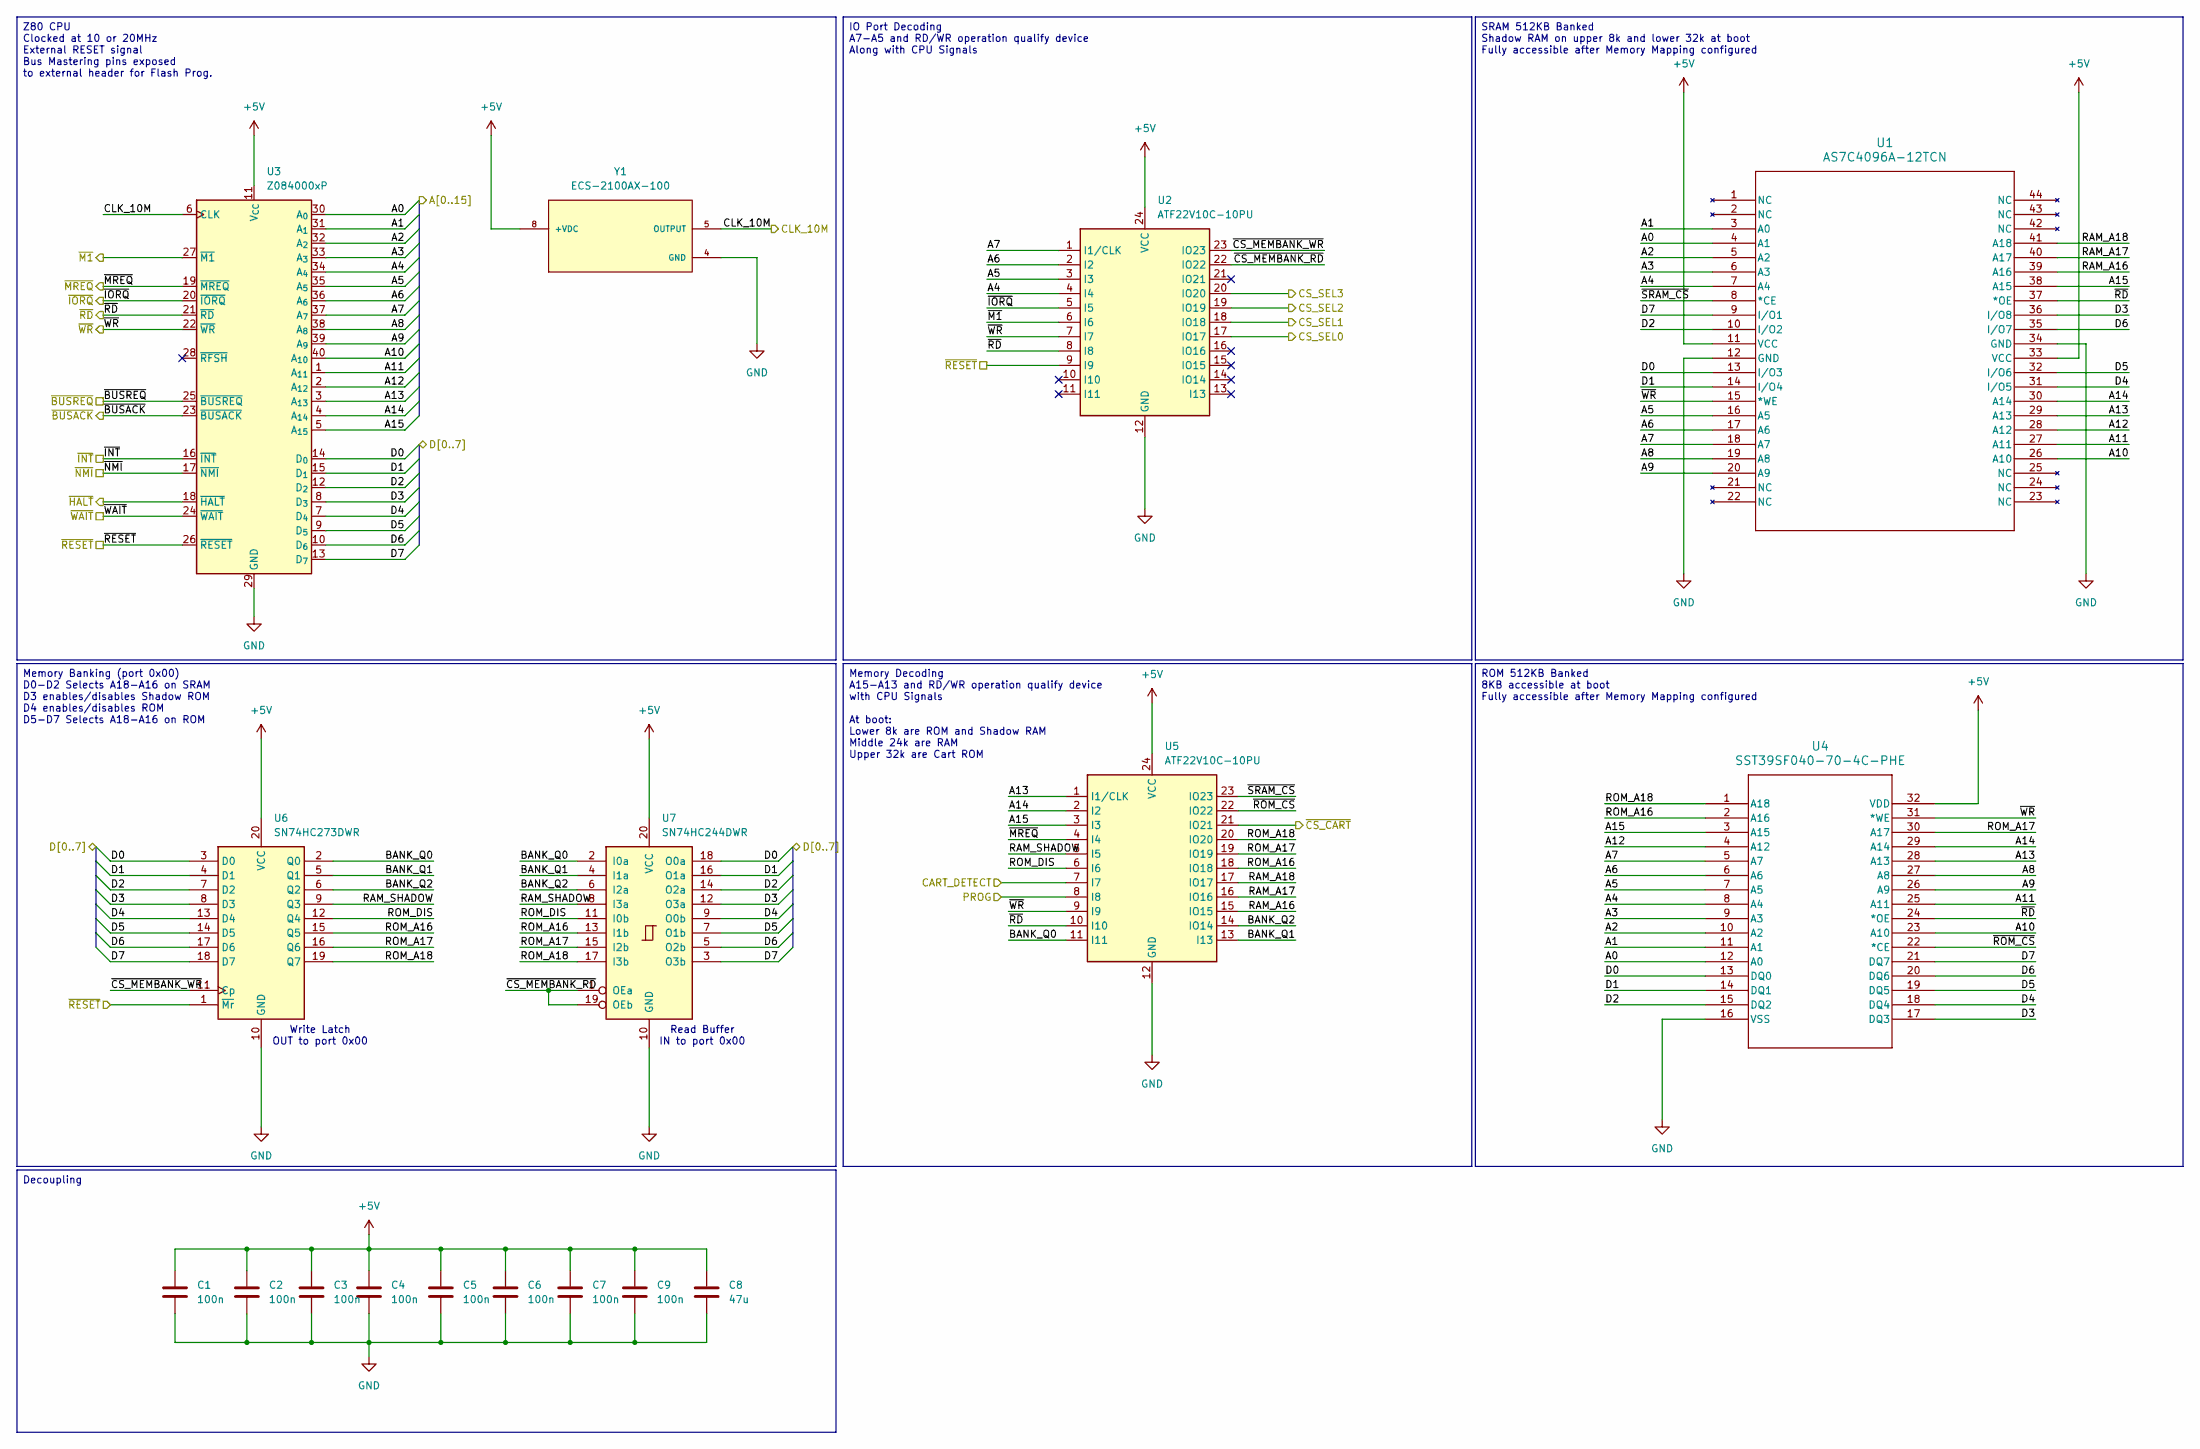
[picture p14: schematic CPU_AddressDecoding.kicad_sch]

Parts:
C1, C2, C3, C4, C5, C6, C7, C9: 100n; C_0603_1608Metric; MANUFACTURER_PART_NUMBER 0603B104K160CT
C8: 47u; C_1206_3216Metric; MANUFACTURER_PART_NUMBER C3216X5R1E476M160AC
U1: AS7C4096A-12TCN; TSOP-44_MIL400_ALL; MANUFACTURER_PART_NUMBER AS7C4096A-12TCN
U2, U5: ATF22V10C-10PU; DIP-24_W7.62mm_Socket; MANUFACTURER_PART_NUMBER ATF22V10C-10PU
U3: Z084000xP; DIP-40_W15.24mm_Socket; MANUFACTURER_PART_NUMBER A 40-LC-TT
U4: SST39SF040-70-4C-PHE; PDIP32_PH_SST_MCH; MANUFACTURER_PART_NUMBER SST39SF040-70-4C-PHE
U6: SN74HC273DWR; SOIC-20W_7.5x12.8mm_P1.27mm; MANUFACTURER_PART_NUMBER SN74HC273DWR
U7: SN74HC244DWR; SOIC-20W_7.5x12.8mm_P1.27mm; MANUFACTURER_PART_NUMBER SN74HC244DWR
Y1: ECS-2100AX-100; OSC_ECS-2100AX-147.4; PARTREV N/A

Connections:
+5V: C1.1, C2.1, C3.1, C4.1, C5.1, C6.1, C7.1, C8.1, C9.1, U1.11 (VCC), U1.33 (VCC), U2.24 (VCC), U3.11 (V_{CC}), U4.32 (VDD), U5.24 (VCC), U6.20 (VCC), U7.20 (VCC), Y1.8 (+VDC); also elsewhere on the board
/CPU and Address Decoding/A0: U1.4 (A1), U3.30 (A_{0}), U4.12 (A0); also elsewhere on the board
/CPU and Address Decoding/A1: U1.3 (A0), U3.31 (A_{1}), U4.11 (A1); also elsewhere on the board
/CPU and Address Decoding/A2: U1.5 (A2), U3.32 (A_{2}), U4.10 (A2); also elsewhere on the board
/CPU and Address Decoding/A3: U1.6 (A3), U3.33 (A_{3}), U4.9 (A3); also elsewhere on the board
/CPU and Address Decoding/A4: U1.7 (A4), U2.4 (I4), U3.34 (A_{4}), U4.8 (A4); also elsewhere on the board
/CPU and Address Decoding/A5: U1.16 (A5), U2.3 (I3), U3.35 (A_{5}), U4.7 (A5); also elsewhere on the board
/CPU and Address Decoding/A6: U1.17 (A6), U2.2 (I2), U3.36 (A_{6}), U4.6 (A6); also elsewhere on the board
/CPU and Address Decoding/A7: U1.18 (A7), U2.1 (I1/CLK), U3.37 (A_{7}), U4.5 (A7); also elsewhere on the board
/CPU and Address Decoding/A8: U1.19 (A8), U3.38 (A_{8}), U4.27 (A8); also elsewhere on the board
/CPU and Address Decoding/A9: U1.20 (A9), U3.39 (A_{9}), U4.26 (A9); also elsewhere on the board
/CPU and Address Decoding/A10: U1.26 (A10), U3.40 (A_{10}), U4.23 (A10); also elsewhere on the board
/CPU and Address Decoding/A11: U1.27 (A11), U3.1 (A_{11}), U4.25 (A11); also elsewhere on the board
/CPU and Address Decoding/A12: U1.28 (A12), U3.2 (A_{12}), U4.4 (A12); also elsewhere on the board
/CPU and Address Decoding/A13: U1.29 (A13), U3.3 (A_{13}), U4.28 (A13), U5.1 (I1/CLK); also elsewhere on the board
/CPU and Address Decoding/A14: U1.30 (A14), U3.4 (A_{14}), U4.29 (A14), U5.2 (I2); also elsewhere on the board
/CPU and Address Decoding/A15: U1.38 (A15), U3.5 (A_{15}), U4.3 (A15), U5.3 (I3); also elsewhere on the board
/CPU and Address Decoding/BANK_Q0: U5.11 (I11), U6.2 (Q0), U7.2 (I0a)
/CPU and Address Decoding/BANK_Q1: U5.13 (I13), U6.5 (Q1), U7.4 (I1a)
/CPU and Address Decoding/BANK_Q2: U5.14 (IO14), U6.6 (Q2), U7.6 (I2a)
/CPU and Address Decoding/CART_DETECT: U5.7 (I7); also elsewhere on the board
/CPU and Address Decoding/CLK_10M: U3.6 (CLK), Y1.5 (OUTPUT); also elsewhere on the board
/CPU and Address Decoding/CS_SEL0: U2.17 (IO17); also elsewhere on the board
/CPU and Address Decoding/CS_SEL1: U2.18 (IO18); also elsewhere on the board
/CPU and Address Decoding/CS_SEL2: U2.19 (IO19); also elsewhere on the board
/CPU and Address Decoding/CS_SEL3: U2.20 (IO20); also elsewhere on the board
/CPU and Address Decoding/D0: U1.13 (I/O3), U3.14 (D_{0}), U4.13 (DQ0), U6.3 (D0), U7.18 (O0a); also elsewhere on the board
/CPU and Address Decoding/D1: U1.14 (I/O4), U3.15 (D_{1}), U4.14 (DQ1), U6.4 (D1), U7.16 (O1a); also elsewhere on the board
/CPU and Address Decoding/D2: U1.10 (I/O2), U3.12 (D_{2}), U4.15 (DQ2), U6.7 (D2), U7.14 (O2a); also elsewhere on the board
/CPU and Address Decoding/D3: U1.36 (I/O8), U3.8 (D_{3}), U4.17 (DQ3), U6.8 (D3), U7.12 (O3a); also elsewhere on the board
/CPU and Address Decoding/D4: U1.31 (I/O5), U3.7 (D_{4}), U4.18 (DQ4), U6.13 (D4), U7.9 (O0b); also elsewhere on the board
/CPU and Address Decoding/D5: U1.32 (I/O6), U3.9 (D_{5}), U4.19 (DQ5), U6.14 (D5), U7.7 (O1b); also elsewhere on the board
/CPU and Address Decoding/D6: U1.35 (I/O7), U3.10 (D_{6}), U4.20 (DQ6), U6.17 (D6), U7.5 (O2b); also elsewhere on the board
/CPU and Address Decoding/D7: U1.9 (I/O1), U3.13 (D_{7}), U4.21 (DQ7), U6.18 (D7), U7.3 (O3b); also elsewhere on the board
/CPU and Address Decoding/PROG: U5.8 (I8); also elsewhere on the board
/CPU and Address Decoding/RAM_A16: U1.39 (A16), U5.15 (IO15)
/CPU and Address Decoding/RAM_A17: U1.40 (A17), U5.16 (IO16)
/CPU and Address Decoding/RAM_A18: U1.41 (A18), U5.17 (IO17)
/CPU and Address Decoding/RAM_SHADOW: U5.5 (I5), U6.9 (Q3), U7.8 (I3a)
/CPU and Address Decoding/ROM_A16: U4.2 (A16), U5.18 (IO18), U6.15 (Q5), U7.13 (I1b)
/CPU and Address Decoding/ROM_A17: U4.30 (A17), U5.19 (IO19), U6.16 (Q6), U7.15 (I2b)
/CPU and Address Decoding/ROM_A18: U4.1 (A18), U5.20 (IO20), U6.19 (Q7), U7.17 (I3b)
/CPU and Address Decoding/ROM_DIS: U5.6 (I6), U6.12 (Q4), U7.11 (I0b)
/CPU and Address Decoding/~BUSACK: U3.23 (~BUSACK); also elsewhere on the board
/CPU and Address Decoding/~BUSREQ: U3.25 (~BUSREQ); also elsewhere on the board
/CPU and Address Decoding/~CS_CART: U5.21 (IO21); also elsewhere on the board
/CPU and Address Decoding/~CS_MEMBANK_RD: U2.22 (IO22), U7.1 (OEa), U7.19 (OEb)
/CPU and Address Decoding/~CS_MEMBANK_WR: U2.23 (IO23), U6.11 (Cp)
/CPU and Address Decoding/~HALT: U3.18 (~HALT); also elsewhere on the board
/CPU and Address Decoding/~INT: U3.16 (~INT); also elsewhere on the board
/CPU and Address Decoding/~IORQ: U2.5 (I5), U3.20 (~IORQ); also elsewhere on the board
/CPU and Address Decoding/~M1: U2.6 (I6), U3.27 (~M1); also elsewhere on the board
/CPU and Address Decoding/~MREQ: U3.19 (~MREQ), U5.4 (I4); also elsewhere on the board
/CPU and Address Decoding/~NMI: U3.17 (~NMI); also elsewhere on the board
/CPU and Address Decoding/~RD: U1.37 (*OE), U2.8 (I8), U3.21 (~RD), U4.24 (*OE), U5.10 (I10); also elsewhere on the board
/CPU and Address Decoding/~RESET: U2.9 (I9), U3.26 (~RESET), U6.1 (~Mr); also elsewhere on the board
/CPU and Address Decoding/~ROM_CS: U4.22 (*CE), U5.22 (IO22)
/CPU and Address Decoding/~SRAM_CS: U1.8 (*CE), U5.23 (IO23)
/CPU and Address Decoding/~WAIT: U3.24 (~WAIT); also elsewhere on the board
/CPU and Address Decoding/~WR: U1.15 (*WE), U2.7 (I7), U3.22 (~WR), U4.31 (*WE), U5.9 (I9); also elsewhere on the board
GND: C1.2, C2.2, C3.2, C4.2, C5.2, C6.2, C7.2, C8.2, C9.2, U1.12 (GND), U1.34 (GND), U2.12 (GND), U3.29 (GND), U4.16 (VSS), U5.12 (GND), U6.10 (GND), U7.10 (GND), Y1.4 (GND); also elsewhere on the board

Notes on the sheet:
Write Latch OUT to port 0x00
Read Buffer IN to port 0x00
Decoupling
SRAM 512KB Banked Shadow RAM on upper 8k and lower 32k at boot Fully accessible after Memory Mapping configured
Z80 CPU Clocked at 10 or 20MHz External RESET signal Bus Mastering pins exposed to external header for Flash Prog.
IO Port Decoding A7-A5 and RD/WR operation qualify device Along with CPU Signals
ROM 512KB Banked 8KB accessible at boot Fully accessible after Memory Mapping configured
Memory Banking (port 0x00) D0-D2 Selects A18-A16 on SRAM D3 enables/disables Shadow ROM D4 enables/disables ROM D5-D7 Selects A18-A16 on ROM
Memory Decoding A15-A13 and RD/WR operation qualify device with CPU Signals At boot: Lower 8k are ROM and Shadow RAM Middle 24k are RAM Upper 32k are Cart ROM

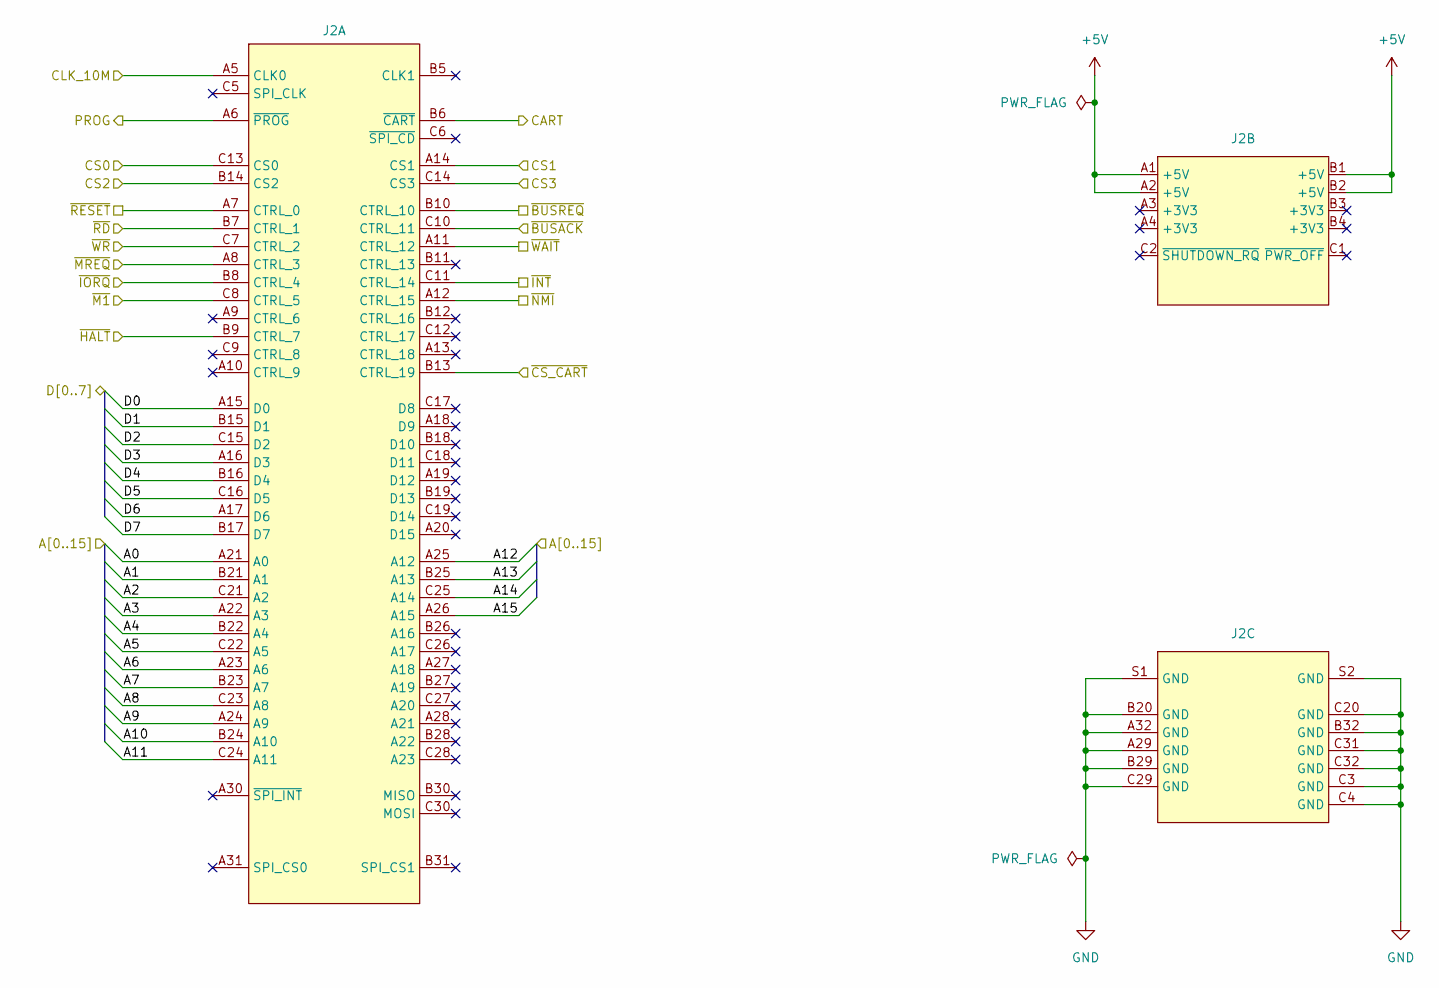
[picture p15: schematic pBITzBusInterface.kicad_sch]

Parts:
J2: AMPHENOL_86093967113T55F1LF; MANUFACTURER_PART_NUMBER 86093967113T55F1LF

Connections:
+5V: J2.A1 (+5V), J2.A2 (+5V), J2.B1 (+5V), J2.B2 (+5V); also elsewhere on the board
/CPU and Address Decoding/A0: J2.A21 (A0); also elsewhere on the board
/CPU and Address Decoding/A1: J2.B21 (A1); also elsewhere on the board
/CPU and Address Decoding/A2: J2.C21 (A2); also elsewhere on the board
/CPU and Address Decoding/A3: J2.A22 (A3); also elsewhere on the board
/CPU and Address Decoding/A4: J2.B22 (A4); also elsewhere on the board
/CPU and Address Decoding/A5: J2.C22 (A5); also elsewhere on the board
/CPU and Address Decoding/A6: J2.A23 (A6); also elsewhere on the board
/CPU and Address Decoding/A7: J2.B23 (A7); also elsewhere on the board
/CPU and Address Decoding/A8: J2.C23 (A8); also elsewhere on the board
/CPU and Address Decoding/A9: J2.A24 (A9); also elsewhere on the board
/CPU and Address Decoding/A10: J2.B24 (A10); also elsewhere on the board
/CPU and Address Decoding/A11: J2.C24 (A11); also elsewhere on the board
/CPU and Address Decoding/A12: J2.A25 (A12); also elsewhere on the board
/CPU and Address Decoding/A13: J2.B25 (A13); also elsewhere on the board
/CPU and Address Decoding/A14: J2.C25 (A14); also elsewhere on the board
/CPU and Address Decoding/A15: J2.A26 (A15); also elsewhere on the board
/CPU and Address Decoding/CART_DETECT: J2.B6 (~CART); also elsewhere on the board
/CPU and Address Decoding/CLK_10M: J2.A5 (CLK0); also elsewhere on the board
/CPU and Address Decoding/CS_SEL0: J2.C13 (CS0); also elsewhere on the board
/CPU and Address Decoding/CS_SEL1: J2.A14 (CS1); also elsewhere on the board
/CPU and Address Decoding/CS_SEL2: J2.B14 (CS2); also elsewhere on the board
/CPU and Address Decoding/CS_SEL3: J2.C14 (CS3); also elsewhere on the board
/CPU and Address Decoding/D0: J2.A15 (D0); also elsewhere on the board
/CPU and Address Decoding/D1: J2.B15 (D1); also elsewhere on the board
/CPU and Address Decoding/D2: J2.C15 (D2); also elsewhere on the board
/CPU and Address Decoding/D3: J2.A16 (D3); also elsewhere on the board
/CPU and Address Decoding/D4: J2.B16 (D4); also elsewhere on the board
/CPU and Address Decoding/D5: J2.C16 (D5); also elsewhere on the board
/CPU and Address Decoding/D6: J2.A17 (D6); also elsewhere on the board
/CPU and Address Decoding/D7: J2.B17 (D7); also elsewhere on the board
/CPU and Address Decoding/PROG: J2.A6 (~PROG); also elsewhere on the board
/CPU and Address Decoding/~BUSACK: J2.C10 (CTRL_11); also elsewhere on the board
/CPU and Address Decoding/~BUSREQ: J2.B10 (CTRL_10); also elsewhere on the board
/CPU and Address Decoding/~CS_CART: J2.B13 (CTRL_19); also elsewhere on the board
/CPU and Address Decoding/~HALT: J2.B9 (CTRL_7); also elsewhere on the board
/CPU and Address Decoding/~INT: J2.C11 (CTRL_14); also elsewhere on the board
/CPU and Address Decoding/~IORQ: J2.B8 (CTRL_4); also elsewhere on the board
/CPU and Address Decoding/~M1: J2.C8 (CTRL_5); also elsewhere on the board
/CPU and Address Decoding/~MREQ: J2.A8 (CTRL_3); also elsewhere on the board
/CPU and Address Decoding/~NMI: J2.A12 (CTRL_15); also elsewhere on the board
/CPU and Address Decoding/~RD: J2.B7 (CTRL_1); also elsewhere on the board
/CPU and Address Decoding/~RESET: J2.A7 (CTRL_0); also elsewhere on the board
/CPU and Address Decoding/~WAIT: J2.A11 (CTRL_12); also elsewhere on the board
/CPU and Address Decoding/~WR: J2.C7 (CTRL_2); also elsewhere on the board
GND: J2.A29 (GND), J2.A32 (GND), J2.B20 (GND), J2.B29 (GND), J2.B32 (GND), J2.C3 (GND), J2.C4 (GND), J2.C20 (GND), J2.C29 (GND), J2.C31 (GND), J2.C32 (GND), J2.S1 (GND), J2.S2 (GND); also elsewhere on the board

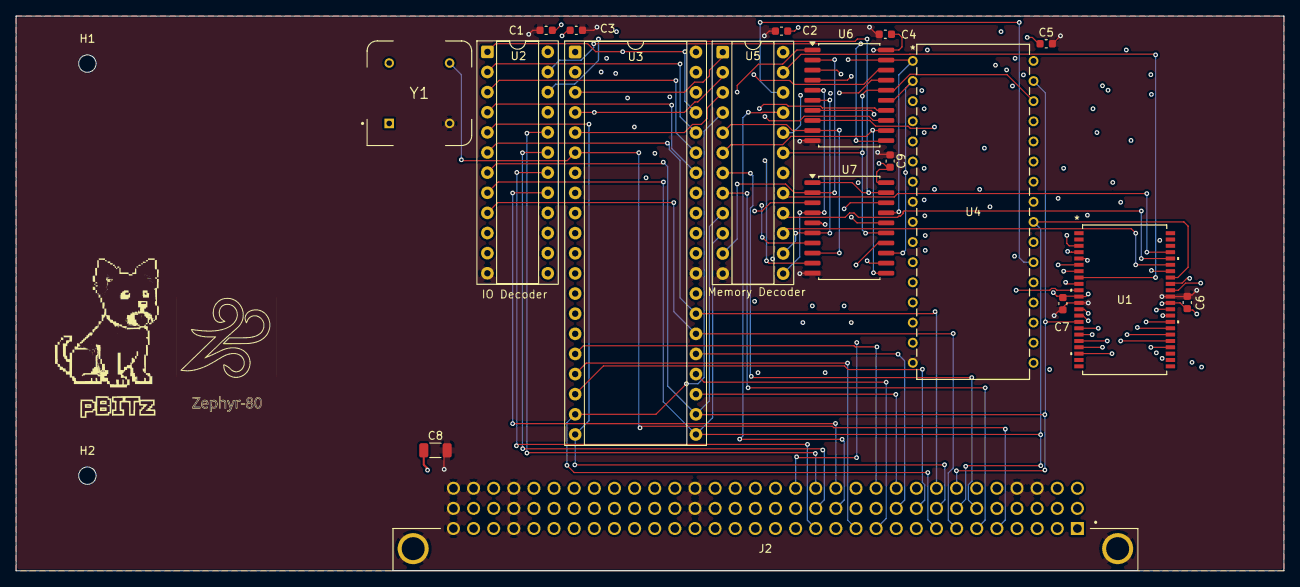
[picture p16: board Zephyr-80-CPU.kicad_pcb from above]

Board: 6 copper layers, 160.0 x 70.0 mm, 20 parts (0 on the bottom side), 61 nets.

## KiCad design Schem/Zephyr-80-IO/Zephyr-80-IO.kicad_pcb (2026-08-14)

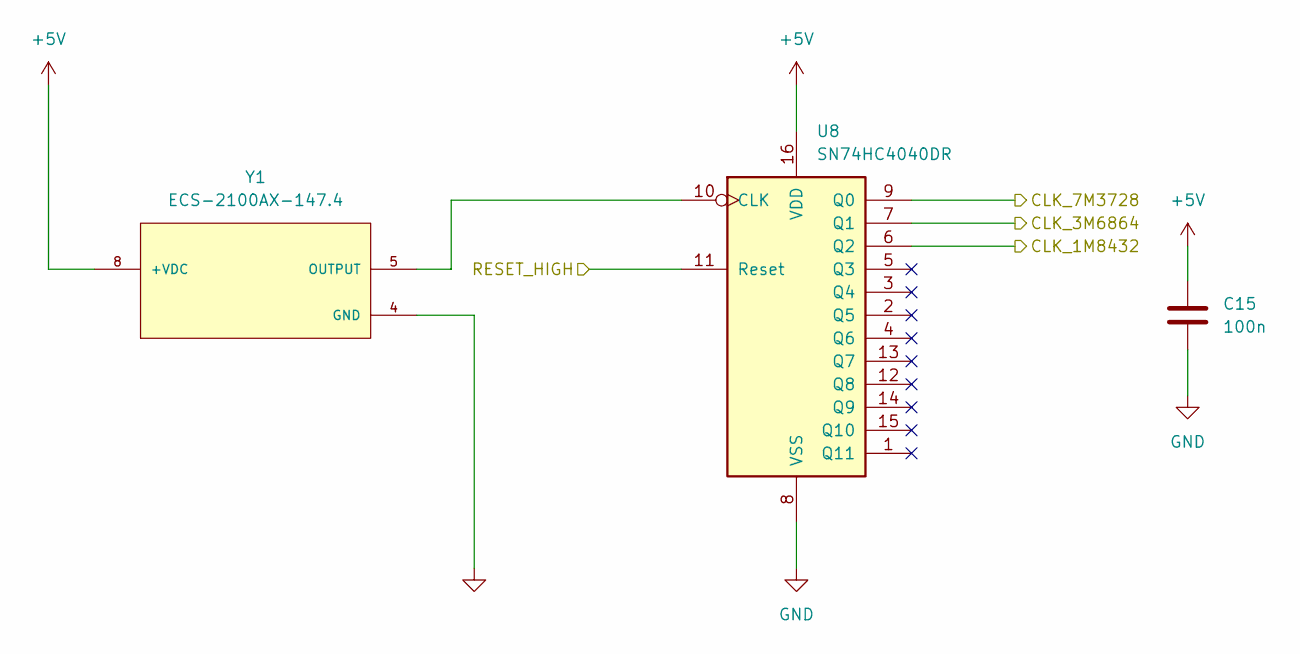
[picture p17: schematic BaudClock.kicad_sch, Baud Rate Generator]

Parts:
C15: 100n; C_0603_1608Metric; MANUFACTURER_PART_NUMBER C0603C104K5RACTU
U8: SN74HC4040DR; TSSOP-16_4.4x5mm_P0.65mm; MANUFACTURER_PART_NUMBER SN74HC4040PWR
Y1: ECS-2100AX-147.4; OSC_ECS-2100AX-147.4; PARTREV N/A

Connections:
+5V: C15.1, U8.16 (VDD), Y1.8 (+VDC); also elsewhere on the board
/Baud Clock/CLK_1M8432: U8.6 (Q2); also elsewhere on the board
/Baud Clock/CLK_3M6864: U8.7 (Q1); also elsewhere on the board
/Baud Clock/CLK_7M3728: U8.9 (Q0); also elsewhere on the board
/Baud Clock/RESET_HIGH: U8.11 (Reset); also elsewhere on the board
GND: C15.2, U8.8 (VSS), Y1.4 (GND); also elsewhere on the board
unnamed: U8.10 (CLK), Y1.5 (OUTPUT)

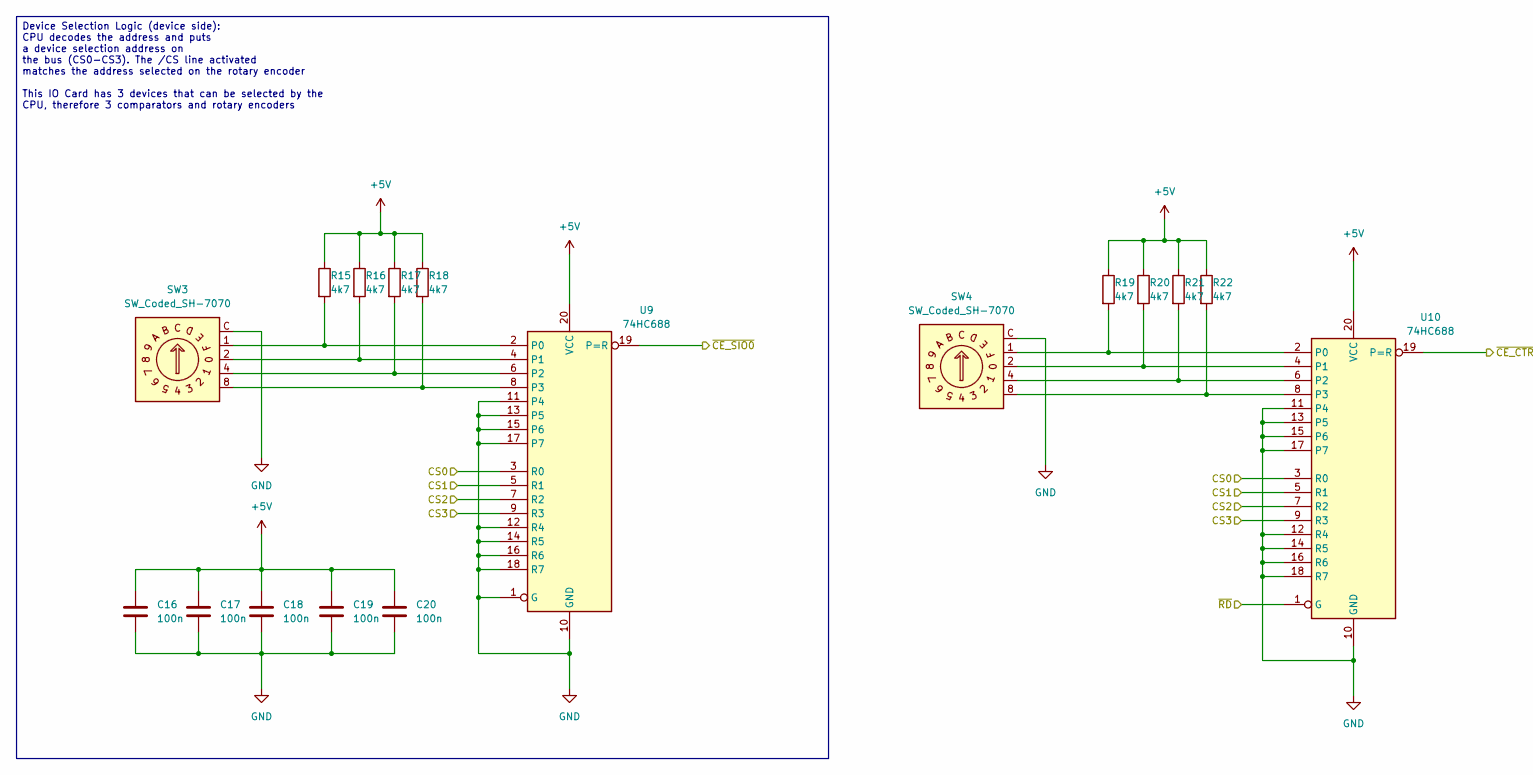
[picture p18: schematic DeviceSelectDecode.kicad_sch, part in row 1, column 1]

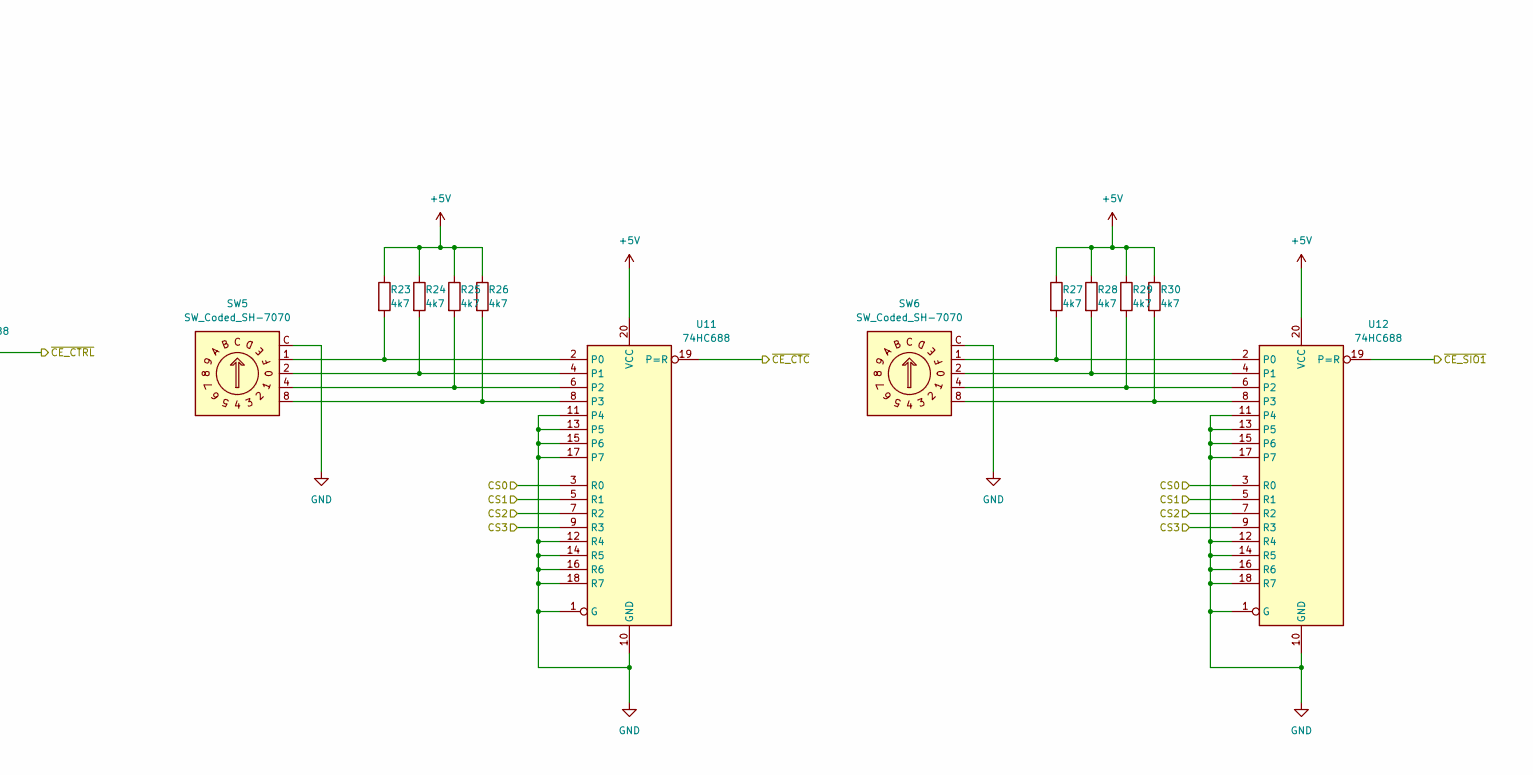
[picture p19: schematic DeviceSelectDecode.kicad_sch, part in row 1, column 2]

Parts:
C16, C17, C18, C19, C20: 100n; C_0603_1608Metric; MANUFACTURER_PART_NUMBER C0603C104K5RACTU
R15, R16, R17, R18, R19, R20, R21, R22, R23, R24, R25, R26, R27, R28, R29, R30: 4k7; R_0603_1608Metric; MANUFACTURER_PART_NUMBER CRCW06034K70FKEA
SW3, SW4, SW5, SW6: SW_Coded_SH-7070; Nidec_Copal_SH-7010C; MANUFACTURER_PART_NUMBER SH-7070MC
U9, U10, U11, U12: 74HC688; TSSOP-20_4.4x6.5mm_P0.65mm; MANUFACTURER_PART_NUMBER SN74HC688PWR

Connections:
+5V: C16.1, C17.1, C18.1, C19.1, C20.1, R15.1, R16.1, R17.1, R18.1, R19.1, R20.1, R21.1, R22.1, R23.1, R24.1, R25.1, R26.1, R27.1, R28.1, R29.1, R30.1, U9.20 (VCC), U10.20 (VCC), U11.20 (VCC), U12.20 (VCC); also elsewhere on the board
/Device Select Decode/CS0: U9.3 (R0), U10.3 (R0), U11.3 (R0), U12.3 (R0); also elsewhere on the board
/Device Select Decode/CS1: U9.5 (R1), U10.5 (R1), U11.5 (R1), U12.5 (R1); also elsewhere on the board
/Device Select Decode/CS2: U9.7 (R2), U10.7 (R2), U11.7 (R2), U12.7 (R2); also elsewhere on the board
/Device Select Decode/CS3: U9.9 (R3), U10.9 (R3), U11.9 (R3), U12.9 (R3); also elsewhere on the board
/Device Select Decode/~CE_CTC: U11.19 (P=R); also elsewhere on the board
/Device Select Decode/~CE_CTRL: U10.19 (P=R); also elsewhere on the board
/Device Select Decode/~CE_SIO0: U9.19 (P=R); also elsewhere on the board
/Device Select Decode/~CE_SIO1: U12.19 (P=R); also elsewhere on the board
/Device Select Decode/~RD: U10.1 (G); also elsewhere on the board
GND: C16.2, C17.2, C18.2, C19.2, C20.2, SW3.C, SW4.C, SW5.C, SW6.C, U9.1 (G), U9.10 (GND), U9.11 (P4), U9.12 (R4), U9.13 (P5), U9.14 (R5), U9.15 (P6), U9.16 (R6), U9.17 (P7), U9.18 (R7), U10.10 (GND), U10.11 (P4), U10.12 (R4), U10.13 (P5), U10.14 (R5), U10.15 (P6), U10.16 (R6), U10.17 (P7), U10.18 (R7), U11.1 (G), U11.10 (GND), U11.11 (P4), U11.12 (R4), U11.13 (P5), U11.14 (R5), U11.15 (P6), U11.16 (R6), U11.17 (P7), U11.18 (R7), U12.1 (G), U12.10 (GND), U12.11 (P4), U12.12 (R4), U12.13 (P5), U12.14 (R5), U12.15 (P6), U12.16 (R6), U12.17 (P7), U12.18 (R7); also elsewhere on the board
unnamed: R15.2, SW3.1, U9.2 (P0)
unnamed: R16.2, SW3.2, U9.4 (P1)
unnamed: R17.2, SW3.4, U9.6 (P2)
unnamed: R18.2, SW3.8, U9.8 (P3)
unnamed: R19.2, SW4.1, U10.2 (P0)
unnamed: R20.2, SW4.2, U10.4 (P1)
unnamed: R21.2, SW4.4, U10.6 (P2)
unnamed: R22.2, SW4.8, U10.8 (P3)
unnamed: R23.2, SW5.1, U11.2 (P0)
unnamed: R24.2, SW5.2, U11.4 (P1)
unnamed: R25.2, SW5.4, U11.6 (P2)
unnamed: R26.2, SW5.8, U11.8 (P3)
unnamed: R27.2, SW6.1, U12.2 (P0)
unnamed: R28.2, SW6.2, U12.4 (P1)
unnamed: R29.2, SW6.4, U12.6 (P2)
unnamed: R30.2, SW6.8, U12.8 (P3)

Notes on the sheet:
Device Selection Logic (device side): CPU decodes the address and puts a device selection address on the bus (CS0-CS3). The /CS line activated matches the address selected on the rotary encoder This IO Card has 3 devices that can be selected by the CPU, therefore 3 comparators and rotary encoders

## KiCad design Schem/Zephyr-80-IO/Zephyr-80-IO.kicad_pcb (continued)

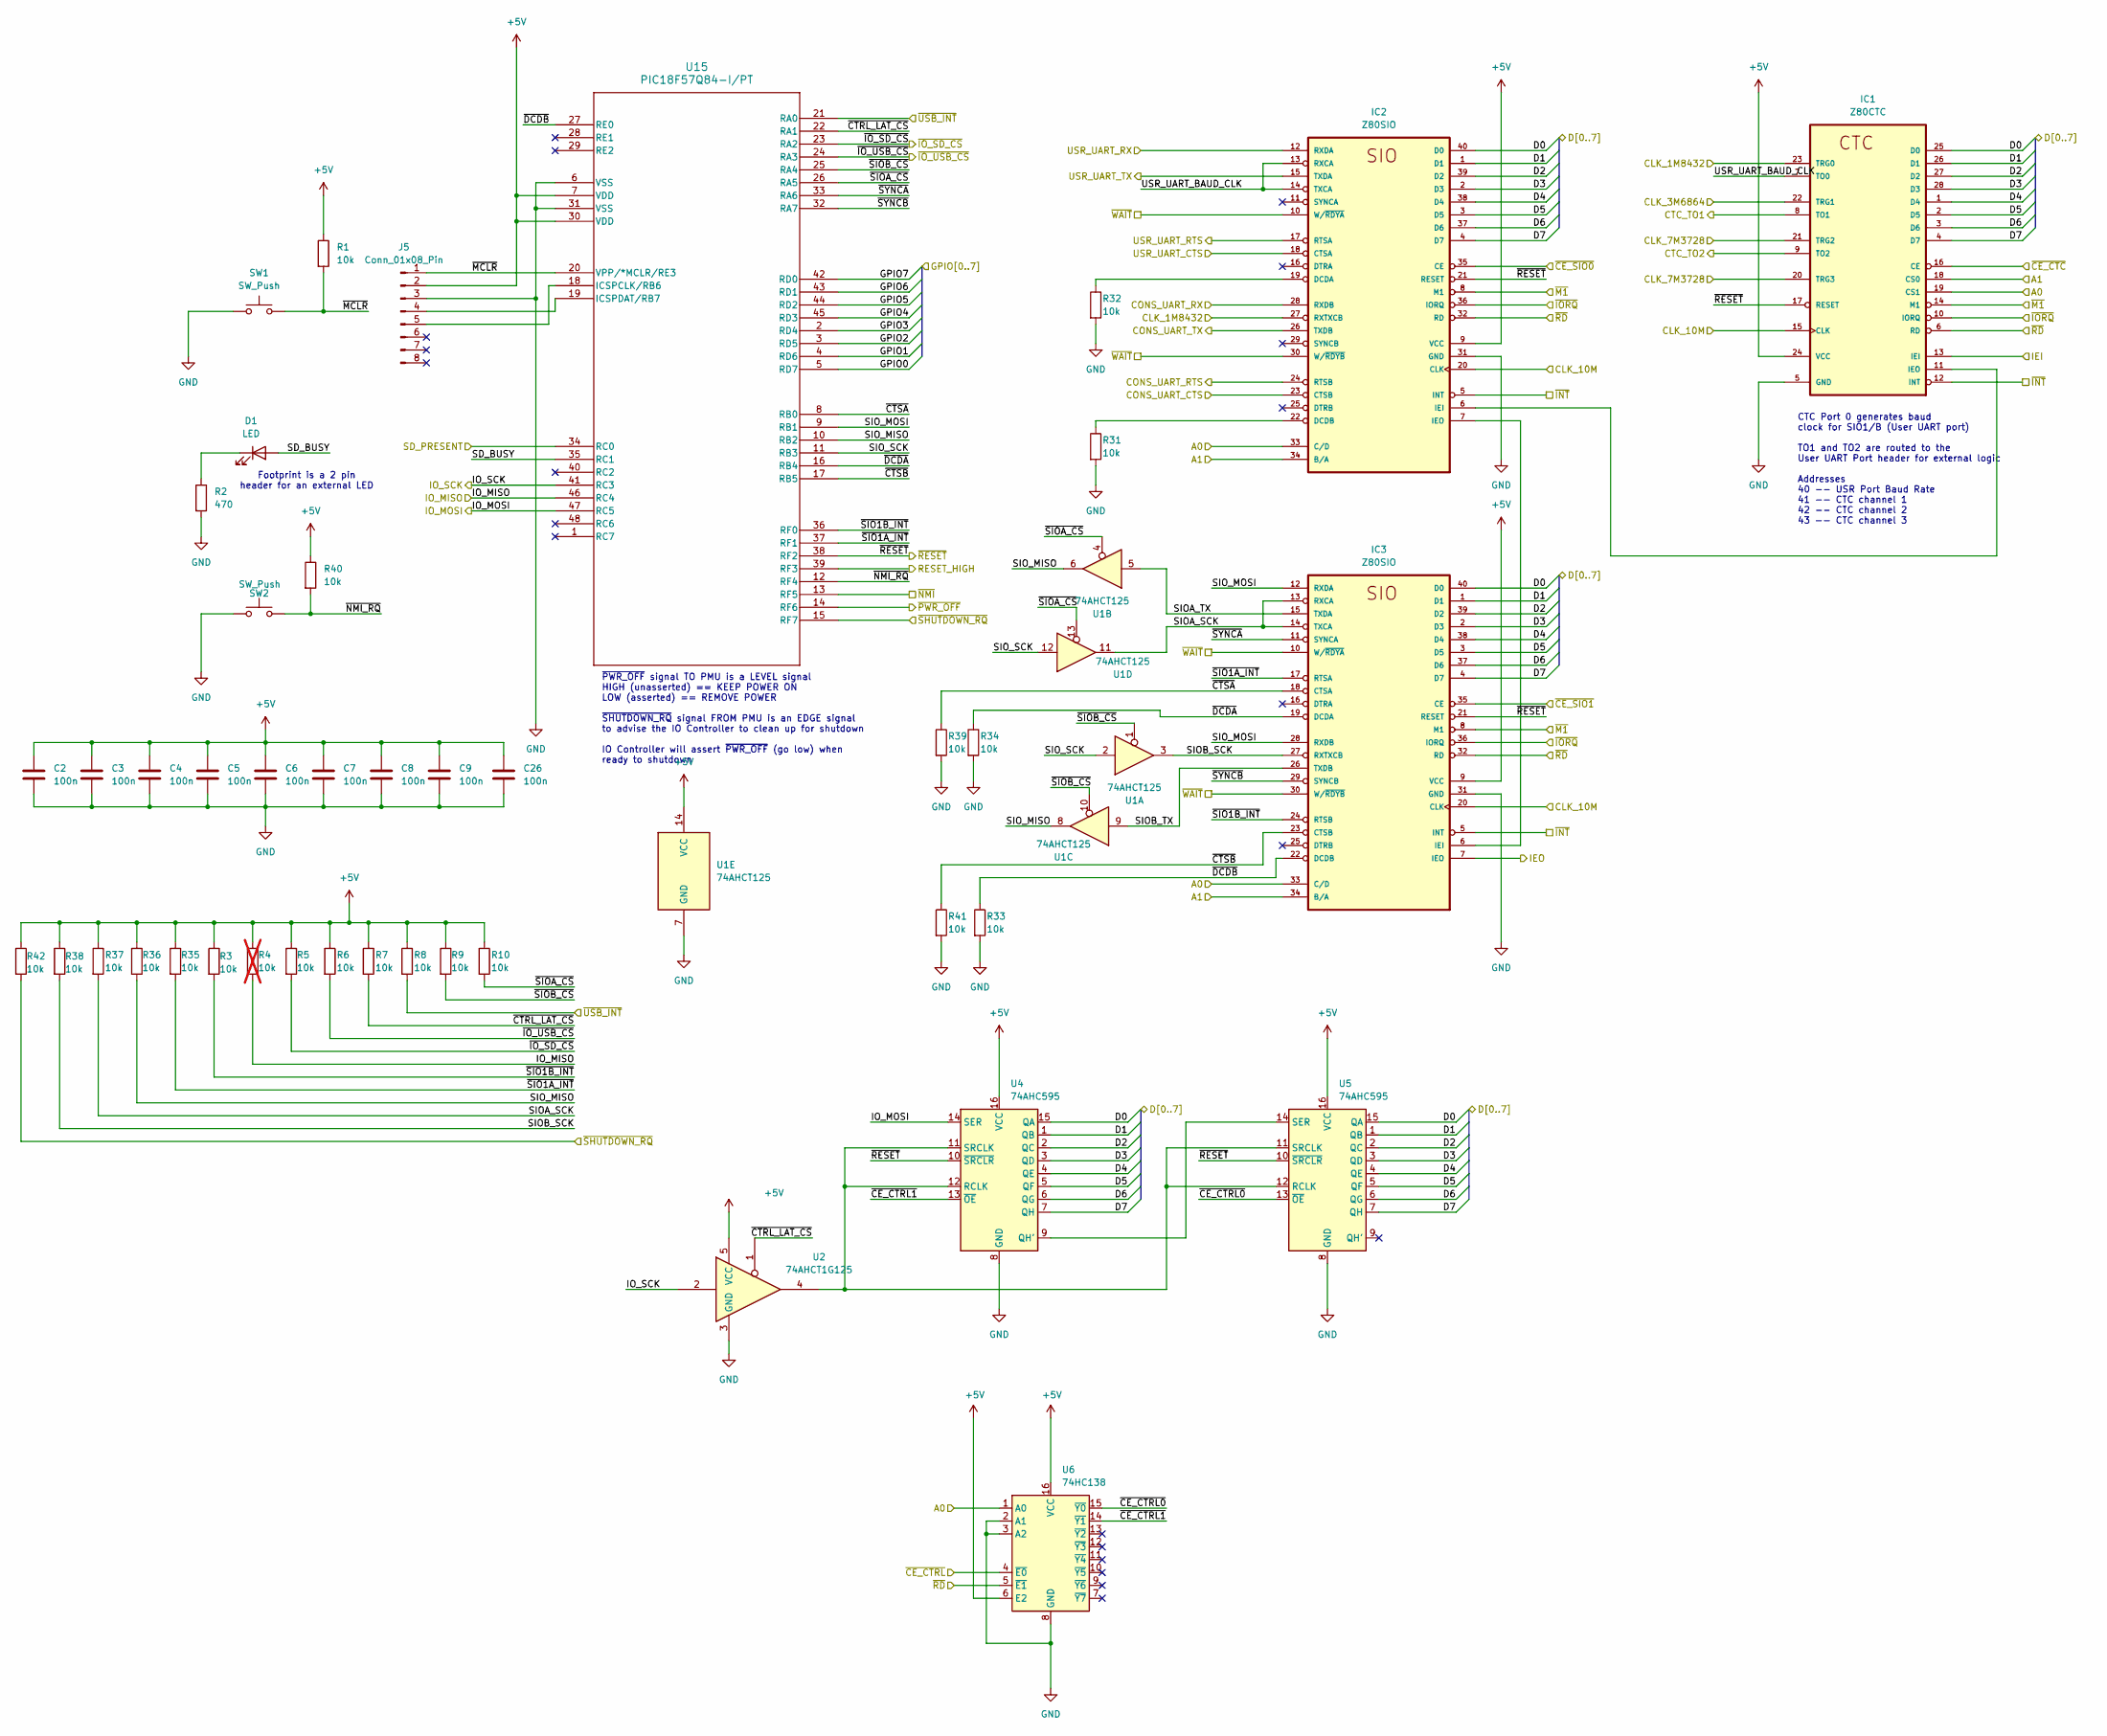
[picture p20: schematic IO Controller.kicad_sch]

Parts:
C2, C3, C4, C5, C6, C7, C8, C9, C26: 100n; C_0603_1608Metric; MANUFACTURER_PART_NUMBER C0603C104K5RACTU
D1: LED; PinHeader_1x02_P2.54mm_Vertical
IC1: Z80CTC; DIP-28_W15.24mm_Socket; MANUFACTURER_PART_NUMBER ICS-628-T
IC2, IC3: Z80SIO; DIP-40_W15.24mm_Socket; MANUFACTURER_PART_NUMBER A 40-LC-TT
J5: Conn_01x08_Pin; PinHeader_1x08_P2.54mm_Vertical
R1, R3, R5, R6, R7, R8, R9, R10, R31, R32, R33, R34, R35, R36, R37, R38, R39, R40, R41, R42: 10k; R_0603_1608Metric; MANUFACTURER_PART_NUMBER RC0603FR-0710KL
R2: 470; R_0603_1608Metric; MANUFACTURER_PART_NUMBER RC0603JR-07470RL
R4: 10k; R_0603_1608Metric; MANUFACTURER_PART_NUMBER RC0603FR-0710KL; not fitted
SW1, SW2: SW_Push; PinHeader_1x02_P2.54mm_Vertical
U1: 74AHCT125; TSSOP-14_4.4x5mm_P0.65mm; MANUFACTURER_PART_NUMBER SN74AHCT125QPWRQ1
U2: 74AHCT1G125; SOT-23-5; MANUFACTURER_PART_NUMBER SN74AHCT1G125DBVR
U4, U5: 74AHC595; TSSOP-16_4.4x5mm_P0.65mm; MANUFACTURER_PART_NUMBER 74AHC595PW,118
U6: 74HC138; TSSOP-16_4.4x5mm_P0.65mm; MANUFACTURER_PART_NUMBER SN74HC138PWR
U15: PIC18F57Q84-I/PT; TQFP48_PT_MCH; MANUFACTURER PART NUMBER PIC18F57Q84-I/PT

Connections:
+5V: C2.1, C3.1, C4.1, C5.1, C6.1, C7.1, C8.1, C9.1, C26.1, IC1.24 (VCC), IC2.9 (VCC), IC3.9 (VCC), J5.2, R1.1, R3.1, R4.1, R5.1, R6.1, R7.1, R8.1, R9.1, R10.1, R35.1, R36.1, R37.1, R38.1, R40.1, R42.1, U1.14 (VCC), U2.5 (VCC), U4.16 (VCC), U5.16 (VCC), U6.6 (E2), U6.16 (VCC), U15.7 (VDD), U15.30 (VDD); also elsewhere on the board
/Baud Clock/CLK_1M8432: IC1.23 (TRG0), IC2.27 (RXTXCB); also elsewhere on the board
/Baud Clock/CLK_3M6864: IC1.22 (TRG1); also elsewhere on the board
/Baud Clock/CLK_7M3728: IC1.20 (TRG3), IC1.21 (TRG2); also elsewhere on the board
/Baud Clock/RESET_HIGH: U15.39 (RF3); also elsewhere on the board
/Console Port/CONSOLE_CTS: IC2.24 (RTSB); also elsewhere on the board
/Console Port/CONSOLE_RTS: IC2.23 (CTSB); also elsewhere on the board
/Console Port/CONSOLE_RX: IC2.26 (TXDB); also elsewhere on the board
/Console Port/CONSOLE_TX: IC2.28 (RXDB); also elsewhere on the board
/Device Select Decode/~CE_CTC: IC1.16 (CE); also elsewhere on the board
/Device Select Decode/~CE_CTRL: U6.4 (~E0); also elsewhere on the board
/Device Select Decode/~CE_SIO0: IC2.35 (CE); also elsewhere on the board
/Device Select Decode/~CE_SIO1: IC3.35 (CE); also elsewhere on the board
/Device Select Decode/~RD: IC1.6 (RD), IC2.32 (RD), IC3.32 (RD), U6.5 (~E1); also elsewhere on the board
/GPIOs and User Serial/CTC_TO1: IC1.8 (TO1); also elsewhere on the board
/GPIOs and User Serial/CTC_TO2: IC1.9 (TO2); also elsewhere on the board
/GPIOs and User Serial/GPIO0: U15.5 (RD7); also elsewhere on the board
/GPIOs and User Serial/GPIO1: U15.4 (RD6); also elsewhere on the board
/GPIOs and User Serial/GPIO2: U15.3 (RD5); also elsewhere on the board
/GPIOs and User Serial/GPIO3: U15.2 (RD4); also elsewhere on the board
/GPIOs and User Serial/GPIO4: U15.45 (RD3); also elsewhere on the board
/GPIOs and User Serial/GPIO5: U15.44 (RD2); also elsewhere on the board
/GPIOs and User Serial/GPIO6: U15.43 (RD1); also elsewhere on the board
/GPIOs and User Serial/GPIO7: U15.42 (RD0); also elsewhere on the board
/GPIOs and User Serial/USR_UART_CTS: IC2.17 (RTSA); also elsewhere on the board
/GPIOs and User Serial/USR_UART_RTS: IC2.18 (CTSA); also elsewhere on the board
/GPIOs and User Serial/USR_UART_RX: IC2.15 (TXDA); also elsewhere on the board
/GPIOs and User Serial/USR_UART_TX: IC2.12 (RXDA); also elsewhere on the board
/IO Controller Card/A0: IC1.19 (CS1), IC2.33 (C/D), IC3.33 (C/D), U6.1 (A0); also elsewhere on the board
/IO Controller Card/A1: IC1.18 (CS0), IC2.34 (B/A), IC3.34 (B/A); also elsewhere on the board
/IO Controller Card/CLK_10M: IC1.15 (CLK), IC2.20 (CLK), IC3.20 (CLK); also elsewhere on the board
/IO Controller Card/D0: IC1.25 (D0), IC2.40 (D0), IC3.40 (D0), U4.15 (QA), U5.15 (QA); also elsewhere on the board
/IO Controller Card/D1: IC1.26 (D1), IC2.1 (D1), IC3.1 (D1), U4.1 (QB), U5.1 (QB); also elsewhere on the board
/IO Controller Card/D2: IC1.27 (D2), IC2.39 (D2), IC3.39 (D2), U4.2 (QC), U5.2 (QC); also elsewhere on the board
/IO Controller Card/D3: IC1.28 (D3), IC2.2 (D3), IC3.2 (D3), U4.3 (QD), U5.3 (QD); also elsewhere on the board
/IO Controller Card/D4: IC1.1 (D4), IC2.38 (D4), IC3.38 (D4), U4.4 (QE), U5.4 (QE); also elsewhere on the board
/IO Controller Card/D5: IC1.2 (D5), IC2.3 (D5), IC3.3 (D5), U4.5 (QF), U5.5 (QF); also elsewhere on the board
/IO Controller Card/D6: IC1.3 (D6), IC2.37 (D6), IC3.37 (D6), U4.6 (QG), U5.6 (QG); also elsewhere on the board
/IO Controller Card/D7: IC1.4 (D7), IC2.4 (D7), IC3.4 (D7), U4.7 (QH), U5.7 (QH); also elsewhere on the board
/IO Controller Card/IEI: IC1.13 (IEI); also elsewhere on the board
/IO Controller Card/IEO: IC3.7 (IEO); also elsewhere on the board
/IO Controller Card/IO_MISO: R4.2, U15.46 (RC4); also elsewhere on the board
/IO Controller Card/IO_MOSI: U4.14 (SER), U15.47 (RC5); also elsewhere on the board
/IO Controller Card/IO_SCK: U2.2, U15.41 (RC3); also elsewhere on the board
/IO Controller Card/SD_BUSY: D1.2 (A), U15.35 (RC1)
/IO Controller Card/SD_PRESENT: U15.34 (RC0); also elsewhere on the board
/IO Controller Card/SIOA_SCK: IC3.13 (RXCA), IC3.14 (TXCA), R37.2, U1.11
/IO Controller Card/SIOA_TX: IC3.15 (TXDA), U1.5
/IO Controller Card/SIOB_SCK: IC3.27 (RXTXCB), R38.2, U1.3
/IO Controller Card/SIOB_TX: IC3.26 (TXDB), U1.9
/IO Controller Card/SIO_MISO: R36.2, U1.6, U1.8, U15.10 (RB2)
/IO Controller Card/SIO_MOSI: IC3.12 (RXDA), IC3.28 (RXDB), U15.9 (RB1)
/IO Controller Card/SIO_SCK: U1.2, U1.12, U15.11 (RB3)
/IO Controller Card/USR_UART_BAUD_CLK: IC1.7 (TO0), IC2.13 (RXCA), IC2.14 (TXCA)
/IO Controller Card/~CE_CTRL0: U5.13 (~OE), U6.15 (~Y0)
/IO Controller Card/~CE_CTRL1: U4.13 (~OE), U6.14 (~Y1)
/IO Controller Card/~CTRL_LAT_CS: R7.2, U2.1, U15.22 (RA1)
/IO Controller Card/~CTSA: IC3.18 (CTSA), R39.1, U15.8 (RB0)
/IO Controller Card/~CTSB: IC3.23 (CTSB), R41.1, U15.17 (RB5)
/IO Controller Card/~DCDA: IC3.19 (DCDA), R34.1, U15.16 (RB4)
/IO Controller Card/~DCDB: IC3.22 (DCDB), R33.1, U15.27 (RE0)
/IO Controller Card/~INT: IC1.12 (INT), IC2.5 (INT), IC3.5 (INT); also elsewhere on the board
/IO Controller Card/~IORQ: IC1.10 (IORQ), IC2.36 (IORQ), IC3.36 (IORQ); also elsewhere on the board
/IO Controller Card/~IO_SD_CS: R5.2, U15.23 (RA2); also elsewhere on the board
/IO Controller Card/~IO_USB_CS: R6.2, U15.24 (RA3); also elsewhere on the board
/IO Controller Card/~M1: IC1.14 (M1), IC2.8 (M1), IC3.8 (M1); also elsewhere on the board
/IO Controller Card/~MCLR: J5.1, R1.2, SW1.2, U15.20 (VPP/*MCLR/RE3)
/IO Controller Card/~NMI_RQ: R40.2, SW2.2, U15.12 (RF4)
/IO Controller Card/~NMI: U15.13 (RF5); also elsewhere on the board
/IO Controller Card/~PWR_OFF: U15.14 (RF6); also elsewhere on the board
/IO Controller Card/~RESET: IC1.17 (RESET), IC2.21 (RESET), IC3.21 (RESET), U4.10 (~SRCLR), U5.10 (~SRCLR), U15.38 (RF2); also elsewhere on the board
/IO Controller Card/~SHUTDOWN_RQ: R42.2, U15.15 (RF7); also elsewhere on the board
/IO Controller Card/~SIO1A_INT: IC3.17 (RTSA), R35.2, U15.37 (RF1)
/IO Controller Card/~SIO1B_INT: IC3.24 (RTSB), R3.2, U15.36 (RF0)
/IO Controller Card/~SIOA_CS: R10.2, U1.4, U1.13, U15.26 (RA5)
/IO Controller Card/~SIOB_CS: R9.2, U1.1, U1.10, U15.25 (RA4)
/IO Controller Card/~SYNCA: IC3.11 (SYNCA), U15.33 (RA6)
/IO Controller Card/~SYNCB: IC3.29 (SYNCB), U15.32 (RA7)
/IO Controller Card/~USB_INT: R8.2, U15.21 (RA0); also elsewhere on the board
/IO Controller Card/~WAIT: IC2.10 (W/~RDYA), IC2.30 (W/~RDYB), IC3.10 (W/~RDYA), IC3.30 (W/~RDYB); also elsewhere on the board
GND: C2.2, C3.2, C4.2, C5.2, C6.2, C7.2, C8.2, C9.2, C26.2, IC1.5 (GND), IC2.31 (GND), IC3.31 (GND), J5.3, R2.2, R31.2, R32.2, R33.2, R34.2, R39.2, R41.2, SW1.1, SW2.1, U1.7 (GND), U2.3 (GND), U4.8 (GND), U5.8 (GND), U6.2 (A1), U6.3 (A2), U6.8 (GND), U15.6 (VSS), U15.31 (VSS); also elsewhere on the board
unnamed: D1.1 (K), R2.1
unnamed: IC1.11 (IEO), IC2.6 (IEI)
unnamed: IC2.19 (DCDA), R32.1
unnamed: IC2.22 (DCDB), R31.1
unnamed: IC2.7 (IEO), IC3.6 (IEI)
unnamed: J5.4, U15.19 (ICSPDAT/RB7)
unnamed: J5.5, U15.18 (ICSPCLK/RB6)
unnamed: U4.9 (QH'), U5.14 (SER)
unnamed: U2.4, U4.11 (SRCLK), U4.12 (RCLK), U5.11 (SRCLK), U5.12 (RCLK)

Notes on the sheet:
CTC Port 0 generates baud clock for SIO1/B (User UART port) TO1 and TO2 are routed to the User UART Port header for external logic Addresses 40 -- USR Port Baud Rate 41 -- CTC channel 1 42 -- CTC channel 2 43 -- CTC channel 3
~{PWR_OFF} signal TO PMU is a LEVEL signal HIGH (unasserted) == KEEP POWER ON LOW (asserted) == REMOVE POWER ~{SHUTDOWN_RQ} signal FROM PMU is an EDGE signal to advise the IO Controller to clean up for shutdown IO Controller will assert ~{PWR_OFF} (go low) when ready to shutdown
Footprint is a 2 pin header for an external LED

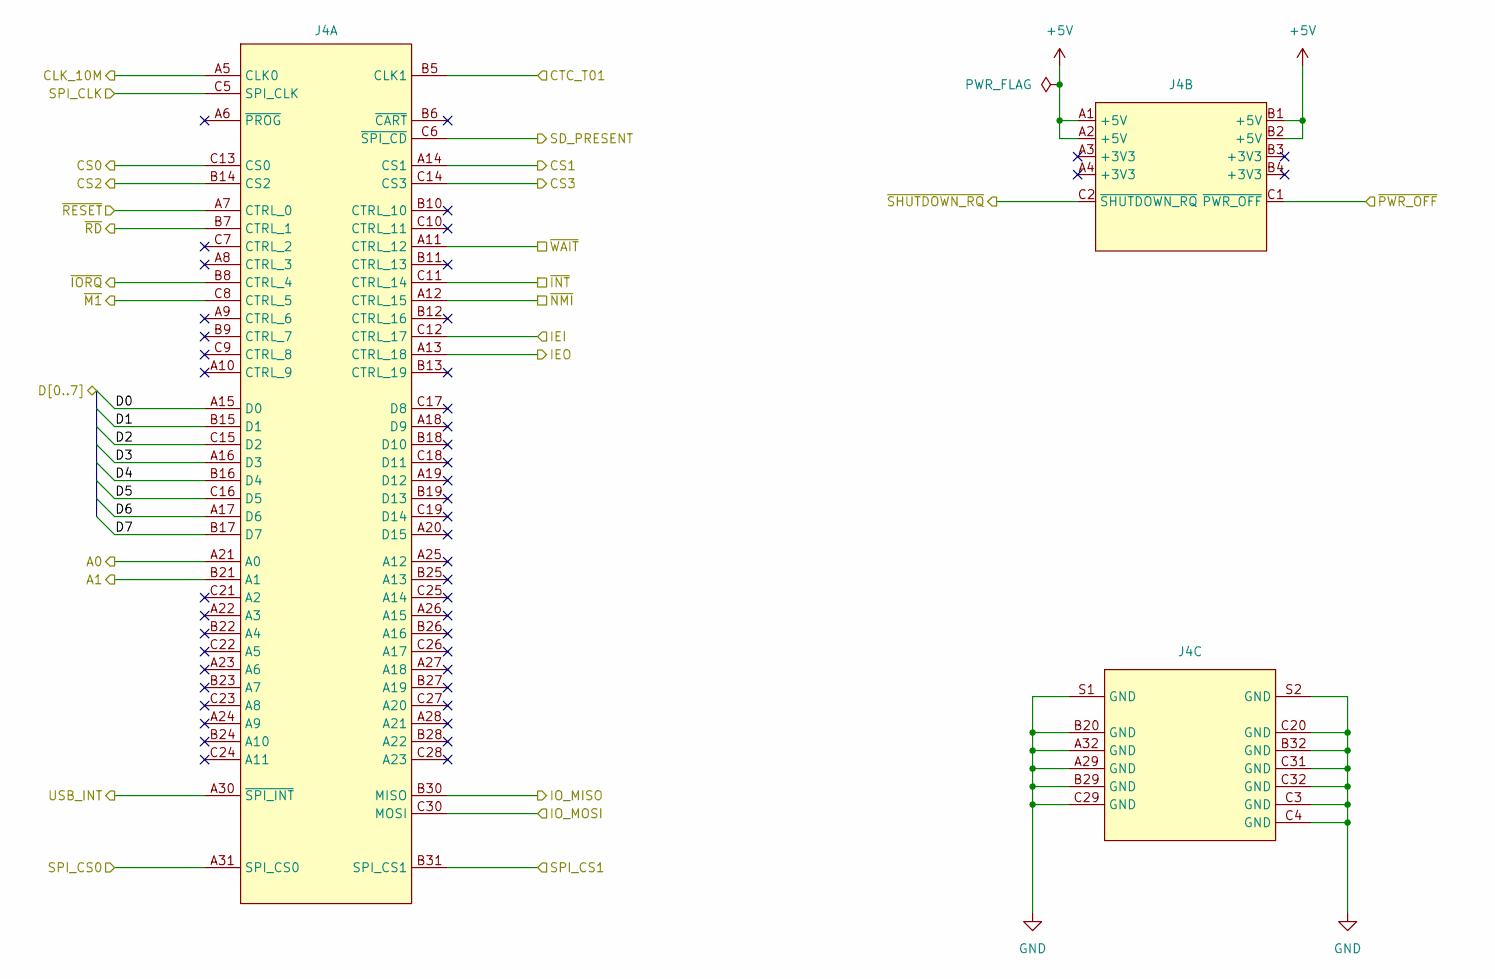
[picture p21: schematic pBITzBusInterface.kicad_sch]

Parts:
J4: AMPHENOL_86093967113T55F1LF; MANUFACTURER_PART_NUMBER 86093967113T55F1LF

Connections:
+5V: J4.A1 (+5V), J4.A2 (+5V), J4.B1 (+5V), J4.B2 (+5V); also elsewhere on the board
/Device Select Decode/CS0: J4.C13 (CS0); also elsewhere on the board
/Device Select Decode/CS1: J4.A14 (CS1); also elsewhere on the board
/Device Select Decode/CS2: J4.B14 (CS2); also elsewhere on the board
/Device Select Decode/CS3: J4.C14 (CS3); also elsewhere on the board
/Device Select Decode/~RD: J4.B7 (CTRL_1); also elsewhere on the board
/GPIOs and User Serial/CTC_TO1: J4.B5 (CLK1); also elsewhere on the board
/IO Controller Card/A0: J4.A21 (A0); also elsewhere on the board
/IO Controller Card/A1: J4.B21 (A1); also elsewhere on the board
/IO Controller Card/CLK_10M: J4.A5 (CLK0); also elsewhere on the board
/IO Controller Card/D0: J4.A15 (D0); also elsewhere on the board
/IO Controller Card/D1: J4.B15 (D1); also elsewhere on the board
/IO Controller Card/D2: J4.C15 (D2); also elsewhere on the board
/IO Controller Card/D3: J4.A16 (D3); also elsewhere on the board
/IO Controller Card/D4: J4.B16 (D4); also elsewhere on the board
/IO Controller Card/D5: J4.C16 (D5); also elsewhere on the board
/IO Controller Card/D6: J4.A17 (D6); also elsewhere on the board
/IO Controller Card/D7: J4.B17 (D7); also elsewhere on the board
/IO Controller Card/IEI: J4.A13 (CTRL_18); also elsewhere on the board
/IO Controller Card/IEO: J4.C12 (CTRL_17); also elsewhere on the board
/IO Controller Card/IO_MISO: J4.B30 (MISO); also elsewhere on the board
/IO Controller Card/IO_MOSI: J4.C30 (MOSI); also elsewhere on the board
/IO Controller Card/IO_SCK: J4.C5 (SPI_CLK); also elsewhere on the board
/IO Controller Card/SD_PRESENT: J4.C6 (~SPI_CD); also elsewhere on the board
/IO Controller Card/~INT: J4.C11 (CTRL_14); also elsewhere on the board
/IO Controller Card/~IORQ: J4.B8 (CTRL_4); also elsewhere on the board
/IO Controller Card/~IO_SD_CS: J4.B31 (SPI_CS1); also elsewhere on the board
/IO Controller Card/~IO_USB_CS: J4.A31 (SPI_CS0); also elsewhere on the board
/IO Controller Card/~M1: J4.C8 (CTRL_5); also elsewhere on the board
/IO Controller Card/~NMI: J4.A12 (CTRL_15); also elsewhere on the board
/IO Controller Card/~PWR_OFF: J4.C1 (~PWR_OFF); also elsewhere on the board
/IO Controller Card/~RESET: J4.A7 (CTRL_0); also elsewhere on the board
/IO Controller Card/~SHUTDOWN_RQ: J4.C2 (~SHUTDOWN_RQ); also elsewhere on the board
/IO Controller Card/~USB_INT: J4.A30 (~SPI_INT); also elsewhere on the board
/IO Controller Card/~WAIT: J4.A11 (CTRL_12); also elsewhere on the board
GND: J4.A29 (GND), J4.A32 (GND), J4.B20 (GND), J4.B29 (GND), J4.B32 (GND), J4.C3 (GND), J4.C4 (GND), J4.C20 (GND), J4.C29 (GND), J4.C31 (GND), J4.C32 (GND), J4.S1 (GND), J4.S2 (GND); also elsewhere on the board

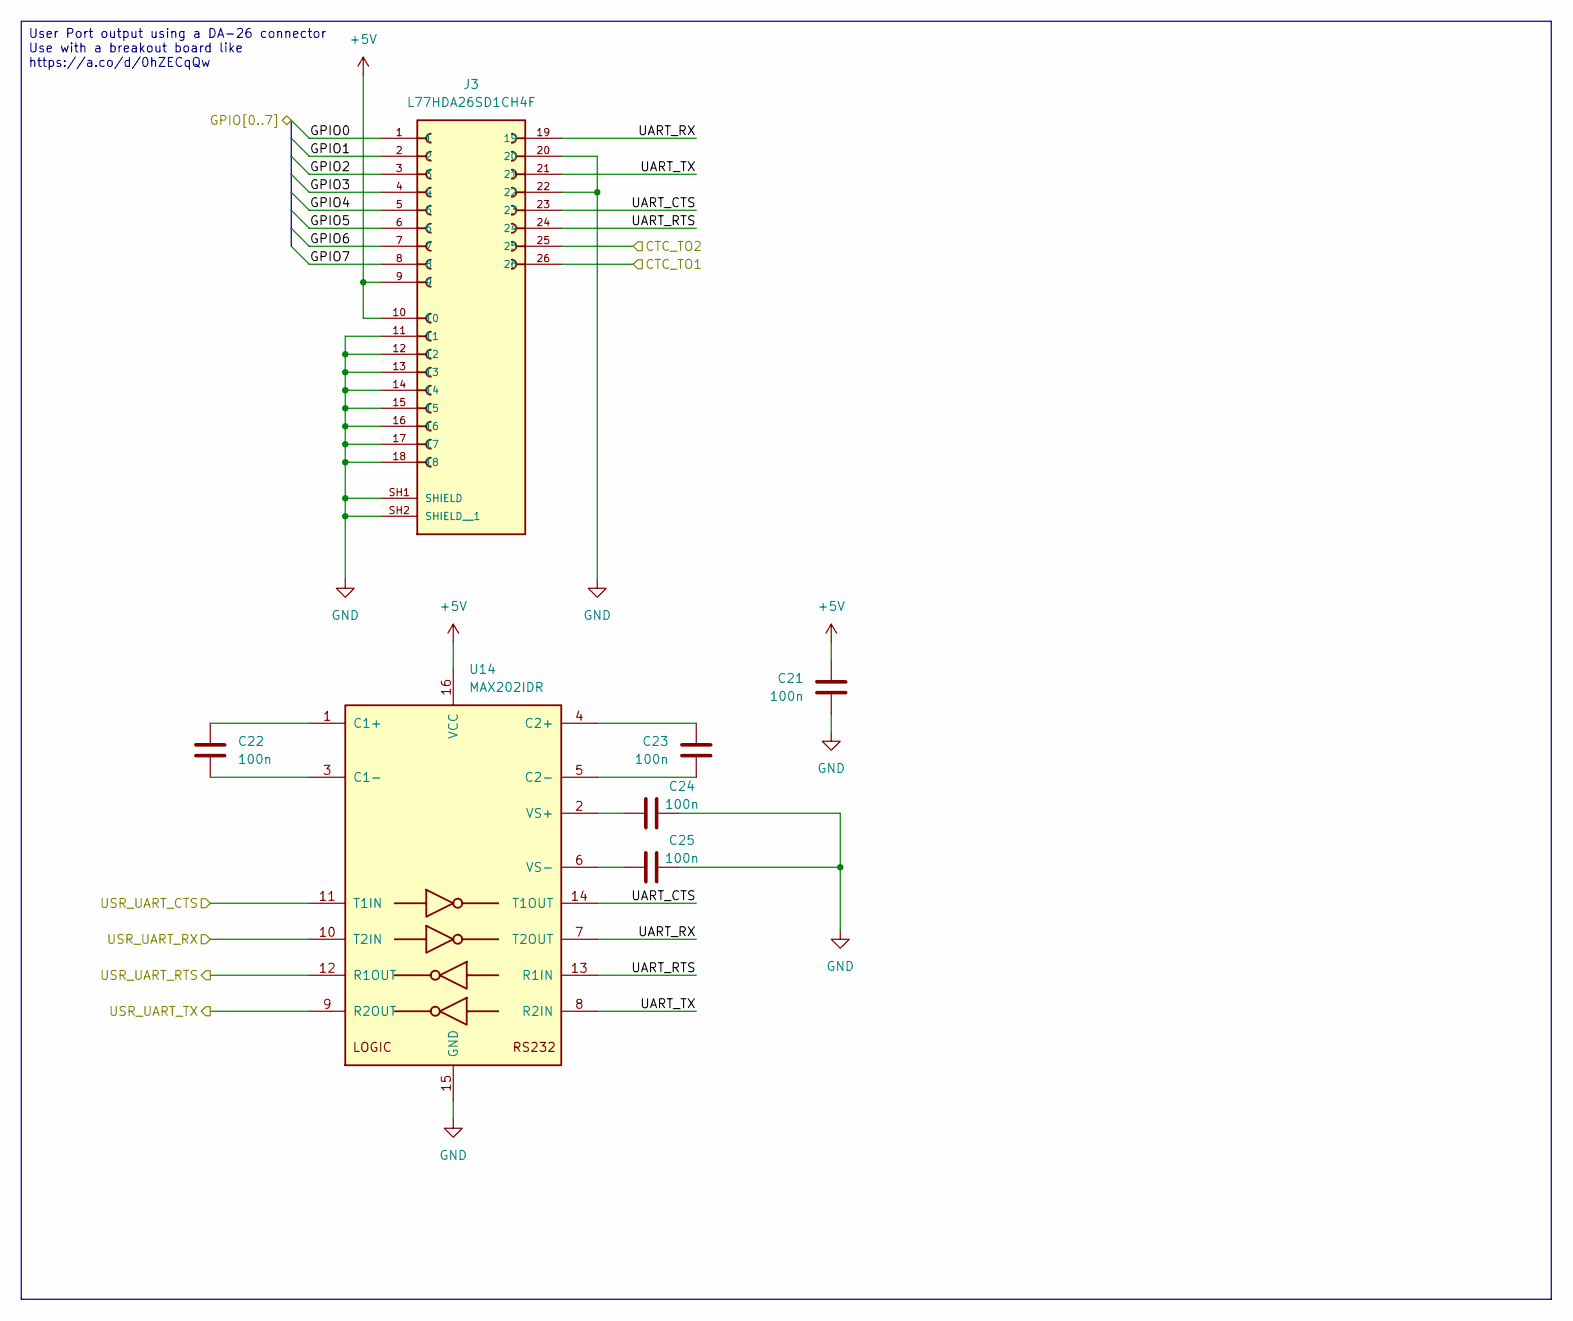
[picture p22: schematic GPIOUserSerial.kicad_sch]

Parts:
C21, C22, C23, C24, C25: 100n; C_0603_1608Metric; MANUFACTURER_PART_NUMBER C0603C104K5RACTU
J3: L77HDA26SD1CH4F; AMPHENOL_L77HDA26SD1CH4F; PARTREV 2
U14: MAX202IDR; SOIC-16_3.9x9.9mm_P1.27mm; MANUFACTURER_PART_NUMBER MAX202IDR

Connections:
+5V: C21.1, J3.9, J3.10, U14.16 (VCC); also elsewhere on the board
/GPIOs and User Serial/CTC_TO1: J3.26; also elsewhere on the board
/GPIOs and User Serial/CTC_TO2: J3.25; also elsewhere on the board
/GPIOs and User Serial/GPIO0: J3.1; also elsewhere on the board
/GPIOs and User Serial/GPIO1: J3.2; also elsewhere on the board
/GPIOs and User Serial/GPIO2: J3.3; also elsewhere on the board
/GPIOs and User Serial/GPIO3: J3.4; also elsewhere on the board
/GPIOs and User Serial/GPIO4: J3.5; also elsewhere on the board
/GPIOs and User Serial/GPIO5: J3.6; also elsewhere on the board
/GPIOs and User Serial/GPIO6: J3.7; also elsewhere on the board
/GPIOs and User Serial/GPIO7: J3.8; also elsewhere on the board
/GPIOs and User Serial/UART_CTS: J3.23, U14.14 (T1OUT)
/GPIOs and User Serial/UART_RTS: J3.24, U14.13 (R1IN)
/GPIOs and User Serial/UART_RX: J3.19, U14.7 (T2OUT)
/GPIOs and User Serial/UART_TX: J3.21, U14.8 (R2IN)
/GPIOs and User Serial/USR_UART_CTS: U14.11 (T1IN); also elsewhere on the board
/GPIOs and User Serial/USR_UART_RTS: U14.12 (R1OUT); also elsewhere on the board
/GPIOs and User Serial/USR_UART_RX: U14.10 (T2IN); also elsewhere on the board
/GPIOs and User Serial/USR_UART_TX: U14.9 (R2OUT); also elsewhere on the board
GND: C21.2, C24.2, C25.2, J3.11, J3.12, J3.13, J3.14, J3.15, J3.16, J3.17, J3.18, J3.20, J3.22, J3.SH1 (SHIELD), J3.SH2 (SHIELD__1), U14.15 (GND); also elsewhere on the board
unnamed: C22.1, U14.1 (C1+)
unnamed: C22.2, U14.3 (C1-)
unnamed: C23.1, U14.4 (C2+)
unnamed: C23.2, U14.5 (C2-)
unnamed: C24.1, U14.2 (VS+)
unnamed: C25.1, U14.6 (VS-)

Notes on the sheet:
User Port output using a DA-26 connector Use with a breakout board like https://a.co/d/0hZECqQw

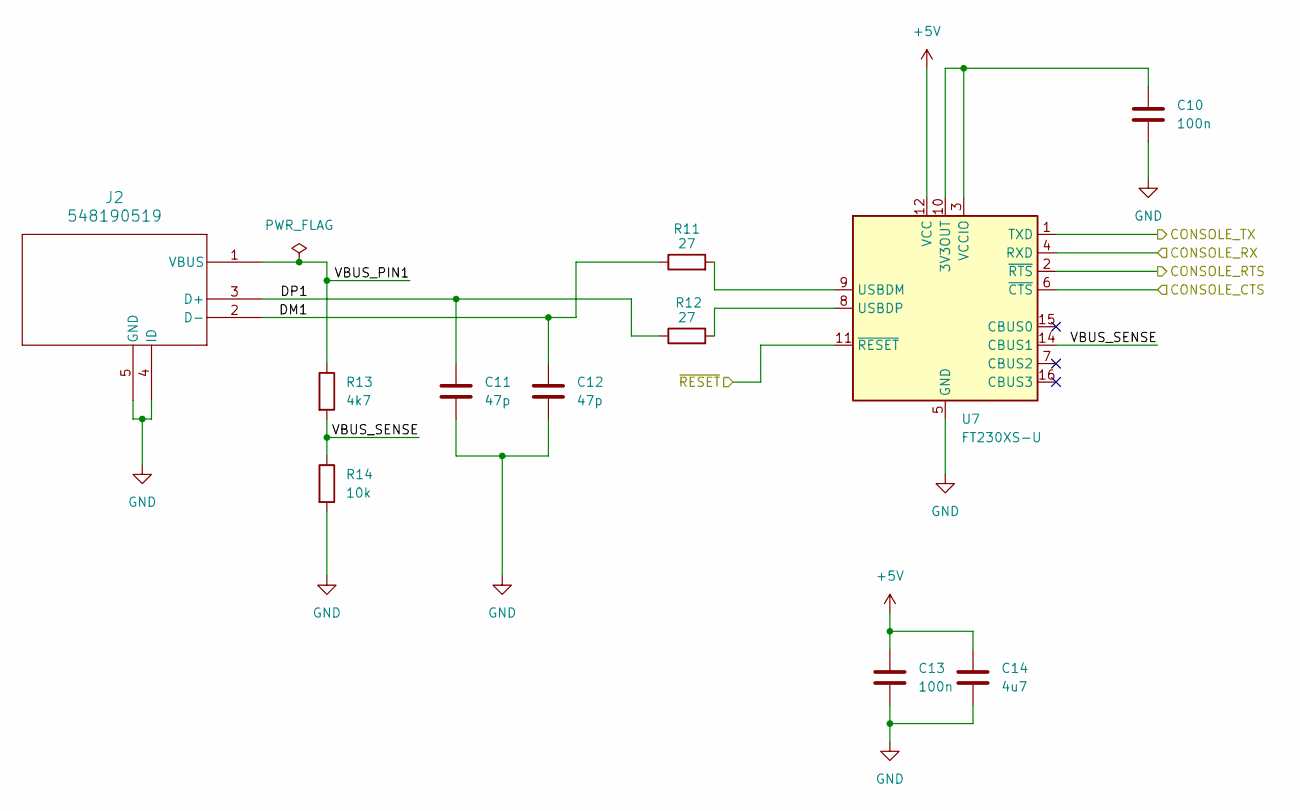
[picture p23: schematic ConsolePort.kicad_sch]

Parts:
C10, C13: 100n; C_0603_1608Metric; MANUFACTURER_PART_NUMBER C0603C104K5RACTU
C11, C12: 47p; C_0603_1608Metric; MANUFACTURER_PART_NUMBER 885012006021
C14: 4u7; C_0603_1608Metric; MANUFACTURER_PART_NUMBER CL10A475KP8NNNC
J2: 548190519; 54819-0519_MOL; Manufacturer Part 0548190519
R11, R12: 27; R_0603_1608Metric; MANUFACTURER_PART_NUMBER RC0603FR-0727RL
R13: 4k7; R_0603_1608Metric; MANUFACTURER_PART_NUMBER CRCW06034K70FKEA
R14: 10k; R_0603_1608Metric; MANUFACTURER_PART_NUMBER RC0603FR-0710KL
U7: FT230XS-U; SSOP-16_3.9x4.9mm_P0.635mm; MANUFACTURER_PART_NUMBER FT230XS-U

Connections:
+5V: C13.1, C14.1, U7.12 (VCC); also elsewhere on the board
/Console Port/CONSOLE_CTS: U7.6 (~CTS); also elsewhere on the board
/Console Port/CONSOLE_RTS: U7.2 (~RTS); also elsewhere on the board
/Console Port/CONSOLE_RX: U7.4 (RXD); also elsewhere on the board
/Console Port/CONSOLE_TX: U7.1 (TXD); also elsewhere on the board
/Console Port/DM1: C12.1, J2.2 (D-), R11.1
/Console Port/DP1: C11.1, J2.3 (D+), R12.1
/Console Port/VBUS_PIN1: J2.1 (VBUS), R13.1
/Console Port/VBUS_SENSE: R13.2, R14.1, U7.14 (CBUS1)
/IO Controller Card/~RESET: U7.11 (~RESET); also elsewhere on the board
GND: C10.2, C11.2, C12.2, C13.2, C14.2, J2.4 (ID), J2.5 (GND), R14.2, U7.5 (GND), U7.13 (GND); also elsewhere on the board
unnamed: C10.1, U7.3 (VCCIO), U7.10 (3V3OUT)
unnamed: R11.2, U7.9 (USBDM)
unnamed: R12.2, U7.8 (USBDP)

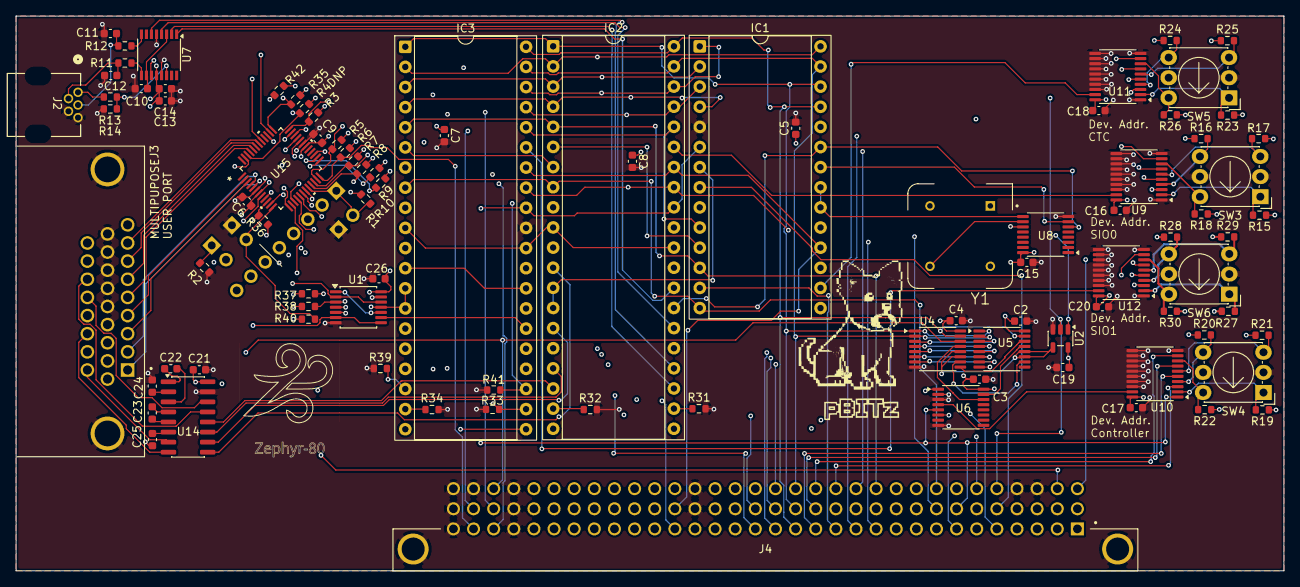
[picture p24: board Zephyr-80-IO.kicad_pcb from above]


Board: 6 copper layers, 160.0 x 70.0 mm, 95 parts (4 on the bottom side), 128 nets.

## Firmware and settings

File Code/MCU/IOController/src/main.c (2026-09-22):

#include <xc.h>
#include <stdint.h>
#include <stdbool.h>

#include "config.h"
#include "ioc_frame.h"
#include "external_sync.h"
#include "dispatch.h"
#include "spi1_bus.h"
#include "controller_latch.h"
#include "timebase.h"
#include "sd_cache.h"
#include "power.h"
#include "bulk_channel.h"
#include "sd_card.h"
#include "ioc_hid.h"
#include "handlers.h"
#include "volume.h"
#include "boot_guard.h"
#if IOC_FS_COMMANDS
#include "fs_share.h"
#include "fs2.h"
#endif

/* ---------------------------------------------------------------------------
 * Platform initialization
 * ---------------------------------------------------------------------------
 *
 * The firmware runs as a foreground polling loop.  Interrupts stay disabled:
 * the Z80 requests service by asserting /SIO1B_INT low, and the PIC services
 * exactly one command transaction on that falling edge.
 */
static void platform_init(void)
{
    INTCON0bits.GIE = 0;

    /* 64 MHz HFINTOSC. */
    OSCCON1 = 0x60;
    OSCFRQ  = 0x08;
    OSCTUNE = 0x00;

    /* Every pin in the map is digital. */
    ANSELA = 0x00;
    ANSELB = 0x00;
    ANSELD = 0x00;
    ANSELE = 0x00;
    ANSELF = 0x00;
    ODCONA = 0x00;
    WPUA   = 0x00;

    /* /PWR_OFF FIRST, before anything slow.
     *
     * Until this pin is driven, the net is held only by pull-ups and the PMU
     * cannot tell a booting controller from one asking for power off. Observed
     * on hardware: with the card in, the machine would not start; with it out,
     * it did. The PMU has a one second grace period for exactly this, and the
     * only way to spend that budget is to dawdle here -- boot_reset_pulse()
     * alone is 100 ms, and card init can be most of a second.
     *
     * Latch to idle while still an input, then drive. The other order lets the
     * pin glitch through asserted, which on this net is a power cut. */
    PWR_OFF_LAT  = PWR_OFF_IDLE;
    PWR_OFF_TRIS = 0;

    /* Inactive shared-bus selects stay idle while the command link clocks. */
    IO_USB_CS_LAT  = IO_USB_CS_IDLE;
    IO_USB_CS_TRIS = 0;

    IO_SD_CS_LAT  = IO_SD_CS_IDLE;
    IO_SD_CS_TRIS = 0;

    /* SD activity indicator: parked off until a card access starts. */
    SD_BUSY_ANSEL = 0;
    SD_BUSY_LAT   = SD_BUSY_IDLE;
    SD_BUSY_TRIS  = 0;

    SIOA_CS_LAT  = SIOA_CS_IDLE;
    SIOA_CS_TRIS = 0;

    CTRL_LAT_CS_LAT  = CTRL_LAT_CS_IDLE;
    CTRL_LAT_CS_TRIS = 0;

    /* SIO1/A External Sync starts high; the first MCU->host Bulk transfer
     * drops it once and then holds it low until an explicit link resync. */
    SYNCA_LAT  = SYNCA_IDLE;
    SYNCA_TRIS = 0;

    /* SIO1 modem control: the PIC drives all four, parked deasserted.
     *
     * /CTSB is the HID input doorbell, not flow control -- it is asserted
     * while the keyboard queue holds bytes and released when it empties.  See
     * input_doorbell_update() in ioc_hid.c.  Parking it idle here is the safe
     * default: a host that samples it before this runs reads "no input".
     */
    CTSA_LAT  = CTSA_IDLE;
    CTSA_TRIS = 0;
    CTSB_LAT  = CTSB_IDLE;
    CTSB_TRIS = 0;
    DCDA_LAT  = DCDA_IDLE;
    DCDA_TRIS = 0;
    DCDB_LAT  = DCDB_IDLE;
    DCDB_TRIS = 0;

    /* The PIC does not currently implement the manual NMI request.  Leave its
     * /NMI connection high-impedance so it cannot fight another card driving
     * the shared bus signal.  Preload the latch for any future use.
     *
     * The weak pull-up is not optional: nothing else on the net holds it, and
     * the Z80's NMI input is edge-triggered, so without it the host takes
     * spurious NMIs -- measured with the CTC endurance ROM, and the reason a
     * program could appear to restart itself.  Input plus pull-up keeps the
     * net deasserted while leaving any card free to pull it low. */
    HOST_NMI_LAT  = HOST_NMI_IDLE;
    HOST_NMI_TRIS = 1;
    HOST_NMI_WPU  = 1;

    /* /PWR_OFF was taken to its idle level above, deliberately early.
     * /SHUTDOWN_RQ is set up by power_init(); it is an input and nothing is
     * waiting on it. */

    USB_INT_TRIS     = 1;
    NMI_RQ_TRIS      = 1;

    SIO1B_INT_TRIS = 1;
    SIO1A_INT_TRIS = 1;

    /* GPIO header: inputs until something claims it. */
    IOC_GPIO_TRIS = 0xFF;

    external_sync_init();

    /* Port C peripheral bus.  Claims RC3/RC4/RC5 and all three device-select
     * pins; each device sets its own clock rate before a transaction. */
    spi1_bus_init();

    /* Park both controller ports at their active-low idle value.  The periodic
     * counter test is disabled during SD-card bring-up, so the latch is only
     * rewritten when a USB controller changes state.  The card still
     * initialises lazily on the first SD request. */
    timebase_init();
    controller_latch_init();
    sd_cache_init();

    /* Neither of these touches the card, and neither can reach FatFs.  See the
     * boot-path rule in volume.h. */
    vol_init();
#if IOC_FS_COMMANDS
    fs_share_init();
    fs2_init();
#endif

    power_init();
    timebase_us_init();
}

/* ---------------------------------------------------------------------------
 * Host reset pair
 * ---------------------------------------------------------------------------
 *
 * RF2 RESET is active-low.  RF3 RESET_HIGH is the complementary active-high
 * reset signal.  Both are driven during boot and during CMD_RESET.
 */
static void write_reset(uint8_t asserted)
{
    HOST_RESET_LAT      = asserted ? HOST_RESET_ASSERTED : HOST_RESET_IDLE;
    HOST_RESET_HIGH_LAT = asserted ? HOST_RESET_HIGH_ASSERTED : HOST_RESET_HIGH_IDLE;
}

static void boot_reset_pulse(void)
{
    write_reset(1u);
    HOST_RESET_TRIS      = 0;
    HOST_RESET_HIGH_TRIS = 0;

    __delay_ms(100);
    write_reset(0u);
}

/* ---------------------------------------------------------------------------
 * Command request detection
 * ---------------------------------------------------------------------------
 *
 * /SIO1B_INT is an ACKNOWLEDGED REQUEST line, not a transaction-active line:
 *
 *     low   = the host has a request outstanding
 *     high  = the request has been accepted
 *
 * The host drops it as soon as it has finished transmitting its frame -- long
 * before the reply -- and the PIC observes that release as a required step of
 * servicing, below.  Because the PIC is already committed to the service when
 * it looks, it cannot miss it.
 *
 * Detection is therefore a plain level test.  No edge is involved anywhere, and
 * that is deliberate: the PIC samples this line only in its main loop and is
 * blind for the length of a bulk transfer or a card write -- hundreds of
 * milliseconds.  Anything encoded in an edge during that window is lost with no
 * trace, because the line is already low and will never fall again.
 *
 * Two earlier schemes both failed on exactly that:
 *
 *   - Sampled edge (remember the previous level, look for high-to-low).  Only
 *     works if the PIC happens to sample inside the gap between one request's
 *     release and the next one's assertion.  A host issuing back-to-back
 *     commands re-asserts within microseconds, so the request was simply lost
 *     until the host's ~11 s timeout.
 *
 *   - Level plus a wait-for-release AFTER servicing.  Fails the other way.
 *     During a write the host releases, transmits the bulk payload, waits for
 *     /CTSA and re-asserts for its DONE query -- all while the PIC is still
 *     inside the bulk receive and the card write.  By the time the PIC waited,
 *     the release had already happened and would not repeat.  A short bound
 *     meant it gave up and re-serviced the same low level, clocking junk
 *     windows into a listening host; a long bound meant a ~10 s deadlock.
 *
 * Requiring the release mid-service removes the ambiguity instead of trying to
 * out-sample it.  Having seen this request acknowledged, any low level found
 * while idle must belong to a later one.
 *
 * The bound below only has to cover the host finishing its frame.  The host
 * sends 35 bytes into a 48-byte window, so it has normally released before
 * external_sync_receive() even returns and this costs nothing.  A timeout here
 * is a real fault and is reported by declining to reply, which the host sees as
 * a clean receive timeout rather than as framing garbage.
 */
#define REQUEST_RELEASE_TIMEOUT_LOOPS  20000u

/* ---------------------------------------------------------------------------
 * COMMAND_READY on /DCDB
 * ---------------------------------------------------------------------------
 *
 * /DCDB is a PIC output into the host's SIO1/B, readable by the host as RR0
 * bit 3.  It carries a persistent level, not a pulse:
 *
 *     asserted     the PIC is in command-idle and will accept a request
 *     deasserted   the PIC will not accept a new command
 *
 * The contract is "READY means the host may make exactly one request", which is
 * what the architecture actually supports: one SPI engine, no concurrent lanes,
 * one transaction in flight.  The host must not assert RTS unless READY.
 *
 * This is backpressure and diagnosability, NOT the fix for the request race --
 * that is the acknowledged-request handshake (see command_request_started()).
 * What it adds is that a host talking to a busy controller can tell, rather
 * than discovering it after an 11 s timeout, and a host talking to a DEAD
 * controller finds out immediately instead of looking identical to a busy one.
 *
 * READY is asserted only after the request has been acknowledged AND all work
 * it triggered has finished -- including the bulk phase and any card write.
 * Asserting earlier would invite a request the PIC cannot yet service.
 *
 * DO NOT ENABLE AUTO ENABLES ON CHANNEL B.  With WR3 bit 5 clear, as it is
 * today, /DCDB is a pure status bit with no side effects.  Set that bit and
 * /DCDB starts gating the host's RECEIVER, so deasserting it mid-transaction
 * would silently kill reception.  /DCDA on the bulk lane does exactly that, on
 * purpose -- the asymmetry between the two channels is deliberate and is a trap
 * for anyone who assumes they are configured alike.
 */
static void command_ready_set(bool ready)
{
    DCDB_LAT = ready ? DCDB_ASSERTED : DCDB_IDLE;
}

static bool command_request_started(void)
{
    return SIO1B_INT_PORT == SIO1B_INT_ACTIVE;
}

static bool wait_request_release(void)
{
    uint16_t guard;

    for (guard = 0u; guard < REQUEST_RELEASE_TIMEOUT_LOOPS; guard++) {
        if (SIO1B_INT_PORT != SIO1B_INT_ACTIVE)
            return true;
    }

    return false;
}

/* ---------------------------------------------------------------------------
 * Command transaction
 * ---------------------------------------------------------------------------
 *
 *   Z80 BIOS                            PIC firmware
 *   --------                            ------------
 *   assert /SIO1B_INT low  -----------> edge detected
 *                                       select SIO1/B on the shared bus
 *                                       clock request from SIO TXDB
 *                                       dispatch command frame
 *                                       clock reply to SIO RXDB
 *   deassert /SIO1B_INT after reply
 *
 * CMD_RESET is terminal: its handler asserts the reset pair and resets the PIC.
 */
/* How often the service path runs, and how often it gives up before
 * dispatching.  Entry is on a LEVEL, so the PIC can be woken by a line that is
 * asserted but not yet carrying a frame; the gap between these two numbers is
 * exactly that waste, and it was invisible until the phase timer showed rx and
 * decode accumulating outside the transaction total. */
uint16_t svc_calls;
uint16_t svc_aborts;

static void service_command_request(void)
{
    IocFrame request;
    IocFrame reply;
    bool     have_request;
    bool     dispatched;
    uint16_t t;
    uint16_t t_total = timebase_us_now();

    svc_calls++;

    have_request = external_sync_receive(&request);

    /* Acknowledge before replying, whether or not the frame decoded.
     *
     * Doing it on the failure path too is what stops a single missed frame
     * from cascading: the host is left waiting for a reply that will not come,
     * but its RTS is already high, so the PIC cannot mistake that wait for a
     * fresh request and clock junk windows into a receiver that is listening
     * for a preamble. */
    if (!wait_request_release()) {
        svc_aborts++;
        return;
    }

    if (!have_request) {
        svc_aborts++;
        return;
    }

    t = timebase_us_now();
    dispatched = dispatch_command(&request, &reply);
    uprof_add(UPROF_DISPATCH, t);

    if (dispatched) {
        t = timebase_us_now();
        external_sync_send(&reply);
        uprof_add(UPROF_SEND, t);

        /* READY -> BULK.  A handler may have staged a bulk transfer; it runs
         * only now, because the bytes must not be clocked onto SIO1/A until
         * the READY reply has actually reached the host.
         *
         * The old PING diagnostic that wrote payload bytes to the controller
         * latch lived here.  It is gone; PING does not touch SPI1. */
        t = timebase_us_now();
        (void)bulk_channel_run_if_armed();
        uprof_add(UPROF_BULK, t);
    }

    uprof_add(UPROF_TOTAL, t_total);
    uprof_apply_pending_reset();
}

int main(void)
{
    /* First, before anything can disturb PCON0 or the persistent counters. */
    boot_guard_init();

    platform_init();
    boot_reset_pulse();
    hid_host_init();

#if SD_CMD0_LOOP
    sd_card_cmd0_loop();   /* does not return */
#endif

    /* Advertise readiness only once everything is initialised.  Before this
     * the pin sits at its parked idle level, so a host that boots first
     * correctly sees "not ready" rather than talking to a half-configured
     * controller. */
    command_ready_set(true);

    for (;;) {
        if (command_request_started()) {
            command_ready_set(false);   /* accepting: no further requests */
            service_command_request();
            command_ready_set(true);    /* all work done, including bulk/SD */
        }

        /* One owner of the Timer2 flag; everything below compares against it.
         * Polled FIRST so the shutdown debounce below reads a tick count that
         * is current within this pass, rather than one left over from the
         * previous one. */
        timebase_poll();

        /* Shutdown request from the PMU.
         *
         * Checked at the top of an idle pass, which is the only place it can be
         * acted on: a transaction in progress must finish before the cache is
         * committed, and the loop is single-threaded so it always has.
         *
         * ORDER MATTERS.  COMMAND_READY drops FIRST, before the flush, because
         * the host gates every IOCALL on it -- so from that moment the Z80
         * cannot start another write.  Flushing first and lowering it after
         * would leave a window in which a write lands in a slot that has just
         * been committed, and the rails would be cut with that block dirty.
         *
         * A failed flush still powers off.  The user asked for a shutdown; not
         * shutting down is a worse answer than shutting down with a block
         * uncommitted, and there is nobody left to report to. */
        if (power_shutdown_requested()) {
            /* Stop accepting commands first.  The host gates every IOCALL on
             * COMMAND_READY, so from this moment the Z80 cannot start another
             * write, and nothing can dirty a slot the flush has already
             * committed.  That is sufficient on its own -- the Z80 is not reset
             * here, because /SHUTDOWN_RQ is a shutdown request and nothing
             * more. */
            command_ready_set(false);

            (void)sd_cache_flush();
            power_off();                /* does not return */
        }

        /* Write-back flush for the SD cache.
         *
         * Runs only here, between commands, so it cannot land in the middle of
         * a transaction -- the loop is single-threaded and
         * service_command_request() completes its bulk phase before returning.
         *
         * Automatic flushing is gated on the SD driver's already-initialized
         * state.  It never starts card initialization or retries a failed
         * session; an explicit SD operation must recover it first.
         * COMMAND_READY is dropped because a flush can block for the length of
         * several card writes.  The Z80 holds /SIO1B_INT until
         * acknowledged, so a request arriving mid-flush is delayed rather than
         * lost; this only tells the host the truth about when to bother
         * asking.  Raised again unconditionally: leaving it low on a failed
         * flush would wedge the host waiting for a controller that is fine. */
        if (sd_cache_flush_due()) {
            command_ready_set(false);
            (void)sd_cache_tick();
            command_ready_set(true);
        } else {
            (void)sd_cache_tick();      /* keeps the interval anchored; no I/O */
        }

        /* USB host service.
         *
         * Here and nowhere else.  Enumeration is slow -- descriptor fetches,
         * hub port resets and mandated settling delays all run inside
         * tuh_task() -- and the Z80 will not wait that long for a reply.  This
         * is the same placement rule the SD cache flush follows above: idle
         * branch only, after any command in flight has fully completed. */
        hid_host_task();

        /* CTRL-ALT-ESC on the USB keyboard: reset the machine.
         *
         * The IOC drives the host reset lines, so it is the only thing that can
         * restart a wedged Z80 short of the power switch.  Acted on here, in
         * the idle branch after hid_host_task() has returned, for the same
         * reason the shutdown request and the cache flush are: any command in
         * flight has completed, so nothing is reset mid-transaction.
         *
         * The cache is flushed first.  This is a deliberate reset of a machine
         * the user is probably rescuing, and dropping dirty blocks on the floor
         * would turn a wedged session into a corrupt volume.  A failed flush
         * still resets -- the user asked for it, and refusing leaves them with
         * the power switch and the same dirty cache.
         *
         * handler_reset() asserts the host reset pair and then resets the PIC;
         * it does not return. */
        if (hid_reset_requested()) {
            command_ready_set(false);
            (void)sd_cache_flush();
            handler_reset();            /* does not return */
        }

        /* One auto-mount attempt, here and nowhere else.
         *
         * Same placement rule as the cache flush and hid_host_task() above:
         * idle branch only, after any command in flight has fully completed.
         * FatFs is not reachable from a command handler, so its call depth is
         * never spent on top of the dispatch chain -- which matters because
         * STVREN turns a hardware stack overflow into a device reset, and the
         * controller drives the host reset pair.
         *
         * Does nothing unless the build enables it; see vol_service(). */
        /* COMMAND_READY drops around a mount for the same reason it drops
         * around a cache flush: resolving an image reads directory sectors and
         * walks a cluster chain, and the host gates every IOCALL on that line.
         * The Z80 holds /SIO1B_INT until acknowledged, so a request arriving
         * mid-mount is delayed rather than lost -- this only tells the host the
         * truth about when to bother asking. */
        if (vol_service_pending()) {
            command_ready_set(false);
            vol_service();
            command_ready_set(true);
        } else {
            vol_service();          /* cheap no-op */
        }

        /* Once the controller has stayed up long enough to be considered
         * healthy, forget the reset count.  Placed after vol_service() so a
         * boot only counts as settled if it survived the risky path too. */
        boot_guard_settle();

        /* Empty unless CONTROLLER_LATCH_COUNTER_TEST is explicitly enabled. */
        controller_latch_tick();

        NOP();
    }
}

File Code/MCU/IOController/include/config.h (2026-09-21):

#ifndef CONFIG_H
#define CONFIG_H

/* PIC18F57Q84 HFINTOSC is configured to 64 MHz in platform_init(). */
#define _XTAL_FREQ 64000000UL

/* ===========================================================================
 * Build profile
 * ===========================================================================
 *
 * 0 = normal firmware: what the machine runs.
 * 1 = diagnostic firmware: adds bring-up, benchmark and stress facilities.
 *
 * Set from the Makefile with IOC_PROFILE=diagnostic.  It gates INCLUSION only
 * -- no transport behaviour, timing or error handling differs between the two
 * builds, so a fault reproduced on one is a fault on the other.
 *
 * What it gates is deliberately narrower than "everything that looks like a
 * diagnostic".  Three things that read as instrumentation are load-bearing and
 * are NOT gated:
 *
 *   timebase_us_now()          a microsecond time source.  bulk_channel.c's bounded
 *                        wait for host RTS uses it for its 500 ms failure
 *                        contract; removing it wedges or slows every transfer.
 *   the SD failure trace small, and the only thing that distinguishes
 *                        electrical silence from a bad init stage.
 *   sd_card CRC checks   data integrity, never overhead.
 */
#ifndef IOC_DIAGNOSTIC_BUILD
#define IOC_DIAGNOSTIC_BUILD 0
#endif

/* Bulk data CRC bypass, matching the Z80 IOC_BULK_CRC_BYPASS setting.
 * 1 skips IOC bulk TX calculation (sends a zero trailer) and RX verification.
 * 0 restores the existing software TX CRC and reflected RX residue check.
 * Framing, metadata checks, command CRC and SD-card SPI CRC are unchanged.
 * The Z80 must bypass bulk RX CRC while this is 1.
 * Override with make DEFS=-DIOC_BULK_CRC_BYPASS=0 to restore IOC checking.
 */
#ifndef IOC_BULK_CRC_BYPASS
#define IOC_BULK_CRC_BYPASS 1
#endif
#if IOC_BULK_CRC_BYPASS != 0 && IOC_BULK_CRC_BYPASS != 1
#error "IOC_BULK_CRC_BYPASS must be 0 or 1"
#endif

/* ===========================================================================
 * U15 PIC18F57Q84-I/PT pin map
 * ===========================================================================
 *
 * Net names below are the schematic net names.  Macro names keep the "HOST_"
 * prefix on RESET/NMI because <xc.h> already defines RESET() and NMI as
 * reserved identifiers.
 *
 * Polarity follows the schematic overbars.  The barred, active-low nets are the
 * five selects, USB_INT, /SYNCA, /SYNCB, /CTSA, /CTSB, /DCDA, /DCDB,
 * /SIO1A_INT, /SIO1B_INT, /NMI_RQ, RESET and /NMI.  The unbarred, active-high
 * nets are RESET_HIGH, PWR_OFF and SHUTDOWN_RQ.
 *
 *   Pin  Port  Net             Dir  Notes
 *   ---  ----  --------------  ---  ---------------------------------------
 *    21  RA0   /USB_INT         I   from USB bridge
 *    22  RA1   /CTRL_LAT_CS     O   select / RCLK, controller latch
 *    23  RA2   /IO_SD_CS        O   select, SD card
 *    24  RA3   /IO_USB_CS       O   select, USB bridge
 *    25  RA4   /SIOB_CS         O   select, SIO1 channel B
 *    26  RA5   /SIOA_CS         O   select, SIO1 channel A
 *    33  RA6   /SYNCA           O   SIO1/A External Sync
 *    32  RA7   /SYNCB           O   SIO1/B External Sync
 *
 *     8  RB0   /CTSA            O   SIO1/A clear-to-send
 *     9  RB1   SIO_MOSI         O   shared bus data, PIC -> device
 *    10  RB2   SIO_MISO         I   shared bus data, device -> PIC
 *    11  RB3   SIO_SCK          O   shared bus clock
 *    16  RB4   /DCDA            O   SIO1/A data-carrier-detect
 *    17  RB5   /CTSB            O   SIO1/B clear-to-send
 *    18  RB6   ICSPCLK          -   programming
 *    19  RB7   ICSPDAT          -   programming
 *
 *    34  RC0   unassigned
 *    35  RC1   unassigned
 *    40  RC2   no connect
 *    41  RC3   no connect
 *    46  RC4   unassigned
 *    47  RC5   unassigned
 *    48  RC6   no connect
 *     1  RC7   no connect
 *
 *    42  RD0   GPIO7            -   general-purpose header, bit 7
 *    43  RD1   GPIO6            -
 *    44  RD2   GPIO5            -
 *    45  RD3   GPIO4            -
 *     2  RD4   GPIO3            -
 *     3  RD5   GPIO2            -
 *     4  RD6   GPIO1            -
 *     5  RD7   GPIO0            -   general-purpose header, bit 0
 *
 *    27  RE0   /DCDB            O   SIO1/B data-carrier-detect
 *    28  RE1   unassigned
 *    29  RE2   no connect
 *    20  RE3   VPP / /MCLR      -   programming
 *
 *    36  RF0   /SIO1B_INT       I   SIO1/B service request
 *    37  RF1   /SIO1A_INT       I   SIO1/A service request
 *    38  RF2   RESET            O   active-low host reset
 *    39  RF3   RESET_HIGH       O   active-high complementary host reset
 *    12  RF4   /NMI_RQ          I   active-low manual NMI request
 *    13  RF5   /NMI             I   high-Z; shared active-low Z80 NMI
 *    14  RF6   PWR_OFF          O   LEVEL signal to the PMU (not a pulse)
 *    15  RF7   SHUTDOWN_RQ      I   shutdown request in
 *
 *     6  VSS      7 VDD      30 VDD      31 VSS
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

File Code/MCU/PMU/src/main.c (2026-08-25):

#include <stdint.h>

#include <util/delay.h>

#include "config.h"
#include "power_controller.h"

static void psu_off(void);

/*
 * Configure the PMU GPIO.
 *
 * Active-low external inputs use internal pull-ups. PWR_OK is left without an
 * internal pull-up because it is driven by the ATX PSU. Outputs start with
 * /SHUTDOWN_RQ deasserted and the PSU disabled.
 *
 * Both handshake signals are active low, so whenever this side is an input it
 * enables the pull-up and the net sits at the deasserted level rather than
 * floating between two high-Z ends. The IO Controller does the same on its end.
 */
static void io_init(void)
{
    /* Active-low input; the pull-up is the deasserted level. */
    PWR_OFF_RQ_DDR &= ~_BV(PWR_OFF_RQ_PIN);
    PWR_OFF_RQ_PORT |= _BV(PWR_OFF_RQ_PIN);

    PWR_SW_DDR &= ~_BV(PWR_SW_PIN);
    PWR_SW_PORT |= _BV(PWR_SW_PIN);

    PWR_OK_DDR &= ~_BV(PWR_OK_PIN);
    PWR_OK_PORT &= ~_BV(PWR_OK_PIN);

    /* /SHUTDOWN_RQ idles HIGH either way, which is what active low buys.
     *
     * Driving: set the latch high BEFORE making it an output, so the pin cannot
     * glitch through asserted on the way. Not driving: input with the pull-up
     * on, so the net still idles high rather than floating. */
    SHUTDOWN_RQ_PORT |= _BV(SHUTDOWN_RQ_PIN);
#if !PMU_IGNORE_IO_CONTROLLER_SIGNALS
    SHUTDOWN_RQ_DDR |= _BV(SHUTDOWN_RQ_PIN);
#else
    SHUTDOWN_RQ_DDR &= ~_BV(SHUTDOWN_RQ_PIN);
#endif

    PS_ON_DDR |= _BV(PS_ON_PIN);
    psu_off();
}

static uint8_t pwr_off_requested(void)
{
    /* PWR_OFF_RQ is asserted by the IO Controller when low. */
#if PMU_IGNORE_IO_CONTROLLER_SIGNALS
    return 0;
#else
    return (PWR_OFF_RQ_PINR & _BV(PWR_OFF_RQ_PIN)) == 0;
#endif
}

static uint8_t pwr_switch_pressed(void)
{
    /* The enclosure power switch shorts the input low when pressed. */
    return (PWR_SW_PINR & _BV(PWR_SW_PIN)) == 0;
}

static uint8_t pwr_ok(void)
{
    /* ATX PWR_OK is high when the supply reports stable outputs. */
    return (PWR_OK_PINR & _BV(PWR_OK_PIN)) != 0;
}

static void psu_on(void)
{
    /* Enable the MOSFET so ATX PS_ON# is pulled low. */
#if PS_ON_MOSFET_ON_LEVEL
    PS_ON_PORT |= _BV(PS_ON_PIN);
#else
    PS_ON_PORT &= ~_BV(PS_ON_PIN);
#endif
}

static void psu_off(void)
{
    /* Disable the MOSFET so ATX PS_ON# is released inactive. */
#if PS_ON_MOSFET_OFF_LEVEL
    PS_ON_PORT |= _BV(PS_ON_PIN);
#else
    PS_ON_PORT &= ~_BV(PS_ON_PIN);
#endif
}

static void assert_shutdown_rq(void)
{
    /* Active low: pull the net down to ask the IO Controller to clean up. */
#if !PMU_IGNORE_IO_CONTROLLER_SIGNALS
    SHUTDOWN_RQ_PORT &= ~_BV(SHUTDOWN_RQ_PIN);
#endif
}

static void deassert_shutdown_rq(void)
{
    /* Active low: release the net high, nothing is being asked. */
#if !PMU_IGNORE_IO_CONTROLLER_SIGNALS
    SHUTDOWN_RQ_PORT |= _BV(SHUTDOWN_RQ_PIN);
#endif
}

static void apply_controller_action(power_controller_action_t action)
{
    if (action & POWER_CONTROLLER_ACTION_PSU_ON) {
        psu_on();
    }

    if (action & POWER_CONTROLLER_ACTION_PSU_OFF) {
        psu_off();
    }

    if (action & POWER_CONTROLLER_ACTION_ASSERT_SHUTDOWN_RQ) {
        assert_shutdown_rq();
    }

    if (action & POWER_CONTROLLER_ACTION_DEASSERT_SHUTDOWN_RQ) {
        deassert_shutdown_rq();
    }
}

int main(void)
{
    power_controller_t controller;

    io_init();
    power_controller_init(&controller, pwr_switch_pressed(), pwr_ok());

    for (;;) {
        const power_controller_inputs_t inputs = {
            .pwr_switch_pressed = pwr_switch_pressed(),
            .pwr_ok = pwr_ok(),
            .pwr_off_requested = pwr_off_requested(),
        };

        apply_controller_action(power_controller_step(&controller, &inputs));
        _delay_ms(POLL_INTERVAL_MS);
    }
}

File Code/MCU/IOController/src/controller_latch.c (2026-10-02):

#include <xc.h>
#include <stdint.h>
#include <stdbool.h>
#include <stddef.h>
#include "config.h"
#include "spi1_bus.h"
#include "controller_latch.h"
#include "timebase.h"

/* ---------------------------------------------------------------------------
 * Controller latch — first bring-up of the port C peripheral bus
 * ---------------------------------------------------------------------------
 *
 * The d-pad / joystick is a USB HID device.  The intended data flow is
 *
 *   USB device -> USB bridge -> PIC -> 74HC595 pair -> Z80 host
 *
 * so the 595s are serial-in/parallel-out: the PIC writes the decoded controller
 * state into them and the host reads the parallel outputs.
 *
 * Wiring:
 *
 *   SER                <- MOSI          RC5  (SPI1 SDO)
 *   common SRCLK/RCLK  <- gated SPI_CLK RC3  (SPI1 SCK)
 *   clock-buffer /OE   <- /CTRL_LAT_CS  RA1
 *
 * Two differences from the SIO link on SPI2 are deliberate:
 *
 *   - LSBF = 0.  The 595 shifts most-significant bit first; the Z80 SIO shifts
 *     bit 0 first.  The two buses genuinely disagree, so this is per-module.
 *   - No inter-byte pacing.  Nothing on the far side has to keep up in
 *     software, unlike the Z80's polled receive loop.
 * --------------------------------------------------------------------------- */

/* Conservative bring-up rate for verifying the cascaded latch transaction. */
#define CTRL_SPI_BAUD         SPI1_BAUD_1MHZ

/* Bytes presented to a standard Coleco controller read.  Inputs are active
 * low.  D7 is low -- see CONTROLLER_LATCH_IDLE -- D6 is fire and D3..D0 are
 * left/down/right/up respectively when read as individual bit positions. */
#define CTRL_UP               0x01u
#define CTRL_RIGHT            0x02u
#define CTRL_DOWN             0x04u
#define CTRL_LEFT             0x08u
#define CTRL_FIRE             0x40u
#define CTRL_KEYPAD_1         0x0du
#define CTRL_KEYPAD_2         0x07u
#define CTRL_KEYPAD_STAR      0x09u
#define CTRL_KEYPAD_POUND     0x06u

static uint8_t controller_value[CONTROLLER_LATCH_PORTS];
static uint8_t controller_tx[3];

/* Keypad code currently held from the keyboard, per port, or
 * CONTROLLER_KEYPAD_NONE.  Two bytes rather than a saved copy of each
 * gamepad byte: releasing restores the idle direction nibble, and the next
 * F310 report refreshes real directions within one poll interval. */
static uint8_t keypad_code[CONTROLLER_LATCH_PORTS] = {
    CONTROLLER_KEYPAD_NONE, CONTROLLER_KEYPAD_NONE
};

#define CTRL_UPDATE_MS        500u
#define CTRL_TICKS_PER_UPDATE (CTRL_UPDATE_MS / TIMEBASE_TICK_MS)

#if CONTROLLER_LATCH_COUNTER_TEST
static uint16_t last_update;
static uint8_t  counter;
#endif

void controller_latch_init(void)
{
    /* The bus itself is owned by spi1_bus_init(), called from platform_init().
     * The bus owner already parked the controller clock buffer disabled. */
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

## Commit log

2026-01-11 Add Solderpad Hardware License v2.1
    This document outlines the Solderpad Hardware License v2.1, which modifies the Apache License Version 2.0 with additional terms and definitions.
2026-01-17 Added CPU, Address Decoding, Clock Tree, Console Port, SD Card, USB Ports schematics and associated symbols and footprints.
    [CPU_AddressDecoding.kicad_sch, ClockTree.kicad_sch, ConsolePort.kicad_sch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]
2026-01-18 Video block added. fixed some issues with parts...
    [CD74HC4050M96.step, CPU_AddressDecoding.kicad_sch, ClockTree.kicad_sch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]
2026-02-02 Completed schematics
    [CPU_AddressDecoding.kicad_sch, ClockTree.kicad_sch, ConsolePort.kicad_sch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]
2026-02-02 Finally found a name "Zephyr-80" for the brew and committing the first pbc
    [CPU_AddressDecoding.kicad_sch, ConsolePort.kicad_sch, SD_Card.kicad_sch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]
2026-02-02 Added pBITzBackplane and MezzanineConnector
    [10018783-10202TLF.step, 10067847-001RLF.step, 39281243.step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]
2026-02-02 Added opensource hardware logo to the silkscreen layer of the backplane PCB.
2026-02-03 Added IO Controller board schematics for Zephyr-80
    [BaudClock.kicad_sch, CPU_AddressDecoding.kicad_sch, ConsolePort.kicad_sch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]
2026-02-06 Completed the IO Controller schematic and PCB layout for the Zephyr-80 project. This includes the design of the Baud Clock, CPU Address Decoding, Console Port, Device Select Decode, GPIO User Serial,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
    [548190519.stp, BaudClock.kicad_sch, CPU_AddressDecoding.kicad_sch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]
2026-02-06 Fixed a placement issue with the SMD under the socket
    [MezzanineConnector.kicad_sch, SD_Card.kicad_sch, USBPorts.kicad_sch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]
2026-02-08 Updated the IO Controller to use the PIC18F57Q84-I/PT instead of the AVR
    [IO Controller.kicad_sch, TQFP48_PT_MCH.step, Zephyr-80-IO.kicad_pcb]
2026-02-27 Fixed a couple of issues with the documentation, and added a few more details to the README.md file. Also updated the control signal mapping for the pBITz project to reflect recent changes in the des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
2026-03-04 Routed the CPU board. Removed the rotary switches decoder
    [CPU_AddressDecoding.kicad_sch, Zephyr-80-CPU.kicad_pcb, Zephyr-80-CPU.kicad_sch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]
2026-03-17 Added all the manufacturer part numbers to the KiCad schematics and PCB files. This will make it easier to order the parts for the project and ensure that the correct components are used. I also remo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
    [Backplane.kicad_sch, BaudClock.kicad_sch, CPU_AddressDecoding.kicad_sch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]
2026-03-20 Added bypass caps on power lines.
    [Backplane.kicad_sch, Power.kicad_sch]
2026-03-20 Fixed memory select wiring and added bulk cap on the power input.
    [CPU_AddressDecoding.kicad_sch, Zephyr-80-CPU.kicad_pcb, pBITzBusInterface.kicad_sch]
2026-03-20 Fixed manufacturer part number
    [IO Controller.kicad_sch]
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2026-03-21 Added copper pours on top and bottom layers of IO controller board, and added a few vias to connect them. This should help with heat dissipation and EMI shielding.
    [Zephyr-80-CPU.kicad_pcb, Zephyr-80-IO.kicad_pcb]
2026-03-21 * Corrected the reversal of the flat connector cable * Added copper pours
    [MezzanineConnector.kicad_sch, pBITzBackplaneMezzanine.kicad_pcb]
2026-03-21 Updated the 3d images and exported the image
    [SD_Card.kicad_sch, USBPorts.kicad_sch, pBITzBackplaneMezzanine.kicad_pcb]
2026-03-21 Small errors in BOM
    [484060001.stp, MezzanineConnector.kicad_sch, pBITzBackplaneMezzanine.kicad_pcb]
2026-03-21 Added 3d model of the board
    [1-2199300-2.STEP, CPU_AddressDecoding.kicad_sch, TSOP-44_MIL400_ALL.step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]
2026-03-21 Added 3d models for parts and exported the 3d models of the boards
    [039281243.stp, 4816p.stp, 4820p.stp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]
2026-03-22 Added Zephyr-80 Logo
    [Zephyr-80-CPU.kicad_pcb, Zephyr-80-IO.kicad_pcb]
2026-04-05 Fixed io controller 1.27mm pitch header to 2.54mm pitch header.
    First battle scars :)
    [IO Controller.kicad_sch, Zephyr-80-IO.kicad_pcb]
2026-04-28 Added code for Power Management Controller on ATtiny85. This includes source code, header files, documentation, and tests for the power controller module. The new files are organized under the Code/M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
2026-04-28 Modified the PMU code to support holding the machine in reset while powering on and added the PLD for the IO decoder and memory decoder
    [main.c]
2026-04-28 Update ATTiny85 power controller workflow
    - Change PWR_STATE to level-based IO reset control
    - Turn PSU on immediately on power-button press, then wait for PWR_OK before releasing IO reset
    - Keep shutdown handshake through PWR_OFF_RQ and preserve 5-second force-off path
    - Update power controller tests and documentation
    [main.c]
2026-04-30 Implemented IO Controller side of power management protocol and fixed the naming in the diagrams
    [BaudClock.kicad_sch, ConsolePort.kicad_sch, DeviceSelectDecode.kicad_sch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]
2026-04-30 Added handling of RESET/RESET_HIGH and NMI pins in the IOController firmware. This allows the controller to properly manage reset and non-maskable interrupt signals, improving the overall functionali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
    [config.h, main.c]
2026-04-30 Added skeleton code for the IO Controller, including power management and SPI management modules. Updated the Makefile and documentation accordingly. Removed the old io_controller.h and io_controller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
2026-05-01 added production files and active bom to backplane
    [pBITzBackplane.kicad_pcb]
2026-05-01 Saved for KiCAD 10 and added PDF Export
    [Backplane.kicad_sch, Power.kicad_sch, pBITzBackplane.kicad_sch]
2026-05-07 Major rework:
    - Updated the Mezzanine to remove the slot connector and move it to the main board (facing the back)
    - The removal of the slot allowed for the removal of the FPC connector, which was a
    major source of complexity. The mezzanine now only has the SD card and USB connectors,
    which are much cheaper and easier to work with.
    - The mezzanine is now more compact and cheaper to souirce
    - The main board sees the addition of the external slot connector (coming from the mezzanine)
    - Added power led on the mother board for easier debugging and testing
    - Removed the free floating resistors to replace them with resistor packs
    [Backplane.kicad_sch, CPU_AddressDecoding.kicad_sch, MezzanineConnector.kicad_sch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]
2026-05-08 Just regenerated the PDF of the schematics and the images of the board
    [pBITzBackplane.kicad_pcb]
2026-05-08 Missing save
    [pBITzBackplane.kicad_pcb]
2026-05-08 Regenerated pictures, schematics, BOM files and production files for the mezzanine
    [pBITzBackplaneMezzanine.kicad_pcb]
2026-05-08 Forgot to change the revision # on the silkscreen.
    [pBITzBackplane.kicad_pcb]
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2026-05-16 Cleaned up the HelloWorld project by removing the old main.asm and build artifacts, and added new test assembly files and a swapbits tool. Updated the Makefile and README accordingly.
2026-05-16 Cleaned up the schematic files
    [Power.kicad_sch, Zephyr-80-CPU.kicad_pcb, Zephyr-80-IO.kicad_pcb]
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2026-05-26 Update memory model for slots and pluggable drivers Updated documentation
    This shit is DRIP!!
2026-05-27 Fixed a couple of typos in the memory map
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2026-05-29 Fixing up the SIO flow control and the Virtual Drip / test program
2026-05-29 Added a READY message to the protocol, sent by the proxy on startup. This allows the Z80 code to wait for the proxy to be ready before sending VDP commands, which is more robust than a fixed startup 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
    [main.c]
2026-05-29 Moved the ramdisk tp slot 5 to make space for the VDrip driver
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2026-05-30 latest fix for console.... no more framed data this sucks!
    [main.c]
2026-06-01 Added support for optional auto-wrap at the right margin in the VDRip console. Enabled by default, this can be disabled with ESC [ ? 7 l to clamp/overwrite the last column instead of wrapping. Auto-w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
    There are two new small programs "NOWRAP.COM" and "WRAPON.COM" in the A: drive
    image to demonstrate the new feature. The former disables auto-wrap and shows
    that characters at the right margin overwrite each other, while the latt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
2026-06-06 Updated the IO Controller to properly support SDLC and SPI.
    * Separated SPI1 and SPI2 and associated to the right pins.
    SPI1 is for devices (USB, SD Card and Controllers)
    SPI2 is for the SDLC controller (Z80 SIO1/A and B)
    * Fixed the 1.27mm vs 2.54mm pin headers
    * Fixed the power sequencing
    * Fixed the pull ups
    [ConsolePort.kicad_sch, DeviceSelectDecode.kicad_sch, IO Controller.kicad_sch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]
2026-06-06 Removed the rotary switch selector
    [IO Controller.kicad_sch, MezzanineConnector.kicad_sch, SD_Card.kicad_sch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]
2026-06-06 Fabrication information committed
    [Zephyr-80-IO.kicad_pcb]
2026-06-06 Fixed board
    [Backplane.kicad_sch, IO Controller.kicad_sch, Power.kicad_sch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]
2026-06-16 Fixed a few mistakes in the IO Controller
    * Wrong layer for vertical traces (should not be on the same layer as vcc plane)
    * Added pull-downs for DCD for all SIOs (we don't use this line)
    * Connected DCD and CTS to the MCU for SIO1 in case we want to use it to gate the SIO1
    [BaudClock.kicad_sch, IO Controller.kicad_sch, Zephyr-80-IO.kicad_pcb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]
2026-06-17 Fixed a couple of issues with the IO Controller, and adding an extractor script to facilitate the process of extracting the netlist from KiCad for use in the Zephyr-80 Emulator.
2026-06-17 Part #s
    [IO Controller.kicad_sch]
2026-06-17 Made the footprint bigger to facilitate soldering.
    [Backplane.kicad_sch, Power.kicad_sch, pBITzBackplane.kicad_pcb]
2026-06-17 Fixed part #s
    [Backplane.kicad_sch, Power.kicad_sch]
2026-06-17 Moving modules around
    [039281243.stp, 1-2199300-2.STEP, 10018783-10202TLF.step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]
2026-06-17 updated the pullups for the power on sequence pins
    [IO Controller.kicad_sch, Zephyr-80-IO.kicad_pcb]
2026-06-17 Corrections post review
    [IO Controller.kicad_sch, Zephyr-80-IO.kicad_pcb]
2026-07-20 Fixed the PING program and IOCall BIOS
    [config.h, main.c]
2026-07-21 Simplified and fixed the IOController code. Removed SDLC and trace code, added external sync protocol support. Updated documentation and pinout information.
    [config.h, external_sync.c, external_sync.h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]
2026-07-22 Commiting changes to console driver to fix a small logic error in the flow control logic.... didn't the root cause of the copy paste problem but I'll commit small bits of working code at a time
2026-07-22 Implemented RESET behavour for the VDrip driver
2026-08-03 Fixes to the IO Controller
    [DeviceSelectDecode.kicad_sch, IO Controller.kicad_sch, Zephyr-80-IO.kicad_pcb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]
2026-08-03 Moved to the DIN Connector
    [CPU_AddressDecoding.kicad_sch, DeviceSelectDecode.kicad_sch, Zephyr-80-CPU.kicad_pcb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]
2026-08-14 updated parts #s
    [BaudClock.kicad_sch, DeviceSelectDecode.kicad_sch, IO Controller.kicad_sch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]
2026-08-21 Updated the pinout for the new IOController and fixed the pullups for the PMU
    [config.h, controller_latch.c, external_sync.c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]
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2026-08-21 Fixed IO Decoder device address select so the device address is now matching the high nibble of the IO port
2026-08-23 Next stage in SD Card bring up.
    Driver works "mostly", but I suspect a marginal card
2026-08-23 removed vdrip_pt removed the need to generate the bit-swapped binary integrated the bulk transfer protocol in the BIOS the usermode test code uses the BIOS... kept sdbulk.com as control
    [sd_card.c]
2026-08-23 IOC: share one hand-clocked sync byte between both SIO lanes
    clock_reply_byte() and clock_sync_byte_a() emitted the same waveform
    and differed only in which /SYNC pin they dropped and at which bit.
    Replace both with sio_link_clock_sync_byte(value, channel, drop_bit).
    The loop reproduces the proven shape exactly, including the
    no-trailing-gap-on-bits-0-and-1 asymmetry, which is load-bearing.
    The per-channel drop bit stays: EXTSYNC_SYNC_DROP_BIT = 1 on the
    command lane, BULK_SYNC_DROP_BIT = 0 on the bulk lane. That is now
    known to be a hardware asymmetry rather than a configuration
    difference. Eliminated on 2026-08-23: WR3/Auto Enables (tested, D1h
    behaves as F1h), WR4 (identical 30h), setup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
    [bulk_channel.c, external_sync.c, external_sync.h]
2026-08-24 Add SD transport soak test and two-lane transport documentation
    SDSOAK writes, reads and byte-verifies across eight LBAs spanning 0 to
    1048576. Every prior test used LBA 0 -- the one address where block-
    addressed and byte-addressed arithmetic agree, since 0 * 512 == 0 -- so
    the 32-bit LBA path was entirely unexercised. It is now confirmed
    correct. Blocks carry their own LBA so a wrong-block read fails loudly,
    and patterns rotate per pass including repeated 7E 81 to attack the bulk
    preamble search.
    Optional CTC-driven interrupt load (SDSOAK I) for measuring the
    transport's interrupt headroom; not yet run.
    docs/two-lane-transport.md covers the design, the bring-up order and
    what each step e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
    [bulk_channel.c, external_sync.c, external_sync.h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]
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2026-08-28 increased the number of cache slots to 8 and unpinned block 0 since it doesn't contain the full directory
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2026-09-01 Small quality of life improvement: when a disk cannot be read, print error message and then go back to drive A:
2026-09-02 new ROM file system. Coupled with the fixes to the bad sector error, this gives us a reliable way to recover an issue
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2026-09-04 Small QoL improvement: CTRL-ALT-ESC resets the machine
    yeah, I know..... I chose something different for the 3 fingers salute
    so sue me :)
    [ioc_hid.c, main.c]
2026-09-07 ColecoGo now supports patching.... for cases where the game doesn't work well with the Zephyr (eg: Zaxxon fuel goes too fast because the Zephyr is 10MHz instead of 3,5MHz))
    [coleco.cfg]
2026-09-07 Support for patching
    [default.cfg]
2026-09-07 FIX for the Indem cards (and probably for most budget sd cards)
    [sd_card.c]
2026-09-08 Vendor the patched cpm22.asm; pin cpm-2.2 at upstream
    The parent recorded the submodule at 9b6d929, a local commit that exists only
    on one machine. Z80-Retro/cpm-2.2 is not ours, so those three patches could
    never be pushed, and `git submodule update` on a fresh clone would fail
    outright trying to fetch a commit upstream has never heard of.
    Copy the one file the build actually needs into cpm22/, alongside the zcpr2/
    and zsdos/ sources vendored the same way, and rewind the submodule to upstream
    5a90af6 where it serves only as reference material (manuals, stock .COM files).
    The three patches are preserved verbatim in cpm22/patches/ and as the
    zephyr80-local branch in the submodule.
    The incl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
2026-09-10 Fixes for background noise coming from IOC operations
    [ioc_hid.c, main.c]
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2026-09-13 Build the ROM disk's sibling tools every time; A: had stale SD tools
    The CPM2.2 Makefile packed whatever was in ../Utilities/build and
    ../Monitor/build onto A: without rebuilding it. After the branch switch that
    left A: carrying SDDIR, SDGET, PING and SDREAD built on rom-services, calling
    IOCALL at E23Fh -- the middle of the console's ANSI dispatch in this image --
    and every one failed with transport error kind 01.
    The ROM disk now depends on a phony sibling-builds target that runs both
    projects' makefiles, and `make clean` cleans them too. After a clean build no
    staged tool calls the stale E233h-E24Fh range, and the SD tools work again on
    hardware.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
2026-09-13 Phase 2 complete: 8 KiB common window, OS body 2000h-DFFFh
    Decoder revision 11 makes common memory E000h-FFFFh in modes 10 and 11 and
    extends the bank 7 OS body to DFFFh; modes 00 and 01 are unchanged. The
    product terms were checked against the intended map for all 2,048 inputs.
    The TPA grows to 0100h-EC05h: CCP at E400h, FBASE EC06h, BIOS table at
    F000h. The BIOS private stacks and SD scratch buffer move to bank 7's
    runtime-only C000h-DFFFh, and the facade's staging shares one 512-byte
    common buffer. E000h-E3FFh is left for program interrupt callbacks.
    The ROM-disk shadow/copy window no longer keeps its saved latch on the
    stack, which mode 01 maps away. ZCPR2's CPRLOC/BIOS and ZSDOS's CCP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
2026-09-13 fixed the players to adapt to the new interrupt contracts
2026-09-13 The IM2 FFh vector previously formed a pointer from FDFF:FE00, where FE00 was mutable CURRENT_BANK. It could therefore jump to addresses such as 00F7, causing the hard crash without an SNTracker faul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
2026-10-06 Map ROM bits D5-D7 to the PLD to qualify RAM addresses
    [CPU_AddressDecoding.kicad_sch, Zephyr-80-CPU.kicad_pcb]
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
